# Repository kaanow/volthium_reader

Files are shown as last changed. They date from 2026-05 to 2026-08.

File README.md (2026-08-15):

# Volthium 24V Pack Reader

Reads the state of two Volthium **SC12200G4DPH** 12V 200Ah LiFePO4 batteries
wired in series (24V system, "The Barge Inn"), and shows a live estimate of
time-to-full when charging or time-to-empty (to 10% SOC) when discharging.

> **How it actually runs today (since 2026-07-26).** Nothing runs on the laptop.
> A Raspberry Pi at the cabin reads the packs over **RS485** (BLE is retired)
> and the Conext gear over **Xanbus/CAN**, and ships everything to a cloud
> server at <https://volts.alti2.de>. The laptop is only an operator console.
> The description below is the ORIGINAL laptop-plus-Bluetooth rig and is kept
> for the design reasoning, not as a statement of current fact.
>
> Start here instead: `docs/STATUS.md` for how it runs, `docs/RUNBOOK.md` for
> operating it, and `docs/what-to-distrust.md` before believing any number in
> this repo.

This repo began as the **dev/validation rig** — it ran on a Mac laptop using
its built-in Bluetooth, to check readings against the Volthium phone app and
dial in the time estimator before committing to permanent hardware.

## How it works

The Volthium SC12200G4DPH BLE protocol matches the **E&J Technology BMS**
family — same Nordic UART service, same `:...~` ASCII-hex frames. We use
[`aiobmsble`](https://github.com/patman15/aiobmsble), which already decodes
that protocol, and combine the two single-battery samples into one logical
24V pack reading.

For a series pack:
- pack voltage = `V_a + V_b` (≈ 26V fully charged, ≈ 24V nominal)
- pack current = same through both batteries (we average to suppress noise)
- **charging** finishes when the *higher-SOC* battery hits 100%
- **discharging** finishes when the *lower-SOC* battery hits the floor

The estimator uses an exponential moving average on current so the displayed
"3h 20m" doesn't flicker every time a cloud passes or the inverter steps load.

## Setup

### macOS (dev rig)

```bash
brew install python@3.13        # only if not already installed
/opt/homebrew/bin/python3.13 -m venv .venv
.venv/bin/pip install -r requirements.txt
```

macOS will prompt for Bluetooth permission the first time the Terminal app
tries to scan. Approve it under *System Settings → Privacy & Security → Bluetooth*.

### Linux / Raspberry Pi (cabin-side)

```bash
sudo apt install -y bluez python3-venv rfkill
python3 -m venv .venv
.venv/bin/pip install -r requirements.txt
```

`bluetooth.service` is enabled by the bluez install; bleak talks to it over
D-Bus, no user-group changes needed on Ubuntu 24.04.

The two physical batteries' addresses live in `pack.env` (committed). macOS
sees them under CoreBluetooth peripheral UUIDs; Linux sees the real BLE
MACs. The Mac UUIDs are already filled in; once you've scanned from the Pi:

```bash
.venv/bin/python scripts/scan.py
```

paste the two `V-12V200AH-*` MACs into `pack.env` as `ADDR_A_LINUX` and
`ADDR_B_LINUX` and commit. From then on the launcher just works on either
machine.

## Use

### 1. Find the batteries

```bash
.venv/bin/python scripts/scan.py
```

Both batteries advertise as `V-12V200Ah-<serial>`. Note their BLE addresses.
(Tip: temporarily power one off if you can't tell A from B.)

### 2. Smoke test — one reading

```bash
.venv/bin/python scripts/read_once.py --a AA:BB:CC:DD:EE:FF --b 11:22:33:44:55:66
```

Cross-check the SOC, voltage and current against the Volthium app. If they
match, the protocol is decoded correctly.

### 3. Live dashboard

```bash
.venv/bin/python scripts/monitor.py \
    --a AA:BB:CC:DD:EE:FF \
    --b 11:22:33:44:55:66 \
    --interval 5 \
    --csv pack.csv
```

`--csv` is optional but recommended for the validation phase — we want
real charge/discharge curves to tune the smoothing constant.

### Easiest way to launch (for anyone, no Terminal needed)

**macOS:** Double-click **Volthium Monitor** on the Desktop. It silently
starts the logger + dashboard if they aren't already running, opens the
dashboard in your default browser, and shows a notification with the LAN
URL to share with phones on the same Wi-Fi.

If the Desktop alias gets deleted, recreate it with:

```bash
./scripts/install_desktop_launcher.sh
```

The .app bundle lives at `Volthium Monitor.app/` in the repo root; the
Desktop alias just points at it, so any future improvements to the .app
are picked up automatically.

**Linux / Pi:** Run the same script from a terminal:

```bash
./'Launch Volthium Monitor.command'
```

It's a portable bash script that detects the OS — `caffeinate` is swapped
for `systemd-inhibit`, `ipconfig` for `hostname -I`, `open` for `xdg-open`.
The dashboard binds `0.0.0.0:8421`, so a phone on the same Wi-Fi can hit
the printed LAN URL. `scripts/install_desktop_launcher.sh` also handles
Linux: it writes `~/.local/share/applications/volthium-monitor.desktop`
(plus a Desktop copy if `~/Desktop` exists). On a fully headless Pi,
prefer a systemd unit instead — `Launch Volthium Monitor.command` is the
single command you'd put in the unit's `ExecStart=`.

### 4. Headless logger + browser dashboard

For long unattended runs, the rich-TUI `monitor.py` isn't ideal — it needs a
visible terminal. Use these two together instead:

```bash
# In one terminal — keep alive with `caffeinate -i` so the Mac doesn't doze.
caffeinate -i .venv/bin/python scripts/log.py \
    --a 9058AE7F-F98B-D0F6-237D-6769894DE118 \
    --b 6EC69980-CA43-7DEF-519B-6235C8C535B7 \
    --interval 5 \
    --csv data/pack.csv --log data/pack.log

# In another terminal:
.venv/bin/python scripts/dashboard.py --csv data/pack.csv
# then open http://localhost:8421/
```

The logger never gives up — it backs off and retries on BLE errors. The
dashboard is read-only off the CSV, so both can run forever.

## Files

- `volthium/pack.py` — discovery + `BatteryReading` / `PackReading`
- `volthium/estimator.py` — smoothed time-to-full / time-to-empty
- `scripts/scan.py` — find the batteries
- `scripts/read_once.py` — single-shot smoke test
- `scripts/monitor.py` — live rich-TUI dashboard (one-shot use)
- `scripts/log.py` — headless CSV logger (for unattended runs)
- `scripts/dashboard.py` — browser dashboard (binds LAN by default)
- `scripts/install_desktop_launcher.sh` — re-create the Desktop alias
- `Volthium Monitor.app/` — double-clickable launcher
- `Launch Volthium Monitor.command` — Terminal-friendly launcher with QR code
- **`docs/RUNBOOK.md` — start here for operating the live system**: current deployment, where things live on the Pi, common ops, failure-mode playbook, hardware upgrade path.
- `docs/production_design.md` — architecture for the cabin-side hardware
- `docs/cloud_architecture.md` — Railway telemetry design + repo-wide timestamp convention (ISO-8601 UTC `Z` on the wire; read this before adding any code that emits or consumes timestamps over the network)
- `docs/reliability_failure_modes.md` — field log of BLE / storage failure modes, root causes, and mitigations
- `cloud/` — FastAPI ingest server + Pi-side CSV uploader + browser dashboard, deployable to Railway. See `docs/cloud_architecture.md` § "Railway deploy steps".
- `data/pack.csv`, `data/pack.log` — captured data (gitignored)

## Known limits / open questions

- The Volthium app and our reader **cannot both be connected at once** — the
  BLE peripheral only accepts one central. Close the app before running.
- Capacity defaults to 200 Ah per battery. Override with `--capacity` if the
  batteries have aged.
- The 10% "empty" floor is configurable via `--floor`.
- Range was specified as ~6 m by Volthium; the cabin install will need either
  a closer-range MCU near the batteries or a Bluetooth proxy.

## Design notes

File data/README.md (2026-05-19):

# `data/` — pack telemetry, weather, and derived files

This folder is the **persistent state of the cabin install**. The
autonomous loop appends to most files every iteration and pushes
the snapshot to GitHub, so re-cloning the repo gives you the full
history.

## Source-of-truth files (logger-written, append-only)

| File | What it is |
|---|---|
| **`pack.csv`** | Every BLE poll of both batteries. ~ one row per 10 s. Columns: `ts, state, pack_v, pack_i, pack_p, soc_a, soc_b, v_a, v_b, i_a, i_b, temp_a, temp_b, rem_a, rem_b, delta_v_a, delta_v_b, smoothed_i, smoothed_p, minutes_remaining, name_a, name_b`. Written by `scripts/log.py`. Grows ~ 13 MB / day; this is the canonical source of truth. |
| **`weather.csv`** | Open-Meteo observation every 30 min. Columns: `ts, lat, lon, temperature_c, cloud_cover_pct, shortwave_radiation_wm2, wind_speed_ms, wind_gusts_ms, weather_code, is_day, sunrise_iso, sunset_iso, shortwave_radiation_sum_today_wh_m2, uv_index_max_today`. Written by `scripts/weather.py`. |
| **`pack.log`** | Human-readable progress / BLE-flap notes from `scripts/log.py`. Useful when debugging connection issues. |
| **`launch.log`** | The `Volthium Monitor.app` launcher's chatty log of when services started / failed. |
| **`weather.log`** | Reserved for `scripts/weather.py` output (currently mostly empty). |

## Derived / rolled-up files (loop-regenerated)

| File | What it is |
|---|---|
| **`daily_summary.csv`** | One row per calendar date with day-total stats (charge/discharge Ah, generator minutes, weather kWh/m², partial flag, etc.). Written by `scripts/daily_summary.py`. Input to `volthium.solar_model.SolarModel.fit_from_daily_summary`. |
| **`calibration_log.csv`** | History of meaningful `SolarModel` coefficient changes. Each row: `ts, coefficient, n_observations, confidence, source, notes`. Written by `scripts/calibration_log.py` (called from `generator_advisor.py`). |
| **`projection_log.csv`** | History of advisor projection snapshots. Each row: `ts, start_soc_pct, projected_sunrise_soc, projected_tomorrow_evening_soc, projected_low_soc, solar_model_coefficient, today_irradiance_kwh_m2, sunrise_iso, source`. Rate-limited to ≥ 25 min apart. Foundation for `scripts/projection_accuracy.py` AND `scripts/low_soc_accuracy.py`. |
| **`solar_onset.csv`** | One row per day capturing the morning solar-onset cascade. Columns: `date, first_zero_iso, first_idle_iso, first_positive_iso, first_net_positive_iso, smoothed_i_at_net_positive, soc_avg_at_net_positive`. The four milestones mark when the pack transitioned from overnight discharge to sustained charging. `soc_avg_at_net_positive` is the day's empirical floor — input to `scripts/low_soc_accuracy.py`. Written by `scripts/solar_onset.py` (idempotent upsert; re-runs enrich the row as more milestones land). |
| **`confidence_log.csv`** | History of advisor confidence-tier transitions. Each row: `ts, base, resolved, lifted, recent_abs_error_pp, recent_n, source`. Only TRANSITIONS in `(base, resolved, lifted)` are logged — stable runs are deduped so the file is a timeline of events, not a stream of duplicates. Written by `scripts/confidence_log.py` (called from `generator_advisor.py` after the accuracy-aware lift is computed). |
| **`voltage_soc_table.csv`** | OCV (open-circuit voltage) → SOC% lookup table extracted from rest-window samples. Written by `scripts/voltage_soc_calibration.py`. Designed to be re-run periodically as the table sharpens with more data. |

## Derived in-memory (no CSV; rendered live)

The dashboard and CLIs compute these views in-memory from the source-of-truth files above:

| View | What it is | Source files |
|---|---|---|
| **Sunrise SOC accuracy** | Per-projection error of `projected_sunrise_soc` vs the actual pack SOC at the matching sunrise (±30 min). | `projection_log.csv` + `pack.csv` |
| **Morning-low SOC accuracy** | Per-projection error of `projected_low_soc` vs the empirical morning low (= `soc_avg_at_net_positive` from `solar_onset.csv`). Surfaced bias finding 2026-05-19: mean -2.97 pp (advisor systematically optimistic about the floor) → led to the sinusoidal-solar fix in `simulate_next_24h`. | `projection_log.csv` + `solar_onset.csv` |
| **Per-horizon accuracy breakdown** | Both accuracy chains bucket records by lead-time (made-at → target gap) in 1h windows. Surfaces systematic lead-time bias. | (same as the two above) |

## Reports

| Path | What it is |
|---|---|
| **`reports/YYYY-MM-DD.md`** | Markdown day-report generated by `scripts/end_of_day_report.py`. **Six-chain archive** — sections in order: Pack (SOC walk + peaks), Solar harvest, Solar onset (4-milestone cascade for the day), Weather (incl. Open-Meteo forecast revisions), SolarModel state (calibration_log entries dated to the day), Projection accuracy (validated sunrise projections + per-horizon breakdown), Morning-low validation (validated `projected_low_soc` + per-horizon breakdown), Confidence-lift events, Cross-references. Idempotent — re-runs overwrite with the freshest snapshot for the current day; historical days stay frozen, preserving the validation chains' state as they were at end-of-day. |

## Archived backups

| File | What it is |
|---|---|
| **`pack.csv.v0-1512`** | Snapshot of the pack.csv taken on 2026-05-17 at 15:12 before the schema changed (added `name_a` / `name_b` columns). Preserves the original charge → discharge transition data point. |

## Sizing notes

`pack.csv` grows ~ 13 MB / day at the current 10-s polling cadence
and is the main contributor to repo size growth. Over a month
that's ~ 400 MB. If the repo gets unwieldy we'll revisit log
rotation (e.g. archive older days to `pack-YYYY-MM-DD.csv` files
and keep only the last week unrolled).

## Dashboard surfaces

The live dashboard renders most of this data into a single page;
the log-style files also have their own browseable pages, all
cross-linked:

- `/calibration` — `calibration_log.csv` as a table
- `/projections` — `projection_log.csv` as a table
- `/accuracy` — sunrise SOC validation: per-record table + per-lead-time-horizon breakdown (`projection_log.csv` + `pack.csv`)
- `/low-accuracy` — morning-low SOC validation: per-record table + per-horizon breakdown (`projection_log.csv` + `solar_onset.csv`)
- `/confidence` — `confidence_log.csv` as a table; timeline of accuracy-aware confidence-lift transitions
- `/reports` — index of `reports/*.md`
- `/today-report` — live regeneration of today's day-report
- `/report/YYYY-MM-DD` — specific historical day-report

## Cross-references

- Logger: `scripts/log.py`
- Weather: `scripts/weather.py`
- Daily summary: `scripts/daily_summary.py`
- Calibration log: `scripts/calibration_log.py`
- Projection log: `scripts/projection_log.py`
- Projection accuracy (sunrise SOC): `scripts/projection_accuracy.py`
- Solar onset detector: `scripts/solar_onset.py`
- Low-SOC accuracy (morning low validation): `scripts/low_soc_accuracy.py`
- Confidence log: `scripts/confidence_log.py`
- Generator advisor: `scripts/generator_advisor.py` (orchestrator — invokes all of the above)
- End-of-day report: `scripts/end_of_day_report.py`
- Site context: `docs/site/loon_lake.md`
- BMS calibration findings: `docs/hardware/bms_calibration.md`

## Audit-trail topology (how the logs feed each other)

```
pack.csv ──┬──> projection_log.csv ──┐
           │                          ├──> sunrise SOC accuracy view
           │                          │     (and report section)
           │                          │
           └──> solar_onset.csv ──────┴──> morning-low SOC accuracy view
                                           (and report section)
                  ↑                              ↓
                  │                         feeds confidence-lift
              detect on each              decision in advisor
              advisor invocation                 ↓
                                          confidence_log.csv
                                                ↓
                                          confidence-lift events
                                          report section + /confidence

daily_summary.csv ──> SolarModel fit ──> calibration_log.csv
                            ↑                  ↓
                        advisor uses    /calibration view
                        coefficient
```

The advisor (`scripts/generator_advisor.py`) is the orchestrator
that touches every log on each invocation. It reads the SolarModel
fit (from `daily_summary.csv` → updates `calibration_log.csv`),
reads recent `projection_accuracy` records to compute the
confidence-lift, writes a new `projection_log.csv` row (rate-limited),
and writes a new `confidence_log.csv` row only on transitions.
`solar_onset.csv` is updated by the dashboard's `/api/latest.json`
handler on each request (cheap one-day scan over `pack.csv`).

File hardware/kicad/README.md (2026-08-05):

# `hardware/kicad/` — KiCad design package

Both boards are generated **programmatically** from Python (kiutils +
`kicad-cli`) on **KiCad 10**. The `.kicad_sch` / `.kicad_pcb` files are
build artifacts — edit the generators, not the KiCad files.

## File map

| File / dir | What |
|---|---|
| `schematic/` | **Schematic source of truth.** `core.py` (shared generator core + full gate stack), `build.py` (battery board), `build_display.py` (display board), `testdata/` (standing poison fixtures for the build-start self-test). Outputs land in `schematic/build/` (battery) and `schematic/build_display/` (display): `.kicad_sch` hierarchy, `.kicad_pro`, netlist, PDF, per-sheet PNGs. |
| `pcb/` | **Placement/routing source of truth** (CP3+). Same pattern: shared core + per-board build scripts; outputs in `pcb/build/` / `pcb/build_display/`. |
| `libraries/` | Custom symbols (`volthium.kicad_sym`). |
| `footprints/` | Custom footprints (`volthium.pretty/`) with provenance README. |
| `archive/` | **Superseded** toolchains: SKiDL/KiCad-8 genesis, plus `pass1_pcb/` (the first design pass's placement/routing generator + board projects + outputs, retired when the design was re-baselined at CP1). See `archive/README.md`. |

## Requirements

- **KiCad 10** with `kicad-cli` discoverable (see the generator's startup
  print for the resolved share/CLI pairing).
- The repo venv (`.venv/`) with kiutils + PyMuPDF.

## Run

```bash
# battery-side schematic (gates + ERC + netlist + PDF/PNG export)
.venv/bin/python hardware/kicad/schematic/build.py
# display-side schematic
.venv/bin/python hardware/kicad/schematic/build_display.py
# battery-side placement (CP3)
.venv/bin/python hardware/kicad/pcb/build.py
```

Every generator carries its own gate stack (readability, glyph, pdf-text
ground truth, netlist intent==actual, exact-part contracts, strict full
ERC/DRC, build-start poison self-tests) and fails the build on any gate.

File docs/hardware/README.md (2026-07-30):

# Hardware design — index

| Doc | Contents |
|---|---|
| [`block_diagrams.md`](block_diagrams.md) | Top-level system + per-board block diagrams |
| [`bom.md`](bom.md) | Full BoM with Digi-Key / Mouser part numbers |
| [`schematic_battery_side.md`](schematic_battery_side.md) | Battery-side board: GPIO map, netlist, layout hints |
| [`schematic_display_side.md`](schematic_display_side.md) | Display-side board: GPIO map, netlist, layout hints |
| [`power_budget.md`](power_budget.md) | Quantified draw per shutdown tier; wire losses |
| [`cat5e_pinout.md`](cat5e_pinout.md) | T568B pinout, shield bonding, cable QA |
| [`bms_calibration.md`](bms_calibration.md) | Empirical finding: BMS coulomb-counter bias is non-linear (1.12 fast charge, 0.91 trickle). Recommended firmware approach. |

## What's left before ordering parts

1. **Confirm the existing in-wall Cat5e is shielded** (user mentioned it
   is — worth verifying with a multimeter on the drain wire before
   committing). If not, design still works; we just lose some EMI
   margin.
2. **Decide proto vs PCB-first.** Default recommendation: build battery
   side on the ESP32-S3-DevKitC-1 + breadboard for ~1 week to debug the
   BMS polite-poll firmware. Order the PCBs as soon as that's stable.
3. **KiCad project**: the GPIO maps and netlists in the schematic docs
   are structured to enter into KiCad as a schematic. Each `.md` file is
   approximately one schematic sheet.

## Open hardware questions

- **e-paper substrate temperature**: the cabin gets cold in winter.
  Standard e-paper is rated 0–40 °C operating; the kitchen probably
  stays above 0 °C if the cabin is occupied. If we leave the cabin
  unheated, partial-refresh ghosting may become visible. Worth noting in
  the firmware: avoid refreshes below 0 °C, fall back to full-refresh-only.
- **Battery-side enclosure ventilation**: the regulators (U1 LM5165
  always-on µA-Iq buck + U2 R-78HB12 12 V, per D19) dissipate well under
  ~150 mW combined at typical load. The enclosure handles that easily; if
  we add heavier-current circuits later we may need a thermal pad to the
  box lid.
- **Cable strain relief at the in-wall keystone**: shoulder-mount the
  RJ45 keystone so the patch cable comes out without stressing the
  punch-down.

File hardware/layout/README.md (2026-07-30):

# `hardware/layout/` — design process docs

This folder holds the working documents Claude uses to drive the PCB design
through to a fab-ready package. The engineering *specification* lives in
[`docs/hardware/`](../../docs/hardware/) (block diagrams, BOM, schematic
intent); this folder is the *how-do-we-get-there*.

## Process

The work is gated by five checkpoints. Each checkpoint produces a review
packet in [`../reviews/`](../reviews/) and the work pauses for human / agent
review before continuing.

| CP | Phase | Outputs | Reviewer asks |
|----|---|---|---|
| 1  | **Design baseline** | Per-board net + part lists, updated BOM, layout strategy | Is this the right design before we draw it? |
| 2  | **Schematic capture**  | `.kicad_sch`, ERC report, schematic PDFs, netlist | Do schematics match the baseline? |
| 3  | **Placement** | Footprints placed, top/bottom PNG, dimensioned drawing | Is the placement physically + electrically OK? |
| 4  | **Routing + DRC** | Fully routed `.kicad_pcb`, DRC report, copper pours | Is this routable to fab? |
| 5  | **Fab-ready** | Gerbers, drill, position file, BOM CSV, fab checklist | Would you click "order" on this? |

## Layout

```
hardware/
├── layout/                      ← THIS FOLDER
│   ├── README.md                 — process index (this file)
│   ├── decisions.md              — every committed design decision + rationale
│   ├── cp1_battery_side.md       — CP1 baseline doc, battery-side
│   ├── cp1_display_side.md       — CP1 baseline doc, display-side
│   └── cp1_bom.md                — CP1 BOM (supersedes docs/hardware/bom.md
│                                    where they disagree)
├── kicad/
│   ├── battery_side/             — KiCad 10 project (CP2+ artifacts)
│   ├── display_side/             — KiCad 10 project (CP2+ artifacts)
│   ├── libraries/                — custom symbols/footprints we author
│   ├── battery_side.py           — legacy SKiDL (reference only; not source of truth)
│   ├── display_side.py           — legacy SKiDL (reference only)
│   └── HANDOFF.md                — original handoff (historical; superseded by this folder)
├── reviews/                     — checkpoint review packets
│   └── cpN_<phase>.md            — one per checkpoint
└── outputs/                     — build artifacts (Gerbers, BOMs, renders)
    ├── battery_side/
    └── display_side/
```

## Workflow notes

- **Source of truth = KiCad 10 native files** (`.kicad_pro`, `.kicad_sch`,
  `.kicad_pcb`). The existing SKiDL Python in `hardware/kicad/*.py` is
  preserved as a design-intent reference for the reviewer but is not the
  source we'll regenerate from.
- **Programmatic where possible** — schematic capture, footprint placement,
  ERC/DRC, exports are all scripted via `kiutils` + `kicad-cli` so design
  changes are reproducible and reviewable as diffs.
- **GUI where necessary** — interactive routing in CP4 may need human-driven
  KiCad PCB Editor work for the harder traces. Where that happens, the
  diff against the prior committed `.kicad_pcb` is the reviewable artifact.
- The autonomous loop in [`docs/STATUS.md`](../../docs/STATUS.md) is **not**
  driving this work — hardware progress is checkpoint-gated, not loop-driven.

## Cross-references

- [`decisions.md`](decisions.md) — the single source of "what did we commit to and why"
- [`../../docs/hardware/`](../../docs/hardware/) — engineering specification
- [`../kicad/README.md`](../kicad/README.md) — current build flow (kiutils / KiCad 10). The original SKiDL → KiCad 8 plan is archived at [`../kicad/archive/`](../kicad/archive/)

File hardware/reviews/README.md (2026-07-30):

# `hardware/reviews/` — checkpoint review packets

Each PCB-design checkpoint produces a review packet here. Reviewers
(human or agent) start from the packet, follow links into the design
docs, and post findings as comments / commits / PR suggestions.

> **The standing standard is [`SOP.md`](SOP.md)** — the distilled gates,
> principles, and tooling every checkpoint must satisfy, forward-looking and
> free of the incident history. Read it before starting any CP. Role
> playbooks: [`DESIGNER.md`](DESIGNER.md), [`REVIEWER.md`](REVIEWER.md).

| File | Phase | Status |
|---|---|---|
| `cp1_design_baseline.md` | Design baseline | **in review (re-opened, D18/D19)** |
| `cp2_schematic_capture.md` | Schematic capture | not started (next) |
| `cp3_placement.md` | Footprint placement (battery) | not started |
| `cp4_display_placement.md` | Footprint placement (display) | not started |
| `cp5_routing_drc.md` | Routing + DRC | not started |
| `cp6_fab_ready.md` | Fab-ready package | not started |

> **Note (2026-06-18):** CP1 was re-opened (decisions.md **D18**) after the
> engineering-correctness gate (D17) found CP1/CP2 architecture defects that
> had ridden to "CP6 fab-ready". The **prior CP2–CP6 review packets** (and
> the CP6 visual-inspection crops) describe board work built on the
> pre-D19 schematics and are **superseded** — they now live in
> [`archive/`](archive/) for history. New CP2+ packets will be written
> fresh against the corrected D19 design.

## What a review packet contains

Each packet is a single markdown file with:

1. **Status banner** — checkpoint name, date opened, current state
2. **What changed since the last checkpoint** — diff summary (commits, file list)
3. **What to look at** — pointers into the design docs + KiCad files,
   with the specific questions to evaluate
4. **Known unknowns / open decisions** — questions Claude is asking the
   reviewer to settle
5. **Success criteria** — what the reviewer needs to see to mark this
   checkpoint passed
6. **Reviewer findings** — appended by the reviewer; iterates until
   findings are resolved

## How to drive a review cycle

1. Claude commits the work and writes the packet
2. User triggers the reviewer (separate agent or human)
3. Reviewer appends findings to the packet
4. Claude addresses findings; updates packet with responses
5. Cycle continues until reviewer marks checkpoint passed
6. Next checkpoint begins

The reviewer is expected to read the packet only, not chase down design
decisions across the repo unless flagged. Claude's job is to make the
review packet self-contained.

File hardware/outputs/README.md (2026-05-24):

# `hardware/outputs/` — build artifacts (fab deliverables)

Per-board subdirectories with the artifacts a PCB fab needs. Filled in
at CP4 (renders) and CP5 (gerbers, BOM CSV, position files).

```
outputs/
├── battery_side/
│   ├── gerbers/        — *.gbr files (one per layer)
│   ├── drill/          — *.drl + *.gtl
│   ├── bom.csv         — flat BOM for fab/PCBA
│   ├── pos.csv         — pick-and-place (unused for hand-solder; present for completeness)
│   ├── render_top.png  — visual reference
│   ├── render_bot.png  — visual reference
│   └── schematic.pdf   — schematic for the assembler
└── display_side/
    └── (same files)
```

All files in this folder are **regenerable** from the KiCad sources via
`kicad-cli`. They are committed to the repo at CP5 only — the version
that ships to the fab. Earlier CP renders live in the review packets,
not here.

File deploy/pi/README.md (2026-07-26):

# Pi-side system config (versioned)

Everything the reader Pi (`kwpi`) needs outside the repo checkout itself —
systemd units, drop-ins, udev rules — so `/etc` state is reproducible instead
of hand-rolled. Before 2026-07-13 these lived only on the Pi.

## Install / update

```
ssh kaan@192.168.1.251
cd /srv/volthium_reader
sudo -u claude git pull --ff-only origin main
sudo bash deploy/pi/install.sh
```

`install.sh` is idempotent: copies configs, reloads systemd + udev, applies
the UB500 autosuspend override to the live device, archives a stale
pre-tmpfs `data/ble_events.jsonl` once, and restarts the three data services.
It never touches network, ZeroTier, or boot config.

## What's here and why

| File | Purpose |
|---|---|
| `systemd/volthium-logger.service` | BLE logger unit (unchanged from the hand-rolled one) |
| `systemd/volthium-logger.service.d/10-reader-env.conf` | Reader env: event log on `data/` (durable), UB500 pin, **internal-BT fallback**, replug USB ID |
| `systemd/volthium-uploader.service` | pack.csv → Railway (logs to `data/`, not tmpfs) |
| `systemd/volthium-events-uploader.service` | sealed event segments → Railway (drains `data/`, not tmpfs) |
| `udev/50-volthium-ub500-usb-power.rules` | **Disables USB autosuspend for the UB500** — the root-cause fix for the FM-9 firmware hangs |

## Transport: RS485 primary, BLE dormant fallback (2026-07-26)

Telemetry now comes over **wired RS485** (`volthium-rs485-logger.service`),
which sidesteps the whole BLE dormancy/wedge failure class. The BLE logger
(`volthium-logger.service`) is **disabled but intact** — a latent fallback, not
deleted. `Conflicts=volthium-logger.service` on the RS485 unit guarantees the
two never run at once, so the flip is a clean two-liner.

**If an RS485 adapter dies — fall back to BLE:**
```
sudo systemctl disable --now volthium-rs485-logger
sudo systemctl enable  --now volthium-logger
```

**Back to the wired primary:**
```
sudo systemctl disable --now volthium-logger
sudo systemctl enable  --now volthium-rs485-logger
```

Both write the identical `pack.csv` → the same uploader → Railway, so the flip
is transparent downstream (the only visible tell is `read_ok`'s `transport`
field flipping between `rs485` and `ble`, which `scripts/status_check.py` now
surfaces). Also running: `volthium-xanbus-capture` and `volthium-modbus-poll`
(Insight Home decode — see `docs/xanbus-decode.md`).

## tmpfs retirement (2026-07-13)

The `/run/volthium` tmpfs existed for the old SU16G SD card's write-rate
limits. With the Samsung PRO Endurance card (2026-07-09) that constraint is
gone, and the 2026-07-12/13 outage showed the cost of volatile diagnostics:
evidence that doesn't survive reboots/crash-loops can't be shipped or studied.
Event log, uploader log, and sealed segments now all live in `data/`.
`/etc/tmpfiles.d/volthium.conf` is left in place (an empty tmpfs dir is
harmless) so nothing here risks boot-time behavior; remove it at leisure.

The dashboard unit is unchanged and not duplicated here (no local config).
`/etc/volthium-uploader.env` (bearer token) is a secret — never in git.

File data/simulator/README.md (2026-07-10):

# Raw BMS frame corpus

`pi-barge_raw_frames.jsonl` — 3,921 raw BLE notify frames captured from the
two Barge-Inn batteries between 2026-07-01 and 2026-07-09, exported from the
Railway `ble_events` table (`event='raw_frame'`) via `/api/events`.

## Schema

One JSON object per line, sorted ascending by `ts`:

```
{
  "ts":       "2026-07-01T17:33:15.879000Z",   // capture time (UTC Z)
  "source_id":"pi-barge",                       // reader that captured it
  "address":  "09:01:00:11:55:DF",              // battery BLE address
  "direction":"rx",                             // notify chunks are only ever rx
  "data_hex": "3a30303832333130303843…",        // notify chunk payload (hex)
  "data_len": 20                                // byte count of that chunk
}
```

## Reconstruction

BLE notify chunks arrive in 20-byte pieces; the BMS record framing is
`:...<hex>...~` (colon-prefixed ASCII-hex, `~` = 0x7e = record terminator).
Concatenate all `rx` payloads for one address in `ts` order, then split on
`b"\x7e"` to recover the record stream:

```python
import json
frames = [json.loads(l) for l in open("pi-barge_raw_frames.jsonl")]
def records_for(addr):
    hexblob = "".join(f["data_hex"] for f in frames
                      if f["address"] == addr and f["direction"] == "rx")
    return [r.decode("ascii", errors="replace")
            for r in bytes.fromhex(hexblob).split(b"\x7e") if r]
```

Both batteries yield ~275 complete `:008231008C…` records — the E&J
Technology master status frame that carries pack voltage, current, SOC,
per-cell voltages, temperatures, cycle count and fault code in one shot.

## Why this exists

Enough real-world material to build an offline BMS simulator (a mock
`BleakClient` that replays these frames on demand), so the reader path
and estimator can be exercised without live batteries. Capture is currently
**off** on the Pi — flip `VOLTHIUM_CAPTURE_RAW=1` on the logger unit if a
future run needs to grow the corpus (e.g. capturing a charging-cycle span).

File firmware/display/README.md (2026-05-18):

# `firmware/display/` — kitchen display-side ESP-IDF project

Receives RS-485 frames from the battery-side board and drives the
4.2" tri-color e-paper panel mounted in the kitchen wall plate.
Three buttons, a watchdog for link-down detection, and a "release
BLE" back-channel to the battery side.

## Status

**Skeleton.** Same shape as `firmware/bms-link/`: CMakeLists +
sdkconfig.defaults + main.c with FreeRTOS task creation + 4 task stubs
(`rx_task`, `render_task`, `input_task`, `watchdog_task`), each with
a header comment listing the implementation TODO checklist.

The `rx_task` stub posts a synthetic frame every 30 s so the e-paper
rendering path can be developed end-to-end without an actual RS-485
link.

## Differences from `bms-link/`

- **No Bluetooth** — `CONFIG_BT_ENABLED=n` in sdkconfig.defaults.
- **No MOSFET load-switch** — display-side stays alive longer than
  battery-side per `docs/firmware/state_machine.md`.
- **No ULP** — display side doesn't sleep that deeply; it just light-
  sleeps between e-paper refreshes.
- **SPI bus to the e-paper** instead of BLE central.
- **Three buttons** instead of one override.

## Build

```bash
cd firmware/display
idf.py set-target esp32s3
idf.py build
idf.py -p /dev/cu.usbserial-XXXX flash monitor
```

(Same ESP-IDF v5.x prerequisite as `bms-link/`.)

## Layout

```
firmware/display/
├── CMakeLists.txt           top-level ESP-IDF project
├── sdkconfig.defaults
├── .gitignore
├── README.md
└── main/
    ├── CMakeLists.txt
    ├── main.h               shared types + task entry decls
    ├── main.c               app_main + task creation
    ├── rx_task.c            STUB — RS-485 RX, decode wire frames
    ├── render_task.c        STUB — e-paper renderer
    ├── input_task.c         STUB — 3 buttons, debounce, long-press
    └── watchdog_task.c      STUB — link-down detection + overlays
```

## What needs implementing (rough order)

1. **render_task + e-paper driver** — biggest piece. Brings up the
   Waveshare 4.2" panel via SPI. Adapt one of the existing ESP-IDF
   community components or roll our own from the panel datasheet.
2. **rx_task** — UART driver setup + the framing loop. Decoder is
   already done (`volthium_decode()` in volthium_lib).
3. **input_task** — debounced button reads with long-press detection.
4. **watchdog_task** — small; mostly an `esp_timer` periodic that
   checks `received_ms` against now.
5. **Back-channel for release-BLE button** — minimal wire-protocol
   extension or a separate small command frame. Design pending.

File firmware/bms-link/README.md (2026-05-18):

# `firmware/bms-link/` — battery-side ESP-IDF project

Cabin-side ESP32-S3 firmware: holds the BLE central role for both
Volthium BMSes, runs the time-to-X estimator (hybrid coulomb counter),
shifts between NORMAL / LOW / DEEP_SLEEP / HARD_CUT tiers per SOC, and
ships fused samples over RS-485 to the display-side board.

## Status

**Skeleton.** The CMakeLists, sdkconfig, and main.c + task stubs are
all in place. `app_main` creates the four FreeRTOS tasks documented in
`docs/firmware/architecture.md`. Each task currently just logs "STUB"
and waits — real implementation is TODO. The ble_task posts a
synthetic sample every 30 s so the rest of the pipeline (estimator +
encoder) can be exercised end-to-end without real BMSes on the bench.

When you build it now, you get a runnable ESP-IDF app that:
- initializes NVS
- spawns 4 tasks
- prints encoded wire frames (with sentinel/raw values) to the console
  every 30 s

That's enough to validate the linker pulls in volthium_lib correctly
and the shared types compile under both the host C11 toolchain (with
the standalone Makefile in `firmware/common/volthium_lib/`) and
ESP-IDF.

## Build

You need [ESP-IDF v5.x](https://docs.espressif.com/projects/esp-idf/en/latest/esp32s3/get-started/index.html)
installed and sourced (`. $IDF_PATH/export.sh`).

```bash
cd firmware/bms-link
idf.py set-target esp32s3        # only first time
idf.py build
idf.py -p /dev/cu.usbserial-XXXX flash monitor
```

## Repo layout

```
firmware/
├── bms-link/                   ← THIS PROJECT
│   ├── CMakeLists.txt          top-level ESP-IDF project def
│   ├── sdkconfig.defaults      committed sdkconfig baseline
│   ├── main/
│   │   ├── CMakeLists.txt      component def
│   │   ├── main.h              shared types between tasks
│   │   ├── main.c              app_main + task creation
│   │   ├── ble_task.c          STUB — BLE central, BMS reads
│   │   ├── tx_task.c           STUB — RS-485 frame transmit
│   │   ├── power_task.c        STUB — SOC-tier state machine
│   │   └── adc_task.c          STUB — 24V rail voltage sense
│   └── ulp/                    (empty for now) — ULP voltage monitor
├── common/
│   └── volthium_lib/           shared C library (wire_protocol + estimator)
│       ├── CMakeLists.txt      ESP-IDF component manifest
│       ├── Makefile            host-side build for dev tests
│       └── ...
└── display/                    (not yet) — display-side project
```

## How the stubs are organized

Each `*_task.c` file:
1. Declares its task entry point in `main.h`.
2. The actual function in the .c file is a `while (true)` loop with a
   `vTaskDelay` and a `ESP_LOGI(... "STUB ...")` line.
3. The header comment lists the TODO checklist for that task — what
   needs to be implemented, which ESP-IDF subsystem it touches, and
   which design doc it references.

The skeleton is intentionally honest about being a skeleton — there
are no half-real implementations to confuse anyone. When work picks
up, each task gets its own focused commit.

## What needs implementing (rough order)

1. **ble_task** — biggest piece. Port the EJ BMS protocol decoder
   (`aiobmsble/ej_bms.py` → `firmware/common/volthium_lib/bms_decoder.{h,c}`),
   then NimBLE scan + connect + GATT + UART-service notify handler.
2. **tx_task** — straightforward once the wire frames have real fields.
   Driver setup is ESP-IDF boilerplate.
3. **power_task** — implement the 4-state machine from
   `docs/firmware/state_machine.md`. Mostly arithmetic on the estimator
   output.
4. **adc_task** — small. ADC oneshot + EMA + a getter.
5. **ulp/voltage_monitor.S** — ULP-RISC-V assembly. Replaces adc_task
   while in DEEP_SLEEP / HARD_CUT.
6. **NVS persistence** — estimator state, voltage-SOC table, hysteresis
   counter.

When you pick up the first piece, start with `ble_task` and the BMS
decoder — they unblock all downstream testing.

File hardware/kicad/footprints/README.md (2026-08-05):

# Repo-local footprint library (`volthium.pretty`)

Footprints not present in the KiCad 10 stock libraries. The build gate
(`core.py` `_FP_DIRS`) resolves the `volthium:` prefix here; at CP3 the
layout's `fp-lib-table` must add this library under the same nickname.

| Footprint | Part | Provenance |
|---|---|---|
| `J_Wurth_WR-MJ_615008145521.kicad_mod` | Würth 615008145521 WR-MJ RJ45, horizontal shielded EMI-finger 8P8C tab-down (display J1) | **Manufacturer-official**, vendored verbatim from [WurthElektronik/KiCad-Library](https://github.com/WurthElektronik/KiCad-Library) `footprints/Connector_THT_Wurth.pretty/`, commit `fdbe2d0192`, fetched 2026-07-27. sha256 `38db7c97fd9b…899684`. License: Würth `License_Terms_WE_KiCad_library.pdf` (free use for designing with WE products). |
| `ESP32-S3-WROOM-1_HSvia0.3.kicad_mod` | ESP32-S3-WROOM-1 module (both boards, MOD1) | KiCad 10 stock `RF_Module:ESP32-S3-WROOM-1` with ONE delta: the 12 heatsink via-in-pad drills bumped 0.2 → 0.3 mm (pad 0.6 mm → 0.15 mm annular ring). Rationale: JLCPCB 2-layer min drill is 0.3 mm (cp1_battery_side §12); the stock 0.2 mm EP stitching vias violate the fab floor. Found mechanically by the CP3 `pcb/fplib.py` drill scan, 2026-07-29. |

## Why vendored, and the pin-map verification (2026-07-27)

KiCad stock has no footprint for 615008145521. The datasheet's numbered
top view is ambiguous to read (digits sit in the diagonal gaps of the
staggered field), and this jack's tail fan-out is **non-monotone** — a
hand-derived pattern was rejected in favor of the manufacturer's own:

- far row (8.89 mm from the mounting posts): pins **1, 5, 6, 7** at
  x = 0 / 2.54 / 5.08 / 7.62
- near row (6.35 mm from posts): pins **2, 3, 4, 8** at
  x = −1.27 / 1.27 / 3.81 / 6.35
- x-order across both rows: `2, 1, 3, 5, 4, 6, 8, 7` — NOT the
  monotone-alternating comb of e.g. the Amphenol RJHSE5380 or Würth's
  own 7499010001A magjack.

Cross-checks performed: every official pad coordinate matches the
datasheet Recommended Hole Pattern (rows 2.54 apart, 1.27 stagger,
posts Ø3.2 span 11.43 at 8.89, shield Ø1.7 span 15.50 at 5.84,
signal drills 0.9), and the datasheet's numbered view agrees with the
official map once the label convention is decoded (each digit sits
~1.2 mm right of its own hole).

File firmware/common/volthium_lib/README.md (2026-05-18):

# `firmware/common/volthium_lib/`

Portable C library shared by both production firmware images
(`firmware/bms-link/`, `firmware/display/`) and validated against the
Python reference implementations in `volthium/`.

## What's in here

| File | Purpose |
|---|---|
| `wire_protocol.h` / `.c` | 43-byte RS-485 frame format; encode/decode/CRC |
| `estimator.h` / `.c` | Time-to-X estimator (SOC-based + hybrid Ah-anchor) |
| `test_wire_protocol.c` | 22 unit cases for the wire protocol |
| `test_estimator.c` | 17 unit cases for the estimator |
| `test_cross_validation.c` | Python↔C cross-validation (4 reference frames) |
| `test_vectors/*.bin` | Python-encoded reference frames (committed) |
| `Makefile` | Host build via clang/gcc; `make test` runs all 3 |
| `CMakeLists.txt` | ESP-IDF component manifest |

## Design rules

1. **No `malloc` / dynamic allocation.** Estimator state lives in a
   caller-owned `volthium_estimator_t`. Wire-protocol structs live on
   the caller's stack. The firmware should never run the heap during
   normal operation.

2. **No ESP-IDF dependencies.** This library compiles cleanly with
   stock clang/gcc as well as `idf.py build`. That's why the tests
   run on a dev laptop — find bugs without flashing.

3. **Python is the spec.** When in doubt, the Python implementation
   in `volthium/wire_protocol.py` and `volthium/estimator.py` is the
   reference. `test_cross_validation.c` enforces this by asserting
   the C decoder matches the Python encoder byte-for-byte, and the
   C encoder produces bytes identical to the Python encoder for the
   same inputs.

4. **C11 + `-Wall -Wextra -Werror`.** Warnings break the build. The
   Makefile sets these flags.

## How firmware uses it

```c
#include "volthium_lib/wire_protocol.h"
#include "volthium_lib/estimator.h"

/* battery side */
volthium_estimator_t est;
volthium_estimator_config_t cfg = VOLTHIUM_ESTIMATOR_CONFIG_DEFAULT;
cfg.use_hybrid = true;
cfg.capacity_ah = 215.0f;
volthium_estimator_init(&est, &cfg);

/* on each new BLE sample */
volthium_sample_t s = { ... };          // filled from BMS reads
volthium_estimate_t e = volthium_estimator_update(&est, &s);

/* build a wire frame */
volthium_body_t body = { .seq = seq++, .state = (uint8_t)e.state, ... };
uint8_t wire[VOLTHIUM_FRAME_SIZE];
volthium_encode(&body, wire, sizeof(wire));
/* …send over UART RS-485… */
```

```c
/* display side */
volthium_body_t body;
if (volthium_decode(buf, len, &body) == VOLTHIUM_OK) {
    /* fields are populated; sentinel-aware accessors:
       if (volthium_u8_is_set(body.soc_a_pct)) { use it } */
}
```

## How to develop on a dev laptop

```bash
cd firmware/common/volthium_lib
make test    # builds and runs all three test programs
```

Or from the repo root:

```bash
make test    # runs Python AND C tests in one shot
```

The cross-validation test reads `test_vectors/*.bin` (Python-
encoded reference frames) and asserts:

1. C decoder of each Python-encoded frame produces field values
   matching the expected struct (21 fields per case).
2. C encoder of the same struct produces bytes BYTE-IDENTICAL to
   the Python file.

Both directions pass → the two implementations are bit-stable
against each other.

If a Python wire-protocol change is made, regenerate the vectors:

```bash
.venv/bin/python scripts/gen_test_vectors.py
```

(The top-level `make test` does this automatically when the Python
source is newer than the .bin files.)

## How ESP-IDF projects use it

Both `firmware/bms-link/CMakeLists.txt` and
`firmware/display/CMakeLists.txt` set:

```cmake
set(EXTRA_COMPONENT_DIRS "${CMAKE_CURRENT_SOURCE_DIR}/../common")
```

before `include($ENV{IDF_PATH}/tools/cmake/project.cmake)`. ESP-IDF's
build system discovers `firmware/common/volthium_lib/CMakeLists.txt`
and treats it as a component. The component name (`volthium_lib`)
matches the directory.

Add it to a component's REQUIRES:

```cmake
idf_component_register(
    SRCS "main.c" ...
    INCLUDE_DIRS "."
    REQUIRES ... volthium_lib
)
```

## Testing invariants

- `sizeof(volthium_frame_t) == 43` — `_Static_assert` in
  `wire_protocol.h` enforces this at compile time across all builds.
- `sizeof(volthium_body_t) == 39` — same.
- CRC-16/CCITT-FALSE: `crc16("123456789") == 0x29B1` — the canonical
  test vector. Both the C `volthium_crc16_ccitt()` and the Python
  `crc16_ccitt()` produce this.

## When to change the wire format

1. Bump `VOLTHIUM_VERSION` in `wire_protocol.h` AND
   `volthium/wire_protocol.py`.
2. Update both implementations (struct layout, field sizes, encode
   / decode logic).
3. Update `tests/test_wire_protocol.py` AND
   `test_wire_protocol.c` with new expected sizes / vectors.
4. Update `scripts/gen_test_vectors.py` so the cross-validation
   .bin files regenerate.
5. Run `make test` from the repo root — everything must still pass.
6. Document the change in `docs/firmware/architecture.md` § "RS-485
   framing" and the version bump rationale.

## Cross-references

- [`docs/firmware/architecture.md`](../../../docs/firmware/architecture.md) —
  big-picture firmware design
- [`docs/firmware/state_machine.md`](../../../docs/firmware/state_machine.md) —
  the SOC-tier state machine
- [`docs/firmware/ble_flap_recovery.md`](../../../docs/firmware/ble_flap_recovery.md) —
  observed BLE flap behavior + firmware retry policy
- [`docs/hardware/bms_calibration.md`](../../../docs/hardware/bms_calibration.md) —
  why the estimator defaults to hybrid mode + `capacity_ah=215`
- [`volthium/wire_protocol.py`](../../../volthium/wire_protocol.py) —
  Python reference
- [`volthium/estimator.py`](../../../volthium/estimator.py) —
  Python reference

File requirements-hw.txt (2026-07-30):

# Hardware design dependencies (KiCad 10 programmatic generation)
# Used by hardware/kicad/build_schematics.py + build_pcbs.py + dedupe_pdf_text.py.
# Requires KiCad 10 installed separately (for kicad-cli + bundled pcbnew).
kiutils>=1.4.0
PyMuPDF>=1.23.0
# (The old SKiDL/KiCad-8 path is archived under hardware/kicad/archive/.)

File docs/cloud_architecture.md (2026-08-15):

# Cloud architecture — Railway-hosted telemetry

> Status: **v1 implemented** as of 2026-06-18 — code lives in `cloud/`, tests in `cloud/tests/`.
> Not yet deployed to Railway; instructions are below.

Companion to [`production_design.md`](production_design.md). That doc covers
the on-pack hardware (ESP32 BLE central, display-side node, etc.). This doc
covers what happens *off-pack*: how the reader (Pi today, ESP32 tomorrow)
ships data to a Railway instance, what gets stored, and how it's viewed
remotely.

## Goal

Telemetry from the Barge Inn 24V pack visible from anywhere, stored
indefinitely, without breaking the existing local CSV + local dashboard.
Local stays the offline fallback; cloud is the remote-viewable copy.

## Shape

```
   READER (Pi today, ESP32 later)         RAILWAY
   ┌─────────────────────────┐            ┌──────────────────────────┐
   │ scripts/log.py          │            │ FastAPI ingest service   │
   │  → data/pack.csv  ←── unchanged ──── │   POST /ingest           │
   │  → cloud uploader ──── HTTPS POST ─→ │   bearer auth per source │
   │     batches of rows                  │     ↓                    │
   │     remembers offset                 │   Postgres (Railway     │
   │     in state file                    │     add-on)              │
   └─────────────────────────┘            │     readings table       │
                                          │     derived cols filled │
                                          │     on insert            │
                                          │     ↓                    │
                                          │ Browser dashboard        │
                                          │   port of scripts/       │
                                          │   dashboard.py, reads    │
                                          │   from Postgres          │
                                          │   public URL (no auth)   │
                                          └──────────────────────────┘
```

## Timestamp convention — applies to ALL code in this repo

**Wire format**: ISO-8601 UTC with a trailing `Z`. Example: `2026-05-17T19:13:00Z`.

**Rationale**: ESP32 firmware will NTP-sync to UTC and has no native concept
of local time. Picking UTC + `Z` everywhere on the wire means the Pi sender,
the ESP32 sender, and the server all use the same string format with no tz
math, and the server never has to guess what zone a naive timestamp came from.

Concrete rules:

- **On the wire (uploader → server, including future ESP32 firmware)**:
  ISO-8601 UTC with a `Z` suffix. No offsets, no fractional seconds unless a
  device genuinely has sub-second precision.
- **In Postgres**: store as `TIMESTAMPTZ`. Postgres canonicalizes to UTC
  internally; clients can render in any zone.
- **In the local `data/pack.csv`**: stays as it is today (naive local time).
  This is a quirk of the existing logger; do NOT change it as part of the
  cloud work — the local dashboard already parses it. The uploader is
  responsible for converting `pack.csv`'s naive local time to UTC `Z` before
  POSTing.
- **In cloud dashboard output**: render in the Barge Inn's local time for human
  readability; underlying data stays UTC. **`DISPLAY_TZ` is currently
  `America/Toronto` and the site is `America/Vancouver`** — a 3 h error. See
  the `DISPLAY_TZ` row in the env table below for what that does and does not
  affect; it is not cosmetic and it is not the site's local time.
- **ESP32 firmware (future)**: stamp readings with UTC from NTP at capture
  time, format as `Z`-suffixed ISO-8601. If NTP is unavailable at boot,
  buffer readings without timestamps and discard them rather than send wrong
  times — a gap is better than a lie.

## Wire protocol

`POST /ingest` with `Authorization: Bearer <token>` and JSON body:

```json
{
  "source_id": "pi-barge",
  "readings": [
    {
      "ts": "2026-05-17T19:13:00Z",
      "state": "discharging",
      "v_a": 13.215, "v_b": 13.217,
      "i_a": -3.2,   "i_b": -3.0,
      "soc_a": 70,   "soc_b": 68,
      "t_a": 23,     "t_b": 23,
      "remaining_ah_a": 158.0, "remaining_ah_b": 142.0,
      "delta_v_a": 0.008,      "delta_v_b": 0.009,
      "name_a": "V-12V200AH-0533",
      "name_b": "V-12V200AH-0667"
    }
    /* ...up to N rows per batch... */
  ]
}
```

Notes:

- Payload contains **only what the reader natively produces from the BMS**.
  Server derives `pack_v`, `pack_i`, `pack_p`, `smoothed_i`, `smoothed_p`,
  `minutes_remaining` — anything that depends on EMA/projection tunables
  belongs on the server so we can tune without re-flashing.
- Server upserts on `(source_id, ts)`. Retries are safe.
- Batch size: target 60 rows per POST (10 minutes at 10 s cadence).
- Names of fields match `pack.csv` columns 1:1 for the raw subset, so the
  uploader is a column-projection of the CSV, not a remapping.

## Source IDs

A short string per **reader device**, not per pack. The Barge Inn pack only
has one pack but may have multiple readers during transitions.

- `pi-barge` — the Pi (or Mac dev rig) running `scripts/log.py`
- `esp32-barge` — the future ESP32-S3 battery-side node

Hardcoded in env / firmware config. The server schema lets these coexist; the
dashboard merges by default but can filter.

## Auth

**Per-device bearer tokens** in `Authorization: Bearer <token>`. One env var
per token on the server (`READER_TOKEN_PI`, `READER_TOKEN_ESP32`), one
matching env var on each device. Adding the ESP32 doesn't require re-keying
the Pi.

Tokens are random 32-byte URL-safe strings, rotated by editing env vars on
both ends. No PKI, no OAuth.

## Dashboard

Public Railway URL, no auth. Read-only. Same chart layout as
`scripts/dashboard.py` (port to a Postgres query).

## Server schema (sketch)

```sql
CREATE TABLE readings (
  source_id      TEXT        NOT NULL,
  ts             TIMESTAMPTZ NOT NULL,
  -- raw, from wire
  state          TEXT,
  v_a            REAL, v_b REAL,
  i_a            REAL, i_b REAL,
  soc_a          INT,  soc_b INT,
  t_a            INT,  t_b INT,
  remaining_ah_a REAL, remaining_ah_b REAL,
  delta_v_a      REAL, delta_v_b REAL,
  name_a         TEXT, name_b TEXT,
  -- derived, filled at insert time by the ingest service
  pack_v             REAL,
  pack_i             REAL,
  pack_p             REAL,
  smoothed_i         REAL,
  smoothed_p         REAL,
  minutes_remaining  REAL,
  PRIMARY KEY (source_id, ts)
);
```

Storage estimate at 10 s cadence: ~3M rows/yr per source, ~500 MB/yr with
indexes. Plain Postgres handles this without partitioning for years. If
queries get slow add a `readings_1m` rollup table later — don't pre-optimize.

## Out of scope (deliberately)

- Multiple packs / multiple sites — single pack is enough; if the Barge Inn
  ever splits we add a `pack_id` column then.
- MQTT / WebSockets — no benefit at 10 s cadence; HTTPS POST is simpler and
  ESP32-native.
- mTLS — per-device bearer is plenty given the threat model (one residential
  Wi-Fi, one residential cabin).
- Server-side EMA replays / backfills — derive on insert; if tunables change
  we re-derive in place with a one-off SQL update.
- Server-side hybrid-Ah anchor mode (the `use_remaining_ah_anchor=True` path
  in `volthium/estimator.py`) — needs per-source persistent state beyond
  smoothed_i/p. Skipped for v1 because the local CSV still has it and the
  cloud dashboard doesn't show displayed_ah yet.

---

# Implementation — what was built, where it lives, how to deploy

## Repo layout

```
cloud/
  shared/wire.py            ← Pydantic models for the wire (the contract)
  server/
    main.py                 ← FastAPI app: /ingest, /api/*, /healthz, /
    config.py               ← env-var config
    derive.py               ← server-side EMA + projection (mirrors estimator.py)
    db.py                   ← asyncpg-backed ReadingsDAO + Protocol
    staleness.py            ← staleness + event monitors -> ntfy
    migrations/             ← 0001_readings, 0002_ble_events, 0003_solar,
                              0004_solar_pv_extremes
    static/v2.html          ← the LIVE dashboard at / (SOC hero + power flow)
    static/v2-history.html  ← the live /history page
    static/index.html       ← the pre-2026-08 dashboard, still served at /v1
    static/history.html     ←   ...and its history page at /v1/history
    Dockerfile              ← multi-stage slim image
    railway.json            ← Dockerfile builder + /healthz healthcheck
    requirements.txt        ← fastapi, uvicorn, asyncpg, pydantic
  uploader/uploader.py      ← Pi-side: tails pack.csv, posts batches
  tests/                    ← 132 unit tests; no Postgres needed
```

*(Counts and file lists here go stale — `ls cloud/server/static/` and
`pytest -q --collect-only cloud/tests` are the sources of truth. Last checked
2026-08-15; the test count had drifted from 36 to 132.)*

Edge changes (also part of v1):

- `scripts/log.py` — added `problem_code_a/b` and `cell_a_1..4`, `cell_b_1..4`
  columns; auto-archives old CSV on schema drift to `pack.csv.vN-HHMM`.
- `scripts/dashboard.py` — `CSV_HEADER_FALLBACK` updated to match.
- `tests/test_log_schema.py` — 7 new tests pinning the new columns + the
  archive behavior.

## Env vars

| Var | Default | Purpose |
| --- | --- | --- |
| `DATABASE_URL` | (required) | Postgres URL. Railway's add-on injects this. |
| `READER_TOKEN_PI_BARGE` | (required) | Bearer token authorizing `source_id=pi-barge`. |
| `READER_TOKEN_ESP32_BARGE` | (later) | Same, for the future ESP32 reader. |
| `EMA_ALPHA` | `0.15` | Smoothing factor — matches `estimator.py`. |
| `CAPACITY_AH` | `200.0` | Per battery, for projection. |
| `FLOOR_PCT` | `10.0` | "Empty" floor SOC. |
| `CEILING_PCT` | `95.0` | "Full" target SOC (LiFePO4 absorption-onset).  |
| `IDLE_CURRENT_A` | `0.5` | |I| below this → state=idle, no projection. |
| `DISPLAY_TZ` | `America/Toronto`| **NOT cosmetic, and currently WRONG** — see note below. |
| `DB_MIGRATE` | `1` | If truthy, runs migrations/*.sql on boot. |
| `STALENESS_WEBHOOK_URL` | (empty; disabled) | HTTP endpoint the staleness monitor POSTs alerts to. ntfy.sh-compatible JSON body. |
| `STALENESS_THRESHOLD_S` | `300` | Age (in seconds) before a source is called stale. |
| `STALENESS_CHECK_INTERVAL_S` | `60` | How often the monitor polls the DB. |

#### `DISPLAY_TZ` is a bucketing key, not a rendering preference

It was documented as "cosmetic only". It is not. It is the argument every
day-and-hour aggregate groups by — `solar_energy_daily`, `load_heatmap`,
`history_daily`, `history_profile` all do
`(ts AT TIME ZONE $3)::date` / `extract(hour FROM ts AT TIME ZONE $3)`.

It is also **wrong**: the default is `America/Toronto` and Barge Inn is in
British Columbia, `America/Vancouver`. Three hours. Measured 2026-08-11 rather
than assumed, because "the ledger is off by three hours" would have been the
obvious and incorrect conclusion:

| what | effect of the 3 h error |
|---|---|
| daily `solar_wh` | **none** (0 Wh over 10 days) — the Toronto day boundary lands at 21:00 Vancouver, which is dark |
| daily `load_wh` | **negligible** — worst day 19 Wh of ~2730, 0.7%; the DC load is nearly constant |
| `load_heatmap` / `history_profile` hour axis | **mislabelled by 3 h.** Cell "hour 15" holds 12:00 Vancouver data. Low consequence today only because the load is flat at 114–115 W in every hour; any future "when does the fridge run" reading is off by three hours |
| `mppt_counter_wh` | **broken** — see below |

The counter column is the real casualty. `mppt_daily_total` fires at the MPPT's
own midnight (00:01 Vancouver) carrying the finished day's total, and the query
shifts it back one hour to attribute it correctly. That shift assumes
`DISPLAY_TZ` *is* the site zone. With a 3 h mismatch the event lands at 03:01
Toronto, minus one hour is 02:01 — still the new day — so the total is credited
to the WRONG DAY. Observed: 1356 Wh reported for 2026-08-11, a day which at the
time had produced 6 Wh.

**Refined 2026-08-12, after watching two more rollovers.** The damage is
narrower than "every day is wrong", and knowing which day is wrong matters:

    fired 08-11 00:01:13 Vancouver / 03:01:13 Toronto, day_wh 1356 (08-10's)
      -> should attribute to 08-10, actually attributes to 08-11
    fired 08-12 00:01:15 Vancouver / 03:01:15 Toronto, day_wh 1645 (08-11's)
      -> should attribute to 08-11, actually attributes to 08-12

The `c` CTE takes `MAX(day_wh)` per attributed day, and each day also collects
the ordinary `mppt_energy` samples. Because production ends around 20:30
Vancouver — just before the 21:00 Toronto-day boundary — the last `mppt_energy`
of a day usually already carries that day's final total, and `MAX()` picks it.
So COMPLETED days mostly come out right, by luck rather than design.

What is reliably broken is the CURRENT day, which inherits the previous day's
total from the misplaced rollover and shows it until real production exceeds
it. Live right now: **2026-08-12 shows `solar_wh` 0 and `mppt_counter_wh`
1645** — a full day's counter against a day that has produced nothing.

The luck is thin. It depends on the last `mppt_energy` before 21:00 Vancouver
already being the day's final value; anything that shifts production later, or
the emitter's 15-minute cadence landing badly, silently under-reports the day.

That defeats the column's entire purpose. It was added as a standing audit of
pipeline loss — ledger vs the device's own counter — and it is currently
comparing across a day boundary.

**Not changed here.** Setting `DISPLAY_TZ=America/Vancouver` on Railway moves
every historical day on the dashboard, which is the operator's call. The
alternative, making the shift robust to any `DISPLAY_TZ` by keying it to the
site zone, is a ledger change and only one ledger change was authorised.

Token-naming rule: env var `READER_TOKEN_<UPPER_SNAKE>` authorizes
`source_id=<lower-kebab>`. So `READER_TOKEN_PI_BARGE=...` ↔ `pi-barge`.

### Staleness alerting

The server can push a webhook when a source stops sending fresh data (and
again when it recovers). Off by default. To turn on, set
`STALENESS_WEBHOOK_URL` to any endpoint that accepts a JSON POST — the payload
shape is directly ntfy.sh-compatible:

```
POST $STALENESS_WEBHOOK_URL
{
  "title": "Volthium: pi-barge stale",
  "message": "No fresh telemetry for 412s (threshold 300s)",
  "priority": 4,
  "tags": ["warning"]
}
```

- **For ntfy.sh** (simplest): set to `https://ntfy.sh/<your-topic>`. Subscribe
  on your phone via the ntfy app. Fields are honored directly.
- **For Discord**: set to a channel webhook and expect payload adaptation
  (Discord wants `content` not `message`); run a tiny relay in between if
  needed.
- **For Pushover / Slack / email**: same story — put an intermediary in front.

Only *transitions* fire alerts (fresh → stale, or stale → fresh). Repeated
checks while in the same state stay silent. State is in-memory per-process
so a server restart re-arms all sources.

## Preflight (run before pushing changes to cloud/server/)

`make preflight` (or `./scripts/preflight_cloud.sh`) builds the exact
Dockerfile Railway uses and imports the whole `cloud.server.*` module tree
in the resulting slim image. Catches missing-runtime-dep bugs (e.g. a
module imports `httpx` but `httpx` isn't in `cloud/server/requirements.txt`
— the actual regression that took down the service 2026-07-01) before they
hit production.

Needs Docker locally. If you don't have it, GitHub Actions runs the same
check on every push/PR touching `cloud/server/` — see
`.github/workflows/preflight.yml`. Either way, a missing dep now fails
loud before the deploy instead of after.

## Railway deploy steps

1. **Push the repo to a GitHub remote** Railway can read. (Right now the
   software-side clone is in `volthium_sw/volthium_reader/` and points at
   `git@github.com:kaanow/volthium_reader.git`. If a new remote is wanted to
   keep cloud history separate, create one and add it.)

2. **Create a Railway project**, then:
   - Add a **PostgreSQL** plugin. Railway auto-injects `DATABASE_URL`.
   - Add a **Service from GitHub repo**, pointing at this repo.
   - In the service settings: **Builder = Dockerfile**, **Dockerfile path =
     `cloud/server/Dockerfile`**, **Root directory = `/` (repo root)**.
     `railway.json` already encodes this — Railway picks it up automatically.
   - Set env vars:
     - `READER_TOKEN_PI_BARGE` — generate with
       `python -c 'import secrets; print(secrets.token_urlsafe(32))'`.
     - Anything from the table above you want to override.

3. **Deploy**. The healthcheck path `/healthz` is wired in `railway.json`;
   Railway will mark the service healthy once it responds 200.

4. **Confirm the schema applied**:
   ```
   railway run psql $DATABASE_URL -c "\\d readings"
   ```
   Should show all 27 columns. (If `DB_MIGRATE=0` was set, run
   `cloud/server/migrations/0001_readings.sql` manually.)

5. **Note the public URL** Railway assigns; that's the dashboard.

## Wiring up the Pi-side uploader

On the Mac (and later the Pi), once Railway is live:

```bash
.venv/bin/pip install -r cloud/uploader/requirements.txt

export READER_TOKEN=<the same value that's in READER_TOKEN_PI_BARGE>

# First run — dry-run mode to confirm the row shape looks right:
.venv/bin/python -m cloud.uploader.uploader \
    --csv data/pack.csv \
    --url https://<your>.up.railway.app \
    --source-id pi-barge \
    --dry-run

# Then for real, alongside scripts/log.py:
.venv/bin/python -m cloud.uploader.uploader \
    --csv data/pack.csv \
    --url https://<your>.up.railway.app \
    --source-id pi-barge \
    --log data/uploader.log
```

The uploader maintains its read position in
`data/pack.csv.cloud_state` (JSON: `{offset_bytes, inode, header}`). Delete
that file to re-upload from the top.

## ESP32 hand-off (future)

When the firmware is ready:

1. Build the same JSON payload — see `cloud/shared/wire.py:Reading` for the
   exact field names and types. Pydantic's `extra="forbid"` means unknown
   fields are rejected; if you add a field on-device, add it here first.
2. NTP-sync to UTC and emit timestamps as ISO-8601 with `Z`. The server
   422s on naive timestamps.
3. Configure `source_id="esp32-barge"` and add `READER_TOKEN_ESP32_BARGE`
   in Railway env vars. Pi keeps running alongside; rows from each device
   coexist via the `(source_id, ts)` primary key.

## Where to pick this up

- **Not done yet**: deploying to Railway (needs the user's account), running
  the uploader against real Railway (needs the URL), porting the analytics
  panels from `scripts/dashboard.py` (advisor, harvest, projection — all
  shell out to sibling scripts that depend on local CSV layout, so they're
  local-only for now).
- **Local CSV schema**: the next time `scripts/log.py` runs, it'll detect
  the old 22-col `data/pack.csv` and archive it to `data/pack.csv.v1-HHMM`,
  then start a fresh 32-col file. This is intentional and safe.
- **Test command**: `.venv/bin/python -m unittest discover -s cloud/tests`
  for the cloud tests; `tests/test_log_schema.py` for the edge changes.
  Both run on Python 3.11 (the repo's normal 3.13 setup also works).

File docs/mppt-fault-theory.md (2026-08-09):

# Why does the MPPT do this? A theory, with its evidence and its holes

Written 2026-08-08 in answer to "is it faulty?".

**Short version, after the theory below was tested and its mechanism failed:**
the output current sensor IS faulty (~1.5-2.1x under-read, measured), and the
power stage is fine — but the sensor probably does **not** explain the tracking
failure. The leading explanation is now a controller servoing to a charge
current it can never reach. Read the REFUTED section before the theory.

## What is actually observed

1. **The array walks monotonically down** from ~90-113 V to ~28 V, passing
   straight through its own maximum power point without turning around, and
   ends pinned one diode drop above the battery.
2. **A Standby → Operating bounce fixes it every time** — 7 of 7 in daylight,
   restoring 88-95 V and full output within seconds.
3. **After a bounce it tracks correctly for 15-60 minutes**, then starts down
   again.
4. **The descent start is NOT conditional on power.** Measured across eight
   recoveries, it began at 16, 32, 84, 185, 218, 223, 312 W. It is essentially
   *time since reset*, not irradiance, not load, not SOC.
5. **The unit reports no fault.** Status byte 0x03 throughout.
6. **Its output current sensor under-reads by ~1.8x**, measured against two
   BMS shunts that agree with each other within 0.8 A.
7. **This model has no PV-side current sensor at all** — the 0x15 current and
   power fields are structurally zero.

## The theory

**The controller is chasing a current target with an instrument that reads
low, and it has no independent way to notice.**

Walking left down the IV curve *is* demanding more current. The controller does
that continuously until the array collapses, and never reverses. That is what a
regulator does when it believes it has not yet reached its setpoint — and
`chg_target` advertises **60 A**, which this array can never supply.

Point 7 is what makes it unrecoverable. With no PV-side sensor, the MPP tracker
must infer array power from the output side, `P = Vout x Iout`. Its only power
signal is the very measurement that is wrong. If the error is non-linear with
current — reading progressively lower as current rises — then moving left looks
like *power still increasing*, so the peak is never detected and there is
nothing to turn the tracker around. It walks until physics stops it.

This one fault accounts for all seven observations:

| observation | explained by |
|---|---|
| walks past MPP without reversing | no valid peak in the inferred power signal |
| always walks *down*, never up | under-read → "need more current" → move left |
| 1.8x under-report | the sensor fault, measured directly |
| bounce always works | reset re-runs a fresh sweep from Voc |
| holds 15-60 min after | the push is slew-limited; it takes that long to walk |
| start is time-based, not power-based | it is a control-loop drift, not a response to conditions |
| "no faults active" | the unit cannot detect that its own sensor lies |

## MECHANISM REFUTED 2026-08-08 (same day, by the test it predicted)

The theory required the under-read to **ease as current rises**, so that moving
left past the MPP would still look like rising power. That is testable against
data already held, using the BMS plus inverter draw as an independent estimate
of true output.

Binned by **actual output current** — the variable the mechanism depends on,
and not the same as power, since left of the MPP current rises while power
falls:

| I_out | n | actual/reported |
|---|---|---|
| 0-2 A | 111 | 1.46x |
| 2-4 A | 175 | 1.92x |
| 4-6 A | 66 | 1.94x |
| 6-9 A | 64 | **2.14x** |
| 9-13 A | 105 | 1.91x |
| 13-25 A | 65 | 1.51x |

**It does not fall with current.** A hump with essentially equal endpoints
(1.46 vs 1.51) is approximately a *scale* error — and a scale error does not
move the argmax, so hill-climbing should still find the peak. The mechanism
proposed above therefore **does not work**.

Two false starts on the way, both worth recording:

- Binning by *power* first gave a clean 2.84x → 1.46x fall, which looked like
  confirmation. Most of that was the known constant +33 W offset in `dc_w`:
  `(W+33)/W` alone produces almost exactly that curve. Correcting for it cut
  the spread from 1.31 to 0.43.
- Even the residual was measured against the wrong variable. Power and current
  are not interchangeable across the MPP, which is the whole point of the peak.

Caveats on the refutation itself: the -33 W correction is an estimate, the
fridge is unmodelled, and the mid-range hump may be an artefact of which
conditions populate each bin. But there is **no evidence** for the specific
current-dependent non-linearity the theory needed, and that was its load-bearing
assumption.

**So the sensor fault is real and better characterised (~1.5-2.1x under-read
across the range), but it probably does not explain the tracking failure.**

### What that leaves

The alternatives below move up, and one now leads: **the controller servoing to
a charge request it can never meet.** `chg_target` advertises **60 A**, the
array can supply at most ~24 A, and `chg_stage` was observed flapping
bulk ↔ not_charging **~40 times in 11 hours**. A current regulator chasing an
unreachable setpoint, with MPP limiting not overriding it, produces exactly the
observed monotonic walk toward more current — and needs no sensor fault at all.

### ...and that lead is refuted too, 2026-08-09

The `chg_stage` flapping is real — 1035 of 1054 transitions over ten days are
`bulk ↔ not_charging`, and the unit reached absorption only **4 times in ten
days**, so it essentially never completes a charge cycle. But it does not
happen when the descent happens.

08-08 transitions by local hour:

| hour | transitions |
|---|---|
| **05:00** | **40** |
| 06:00 | 5 |
| 09:00 / 13:00 / 17:00 | 2 / 2 / 2 — these are the guard's own bounces |
| **20:00** | **39** |
| 21:00 | 6 |

Median gap between transitions: **17 seconds**. It is concentrated entirely in
the dawn and dusk hours, and there are **zero transitions during the
descents** — the array walks 91 → 29 V with the controller sitting in a single
uninterrupted `bulk` state.

So the descent is a **smooth continuous control action inside one mode**, not a
state-machine artefact. That is worth knowing: it rules out mode-thrash as the
cause, and it is consistent with (though it does not prove) a regulator pushing
steadily toward a setpoint. `chg_target` does advertise **60 A** throughout
bulk, against an array good for ~24 A.

**Separately, the dawn/dusk chatter is itself a previously unnoticed
behaviour.** ~40 start/stop cycles at ~17 s intervals, twice a day, as the
array crosses the converter's start threshold — classic hysteresis chatter at a
marginal input. Probably benign if the switching is solid-state, but it is ~80
cycles a day that nobody had counted.

### Where that leaves the diagnosis

Three candidate mechanisms have now been tested against data and **all three
have failed**: low-light dependence (descent starts at every power level from
16 to 312 W), sensor non-linearity (error is scale-like in current), and
mode-thrash (no transitions during descents).

What survives is only the observation, not an explanation: within one
continuous bulk state, with an unreachable 60 A target, the controller walks
the operating point down past its own MPP and never turns around. Whether that
is a firmware defect, a deliberate-but-wrong current-priority behaviour, or
something about how it arbitrates the BMS request is **not established**, and I
have stopped guessing at it.

## What this does NOT explain, honestly

- **Why a pure 1.8x scale error would matter.** Scaling `P` by a constant does
  not move its argmax, so a clean 1.8x error should still let hill-climbing
  find the peak. The theory therefore *requires* the error to be non-linear,
  and that is inferred rather than measured. It is the weakest link.
- **The 25-50x apparent under-report during a clamp** is a different
  mechanism, not more of the same: once the converter stops switching, current
  reaches the battery through the body diode and bypasses the sensor entirely.

## Alternatives not ruled out

- **A firmware bug in the MPP algorithm.** Cannot be tested by updating — the
  unit is already at its final firmware (1.09).
- **Interaction with the BMS charge request.** The bus advertises 28.6 V / 60 A
  while the MPPT's own config says 28.0 V; if the controller is servoing to a
  request it cannot meet, the same walk follows without any sensor fault.
- **Partial shading / multi-peak IV curve.** Real for a soiled 2-string array,
  but it would produce hunting between peaks, not a monotonic walk to collapse.

## Is it faulty?

**The output current sensor: yes, demonstrably.** ~1.8x low, measured against
two independent shunts, and confirmed by the unit's own Modbus energy counters
agreeing with the wrong value (same sensor, so no arbitration).

**The power stage: no.** It delivers 600+ W and holds a correct MPP for up to
an hour after every reset. Nothing is failing to convert.

**The tracking behaviour: faulty in effect, cause NOT established.** The link
from sensor to tracker was tested the same day and did not hold — see the
REFUTED section. Something is wrong with how this unit decides where to sit on
the curve; which subsystem is at fault is still open.

**Is it degrading?** Unknown, and worth saying plainly rather than guessing:
the walk-down is present in the earliest data available (07-30 already swings
113 → 28 V). There is no baseline from before it started.

## How to settle it

One measurement decides between "bad sensor" and "bad algorithm": **an
independent clamp meter on the MPPT output**, per
`docs/design/dc-current-instrumentation.md`.

Note the BMS-derived version of this test has already been run and pointed
*away* from the sensor. A clamp meter would settle it properly, since the
derived estimate carries the +33 W offset, an unmodelled fridge, and bin
confounds. But on present evidence the more valuable next step is cheaper:
**analyse the `chg_stage` bulk ↔ not_charging flapping**, which is logged
already and needs no hardware.

Either way the operational answer is unchanged, because the guard already
handles it: bounce on detection, and consider bouncing at the 45 V cliff before
the collapse completes.

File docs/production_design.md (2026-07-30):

# Production system design — Volthium pack monitor for The Barge Inn

> Status: **draft v1** — top-level architecture/vision. Detailed hardware
> design in [`hardware/`](hardware/README.md), firmware in [`firmware/architecture.md`](firmware/architecture.md).
>
> ⚠ **Parts, RTC, enclosure, and dev-port specifics below are pre-CP1 and
> superseded (decisions.md D18–D27).** This doc captures the system vision
> and rationale, but its component-level details are stale: the RTC
> (DS3231 → RV-3028-C7 + backup cap, D23), the enclosures (COTS Hammond/
> single-gang → custom 3D-printed IP5x boxes; display in a recessed
> double-gang, D20/D27), the dev port (USB-OTG → native USB-C, D22/D27),
> and the power tree (D19). For the **authoritative BOM and parts**, see
> [`hardware/layout/decisions.md`](../hardware/layout/decisions.md),
> [`hardware/layout/cp1_battery_side.md`](../hardware/layout/cp1_battery_side.md),
> [`hardware/layout/cp1_display_side.md`](../hardware/layout/cp1_display_side.md),
> and [`hardware/bom.md`](hardware/bom.md).
>
> For the cloud / remote-viewing side (Railway ingest, wire protocol, and
> the repo-wide UTC `Z` timestamp convention that the ESP32 firmware must
> follow when emitting telemetry), see [`cloud_architecture.md`](cloud_architecture.md).

## Goal

Wall-mounted display in the kitchen showing the 24V pack's SOC, power, and a
smoothed time-to-full / time-to-empty estimate, updated often enough to feel
live. Must be reliable, must be safe for the batteries (parasitic draw
measured in single-digit watts at most), and must not break the user's ability
to occasionally open the Volthium phone app.

## Physical layout

```
   BATTERIES (24 V, near floor)            KITCHEN WALL (5 m away)

   ┌────────────────────────┐     Cat5e   ┌────────────────────────┐
   │ Battery-side node      │═════════════│ Display-side node      │
   │  • ESP32-S3            │  RS-485     │  • ESP32-S3            │
   │  • BLE central → BMS×2 │  + DC pwr   │  • E-paper display     │
   │  • 24V→3.3V buck       │             │  • Pushbutton(s)       │
   └─────────┬──────────────┘             └──────────┬─────────────┘
             │                                       │
       24 V pack tap                          (no other power needed)
```

The kitchen end has an AC outlet but we deliberately **don't** use it. The AC
outlet is on the inverter, which is on these very batteries — keeping the
inverter alive for a 1 W load wastes 10–50 W in inverter idle. Instead we tap
the 24 V pack directly at the battery-side node and feed the kitchen end over
the unused Cat5e pairs. The AC outlet is a fallback option, not the plan.

## Wiring plan (Cat5e, 5 m, shielded)

Cat5e has 4 twisted pairs. We use:

| Pair | T568B colors | Use |
|---|---|---|
| 1 | Blue / White-Blue | RS-485 A/B (differential data) |
| 2 | Orange / White-Org| DC+ (regulated 12 V from battery) |
| 3 | Green / White-Grn | DC+ (paralleled with pair 2 — less drop, redundancy) |
| 4 | Brown / White-Brn | DC return (GND) |

Shield bonded to chassis GND **at one end only** (battery side) to avoid
ground loops.

5 m of #24 AWG copper per pair is ~0.45 Ω round-trip. At our expected ~50 mA
load that's ~22 mV drop — negligible. Paralleling two pairs for DC+ halves
that. Big margin for transient bursts (e-paper refresh, BLE scan).

## Power architecture

- **Battery-side input**: tap the 24 V pack via a small inline fuse (1 A)
  and a TI TPS62933 (or LM5163) buck → 12 V rail @ ~50 mA average. These
  parts have quiescent currents in the tens of µA range.
- **Battery-side local rail**: second tiny buck 12 V → 3.3 V for the
  ESP32-S3.
- **Display-side**: feed the 12 V rail from Cat5e into a 12 V → 3.3 V buck.
- **Total parasitic load on the pack** target: < 1 W average, < 200 mW idle
  (when ESP32s are in light sleep between BLE polls).

Why 12 V on the wire (not 3.3 V or 24 V):
- 3.3 V loses too much in the wire and exposes the rail to noise.
- 24 V directly is fine technically but means both ends carry an 8-fold
  step-down which is less efficient at light load than a single 24→12 step
  at the battery side plus 12→3.3 locally.

## Battery-side node — BLE polling strategy

The Volthium BMS only accepts one BLE central. If we hold a persistent
connection, the user can never open the phone app again. **Polite polling:**

- Wake every 30 s (configurable).
- Connect to battery A, read one sample, disconnect. (~1–2 s end-to-end.)
- Same for battery B.
- Send fused PackReading over RS-485.
- Sleep ESP32-S3 in light-sleep mode until next cycle.

Window between cycles is wide enough that the user can grab the connection
from their phone — if they do, our connect will fail and we just log the
miss and wait for the next slot.

Expected average draw on battery-side ESP32-S3:
- BLE active: ~80 mA @ 3.3 V for ~3 s out of every 30 s ≈ 8 mA average
- Light sleep idle: ~2 mA
- Total average: ~10 mA × 3.3 V = **~33 mW**

## RS-485 link — protocol

Half-duplex RS-485 (one pair). Transceiver: MAX3485 (3.3V) or SN65HVD3082.
Termination: 120 Ω at each end. Bias resistors on the kitchen end.

Frame format (battery-side → display-side, broadcast, no addressing — only
one talker):

```
0xAA 0x55  | LEN(1) | SEQ(1) | TS_MS(4) |
state(1)   | pack_v(2, 0.01V) | pack_i(2, signed, 0.01A) | pack_p(2, signed, W) |
soc_a(1)   | soc_b(1) | v_a(2) | v_b(2) | i_a(2) | i_b(2) |
t_a(1, signed) | t_b(1, signed) | rem_ah_a(2, 0.1Ah) | rem_ah_b(2, 0.1Ah) |
mins_remaining(2, 0=unknown) |
CRC16(2)
```

~38 bytes. 9600 baud is plenty (~40 ms/frame). Display sends back a tiny
"alive" beacon every minute on the same pair (TDM, scheduled so it never
collides).

## Display-side node

- **MCU**: ESP32-S3 (same as battery side — common firmware base, OTA
  symmetry, common spares).
- **Display**: 4.2" tri-color e-paper (Waveshare or Good Display, GDEY042Z98
  or similar). ~7 s full refresh. Partial-refresh for the time-remaining
  number every 30 s. Static between refreshes — zero power.
- **Inputs**: one tactile button for "refresh now" (forces a full redraw),
  one for "switch info screen" (bring up cell-balance / temperatures /
  cycle counts / history graph).
- **Optional**: a small LED bar (low-current, off by default) that flashes
  briefly when discharge crosses a configurable threshold.

### Display screen design (4.2", ~400×300)

```
┌──────────────────────────────────────────────┐
│  THE BARGE INN  •  pack  26.4 V  +12.0 W     │  ← header strip
├──────────────────────────────────────────────┤
│                                              │
│         ████████████░░░  67 %                │  ← SOC bar (big, glanceable)
│                                              │
│         TIME TO FULL                         │
│         5h 20m                               │  ← the headline number
│                                              │
├──────────────────────────────────────────────┤
│  33: 67% 13.22V 23°C   ▲▼ 8mV  ─── (sparkline)│
│  67: 66% 13.22V 23°C   ▲▼ 8mV  ─── (sparkline)│
└──────────────────────────────────────────────┘
```

Headline number is enormous (~80 pt) so it's readable from across the
kitchen. Everything else is supporting context.

Per-battery labels (`33`, `67`) are the last two digits of the BMS-advertised
serial — derived at runtime, so a battery swap auto-relabels with no firmware
flash needed.

When the higher-SOC battery reaches **95 %**, the headline replaces the time
remaining with **FULL** in big letters and the percentage stays visible
underneath. 95 % is the LiFePO4 absorption-onset point — the last 5 % is
constant-voltage taper that's hard to predict linearly and isn't useful to
non-technical viewers ("almost full" forever).

## Low-SOC self-shutdown (tiered)

The monitor must not be the thing that finishes off a deeply discharged pack.
Tiered behavior so we degrade gracefully rather than blink off without warning:

| Pack SOC | Behavior |
|---|---|
| > 25 % | Normal — persistent BLE connection, ~10 s display refresh |
| 15 – 25 % | Polling slows to 1 min; display shows "LOW PACK" banner |
| 10 – 15 % | BLE disconnected; main MCU deep-sleeps; ULP wakes every 10 min to re-check |
| < 10 % | Hard cut: P-MOSFET load switch off; ULP voltage-senses ~1×/min (~20 µA) and re-engages on recovery |

Recovery is automatic via the voltage-knee on the way back up. A small
hardware override button on the battery-side enclosure forces enable
regardless of SOC — for the case where you *want* to read the pack manually
right after a deep discharge.

The display-side node **does not** auto-shed at the same threshold. It
keeps showing the last-known reading plus a "MONITOR ASLEEP — pack < 10 %"
hint so a person in the kitchen sees *something* rather than a black panel.
The display side's draw is ~0 mW e-paper static + ~7 mW ESP32-S3 light-sleep
average — trivial compared to the inverter's idle baseline that's keeping
the kitchen AC outlet alive.

### Hysteresis to avoid flapping

Each tier transition needs hysteresis so a brief load doesn't bounce the
monitor through three states. Suggested:

- Down-transitions: instant (be cautious)
- Up-transitions: require 2 minutes of sustained SOC above the higher
  threshold before promoting back up

## BLE-share button

Pressing the display-side's "release BLE" button broadcasts an RS-485
command to the battery-side node, which:

1. Disconnects from both batteries cleanly.
2. Stays disconnected for **5 minutes** so the user can open the Volthium
   phone app (the BMS only accepts one BLE central at a time).
3. Auto-re-engages after 5 min — or sooner if the user presses the button
   again ("done with app").

The display shows a 5-minute countdown so the user knows when the monitor
will resume. The "ASLEEP" e-paper screen in the meantime says "phone-app
window open" rather than implying a fault.

This obviates the need for "polite polling" — we hold persistent BLE
connections for low-latency updates, and the user has an explicit, visible
way to step aside when they want the app.

## Optional Starlink sync (the cabin has it; production must not depend on it)

When Starlink is reachable, the display-side node (which has Wi-Fi
hardware anyway) optionally:

- Posts the latest sample + alerts to a small HTTP endpoint (somewhere
  we control, or just an InfluxDB / Grafana Cloud free tier).
- Pulls NTP time once a day to keep the on-board RTC accurate.
- Listens for a "you have a software update" ping → fetches OTA image.

**All optional.** The battery-side node has its own DS3231 RTC chip
($1) so timekeeping doesn't depend on the link or Wi-Fi. The display-side
falls back to free-running RTC if Starlink is offline. Local features
(time-remaining, display, alerts) work identically with or without
internet.

## Failure-mode handling

| Failure | Detection | Behavior |
|---|---|---|
| BLE disconnect mid-read | bleak exception | Log, retry next cycle |
| One battery unreachable | timeout on read | Show pack value from the other half + flag |
| Both batteries unreachable | > 3 consecutive cycles fail | Display "BMS OFFLINE", keep retrying |
| RS-485 silent | display didn't see frame in 90s | Display "LINK DOWN", show last value |
| Battery-side node power loss | RS-485 silent | same as above |
| ESP32-S3 firmware crash | watchdog | reset |
| User opened phone app | connect fails with "in use" | Skip cycle silently, don't alarm |

## BOM (prototype)

Prices and SKUs are May 2026 ballpark, North-American sourcing. Substitutes
fine; specific part numbers given for click-to-cart convenience.

### Battery-side node

| Item | Qty | Source | ~Price |
|---|-----|---|---|
| ESP32-S3-DevKitC-1-N8R2 dev board |  1  | DigiKey/Mouser | $15 |
| SN65HVD3082EDR — RS-485 transceiver, 3.3 V |  1  | DigiKey 296-21908 | $1.20  |
| Pololu D24V5F3 12→3.3 V 500 mA buck |  1  | Pololu #2842 | $7 |
| Pololu D24V6F12 24→12 V 600 mA buck (or a TPS62933 with feedback for 12V) | 1 | Pololu #2851 | $7 |
| 1 A fast-blow fuse + ATO holder |  1  | DigiKey | $3 |
| DS3231 RTC module (battery-backed) |  1  | Adafruit/Amazon | $5 |
| P-MOSFET load switch (e.g. AOI4127E) |  1  | DigiKey | $1.50  |
| Hardware override button (panel-mount) |  1  | DigiKey | $2 |
| 120 Ω 1/4 W resistor (RS-485 term) |  1  | any | $0.10  |
| RJ45 keystone jack + 8P8C breakout |  1  | DigiKey/Amazon | $4 |
| Ring terminals for the 24 V pack tap |  2  | hardware store | $2 |
| Project box, IP65, ~80×60×40 mm |  1  | Hammond/Amazon | $8 |
| Hookup wire, headers, 100 µF cap, etc. | | | $5 |

### Display-side node

| Item | Qty | Source | ~Price |
|---|-----|---|---|
| ESP32-S3-DevKitC-1-N8R2 dev board |  1  | DigiKey/Mouser | $15 |
| SN65HVD3082EDR — RS-485 transceiver, 3.3 V |  1  | DigiKey 296-21908 | $1.20  |
| Pololu D24V5F3 12→3.3 V 500 mA buck |  1  | Pololu #2842 | $7 |
| Waveshare 4.2" tri-color e-paper (B) v2 + driver HAT | 1 | Waveshare/Adafruit | $40 |
| 120 Ω 1/4 W resistor (RS-485 term) |  1  | any | $0.10  |
| RJ45 keystone jack + 8P8C breakout |  1  | DigiKey/Amazon | $4 |
| Tactile button switches 6×6 mm + caps |  3  | DigiKey | $1.50  |
| | | (3rd is "release BLE") | |
| Single-gang low-voltage mounting bracket |  1  | hardware store | $4 |
| Single-gang wall plate, blank to cut |  1  | hardware store | $3 |
| Standoffs, hookup wire, caps | | | $5 |

### Wire run

Already in walls — shielded Cat5e between battery area and kitchen mount.
Add two RJ45 keystone jacks (one per end) and short Cat5e patch cables to the
boards. If the existing run wasn't terminated yet: keystone jacks (~$2 each)
and a punchdown tool ($25 or borrow).

**Estimated total prototype cost: ~$170** including shipping. Round to $220
to allow for a second e-paper to test substitutes.

### Why these choices

- **ESP32-S3 (not ESP32 classic)**: USB-OTG for clean dev workflow, much
  lower deep-sleep current, BLE 5 with multiple concurrent connections.
- **SN65HVD3082**: 3.3 V native, full-duplex tolerant, ESD-protected.
  Cheaper alternative is MAX3485; both work.
- **Pololu D24V series**: tiny, ~80% efficiency at light load, integrated
  regulator with EN pin we can pull low to deep-sleep the rail. Quiescent
  current ~20 µA.
- **4.2" tri-color e-paper**: black + red + white gives us color-coded
  states (red for low-SOC alarm, etc.) without an always-on backlight.
  ~7 s full refresh, 1-2 s partial, ~0 W static. Tradeoffs vs LCD discussed
  in the *Open questions* section.

## Firmware architecture

Two ESP32-S3 firmware binaries sharing a small `volthium_lib` core:

- `volthium-bms-link/`  — battery-side. Owns BLE, reads BMS, fuses into a
  PackReading, sends RS-485 frames. Stays in light sleep otherwise.
- `volthium-display/`   — display-side. Receives RS-485 frames, runs the
  estimator (or trusts the battery-side number — TBD), drives e-paper,
  handles buttons.
- `volthium_lib/`       — shared: BMS protocol decoder (port the Python
  ej_bms logic), Estimator (port from `volthium/estimator.py`), RS-485
  frame codec, persistent storage of estimator state in NVS.

Build with ESP-IDF (not Arduino — we want fine power control and proper
light-sleep handling) or with Rust + `esp-hal` if that ecosystem is mature
enough by the time we build (5/2026 — likely yes).

Where the estimator runs: **battery-side**, sent over the wire as a number.
That way the display is dumb, and the battery-side has access to the raw
high-frequency current readings for accurate smoothing.

## OTA updates

ESP32-S3 has dual app partitions. Battery-side node has no Wi-Fi connection
(off-grid). Two options:

1. **USB-C port behind the project-box lid** for occasional manual updates.
   Simplest. Update is "go out to the cabin once a year."
2. **Use the display-side ESP32 as a temporary Wi-Fi AP** for over-the-air
   pushes, since the display-side could plausibly enable Wi-Fi briefly
   when the user holds both buttons. Update propagates over RS-485 to the
   battery side.

Option 1 first, option 2 as a stretch.

## Open questions / things to validate

- [ ] Does the BMS expose a "design capacity" field reliably across our two
      units? Currently we hardcode 200 Ah; should grab the value from each
      battery if available so we don't drift after a re-cell.
- [ ] What's the actual deep-sleep current of an ESP32-S3 with the
      transceiver attached? Spec says ~10 µA but transceiver standby varies.
- [ ] Can the e-paper handle a 30 s partial-refresh cadence for the time
      number without ghosting / requiring full refresh every cycle? Some
      panels need a periodic full-refresh "cleanup" — that's fine, schedule
      one full refresh every 10 min.
- [ ] BLE polite-poll cycle time — once we have logged data we'll know how
      fast we can plausibly read both batteries on this hardware.
- [ ] Whether a single ESP32-S3 near the batteries can hold both BLE
      connections concurrently (it has multiple BLE links available). If
      yes, polite-polling becomes faster.

## Next steps after this draft

1. (auto, in progress) Collect ~24 h of CSV data on the Mac → tune the
   estimator and decide whether to surface "time-to-full" vs
   "time-to-bulk-end" (LiFePO4 charging tapers hard above ~95%).
2. Order one of each BOM item, breadboard the battery-side node, prove the
   BLE polite-poll cycle works on hardware.
3. Wire up the RS-485 link, breadboard the display-side node with a placeholder
   serial console (skip e-paper for v1).
4. Add the e-paper, build the final wall plate, install.

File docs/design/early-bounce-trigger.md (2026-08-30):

# Design: early bounce at the 45 V cliff

## OPERATING SINCE 2026-08-21 — mechanism proven, VALUE NOT YET MEASURABLE

Ten bounces in eight days, every one acked, every one recovering the array to
89–99 V. Zero `early_bounce_error`. The mechanism is not in doubt: two examples
at one-minute resolution,

    08-22 08:38   23.5 W -> 139.8 W sustained   (6x)
    08-23 11:26   26.9 W -> 248.7 W sustained   (9x)

and one bounce per day has been enough — the array does not walk back down, so
the 30-minute interval and 6/day cap have never been approached.

**But the daily totals cannot tell whether any of that is worth anything.**

    before arming, 08-12..21 (n=10)   mean 1731 Wh
    after  arming, 08-22..28 (n=7)    mean 1741 Wh
    difference                        +10 Wh/day, +1%

Day-to-day SD is 134 Wh, so the standard error of that difference is 66 Wh and
the smallest effect this comparison could resolve is about **132 Wh/day**. The
addressable window argued for above — 68 min/day at a 100–200 W differential —
is **110–230 Wh/day**, straddling the detection floor.

So the honest statement is not "it delivered +1%" and not "it works": **this
test is underpowered and cannot see the predicted effect in either direction.**
About 13 days per arm would be needed to resolve 150 Wh at reasonable power,
and even then weather is uncontrolled.

**What would actually settle it**, in rough order of strength:

1. **A same-instrument counterfactual.** On alternate days, let the trigger log
   `early_bounce_due` but not act (it already supports exactly this — drop
   `--act-on-early`). Comparing bounced against unbounced descents *within* the
   same weather regime removes the dominant confound. Costs some production on
   the control days, which is the price of knowing.
2. **The clear-sky index** (`docs/xanbus-unknowns.md` #10) as a covariate, so
   day-to-day irradiance stops swamping the signal.
3. **Per-episode accounting** rather than per-day: integrate output over the
   30 minutes after each fire and compare against the matched window of
   unbounced descents.

Until one of those is done, the claim is: **the bounce reliably restores a
tracking array, and its effect on daily yield is unmeasured.**

## ARMED 2026-08-21. Validated 5/5 over four observe-only days.

Live on the Pi: `--act-on-sustained --act-on-early` on the guard unit. Unit
backed up to `/root/latch-guard.service.bak-20260821-preearly`; rollback is
removing the flag and `daemon-reload`, no code change.

**The pre-registered criterion was that each firing would have been RIGHT —
left alone, the episode goes on to clamp:**

| fired | the episode it fired on | outcome |
|---|---|---|
| 08-17 08:22 | crossing 08:18 | clamped after 48 min |
| 08-18 08:53 | crossing 09:16 | clamped after 108 min |
| 08-19 08:57 | crossing 08:53 | clamped after 68 min |
| 08-20 08:08 | crossing 08:11 | clamped after 92 min |
| 08-21 08:18 | crossing 08:07 | clamped after 100 min |

5 for 5. It also stayed **silent** on 08-17 11:51, which recovered on its own
in 4 minutes — precisely the case a crossing-triggered version would have
bounced needlessly. All five are morning descents at sun 23–43°; none at dawn
or dusk.

**What it addresses**, from the MPPT's own counter — same instrument either
side, no cross-meter arithmetic:

| day | fire | guard fixed | gap | made in the gap |
|---|---|---|---|---|
| 08-17 | 08:51 | 09:06 | 27 min | 5 Wh (11 W) |
| 08-18 | 09:22 | 11:04 | 114 min | 138 Wh (73 W) |
| 08-19 | 09:26 | 10:01 | 47 min | 18 Wh (23 W) |
| 08-20 | 08:37 | 09:43 | 78 min | 38 Wh (29 W) |
| 08-21 | 08:47 | 09:47 | 72 min | 23 Wh (19 W) |

**68 min/day on average**, with the array making 11–73 W. The 2026-08-14 test
showed a tracking array at 25 W recovering to 103 W in one minute, and clamped
arrays have gone to 860 W after a fix. That differential is the prize — but note
it is an ADDRESSABLE window, not a guaranteed saving: a bounced array walks down
again, which is what the 30-minute interval and 6/day cap bound.

### What to watch now that it is armed

- `early_bounce_result` — the acked/before/after record of each actual bounce.
- **A fire NOT followed by a clamp** would mean an episode resolved past 29 min,
  which nothing in 34 episodes has done. That is the signal to disarm and
  re-think, not to adjust the threshold.
- `early_fixes` in the state file against the 6/day cap. Hitting the cap means
  the array is walking down faster than 30 min after each bounce, and the
  economics change.
- The 15–29 minute band is still empty. If an episode ever lands there, the
  threshold's justification changes.

### One defect the observation period found

It logged **57 events across those 5 episodes**, one episode alone producing 18.
`below45_since` is only cleared by a re-arm or a fix, so the due condition stays
true on every 5-minute run for as long as the descent lasts. Fixed to fire on
the transition. Worth recording because the logic was right and the
instrumentation was not — and an 11× noisy stream is how an operator stops
reading it.

---

## RESULT 2026-08-14: the array DOES recover from a tracking state. Test passed.

The gating assumption is confirmed. A still-tracking array at 41.8 V recovers
from a bounce exactly as a clamped one does — instantly, and to full MPP.

Fired 08:20 local by `scripts/early_bounce_test.py`, one bounce, rc=0.

    08:17   43.2 V    25.1 W
    08:18   41.8 V    23.5 W     <- pre-fire
    08:19   42.6 V    25.2 W
    08:20   66.1 V    24.7 W     <- BOUNCE (15 s standby, in this bucket)
    08:21   93.1 V   101.0 W     <- recovered, one minute later
    08:29   99.1 V   104.8 W     <- peak
    09:13   73.6 V   180.6 W     <- +53 min, still tracking, still climbing

Scored against the criteria committed BEFORE the run:

| criterion | required | actual | |
|---|---|---|---|
| recovery peak | > 80 V | **99.1 V** | PASS |
| settled power | > pre-fire | **102.9 W vs 25.0 W** | PASS |
| walk back below 45 V | not within 15 min | **not in 53 min** | PASS |

None of the three kill conditions triggered. Power gain **+312%**. The 15 s
standby cost is invisible at 1-minute resolution — the fire bucket reads
24.7 W against 25.0 W before it.

### What this does NOT show, stated plainly

**It does not show that the bounce averted a clamp.** The crossing was at
07:59 and the bounce landed at 08:20 — **21 minutes in**, which is inside the
under-29-minute region where the rule says episodes recover on their own (10
for 10). This episode might well have recovered unaided. The first crossing of
the same morning, 07:28, did exactly that in 8 minutes with no intervention.

So the causal claim is limited to what was actually asked: **a tracking array
recovers from a bounce**. That was the untested assumption behind the entire
trigger design, every prior bounce having started from a clamped array at
27-30 V, and it is now answered. Whether an early bounce PREVENTS clamps needs
a fire at or after 29 minutes, where the outcome is otherwise determined.

### What to build

Fire at the **29-minute mark**, not at the crossing. At 29 min the rule is 20
for 20 that a clamp follows, so every fire is justified and none is wasted; at
the crossing about a third of episodes would be bounced needlessly. The control
design already specified below (separate daily cap, 48 V re-arm, 30 min minimum
interval, elevation floor, two confirmations) is unchanged.

### Methodological consequence

`cliff_table.py` is no longer pure natural history from this date. This
episode is recorded there as a RECOVERY at 22 minutes; it was a deliberate
write. The 20-of-30 figure and the 29-minute rule are pre-intervention and must
stay that way.

---

## PRE-REGISTERED TEST, authorised 2026-08-13, not yet run

Operator approved the supervised bounce without supervision, on the correct
reasoning that it is the SAME operation the guard already performs. Verified
before accepting: `run_fix()` and `xanbus_node.py --bounce --dest 1
--function 134 --send` issue identical CAN writes — claim an address
presenting NAME function 134, `set_mode(dest, 0x02)` standby, wait,
`set_mode(dest, 0x03)` operating. 16 `latch_fix_result` events on record, all
16 acked.

**What is new is not the command, it is the array's starting state.** All 16
bounces were from a CLAMPED array between 27.3 and 29.8 V. None was from a
still-tracking array at ~42 V, and the whole trigger design assumes it
recovers the same way.

**Fire condition:** array TRACKING in the 40–45 V band during a descent, sun
above 15 deg, not already clamped, and not within 2 min of a guard run (both
claim an address). ONE bounce.

**Measurements, fixed in advance:**

| | recorded before | recorded after |
|---|---|---|
| `pv_v` | at fire | peak within 5 min, and settled value at +10 min |
| `solar_w` | 5-min mean before | 5-min mean at +5..+10 min |
| time to walk back below 45 V | — | minutes from fire |

**What counts as SUCCESS:** `pv_v` recovers above 80 V (a clamp bounce reaches
~88–93 V) AND settled `solar_w` exceeds the pre-fire value by more than the
5-min noise. Anything less and the trigger is not worth building.

**What KILLS the design, stated in advance:**
- recovery peak below 60 V — the tracker cannot re-acquire from a tracking
  state the way it does from a clamp, and the premise is false;
- settled power at or below pre-fire — the bounce buys nothing;
- the array walks back below 45 V in under 15 min — the intervention would
  need to repeat so often it is worse than the clamp.

**Cost if it fails:** 15 s of standby, ~0.15 Wh. Standby drives the array to
Voc (~114 V), inside the MPPT's 150 V rating; it is the device's own
documented transition. A resulting clamp is cleared by the guard within
~20 min.

**A caveat this document's own numbers create.** Everything below was written
2026-08-07/08 and rests on "12 of 12, every crossing clamps, none recover".
That is RETRACTED. The regenerated table is **20 of 30 clamped, 10 recovered**,
and every recovery resolved in under 29 minutes. So firing at the crossing
would bounce needlessly on about a third of episodes, while firing at the
29-minute mark catches every clamp on record with no wasted bounce. The
supervised test is still the right first step — it settles the
does-it-recover question that gates either variant — but the trigger it feeds
should be the 29-minute one, not the crossing.

---

Draft 2026-08-07. **Not built, and the first step is deliberately not code.**

## The finding this rests on

Across 200 h of daylight buckets, for every sample where the array was
tracking, does a clamp follow within the hour?

| pv_v | n | clamps within 60 min |
|---|---|---|
| 35-40 V | 60 | **85%** |
| 40-45 V | 55 | **55%** |
| **45-50 V** | 90 | **2%** |
| 50 V+ | 336 | **0%** |

Below 45 V: 72%. At 45 V and up: 2 of 426. Confirmed once out-of-sample the
same evening (crossed 45 V at 16:55, clamped 17:45).

The guard currently waits for the clamp at `pv_v` ~28 V. By then the array has
already spent an hour or two producing almost nothing.

## What the trigger would cost and buy

Firing rate if the trigger were `pv_v < 45 V` while tracking, with re-arm at
48 V, 06:00-16:00:

| day | crossings | first | time below 45 V | Wh harvested below 45 V |
|---|---|---|---|---|
| 08-01 | 1 | 07:20 | 8.6 h | 114 |
| 08-03 | 1 | 07:55 | 8.1 h | 152 |
| 08-04 | 1 | 07:50 | 8.2 h | 121 |
| 08-05 | 2 | 08:25 | 3.9 h | 121 |
| 08-06 | 2 | 08:50 | 2.6 h | 67 |
| 08-07 | 1 | 08:25 | 1.9 h | 45 |

**Read that carefully — the low crossing count is an artefact.** Once below
45 V the array *stays* below until something intervenes, so history shows one
crossing per day. With the intervention in place each bounce restores the
array and it walks down again, creating a new crossing. On 08-07 the walk from
87 V to 45 V took ~100 minutes, so the realistic post-intervention rate is
**up to ~6/day**, not 1-2. The historical data cannot tell us this directly
because the intervention changes the trajectory it would be measured on.

**The prize is biggest on the worst days.** 08-04 spent 8.2 h below 45 V and
harvested 121 Wh in that window — about 15 W average — on a day that made
189 Wh in total. If bouncing held the array near its MPP for those hours, that
day roughly doubles. On a good day like 08-07 the addressable window is 1.9 h
and 45 Wh, so the gain is small. That is a good property: it helps most
exactly when help is worth most.
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

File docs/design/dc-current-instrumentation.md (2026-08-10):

# Design: permanent DC current measurement

Draft 2026-08-07. **Not built.** A design sketch for putting real current
measurement on the DC lines, using the Pi and its existing USB hub.

## Why

Three of the longest-running unknowns are all the same complaint — *we have no
independent current meter*, so when two devices disagree there is no arbiter:
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

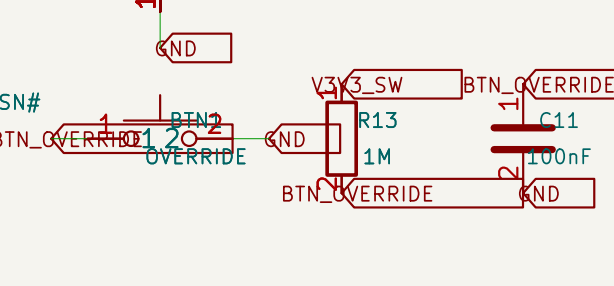
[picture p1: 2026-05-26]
hardware/reviews/visual_inspections/cp_schematic_cleanup/iter57/battery_side/11_btn1_cluster.png

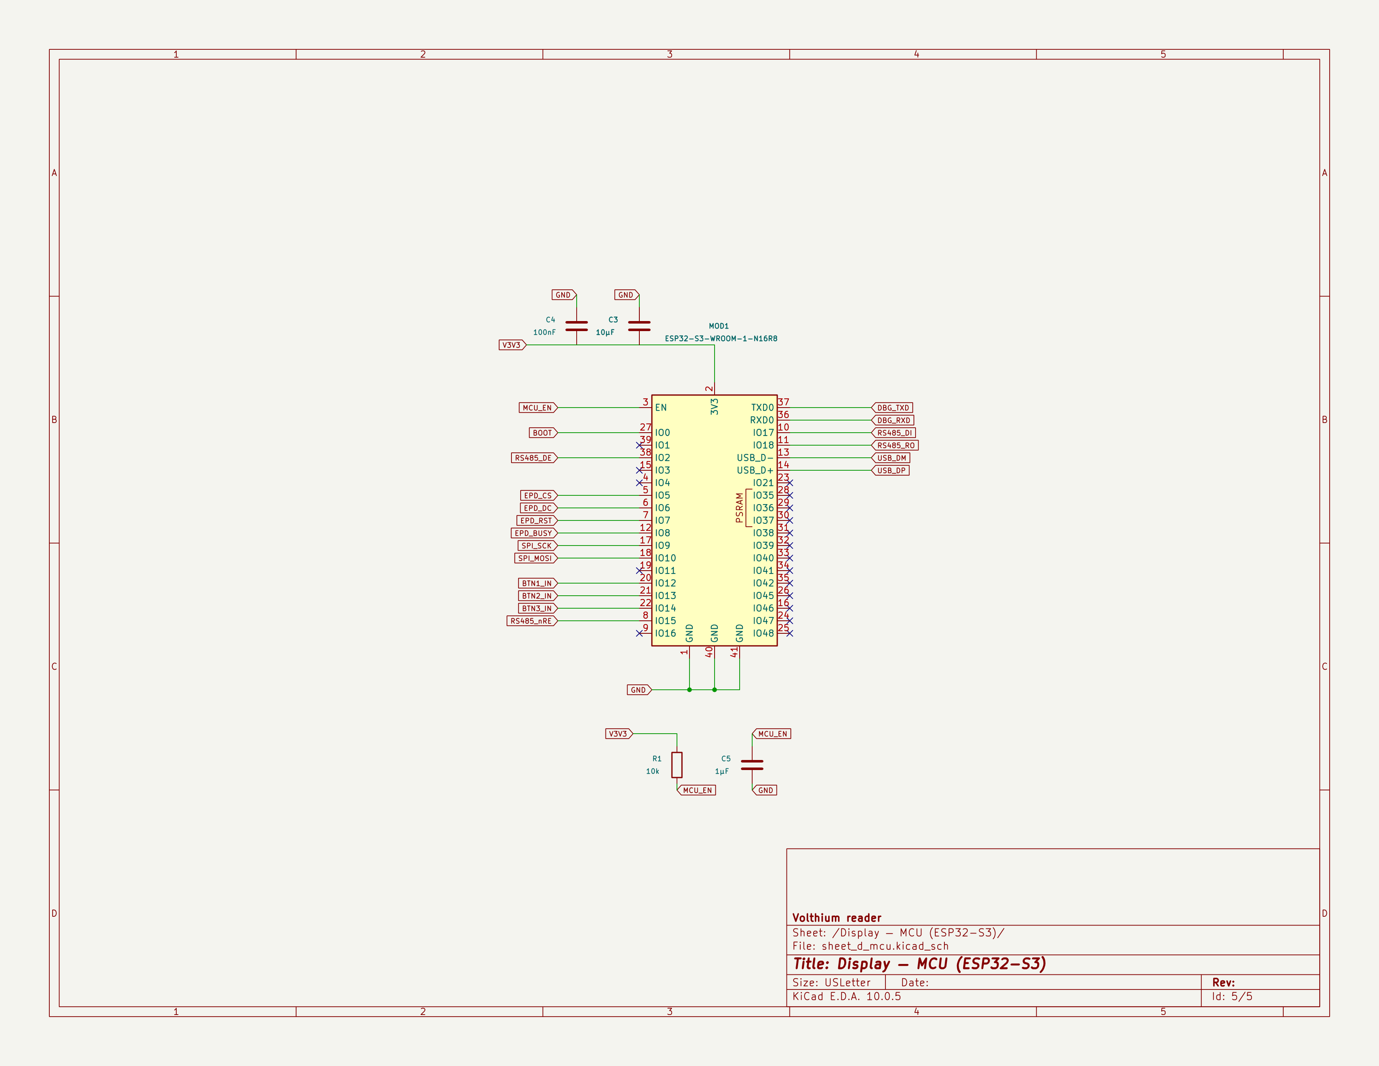
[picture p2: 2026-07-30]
hardware/reviews/visual_inspections/cp2-schematic/display-iter1/reviewer/g9/display/iter1/reviewer/battery_p5_full_300dpi.png

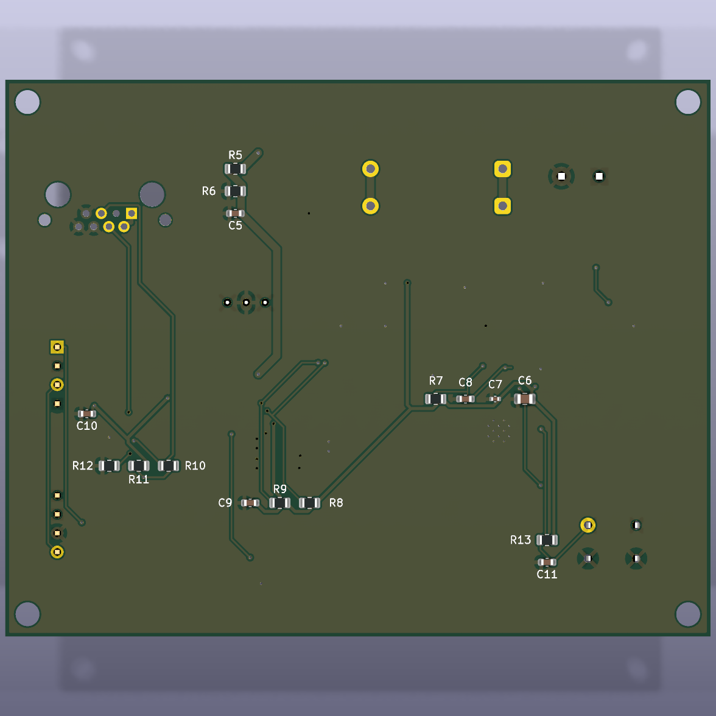
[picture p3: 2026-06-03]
hardware/reviews/visual_inspections/cp5-routing-drc/iter11/battery_bottom.png

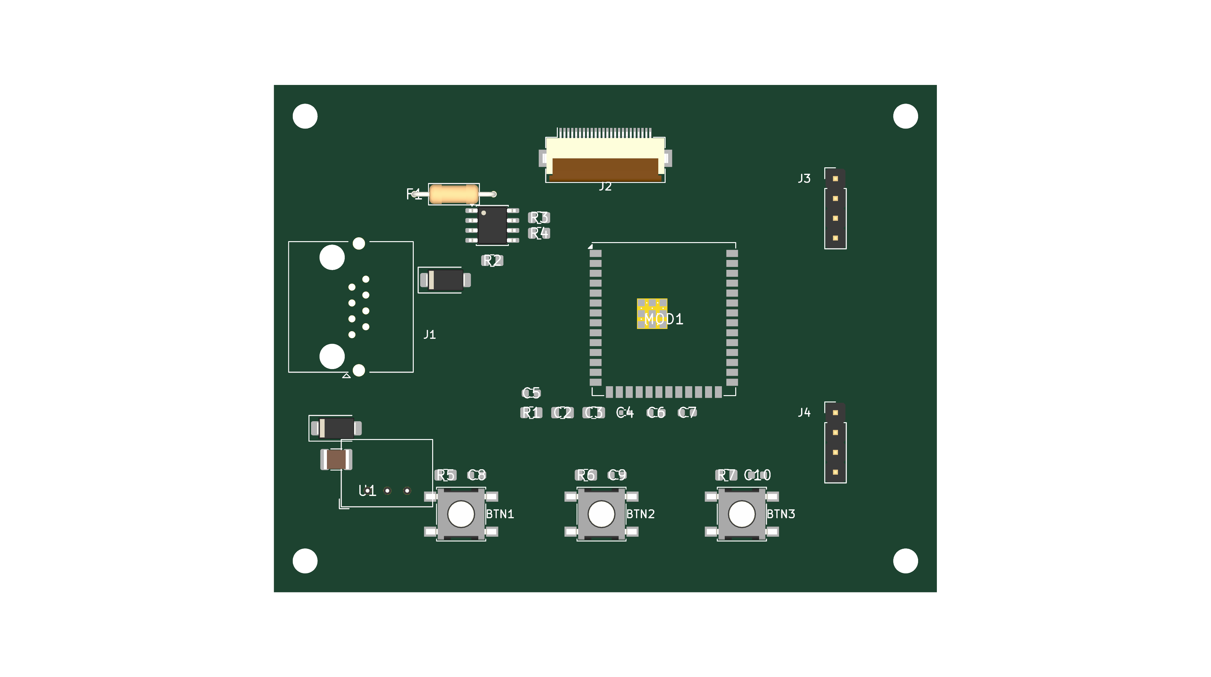
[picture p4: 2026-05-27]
hardware/reviews/visual_inspections/cp4-display-placement/iter6/top_4k.png

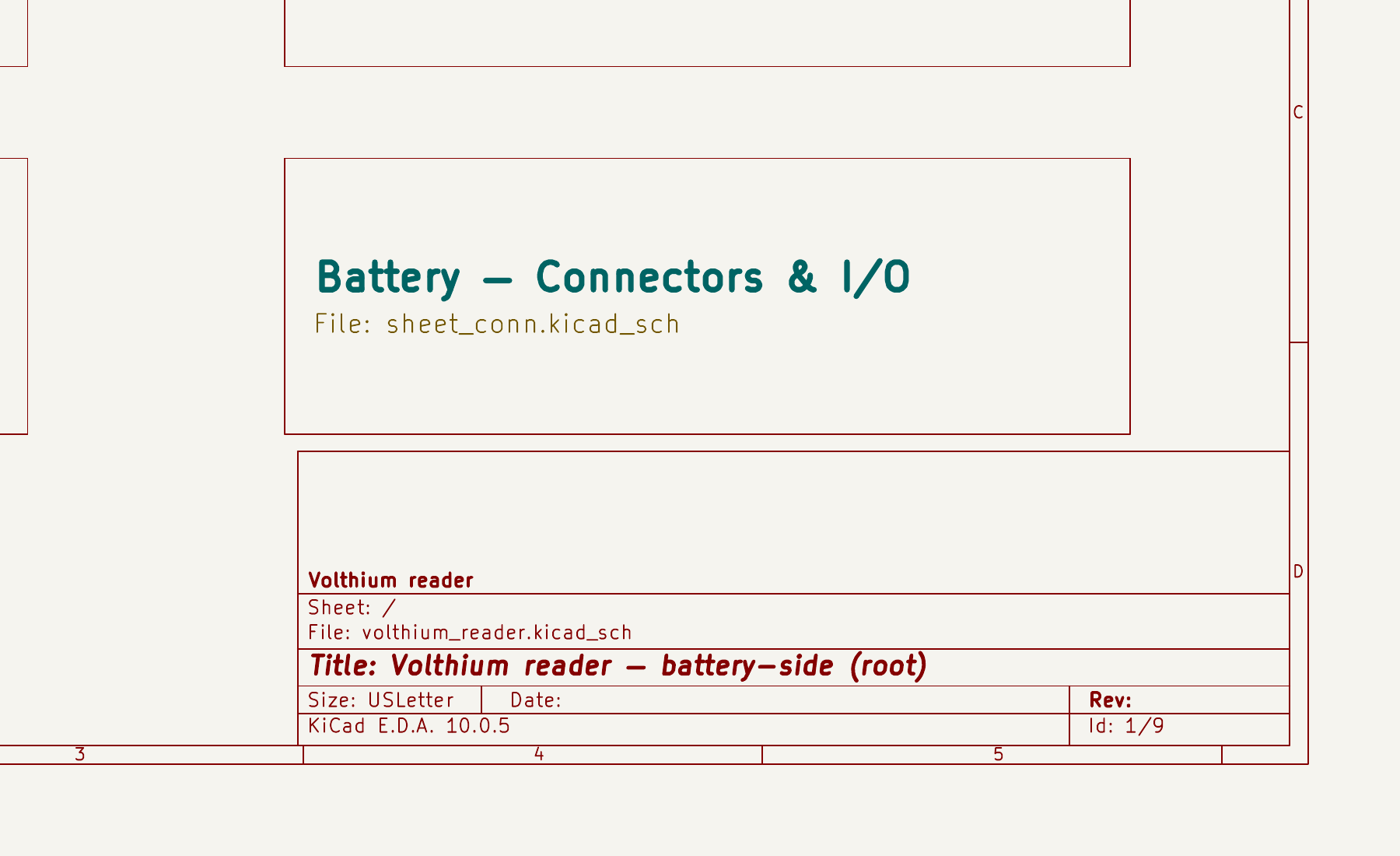
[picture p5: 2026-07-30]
hardware/reviews/visual_inspections/cp2-schematic/iter4/reviewer/battery_p1_eye_crop_06.png

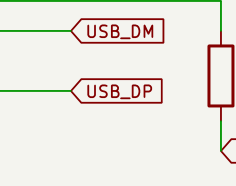
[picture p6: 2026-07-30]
hardware/reviews/visual_inspections/cp2-schematic/display-iter1/reviewer/g9/display/iter1/reviewer/display_p4_crop_08.png

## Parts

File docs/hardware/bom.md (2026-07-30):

# Bill of Materials

> **CP2 note (2026-07-23):** the CP2 additions (Xanbus CAN read DR-31, J5
> 6-pin programming header DR-32, iso-read itemization, audit-caught passive
> rows) exist ONLY in the canonical file — this view has not been re-synced.
>
> **NON-NORMATIVE (D35, 2026-07-14).** The canonical BOM is
> [`hardware/layout/cp1_bom.md`](../../hardware/layout/cp1_bom.md); on any
> disagreement, that file wins. This procurement/shopping view (proto
> alternates, sourcing methodology) has drifted before — a 2026-07-14
> audit caught it still listing the superseded EG1218 for BTN1, and a
> phantom 680 Ω battery-side bias row that D19/DR-4b had removed (both
> corrected in that audit). Drift is now mechanically checked by
> `hardware/reviews/tools/doc_consistency_check.py` before every
> handoff. At CP2 the BOM becomes **generated** from KiCad schematic
> fields and this file reduces to a pointer.

> **How to read the distributor columns:**
>
> - `[DK <id>](...)` ✓ — verified against the live Digi-Key catalog
>   2026-06-03. The bracketed identifier is the Digi-Key product
>   detail page numeric ID, which is a stable internal reference.
>   Click the link, confirm stock, copy the manufacturer PN into your
>   cart. Where an older `<digit>-<part>-ND` PN is still in use, it's
>   noted in the cell.
> - `[search …](...)` — manufacturer-part-keyed search URL for rows
>   where the canonical orderable PN is one of many compatible parts
>   (e.g. any 0805 0.1 µF X7R 16 V ceramic works; the `Part` column
>   names one example).
> - `[Mouser](...)` — search URL into Mouser's catalog, keyed on the
>   manufacturer PN. Not individually verified; treat as starting point.
>
> The verified-PN sweep (D-OPEN-6) was completed for this revision on
> 2026-06-03 — every active-device row plus the high-value connectors
> and the enclosure was clicked through. Two manufacturer corrections
> caught in the process:
>
> - **F1 (display)** — was listed as "Bel Fuse MF-R050"; the MF-R
>   series is actually **Bourns**.
> - **EN1 (battery)** — was listed as "Hammond 1556B2GY"; that PN
>   does not exist in Hammond's catalog (no 1556 series). Updated to
>   reference the real **1554 IP66 family** with both candidate sizes
>   linked, pending the user's final pick (see the row's Notes).
>
> Generic-spec rows (resistors, capacitors, inductors meeting a value
> + package spec) keep search URLs because the `Part` column names
> one example, not a binding choice — any compliant part works.

Two columns where reasonable: "Proto" (build on a breadboard / dev board
for early bring-up) and "PCB" (custom board for permanent install). The
PCB column assumes Digi-Key / Mouser ordering and SMT parts where it
makes sense; through-hole stays for anything you'd realistically replace
in the field.

Prices are May 2026 (US, single quantity, indicative). Distributor
catalogs drift week-to-week — both the price and the specific
distributor PN behind a search URL may change.

## Battery-side board

> **Battery-side reflects decisions.md D19–D25** (CP1 re-architecture +
> design-discussion calls, 2026-06). The MCU is on an always-on µA-Iq rail
> (U1 LM5166); the load switch (SSR1, AQY212EH PhotoMOS — F76) sheds only the 12 V/display feed (U2).
> Parts changed from the pre-D19 design: U1 (TPS62933→LM5165→**LM5166** 500 mA,
> for WiFi — D25), U2 (R-78E12→R-78HB12), load switch (AO3401A→ZXMP6A13F→Si2309CDS, all superseded → finally **AQY212EH PhotoMOS SSR**, iter-48 F76; Q2/gate network removed), D1 (SS24→SS26), input bulk caps →100 V, sense divider
> →1.2 M/100 k (DR-6), **RTC DS3231→RV-3028-C7 +
> backup cap** (D23/DR-8), **MOD1 −1U→−1 PCB antenna** (D21), **USB-OTG
> header→USB-C** (D22), **enclosure→3D-printed IP5x** (D20).
> **Reference designators here track the pre-regen schematic and are
> finalized when the CP2 schematic is regenerated against D19** (DR-5); the
> *parts* are the binding CP1 baseline.

### Always-on / power

| Ref | Part | Pkg | Qty | Proto / PCB | DigiKey | Mouser | Price  | Notes |
|---|---|---|-----|---|---|---|---|---|
| MOD1 | **Espressif ESP32-S3-WROOM-1-N16R8** (16 MB flash, 8 MB PSRAM) | SMD | 1 | both | [search ESP32-S3-WROOM-1-N16R8](https://www.digikey.com/en/products/result?keywords=ESP32-S3-WROOM-1-N16R8) | [Mouser](https://www.mouser.com/c/?q=ESP32-S3-WROOM-1-N16R8) | $6 | **`-1` (PCB antenna)** per D21 — plastic batteries + plastic box → no need for the external `-1U`. Needs the 15×6 mm antenna keepout. Serves BLE + WiFi (D25). |
| U1 | **TI LM5166YDRCR** ultra-low-Iq sync buck (24 → 3.3 V, **always-on**, **fixed 3.3 V**) | VSON-10 | 1 | PCB | [search LM5166Y](https://www.digikey.com/en/products/result?keywords=LM5166Y) | [Mouser](https://www.mouser.com/c/?q=LM5166YDRCR) | $4 | 3–65 V in, **9.7 µA typ / 15 µA max Iq** (corrected 2026-07-14; was an unsourced "~14 µA"), **500 mA** — feeds a duty-cycled WiFi session (D25); 65 V out-rates the 53.3 V clamp (D19/DR-4). **Fixed-3.3 V = `LM5166YDRCR`** (reviewer Finding 01: suffix `Y`=3.3 V, `X`=5 V — order **Y**, the X would force ~5 V on the ESP rail). FB→VOUT, no divider. TI Active; **confirm distributor stock at BOM-lock** (YDRCR was out-of-stock on TI.com 2026-06-21 — fallback YDRCT cut-tape / adjustable+divider; never XDRCR). |
| | *or, for proto:* Pololu D24V5F3 module | TH | 1 | Proto | [Pololu 2842](https://www.pololu.com/product/2842) | — | $7 | Convenient 3.3 V buck for bring-up (does not match the low-Iq budget) |
| U2 | **Recom R-78HB12-0.5** SIP3 buck (24 → 12 V, 0.5 A, 17–72 V in) | SIP3 | 1 | both | [search R-78HB12-0.5](https://www.digikey.com/en/products/result?keywords=R-78HB12-0.5) | [Mouser](https://www.mouser.com/c/?q=R-78HB12-0.5) | $8 | Cat5e/display feed, **switched** (behind F2 + SSR1 + R_inrush). 72 V in tolerates the ~53 V TVS clamp (D19/DR-3). Was R-78E12 (34 V) — under-rated. |
| C1, C2 | C1 22 µF / **100 V**, C2 22 µF / 25 V X7R ceramic | 1210 | 2 | PCB | [search](https://www.digikey.com/en/products/result?keywords=22uF+100V+1210+X7R) | [search](https://www.mouser.com/c/?q=22uF%20100V%201210%20X7R) | $0.80  | LM5166 input (C1, on V24_FUSED behind the ~53 V clamp → 100 V) / output (C2, 3.3 V). A bulk cap on 3V3 also buffers WiFi TX peaks (D25). |
| C3, C4 | C3 **3.3 µF** / **100 V**, C4 22 µF / 25 V X7R ceramic | 1210 | 2 | PCB | [search](https://www.digikey.com/en/products/result?keywords=3.3uF+100V+1210+X7R) | [search](https://www.mouser.com/c/?q=3.3uF%20100V%201210%20X7R) | $0.60  | U2 (R-78HB12) input (C3, on V24_SW behind the clamp → 100 V; **3.3 µF is the R-78HB12 p.4 value — was 22 µF, ~7× oversized, F90**; constrain ≤5 µF max-effective for the F2 pulse-cycle life) / 12 V output (C4). |
| L1 | inductor per LM5166 datasheet (≥0.6 A for 500 mA out) | SMD | 1 | PCB | [search](https://www.digikey.com/en/products/result?keywords=22uH+inductor+shielded) | [search](https://www.mouser.com/c/?q=22uH%20inductor%20shielded) | $0.50  | LM5166 buck inductor (sized for 500 mA / WiFi). |
| F1 | **1 A time-lag (T)** 5×20 mm ceramic fuse + holder | TH | 1 | both | [search](https://www.digikey.com/en/products/result?keywords=5x20mm+fuse+holder+1A+slow+blow) | [search](https://www.mouser.com/c/?q=5x20mm%20fuse%201A%20time%20lag) | $3 | On the 24 V tap. **Time-lag (DR-12)** to ride the ~22 µF ceramic inrush without nuisance-tripping. |
| TVS1 | **Diodes Inc SMAJ33CA-13-F** bidirectional TVS (33 V Vrwm) | SMA | 1 | PCB | SMAJ33CA-FDICT-ND | 621-SMAJ33CA-13-F | $0.83  | Surge clamp on V24_FUSED (~53 V clamp). 33 V clears the ~29 V full-charge bus (D19/DR-2). **F82: Diodes Inc (not Littelfuse); DS19005 = SMAJ_Diodes.pdf.** |
| D1 | **Vishay SS26-E3/52T** 60 V / 2 A Schottky | **DO-214AA (SMB)** | 1 | PCB | SS26-E3/52TGITR-ND | — (Mouser doesn't list this Vishay -E3 variant — 2026-07-14 sweep; DK-only) | $0.30  | Series reverse-polarity on 24 V input. 60 V (was SS24/40 V) to out-rate the ~53 V clamp (D19/DR-3). **Package SMA → SMB (API 2026-06-25).** |

### MCU support

| Ref | Part | Pkg | Qty | Proto / PCB | DigiKey | Mouser | Price  | Notes |
|---|---|---|-----|---|---|---|---|---|
| RTC1 | **Micro Crystal RV-3028-C7** I²C RTC (e.g. `…1ppm TA-QC`) | 4-pin SMD 3.2×1.5 | 1 | PCB | [search RV-3028-C7](https://www.digikey.com/en/products/result?keywords=RV-3028-C7) | [Mouser](https://www.mouser.com/c/?q=RV-3028-C7) | $2 | **D23:** 45 nA ultra-low-power, ±1 ppm RT / ±3 ppm, integrated crystal, built-in backup switchover + trickle charger. Replaces the DS3231 (~0.2 mA TCXO was the dominant idle load — DR-8). −40…+85 °C. **In stock @ DigiKey/Mouser (checked 2026-06-18).** |
| U-ESD | **USB ESD array** (**USBLC6-2SC6Y**) on the USB-C D+/D−/VBUS | SOT-23-6 | 1 | PCB | [497-11882-2-ND](https://www.digikey.com/en/products/result?keywords=USBLC6-2SC6Y) | [511-USBLC6-2SC6Y](https://www.mouser.com/c/?q=USBLC6-2SC6Y) | $0.30  | Protects the *externally-accessible* USB-C port (D22). **Use the `-2SC6Y` variant — the original SC6 is out of stock at all sources (API-verified 2026-06-25).** |
| U5 | **3.3 V LDO** (AP2112K-3.3, ~600 mA), VBUS→3V3_USB | SOT-23-5 | 1 | PCB | [search AP2112K-3.3](https://www.digikey.com/en/products/result?keywords=AP2112K-3.3) | [Mouser](https://www.mouser.com/c/?q=AP2112K-3.3) | $0.20 | **USB maintenance power (D29).** VBUS-referenced → zero pack draw when unplugged. Lets the MCU run/program/troubleshoot off USB with no 24 V. |
| U6 | **TI TPS2116DRLR** priority power mux (~1.3 µA Iq, 2.5 A, reverse-blocking) | **SOT-583 (leadless)** | 1 | PCB | [search TPS2116DRLR](https://www.digikey.com/en/products/result?keywords=TPS2116DRLR) | [Mouser](https://www.mouser.com/c/?q=TPS2116DRLR) | $0.70 | **D29.** VIN1=USB-LDO (priority), VIN2=LM5166 buck, OUT=V3V3 → USB present = buck idles (pack draw ~µA). Only ~1.3 µA always-on. **SOT-583, leadless — kept (D33/DR-24): the leaded TPS2113A would cost 57× the Iq; reflowed with paste stencil instead.** |
| Q3, Q4 | small-signal N-FETs (UVLO bypass + its VBUS-driven pulldown) | SOT-23 | 2 | PCB | [search 2N7002](https://www.digikey.com/en/products/result?keywords=2N7002) | [Mouser](https://www.mouser.com/c/?q=2N7002) | $0.10 ea | **D29 (fail-safe, reviewer F03).** Q3 (series in U4 RESET→EN) **defaults ON via 100 kΩ→V3V3** = UVLO active when VBUS absent; Q4 (VBUS-driven) opens it when USB present so the MCU boots off USB on a dead/absent pack. |
| R_hys | UVLO external hysteresis (RESET→SENSE) | 0805 | 1 | PCB | — | — | $0.05 | **Reviewer iter-5 F01 + iter-6 F04/D33 (~11.5 MΩ).** RESET is active-low → R_hys is positive feedback: healthy (RESET≈3.3 V) pulls SENSE up → drops the *falling* trip ~1.5 V; asserted (VOL 0–0.2 V) still sources a small current → release lands ~0.4–0.5 V above the plain divider threshold. Band = trip ~20.0 V / release ~21.7–21.8 V. Built-in VHYS (~6 mV at SENSE) too small alone. Pairs with the **release-sized** R1≈5.16 MΩ/R2≈100 kΩ divider. |
| C-bk | **Low-leakage backup cap ~10–50 mF (not a supercap)** on RV-3028 VBACKUP | SMD  | 1 | PCB | [search](https://www.digikey.com/en/products/result?keywords=low+leakage+10mF+ceramic+tantalum) | — | $0.50  | **D23 + reviewer F09 (iter-8 F07 sweep):** trickle-charged by the RTC; rides a full pack disconnect. Supercaps at 0.1 F class have ~µA leakage that would dwarf the 45 nA RTC and *shorten* hold time — the ≤50 mF, low-leakage constraint is the point. No coin, no D14 short risk. |
| C5, C6 | 100 nF X7R | 0603 | 2 | PCB | [search](https://www.digikey.com/en/products/result?keywords=100nF+0603+X7R+25V) | [search](https://www.mouser.com/c/?q=100nF%200603%20X7R%2025V) | $0.05  | RTC + ESP decoupling. |
| C7 | 10 µF X7R | 0805 | 1 | PCB | [search](https://www.digikey.com/en/products/result?keywords=10uF+0805+X7R+16V) | [search](https://www.mouser.com/c/?q=10uF%200805%20X7R%2016V) | $0.10  | ESP32 bulk. |

### RS-485

| Ref | Part | Pkg | Qty | Proto / PCB | DigiKey | Mouser | Price  | Notes |
|---|---|---|-----|---|---|---|---|---|
| U3 | **TI THVD1400DR** 3.3–5.5 V half-duplex, 500 kbps, full fail-safe RX | SOIC-8  | 1 | both | [DK 296-THVD1400DRTR-ND](https://www.digikey.com/en/products/detail/texas-instruments/THVD1400DR/9483064) ✓ | [Mouser 595-THVD1400DR](https://www.mouser.com/c/?q=THVD1400DR) | $1.38  | **D34/DR-25 (revised iter-10 F08):** the iter-8 first cut picked ISL3175EIBZ but its 12 µA max shutdown Iq (vs 10 nA *typical* I quoted) failed max-to-max. THVD1400 has **1 µA max shutdown** (12× better), datasheet-guaranteed internal DE pull-DOWN + /RE pull-UP → default-safe without external resistors. Full fail-safe RX (open/short/idle bus → RO HIGH). SN75176 SOIC-8 pinout (drop-in). TI Active, DK+Mouser **35016** stock. |
| R1 | 120 Ω 1 % RS-485 termination (e.g. Vishay CRCW0805120RFKEA) | 0805 | 1 | both | [search CRCW0805120RFKEA](https://www.digikey.com/en/products/result?keywords=CRCW0805120RFKEA) | [Mouser](https://www.mouser.com/c/?q=CRCW0805120RFKEA) | $0.10  | Bus terminator. Generic spec — any compliant 0805 120 Ω 1 % works. |
| — | *(no battery-side idle bias — removed per D19/DR-4b)* | — | 0 | — | — | — | — | Battery 3V3 is always-on; a battery-side bias would draw continuously and blow the ~1 mW hard-cut budget. Bias footprints live on the **display** end and are **DNP by default** (iter-12 F12) — THVD1400 Full Fail-Safe RX needs no bias for idle correctness. |
| TVS (A/B) | **Diodes Inc SMAJ12CA-13-F** bidirectional TVS  | SMA | 1 | PCB | SMAJ12CA-FDICT-ND | 621-SMAJ12CA-13-F | $0.30  | Surge/ESD on the RS-485 A/B pair (schematic refdes TVS2). **F82: Diodes Inc; DS19005.** |
| TVS3 | **Diodes Inc SMAJ15A-13-F** unidirectional TVS (V12_CAT5E↔GND) | SMA | 1 | PCB | SMAJ15A-FDICT-ND | 621-SMAJ15A-13-F | $0.75 | **DR-15 / F82 (Diodes Inc, DS19005):** clamps surges on the long in-wall 12 V Cat5e pair at the **battery** end. Matches the display-end SMAJ15A so **both** ends of the exposed pair are protected (was: display-end only). Zero static draw. |

### Hard-cut, override, sensing

| Ref | Part | Pkg | Qty | Proto / PCB | DigiKey | Mouser | Price  | Notes |
|---|---|---|-----|---|---|---|---|---|
| SSR1 | **Panasonic AQY212EH** PhotoMOS SSR (60 V / 550 mA, **Ron 0.85 Ω typ / 2.5 Ω max**) | DIP-4 (THT) | 1 | PCB | 255-2963-ND | 769-AQY212EH | $2.81 | Display-feed load switch, switched branch V24_FUSED→F2→SSR1→R_inrush→V24_SW. **F76: replaced the discrete Q1 P-FET + Q2 BJT gate driver** (no discrete driver could be datasheet-guaranteed OFF at temp). OFF = open MOSFET, **≤1 µA leakage @ 25 °C (spec; no hot max published — est. + acceptance test, F83)**, opto-isolated, rated −40…+85 °C. **Ron corrected F79 (0.25 Ω was the AQY211EH sibling).** DK 255-2963-ND Active. |
| R_opto | **330 Ω** 0805 1 % — PWR_EN → SSR1 LED | 0805 | 1 | PCB | RMCF0805FT330RCT-ND | 71-CRCW0805-330-E3 | $0.10 | SSR LED current limit — worst-case I_F ≥ 5 mA ≥ datasheet-recommended min. New (F76); value corrected to 330 Ω (F79 — 390 Ω gave only 4.57 mA worst-case). |
| R_inrush (×2) | **2× 75 Ω** 1206 **pulse-proof (Vishay CRCW-HP)** in series = 150 Ω — switched branch | 1206 | 2 | PCB | 541-75.0UTR-ND | 71-CRCW120675R0FKEAH | $0.06 ea | **F80/F84; re-coordinated iter-54 (F86).** Series pair so each survives the worst-case fault: 5.74 W total → **2.87 W each < the CRCW-HP §8.1 guarantee 4.69 W/5 s (defined at P70=0.75 W)**. A single 150 Ω 1206-HP fails that (5.74 W > 4.69 W). Inrush 0.197 A < SSR continuous. Datasheet Vishay_CRCW_HP.pdf. |
| F2 | **80 mA** very-fast SMD fuse (Littelfuse 451 Nano2 SMF) — switched branch | **451 SMF 6.10×2.69 mm** (not 1206, F91) | 1 | PCB | F3649TR-ND | 576-0451.080MRL | $4.57 | **NEW (F84); re-picked 62→80 mA iter-54 (F87).** Coordinated fault clear: worst-case short 0.197 A = 246 % (214 % at −40 °C) → clears within 200 %→5 s. 80 mA (not 62 mA) so (with C3 right-sized to 3.3 µF, F90) the turn-on I²t is 2.9 % of melt I²t (≤4.3 % at the 5 µF max-effective ceiling), far under Littelfuse's ≤20 %/100 k-pulse selection basis. Normal ~5 mA ≪ 80 mA. 125 V/50 A interrupt, melt I²t 3.3e-4 A²s. Datasheet Littelfuse_451_453.pdf. |
| R4 | 100 kΩ 1 % — PWR_EN pull-down (brown-out failsafe-off) | 0805 | 1 | PCB | [search](https://www.digikey.com/en/products/result?keywords=100k+0805+1%25) | [search](https://www.mouser.com/c/?q=100k%200805%201%25) | $0.10 | Brown-out failsafe-off: holds PWR_EN low (SSR LED off → open) when the ESP GPIO is high-Z. |
| U4 | **TI TPS3808G01DBVR** voltage supervisor (~2.4 µA, adj SENSE, OD RESET, prog. CT delay) | **SOT-23-6 (leaded)** | 1 | PCB | [search TPS3808G01DBVR](https://www.digikey.com/en/products/result?keywords=TPS3808G01DBVR) | [Mouser](https://www.mouser.com/c/?q=TPS3808G01DBVR) | $0.90 | **Hardware UVLO backstop (D28/DR-16); repackaged WSON→SOT-23-6 for solderability (D33/DR-24).** Asserts ESP EN low below ~20 V pack → MCU to ~µA reset + display auto-sheds. **VIT 0.405 V; Active, DK 149k.** Divider re-derived at CP2. |
| R_uv1,R_uv2 | UVLO pack divider → U4 SENSE (release-sized R1≈5.16 MΩ/R2≈100 kΩ; trip ~20.0 V / release ~21.7–21.8 V) | 0805 ×2 | 2 | PCB | [search](https://www.digikey.com/en/products/result?keywords=high+value+0805+resistor) | — | $0.10 | VIT 0.405 V → ~4.6 µA draw at 24 V (D28/D33; F01 polarity + F04 release refinement). |
| C_ct | UVLO CT deglitch cap (~tens of ms) | 0603 | 1 | PCB | [search](https://www.digikey.com/en/products/result?keywords=0603+X7R+cap) | — | $0.05 | Rejects momentary sags (D28). |
| R5, R6 | 1.2 MΩ / 100 kΩ — 24 V → ~2.25 V sense divider  | 0805 ×2 | 2 | PCB | [search](https://www.digikey.com/en/products/result?keywords=1.2M+100k+0805+1%25) | [search](https://www.mouser.com/c/?q=1.2M%20100k%200805%201%25) | $0.10  | 24 V sense on ADC1_CH0 (GPIO1). Full charge (29.2 V) → **2.25 V**, inside the ESP ADC linear band (DR-6). High-impedance (~19 µA) for power-first; the 1.2 MΩ top also current-limits a ~53 V surge to ~41 µA. C5 (100 nF) tank. Always-on. |
| BTN1 | **C&K 8125SHZBE** panel-mount (bushing) momentary pushbutton, gold contacts, 0.4 VA @ 20 V logic-level rating (SPDT wired COM–NO) | Panel-mount | 1 | both | [CKN4022-ND](https://www.digikey.com/en/products/result?keywords=8125SHZBE) | [611-8125-241](https://www.mouser.com/c/?q=8125SHZBE) | $18.47 | On battery-side enclosure; BTN_OVERRIDE on GPIO7 (RTC-wake). **Δ: was EG1218 → RP3502MABLK → 8125SHZBE (iter-23 F22: RP3502 had no dry-circuit rating for our 3.3 V/µA use; 8125+B is explicitly rated — CK_8020_series.pdf p.26 Low Level / Dry Circuit, function p.2).** D-OPEN-13 moot (unsealed accepted, IP5x indoor). Canonical row: cp1_bom.md |
| C8 | 100 nF debounce | 0603 | 1 | PCB | (as C5) | (as C5) | $0.05  |  |

### Interconnect / enclosure

| Ref | Part | Qty | DigiKey | Mouser | Price | Notes |
|---|---|-----|---|---|---|---|
| J1 | **Amphenol RJHSE5380** RJ45 jack (Cat5e, T568B) | 1 | [search](https://www.digikey.com/en/products/result?keywords=RJHSE5380) | [search](https://www.mouser.com/c/?q=RJHSE5380) | $4 | Patch from this to in-wall Cat5e, or hardwire. This is the footprint the PCB targets. |
| J1 | **Phoenix pluggable 24 V input**: MSTBA 2,5/2-G-5,08 header (**1757242**, 277-1106-ND) + MSTB 2,5/2-ST-5,08 plug (**1757019**, 277-1011-ND) | 1 | [1757242](https://www.digikey.com/en/products/result?keywords=1757242) | [1757019](https://www.digikey.com/en/products/result?keywords=1757019) | $3.50 | Pack wires land on the screw-clamp plug (2-pos, 5.08 mm, 12–30 AWG); plugs into the board header — disconnect without unscrewing (D19). Corrected 2026-07-01 (was a wrong 3.81 mm MKDS terminal). |
| EN1 | **User-3D-printed plastic enclosure**, IP5x (indoors) | 1 | — (printed) | — | — | (filament) | **D20:** wall-mount above the batteries with an air gap; sized to the final board outline (set at CP3). Has a board-edge port for the USB-C maintenance connector (dust cap). No commercial box / no IP65–66. |
| — | M3 standoffs + screws | | (any) | (any)  | $2 |  |
| — | Cat5e patch cable, 30 cm | 1 | (any) | (any)  | $3 | Inside the enclosure |

### Battery-side subtotal (PCB version, single qty): **~$45** in components, ~$60 with enclosure + connectors.

## Display-side board

### Power

| Ref | Part | Pkg | Qty | Proto / PCB | DigiKey | Mouser | Price  | Notes |
|---|---|---|-----|---|---|---|---|---|
| U1 | **Recom R-78E3.3-0.5** SIP3 buck (12 V → 3.3 V, 0.5 A) | SIP3 | 1 | both | [945-1661-5-ND](https://www.digikey.com/en/products/detail/recom-power/R-78E3.3-0.5/3593412) | [search](https://www.mouser.com/c/?q=R-78E3.3-0.5) | $5 | 80 % eff. at 200 mA. Digi-Key PN verified. |
| F1 | **Bourns MF-R025** PTC resettable fuse, **~0.25 A hold** (DR-11) | TH | 1 | both | [search MF-R025](https://www.digikey.com/en/products/result?keywords=MF-R025) | [Mouser](https://www.mouser.com/c/?q=MF-R025) | $1 | On the 12 V Cat5e feed. **Δ (DR-11): 0.5 A → ~0.25 A** — matches the ~40–150 mA display load and trips below the battery-side U2 ~0.5 A foldback (the 0.5 A part was too loose for real cable protection). |
| TVS1 | SMAJ15A on 12 V input | SMA | 1 | PCB | (as battery TVS2) | (as battery TVS2) | $0.30  |  |
| C1 | 22 µF / 25 V X7R | 1210 | 1 | PCB | (as battery C1) | (as battery C1) | $0.20  | Input bulk |
| C2 | 10 µF X7R | 0805 | 1 | PCB | (as battery C7) | (as battery C7) | $0.10  | 3.3 V output bulk |

### MCU support

| Ref | Part | Pkg | Qty | Proto / PCB | DigiKey | Mouser | Price  | Notes |
|---|---|---|-----|---|---|---|---|---|
| MOD1 | **Espressif ESP32-S3-WROOM-1-N16R8** (`-1`, display side) | SMD | 1 | both | [search](https://www.digikey.com/en/products/result?keywords=ESP32-S3-WROOM-1-N16R8) | [Mouser](https://www.mouser.com/c/?q=ESP32-S3-WROOM-1-N16R8) | $6 | **D26: radio unused** — RS-485 is the only link; kept for firmware/footprint commonality, RF disabled, **antenna keepout dropped**. Common firmware base. |
| J-USB | **USB-C receptacle** (native ESP32-S3 USB, board edge) | THT top-mount (F13) | 1 | PCB | [search USB-C receptacle](https://www.digikey.com/en/products/result?keywords=USB-C+receptacle+16pin) | [Mouser](https://www.mouser.com/c/?q=USB-C%20receptacle) | $0.60 | **D27:** bench/recovery port — reached by popping the faceplate (no front cutout). Routine updates are OTA over RS-485. |
| U-ESD | **USB ESD array** (**USBLC6-2SC6Y**) | SOT-23-6 | 1 | PCB | [497-11882-2-ND](https://www.digikey.com/en/products/result?keywords=USBLC6-2SC6Y) | [511-USBLC6-2SC6Y](https://www.mouser.com/c/?q=USBLC6-2SC6Y) | $0.30  | ESD clamp on the USB-C D+/D−/VBUS (D27). **Use `-2SC6Y` — SC6 out of stock everywhere (API-verified 2026-06-25).** |
| U3-LDO | **3.3 V LDO** (AP2112K-3.3, ~600 mA), VBUS→3V3_USB | SOT-23-5 | 1 | PCB | [search AP2112K-3.3](https://www.digikey.com/en/products/result?keywords=AP2112K-3.3) | [Mouser](https://www.mouser.com/c/?q=AP2112K-3.3) | $0.20 | **USB maintenance power (D29).** VBUS-referenced. Run/program the display MCU off USB without pulling 12 V. |
| U4-MUX | **TI TPS2116DRLR** priority power mux | **SOT-583 (leadless)** | 1 | PCB | [search TPS2116DRLR](https://www.digikey.com/en/products/result?keywords=TPS2116DRLR) | [Mouser](https://www.mouser.com/c/?q=TPS2116DRLR) | $0.70 | **D29.** VIN1=USB-LDO (priority), VIN2=R-78E3.3, OUT=V3V3. No UVLO bypass (display has no supervisor). **SOT-583, leadless (see DR-24).** |
| R1 | 10 kΩ ESP32 EN pull-up | 0805 | 1 | PCB | [search](https://www.digikey.com/en/products/result?keywords=10k+0805+1%25) | [search](https://www.mouser.com/c/?q=10k%200805%201%25) | $0.05  |  |
| C3 | 10 µF X7R MOD1 V3V3 bulk | 0805 | 1 | PCB | (as C2) | (as C2) | $0.10  | Close to the ESP32 module 3V3 pin |
| C4 | 100 nF X7R MOD1 V3V3 HF | 0402 | 1 | PCB | [search](https://www.digikey.com/en/products/result?keywords=100nF+0402+X7R+16V) | [search](https://www.mouser.com/c/?q=100nF%200402%20X7R%2016V) | $0.05  | The 0402 close-in cap — smaller package fits inside MOD1's pad row |
| C5 | 1 µF ESP_EN soft-start | 0603 | 1 | PCB | [search](https://www.digikey.com/en/products/result?keywords=1uF+0603+X7R) | [search](https://www.mouser.com/c/?q=1uF%200603%20X7R) | $0.05  | Paired with R1 forms the EN power-on delay. |
| C6 | 1 µF panel VCC bulk | 0603 | 1 | PCB | (as C5) | (as C5) | $0.05  | Reduces VCC dip during EPD refresh |
| C7 | 100 nF U2 V3V3 decoupling | 0603 | 1 | PCB | (as battery C5) | (as battery C5) | $0.05  | At the RS-485 transceiver |

### Display

| Ref | Part | Pkg | Qty | Proto / PCB | DigiKey | Mouser | Price  | Notes |
|---|---|---|-----|---|---|---|---|---|
| LCD1 | **Waveshare 4.2inch e-Paper Module (B)** — tri-color B/W/R, 400×300, **onboard driver PCB + 8-pin SPI** header | module | 1 | both | [search](https://www.digikey.com/en/products/result?keywords=Waveshare+4.2+e-Paper+B+V2) | [search](https://www.mouser.com/c/?q=Waveshare%204.2%20e-Paper%20B%20V2) | $35 | Connects to **J2 (8-pin)** via its included cable: VCC/GND/DIN/CLK/CS/DC/RST/BUSY (DR-7). **Primary source:** [waveshare.com/4.2inch-e-paper-module-b.htm](https://www.waveshare.com/4.2inch-e-paper-module-b.htm). **Not** the bare `WFT0420CZ15` panel — that's a raw 24-pin-FPC display needing an on-board booster network. |
| J2 | **JST-PH 2.0 mm 8-pin** post header (B8B-PH-K-S top / S8B-PH-K-S side) — e-paper SPI | THT 1×8 | 1 | PCB | [B8B-PH-K-S](https://www.digikey.com/en/products/result?keywords=B8B-PH-K-S) | [Mouser](https://www.mouser.com/c/?q=B8B-PH-K-S) | $0.20  | **Matches the Waveshare Module (B)'s onboard JST-PH 2.0 connector (verified).** Same family both ends → off-the-shelf pre-crimped PH↔PH cable (e.g. ASPHSPH24K102-class), no crimp tool; keyed by design. **Δ (DR-7): was a 24-pin Hirose FH12-24S FFC** (bare-panel connector). |

### RS-485

| Ref | Part | Pkg | Qty | Proto / PCB | DigiKey | Mouser | Price  | Notes |
|---|---|---|-----|---|---|---|---|---|
| U2 | **TI THVD1400DR** (as battery U3) | SOIC-8  | 1 | both | (as battery U3) | (as battery U3) | $1.38  | **D34/DR-25 (revised iter-10 F08 + iter-14 F15)** — see battery-side U3 row. Same part, same footprint. Display firmware latches GPIO15 LOW in deep sleep so /RE = 0 (receiver on); wake is the **`ext1` `ESP_EXT1_WAKEUP_ANY_LOW` RTC-GPIO mask** over GPIO12/13/14 (buttons) + GPIO18 (RO), triggered by a master-driven sustained-LOW BREAK — **not** the ESP UART wake API (UART is off in Deep-sleep). |
| R2 | 120 Ω 1 % termination | 0805 | 1 | both | (as battery R1) | (as battery R1) | $0.10  | RS-485 term |
| R3, R4 | ~330 Ω idle bias footprints (A→3V3, B→GND) — **DNP by default (iter-12 F12)** | 0805 ×2 | 2 (DNP) | PCB | [search 330Ω 0805 1%](https://www.digikey.com/en/products/result?keywords=330+ohm+0805+1%25) | [search](https://www.mouser.com/c/?q=330%20ohm%200805%201%25) | $0.10  | THVD1400 has guaranteed Full Fail-Safe RX; populated bias would draw 4.58 mA × 3.3 V = 15 mW continuously whenever display is powered. Leave footprint, stuff at CP5 bench only if EMI testing reveals need. |
| TVS2 | SMAJ12CA | SMA | 1 | PCB | (as battery TVS1) | (as battery TVS1) | $0.30  | RS-485 ESD |

### Buttons + interconnect

| Ref | Part | Qty | DigiKey | Mouser | Price | Notes |
|---|---|-----|---|---|---|---|
| BTN1–3 | 6×6 mm tactile switch, **tall actuator / printed cap extension** (e.g. E-Switch TL3300) | 3 | [search](https://www.digikey.com/en/products/result?keywords=TL3300+tactile+switch) | [search](https://www.mouser.com/c/?q=TL3300%20tactile%20switch) | $0.50 | Software-defined (on-screen labels, D7). Cap height spans the PCB→faceplate gap (DR-10). |
| J1 | **Right-angle / low-profile RJ45** jack (T568B, shielded) | 1 | [search RJ45 right angle shielded](https://www.digikey.com/en/products/result?keywords=RJ45+right+angle+shielded) | (Mouser) | $4 | **Δ (DR-10):** right-angle so it doesn't eat the shallow-box depth; in-wall Cat5e enters from the side/bottom. |
| — | **3D-printed bracket + faceplate** (user-printed, D8/D20/D27) — **double-gang** | 1 | (printed) | | (filament) | Replaces the single-gang plate (stale). E-paper module mounts to the faceplate back; main PCB to the bracket; designed against the PCB STEP. |

### Display-side subtotal (PCB version): **~$55** in components, ~$65 with the mounting bits.

## Grand totals

| Build | Battery-side | Display-side | Cable / connectors | Total |
|---|---|---|---|---|
| Proto (dev boards + breakouts) | ~$55 | ~$65 | ~$10 | **~$130** |
| Custom PCB (qty 1 of each) | ~$60 | ~$65 | ~$10 | **~$135** |
| Custom PCB w/ a spare e-paper  | " | +$35 | " | **~$170** |

Add ~$50–80 for PCB fab (e.g. JLCPCB qty 5 of each board, 2-layer, HASL,
ENIG slightly more).

## Substitutions worth noting

- **Always-on buck (U1)**: must be **both** ≥60 V input (to survive the
  ~53 V TVS clamp on V24_FUSED) **and** µA-class Iq (so the always-on rail
  costs ~nothing at low SOC). The LM5166 (3–65 V, ~10 µA sleep Iq, 500 mA) hits both;
  that combination is rare. Alternatives: LM5166, MAX17552 (60 V, ~28 µA).
  A plain brick (R-78 family) is *not* suitable here — bricks idle at
  milliamps, which would make the always-on trickle tens of mW (D19/DR-4).
- **Switched 12 V buck (U2)**: a wide-input (≥60 V) module to survive the
  clamp; R-78HB12 chosen for stock + footprint continuity with the
  display's R-78E3.3. Iq doesn't matter here — it's off at low SOC.
- **RS-485 transceiver**: any 3.3 V half-duplex, slew-rate-limited part is
  fine. MAX3485 is the obvious other choice; slightly higher current draw.
- **E-paper**: if 4.2" tri-color goes out of stock, the same Waveshare 4.2"
  monochrome (B/W) is more available — the FW abstracts panel color depth.
  The Pervasive Displays EXT3-1 panels are nicer but harder to source.
- **MCU**: ESP32-S3 was chosen for BLE 5 + USB-OTG + low deep-sleep. An
  nRF52840 module would work too but the Bluedroid/NimBLE story is more
  established on ESP-IDF.

## Procurement methodology

Treat this file as a **shopping starting point**, not a binding cart. The
distributor-search links are deterministic given the manufacturer PN; the
specific product they resolve to may vary as distributor catalogs churn.

Before placing a JLCPCB order or pulling distributor carts:
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

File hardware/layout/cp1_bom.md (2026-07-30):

# CP1 — Bill of materials (consolidated)

**Status**: CP1 snapshot (reconciled to D19)
**Scope**: the **complete** part list — every reference designator across
both boards, with vendor SKUs, quantities, and rationale. This is the
authoritative *engineering* BOM for CP1;
[`docs/hardware/bom.md`](../../docs/hardware/bom.md) is the curated
*procurement / shopping* view (distributor methodology + substitution
notes). Both are reconciled to D19.

> **Reference designators here track the pre-regen schematic and are
> finalized when the CP2 schematic regenerates.** A single fully-merged
> BOM (one refdes scheme, one file) is deferred to CP2 — unifying refdes
> now would just be redone then.

Conventions:
- Prices = single-quantity from DigiKey US, May 2026, USD. Mouser as backup.
- Where the BOM line is unchanged from the prior pass, it's annotated
  "(unchanged)". Otherwise the delta is called out.
- Spare margin: order **qty 5 of each board's parts** (matches JLCPCB
  PCB minimum order) for hand-solder rework. Some passives (the common
  values) can be shared across boards and ordered in bulk.

## ⚠ SKU verification status

**All distributor SKU cells in this BOM were batch-resolved against the
parts API on 2026-07-14** (SOP G3 sweep; independently re-run by the
reviewer at iter 23) — every cell resolves uniquely to its row's MPN.
That sweep replaced the earlier posture where only the D19/D25
power-chain actives had been checked (2026-06-17) and the rest were
written from working knowledge — which produced 14 fabricated or
wrong-part cells (see per-row correction notes). Historical stale-SKU
flags from the earlier review:

| Part | CP1 SKU (this doc) | Spotted alternate (verify) |
|---|---|---|
| ~~DS3231SN# RTC~~ → RV-3028-C7 | (DS3231 dropped, D23) | RV-3028-C7 — in stock, verified 2026-06-18 |
| ~~SN65HVD3082EDR transceiver~~ (superseded D34, iter-8 F05) | ~~`296-21908-1-ND`~~ | ~~`296-31719-1-ND`~~ |
| ~~ISL3175EIBZ~~ (iter-8 first cut; superseded iter-10 F08 max-to-max) | ~~`ISL3175EIBZ-ND`~~ | ~~`968-ISL3175EIBZ`~~ |
| **THVD1400DR** transceiver (D34, current) | `296-THVD1400DRTR-ND` (32635) | `595-THVD1400DR` (2381) |

**Standing rule (SOP G3, revised 2026-07-14):** batch-`POST /resolve`
every SKU cell after any SKU edit and again at BOM-lock — a SKU cell is
a claim, never a recollection. At **CP5 procurement**, re-run the sweep
and re-check stock/lifecycle before clicking ORDER (stock moves: J2
B8B-PH-K-S collapsed 2900 → 16 in three weeks). The earlier posture
("CP1 doesn't gate on SKU correctness; verification is CP5's job") is
retired — it's how wrong-part cells survived 20 review iterations.

## Order strategy

Four sources (corrected 2026-07-14, iter-23 F23 — the prior "DigiKey
carries the Waveshare, one shipment" plan was wrong; neither DigiKey nor
Mouser lists the module):

1. **DigiKey** — primary cart for most active parts (all SKUs in this
   BOM resolved via the parts API, 2026-07-14).
2. **Mouser** — the Mouser-only lines: M3×5 standoffs (710-970050354);
   also stocks most other lines as second source.
3. **Waveshare direct (waveshare.com) or Amazon** — LCD1 e-paper
   Module (B); not stocked at DK/Mouser (API keyword sweep 2026-07-14).
4. **3D-printed bracket + faceplate** — user prints on their own
   printer; STL/STEP files come out of CP5.

JLCPCB order separately (the PCBs themselves; qty 5 each board, bare
PCB no PCBA). DHL shipping; ~$25–35 total for both boards' PCBs.

Component spend recomputed 2026-07-14 from the line items below (prior
"~$110 components / ~$145 grand" predated the U2 price correction
$8 → CA$27.95, the BTN1 dry-circuit upgrade $3 → CA$18.47, and the
TVS -13-F price updates; display enclosure/mounting corrected to $10
per iter-25 F25): battery-side **~$83**, display-side **~$69**,
cable/shared **~$10** → components **~$162**. PCBs add ~$30;
bracket/faceplate are filament cost (~$2). Grand total **~$192** for
one complete monitor.

---

## Battery-side board

### Power input

| Ref | Part | Pkg | Qty | DigiKey SKU | Mouser SKU | Price | Notes (Δ from prior BOM) |
|-----|---|-----|-----|---|---|---|---|
| J1  | Phoenix **MSTBA 2,5/2-G-5,08** header (1757242, right-angle, 2-pos) + **MSTB 2,5/2-ST-5,08** plug (1757019, 2-pos screw-clamp) | THT 5.08 mm | 1 | 277-1106-ND (hdr) + 277-1011-ND (plug) | 651-1757242 + 651-1757019 | $3.50 | **NEW** pluggable input — user lands pack wires on the plug, plugs into the board (disconnect w/o unscrewing, D19). **PLUG CORRECTED 2026-07-01 (user caught via datasheet, D32): was 1727010 = MKDS 1/2-3,81 — a 3.81 mm board-mount screw terminal, wrong series/pitch, doesn't mate the header. 1757019 = the real MSTB 2,5/2-ST-5,08 2-pos plug (parametrics-verified: 2 pos, 5.08 mm, screw rising-cage; stock ~15k).** |
| F1  | 5×20 mm fuse clip, Keystone **3517** (×2, w/ end stops, UL E354010) | THT clip | 2 | **36-3517-ND** | 534-3517 | $0.48 ea | **NEW** — replaces ATO fuse holder. Holds the 1 A cartridge. **SKUs corrected 2026-07-14 (user-caught): prior F1465-ND / 530-31MJ005H were phantoms — zero hits at DK/Mouser/Octopart** (API /query + /resolve, 2026-07-14: DK 85.7k / Mouser 54.3k, Active). Datasheet Keystone_3517.pdf (5 mm/3AG clip table) |
| F1_ELEM | **Littelfuse 0215001.MXP** — 1 A 5×20 mm **time-lag (T)** ceramic cartridge fuse | TH 5×20 mm | 1 | F1696-ND | 576-0215001.MXP | $0.95 | **NEW** — fuse element. **Time-lag (DR-12)**: rides the ~22 µF ceramic inrush; ceramic = safer in a high-energy DC fault than glass. **API-verified 2026-06-25** (DK ~3.8k stock) |
| D1  | SS26 Schottky 60 V/2 A (SS26-E3/52T) | **DO-214AA (SMB)** | 1 | SS26-E3/52TGITR-ND | — | $0.30 | **Δ (D19/DR-3): SS24 (40 V) → SS26 (60 V)** to out-rate the ~53 V clamp. **Package corrected SMA → SMB (API 2026-06-25)** — SS26-E3/52T is DO-214AA; SMB is also easier to hand-solder |
| TVS1 | **SMAJ33CA-13-F** bidirectional TVS (Vrwm 33 V, VC 53.3 V @ 7.5 A per DS19005 p.2 device table; Diodes Inc) | SMA | 1 | SMAJ33CA-FDICT-ND (306k stock, Active; API /batch 2026-07-14) | 621-SMAJ33CA-13-F (48k) | $0.83 | **Iter-23 F20: non-F variant is Obsolete/zero-stock — and my prior "3.4k stock, Active" cell had laundered the Vishay listing's stock onto the Diodes SKU.** DS19005 p.1 ordering row names SMAJxxx(C)A-13-F. **Δ (D19/DR-2): SMAJ30CA → SMAJ33CA** — 33 V clears the ~29 V full-charge bus with margin |
| TVS3 | **SMAJ15A-13-F** unidirectional TVS, V12_CAT5E↔GND (VC 24.4 V @ 16.4 A per DS19005 p.2) | SMA | 1 | SMAJ15A-FDICT-ND (63k stock, Active; API /batch 2026-07-14) | 621-SMAJ15A-13-F (26k) | $0.75 | **NEW (DR-15):** clamps cable surges on the 12 V Cat5e pair at the **battery** end (matches the display-end SMAJ15A → both ends protected). Zero static draw |

### Power conversion

| Ref | Part | Pkg | Qty | DigiKey SKU | Mouser SKU | Price | Notes |
|-----|---|-----|-----|---|---|---|---|
| U1  | **LM5166YDRCR** (24 V→3.3 V, **always-on** µA-Iq buck, **500 mA**, **fixed 3.3 V**) | VSON-10 | 1 | LM5166**Y**DRCR = fixed 3.3 V (TI Active; YDRCR out-of-stock on TI.com 2026-06-21 — confirm distributor stock at BOM-lock) | 595-LM5166YDRCR | $4 | **Δ (D25): LM5165→LM5166**, fixed-3.3 V = **`LM5166YDRCR`** (reviewer Finding 01: `X`=5 V, `Y`=3.3 V — order **Y**). FB→VOUT, no divider. **CP2 (DR-29):** RT→GND = **PFM**; EN→VIN direct; HYS/SS/PGOOD open. Fallback: YDRCT cut-tape, else adjustable + divider; **never XDRCR** (5 V) |
| L1  | **4.7 µH**, Isat ≥ 2.2 A, low DCR shielded SMD | 1210 | 1 | _verify_ | _verify_ | $0.50 | **Δ: LM5166 inductor** — 4.7 µH for **PFM** (CP2/DR-29; TI Design 3, 24 V→3.3 V). Was "10–47 µH" assuming COT |
| C1, C2 | C1 22 µF / **100 V**, C2 **47 µF** / 25 V X7R | 1210 | 2 | _verify_ | _verify_ | $0.50 ea | **Δ: C1 →100 V** (LM5166 input, behind the ~53 V clamp); **C2 →47 µF** (CP2/DR-29: Eq-31 margin at peak-current overshoot; Design 3 value) |
| R_ILIM | **56.2 kΩ 1 %**, ILIM → GND | 0805 | 1 | _verify_ | _verify_ | $0.02 | **NEW (CP2/DR-29):** PFM current-limit select 750 mA peak / 300 mA IOUT (LM5166 Table 3) |
| U2  | Recom R-78HB12-0.5 buck (24 V→12 V, 0.5 A, 17–72 V in) | SIP3 THT | 1 | 945-1057-ND (383 stock, Active) | 919-R-78HB12-0.5 (1.9k) | **$27.95** (CAD; BOM had $8.00 — price corrected 2026-07-14) | **Δ (D19/DR-3): R-78E12 (34 V) → R-78HB12 (72 V)** to survive the clamp. Switched behind SSR1 + R_inrush |
| C3, C4 | C3 **3.3 µF** / **100 V** (R-78HB12 p.4; was 22 µF, ~7× oversized — F90), C4 22 µF / 25 V X7R | 1210 | 2 | _verify_ | _verify_ | $0.55 ea | **Δ: C3 22 µF→3.3 µF/100 V (F90)** — the R-78HB12 p.4 external-input value for Vin>50 V; shrinks the F2 turn-on I²t to 2.9 %. **Constrain the CP5 pick to ≤5 µF max-effective** (tol+temp+aging; DC bias reduces it) to keep ≤4.3 %. |

### Hard-cut load switch

| Ref | Part | Pkg | Qty | DigiKey SKU | Mouser SKU | Price | Notes |
|-----|---|-----|-----|---|---|---|---|
| SSR1 | **Panasonic AQY212EH** PhotoMOS SSR (1-Form-A, 60 V / 550 mA, **Ron 0.85 Ω typ / 2.5 Ω max**) — display-feed load switch **replacing the whole P-FET + gate-driver network** | DIP-4 (THT) | 1 | **255-2963-ND** (2471 stock, Active, API 2026-07-17) | 769-AQY212EH (4195) | $2.81 | **Δ iter-48 (F76 resolution, user-approved):** the discrete P-FET gate driver could not be *datasheet-guaranteed* OFF at temperature (5 iters, F60→F76). A PhotoMOS SSR is LED-controlled and opto-isolated: **OFF = open MOSFET, off-leakage ≤1 µA @25 °C (spec), and cannot self-turn-on** (no gate divider — the failure mode is *architecturally* eliminated). The datasheet publishes **no elevated-temperature leakage maximum** (its EC table is ambient 25 °C); at 85 °C the leakage is an *engineering estimate* of ~tens of µA (leakage ≈ doubles per ~10 °C) — carried explicitly as an estimate, **not** a bound, and gated by a bring-up State-4 leakage acceptance test (<5 mW pass; F83). It is non-amplifying, so it cannot cascade. Rated −40…+85 °C; continuous load derates 0.55 A@25 °C → 0.30 A@85 °C (≫ the ~5 mA display draw). In series V24_FUSED→**F2**→SSR1→**R_inrush**→V24_SW; blocks the 53 V surge open (<60 V), passes it to the 72 V U2 closed. Values corrected iter-50 (F79): the 0.25 Ω/100 °C-leakage figures were the AQY211EH sibling / 25 °C-only. Datasheet on file (Panasonic GE DIP4, sha d329b9729322) |
| R_opto | **330 Ω** 0805 1 % (ESP PWR_EN → SSR1 LED anode; cathode → GND) | 0805 | 1 | RMCF0805FT330RCT-ND | 71-CRCW0805-330-E3 | $0.10 | **NEW (F76); value F79:** SSR LED current limit. Worst-case I_F = (3.3−V_F max 1.5)/(330·1.01) = **5.4 mA ≥ the 5 mA recommended min** (nom 6.2 mA; max 6.6 mA < 30 mA); >the 3 mA operate spec with margin. ~6 mA GPIO load, **active only, 0 in hard-cut**. (390 Ω was only 4.57 mA worst-case — F79.) |
| R_inrush1, R_inrush2 | **2× 75 Ω 1206 pulse-proof (Vishay CRCW-HP, `CRCW120675R0FKEAHP`) in series = 150 Ω**, switched branch V24_FUSED→F2→SSR1→R_inrush→V24_SW/C3 | 1206 | 2 | 541-75.0UTR-ND (150k stock, Active) | 71-CRCW120675R0FKEAH (46k; Mouser drops the trailing P) | $0.06 ea | **NEW (F80); re-coordinated iter-54 (F86/F89).** Two 75 Ω in series (=150 Ω) so each survives a fault: worst case (V=29.2 V, R−1 %, **no fuse/SSR series credit** — reviewer's method) I=196.6 mA, total 5.74 W → **2.87 W each < the CRCW1206-HP §8.1 short-term-overload guarantee 6.25·P70 = 4.69 W/5 s at P70=0.75 W** (a *single* 1206-HP fails: 5.74 W > 4.69 W — F86). Recurring turn-on inrush **0.197 A — below the SSR 0.30 A @85 °C *continuous* (0.66×)**, no one-shot reliance. τ=150 Ω·3.3 µF=0.5 ms; ~2.5 ms to full charge. Per-turn-on I²t=½C·V²/R=**9.5e-6 A²s** = 2.9 % of F2's 80 mA melting I²t at the right-sized C3 = 3.3 µF (≤4.3 % at a 5 µF max-effective ceiling; the old 22 µF gave 19.1 % — F90) — far under Littelfuse's ≤20 %/100 k-pulse selection basis (F87). Datasheet Vishay_CRCW_HP.pdf (bdd4e4b9); §8.1 uses **P70**, not the 105 °C 1.5 W figure. |
| F2 | **80 mA** very-fast-acting SMD fuse (Littelfuse 451 Nano2 SMF), switched branch | **451 SMF, 6.10×2.69 mm** (dedicated land pattern p.4 — NOT 1206) | 1 | F3649TR-ND (1k stock, Active) | 576-0451.080MRL (687) | $4.57 | **NEW (F84); re-picked 62→80 mA iter-54 (F87).** Coordinated fault clear. Normal ~5 mA (≤~15 mA refresh) ≪ 80 mA. Worst-case short 0.197 A = **246 % of 80 mA (214 % at −40 °C** with the ~15 % cold fuse re-rating**)** → above the 200 % guaranteed-open threshold, clears within **200 %→5 s**; the 2× R_inrush (2.87 W each, §8.1) and SSR (<continuous) survive to the clear. **80 mA not 62 mA:** the fuse must survive the turn-on pulse for the product life. At the right-sized C3 = 3.3 µF (F90) the 80 mA fuse's I²t ratio is 2.9 % (≤4.3 % at the 5 µF max-effective ceiling), far under Littelfuse's ≤20 %/100 k-pulse selection basis; the 62 mA fuse and the old 22 µF C3 gave much higher ratios (F87/F90). 125 V/50 A@125 VDC interrupt; melting I²t 3.3e-4 A²s (datasheet p.2 .080 row). Datasheet Littelfuse_451_453.pdf (399d3cc9). |
| R4  | 100 kΩ 0805 1 % (PWR_EN pull-down to GND) | 0805 | 1 | **RMCF0805FT100KCT-ND** | 71-CRCW0805-100K-E3 | $0.10 | Brown-out failsafe-off: holds PWR_EN low (SSR LED off → open) when the ESP GPIO is high-Z/off |
| U4  | **TI TPS3808G01DBVR** voltage supervisor (~2.4 µA, adj SENSE, OD RESET, prog CT delay, +MR) | **SOT-23-6 (leaded ✓)** | 1 | 296-17188-2-ND | 595-TPS3808G01DBVR | $0.90 | **D28/DR-16; repackaged D33/DR-24 (2026-07-01): WSON→SOT-23-6 for solderability at ~zero power cost (Iq 2.4 µA vs the old part's 2.1 µA).** Adjustable **VIT = 0.405 V**; ISENSE ±25 nA max; built-in VHYS 1.5 %. Divider **release-sized** R1≈5.16 MΩ/R2≈100 kΩ + R_hys≈11.5 MΩ → trip ~20.0 V / release ~21.7–21.8 V (RESET active-low → positive feedback; F01 polarity + F04 release value; see R_uv/R_hys rows; final E96 at CP2). Active, DK 149k. Datasheet: hardware/datasheets/TPS3808G01DBVR.pdf |
| R_uv1 (top), R_uv2 (bottom) | UVLO pack divider → U4 SENSE. **VIT = 0.405 V** (TPS3808G01). Plain divider threshold is the *lower bound* on the release (see R_hys for the R_hys-leg + VHYS lift): sizing to ~21.3 V → **R1 ≈ 5.16 MΩ, R2 ≈ 100 kΩ** (E96) → actual release ~21.7–21.8 V, trip ~20.0 V | 0805 ×2 | 2 | _verify_ | _verify_ | $0.10 ea | **D28; re-derived for 0.405 V + polarity fix (D33/F01) + release refinement (F04).** ISENSE ±25 nA max → I_div ≥ 2.5 µA; 0.405 V/100 kΩ = 4.05 µA at threshold ✓ (~4.6 µA at 24 V, lower than the old 2.89 V part). Add small SENSE filter cap; final E96 at CP2 |
| R_hys | UVLO external hysteresis, U4 RESET → SENSE (**~11.5 MΩ**) | 0805 | 1 | _verify_ | _verify_ | $0.05 | **F01 (iter-5) + F04 (iter-6)/D28.** RESET is open-drain **active-low** → R_hys is *positive* feedback: healthy (RESET≈3.3 V) pulls SENSE up → drops the falling trip; asserted (VOL = 0–0.2 V) still sources a small current from SENSE → RESET, so release lands ~0.4–0.5 V *above* the plain divider threshold. ΔV = R1·(V_RESET_H−VIT)/R_hys ≈ **1.5 V** → trip ~20.0 / release ~21.7–21.8 V. Built-in VHYS (~6 mV) too small alone. Final E96 at CP2 |
| C_uvdd | 100 nF X7R — U4 VDD decoupling | 0603 | 1 | generic | generic | $0.05 | **BOM-diff catch 2026-07-23** (was drawn, never itemized) |
| C_sense | 1 nF C0G — U4 SENSE filter (the "small SENSE filter cap" from the R_uv row) | 0603 | 1 | generic | generic | $0.05 | **BOM-diff catch 2026-07-23** |
| C_ct | UVLO CT deglitch cap (~tens of ms) | 0603 | 1 | _verify_ | _verify_ | $0.05 | **NEW (D28):** rejects momentary sags |

### 24 V sense (always-on)

| Ref | Part | Pkg | Qty | DigiKey SKU | Mouser SKU | Price | Notes |
|-----|---|-----|-----|---|---|---|---|
| R5  | 1.2 MΩ 0805 1 % (top of divider) | 0805 | 1 | RMCF0805FT1M20CT-ND | 71-CRCW08051M20FKEA | $0.10 | **Δ (DR-6): 1 MΩ → 1.2 MΩ** — full charge → 2.25 V, inside the ESP ADC linear band; also current-limits a surge to ~41 µA |
| R6  | 100 kΩ 0805 1 % (bottom of divider) | 0805 | 1 | RMCF0805FT100KCT-ND | 71-CRCW0805-100K-E3 | $0.10 | **Δ (DR-6): 110 kΩ → 100 kΩ** (sets the ratio with R5) |
| C5  | 100 nF X7R 50 V (KEMET C0603C104K5RACTU) | 0603 | 1 | 399-C0603C104K5RACTUCT-ND (7.3M stock) | — | $0.05 | ADC filter. **SKUs corrected 2026-07-14 (SKU sweep): prior DK 311-1141-1-ND was an 0805 part on this 0603 row; prior Mouser Murata GRM188R71H104KA93D is Obsolete** |
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

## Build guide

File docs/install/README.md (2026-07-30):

# Cabin install — runbook

> ⚠ **STALE / FROZEN — pre-CP1 (decisions.md D18).** The hardware design was
> re-opened at CP1; no fab'd boards exist yet, and the enclosures, e-paper
> interface, and dev port below are all superseded: enclosures are now custom
> 3D-printed (battery IP5x box, D20; display in a recessed **double-gang** box
> with a 3D-printed faceplate, D27 — **not** Hammond/single-gang), the e-paper
> is an **8-pin Waveshare 4.2" Module (B)** (no loose FFC ribbon, DR-7), and
> the dev port is native **USB-C** (D22/D27). This runbook will be regenerated
> after the design is re-validated and fab'd. Do not follow it as written.

> Pre-install assumption: PCB fab is complete and both boards have been
> bench-tested using `docs/install/bench_test.md` *before* you bring
> them to the cabin. Don't install boards you haven't bench-tested.

## What you need at the cabin

- Both PCBs in their enclosures (battery-side in Hammond 1556B2GY,
  display-side ready for the wall plate)
- 4.2" e-paper panel + FFC ribbon cable
- Single-gang low-voltage mounting bracket + blank wall plate
  (pre-cut for the panel + buttons)
- Cat5e patch cables (1 short, ≤30 cm — one per end)
- Two Cat5e keystone jacks if the in-wall run isn't already terminated
- 16 AWG fused tap cable to the 24 V pack (battery + via 1 A inline fuse
  to the battery-side enclosure)
- Ring terminals sized for the battery pack's terminal studs
- Tools: punch-down tool (110-type), wire strippers, multimeter,
  Phillips driver, drywall saw or hole-saw for the wall-plate cutout
  (if not already cut), label maker (optional)

## Order of operations

The order matters. Do these in sequence, **don't skip steps**, and
verify each before moving on.

### 1. Cat5e cable QA (before connecting anything live)

If the in-wall Cat5e hasn't been terminated yet, terminate now.

1. At the battery-side end of the cable, punch down keystone jack to
   **T568B** wire order:
   ```
   pin 1: white-orange     pin 5: white-blue
   pin 2: orange           pin 6: green
   pin 3: white-green      pin 7: white-brown
   pin 4: blue             pin 8: brown
   ```
2. Same T568B order at the display-side end. **Don't crossover.**
3. With cable now terminated:
   - Use a basic continuity tester or multimeter to verify all 8 pins
     conductive end-to-end.
   - Verify no shorts between adjacent pins.
   - **Bond the shield drain wire to the battery-side keystone's
     shield post only.** Do NOT bond at the display end.

Reference: `docs/hardware/cat5e_pinout.md`.

### 2. Power-only test of the Cat5e run

Before introducing the monitor PCBs, verify the cable can carry 12 V.

1. With the **batteries still disconnected** from the system, set up a
   bench 12 V supply with 400 mA current limit.
2. Connect supply (+) to **pins 1, 2, 3** of the battery-side keystone
   (these are the +12 V pins — three pins paralleled to share current).
   Connect supply (−) to **pins 6, 7, 8**.
3. At the display-side keystone, measure pin 1 → pin 6 with a
   multimeter: should read 12.0 ± 0.1 V at no load.
4. Apply a 200 mA test load (e.g. a 56 Ω 5 W resistor) at the display
   end. Voltage should drop no more than ~30 mV. If it drops more,
   something's wrong — re-check terminations.

### 3. Battery-side enclosure mounting

1. Choose a mounting spot **within 2 m of the batteries** but with
   airflow (don't tape it directly to a battery — it'll see thermal
   cycling).
2. Mount the Hammond enclosure with the cable-gland side facing the
   batteries, RJ45 side facing the wall.
3. Don't tighten the lid yet — you'll be working inside it for the next
   steps.

### 4. Tap the 24 V pack

**Pack must be in a stable state — not actively charging or
discharging at heavy current.** If the generator's running, wait for
it to stop. Open the inverter breaker if you can.

1. Crimp a 16 AWG ring terminal on one end of a length of red wire,
   long enough to reach from the pack's (+) terminal to the
   battery-side enclosure's terminal block J2.
2. Same for the (−) terminal with black wire.
3. **Add a 1 A inline ATO fuse holder** in the red wire, within
   ~15 cm of the (+) ring terminal.
4. Connect **black first** to the pack's (−) terminal. Tighten to spec.
5. Strip the other ends and wire to J2:
   - Red (with fuse) → J2 pin 1 (V24_RAW)
   - Black → J2 pin 2 (GND)
6. Insert the 1 A fuse last (or have it already in the holder when
   you do step 4). Tightening the (+) ring terminal is the energization
   moment.

**Verify before continuing**: with a multimeter across J2,
read 24–28 V (depending on pack state). If it reads 0 V or negative,
**stop** — the polarity is reversed. The reverse-protect Schottky
saved you this time; un-reverse before powering on the rest.

### 5. First power-up — battery side

1. Close the battery-side enclosure lid (not screwed tight yet, just
   sit it on top).
2. Plug a short Cat5e patch cable from the battery-side board's J1
   into the wall-side keystone.
3. **Look at the battery-side enclosure's debug LED** (visible through
   a translucent lid, or temporarily look inside before closing):
   - Slow heartbeat blink (~1 Hz) = normal, BLE searching.
   - Fast blink = LOW state. Pack SOC is < 25 %. Bench test pre-deploy
     should rule this out.
   - Off = problem. Check fuse, check 24 V at J2.

Wait ~10 seconds for the BLE central to discover both batteries. The
ESP32-S3's onboard LED should transition to a slower, steadier blink
once BLE handshake completes.

### 6. Display-side install

1. With the battery-side already powered, plug a short Cat5e patch
   cable from the wall keystone into the display-side board's J11.
2. **Watch the e-paper panel** — within ~15 s of power-up, it should
   do a full refresh and draw the initial screen.
3. If the screen stays blank for > 30 s:
   - Check 12 V is reaching the display-side board: multimeter from
     U10 VIN to GND should read 12.0 V.
   - Check 3.3 V output of U10: should be 3.30 ± 0.05 V.
   - Check the FFC ribbon is fully seated on both ends (panel and J3).
4. Mount the display-side board to the single-gang bracket using M3
   standoffs.
5. Sit the e-paper panel against the bracket's panel-cutout.
6. Snap the wall plate over the bracket. The buttons should align with
   the cutouts.

### 7. First-time verification

The first screen the display draws should match what the Mac dashboard
shows. With both running:

1. Open the Volthium phone app on a phone and note the SOC + voltage.
   *(Don't keep the app connected — close it before the next step.)*
2. Compare against the e-paper headline numbers — should match within
   1 %.
3. Compare against `http://localhost:8421/` on the laptop.
4. Press **BTN_REFRESH** on the display panel. Within ~7 s the panel
   should redraw the same data.
5. Press **BTN_RELEASE** for 1 s. The panel should switch to a
   "phone-app mode" screen with a 5-minute countdown. The battery-side
   should disconnect from BLE; you should now be able to open the
   Volthium app and connect.
6. After 5 minutes, the battery-side should auto-reconnect.

### 8. Override button check

This is the deepest fail-safe. Test it once on install.

1. Press and hold the **override button** on the battery-side
   enclosure for 5 seconds.
2. The battery-side should force a reading cycle regardless of any
   shutdown state.

(This is mainly useful after a deep-discharge auto-cut — you press the
button to bring monitoring back manually rather than waiting for the
ULP-detected voltage recovery.)

### 9. Tighten everything

- Tighten the battery-side enclosure lid screws.
- Verify the cable-gland is snug around the Cat5e and 24 V tap cable
  bundle.
- Tighten the display wall plate screws.
- Run the cable-tester end-to-end one final time. (Easy when both ends
  are accessible. Hard to do later if a wall plate has to come off.)

## Trouble?

See `docs/install/troubleshooting.md`.

## Done

The system should be self-sufficient at this point. The Mac monitor at
`data/pack.csv` keeps logging if it's running; the wall display works
without the Mac.

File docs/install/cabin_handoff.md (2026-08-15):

# The Barge Inn battery monitor — short guide for cabin users

This page tells you how to read the monitor on your phone or laptop
and what to do about what it shows. No tech background needed.

*Updated 2026-08-15: the monitor moved off the cabin laptop and onto a
dedicated computer publishing to the web. You now open one address from
anywhere — see "Opening the dashboard" below.*

## What it is

A live status board for the cabin's two big lithium batteries (the pair
under the floor). It shows you, in real time:

- **how full the batteries are** (SOC, "state of charge")
- **how long until they're full or empty** if today's pattern keeps going
- **whether the generator needs to run**, and if so, when and for how long

It runs on a small computer (a Raspberry Pi) wired to the batteries and
the solar gear, and publishes to the internet — so you can check it from
anywhere, not just at the cabin.

## Opening the dashboard

1. Open Safari / Chrome on your phone — **any internet connection works,
   you do not need to be at the cabin**.
2. Go to **<https://volts.alti2.de/>**.
3. Bookmark it or add it to your home screen.

The history page is at **<https://volts.alti2.de/history>**.

*(Before 2026-07-26 this ran on a laptop at the cabin on
`http://192.168.1.76:8421/`. That laptop is gone; the address will not
answer.)*

## What you're looking at

The headline section, top of the page:

```
   ┌─────────────────────────────────┐
   │  [IDLE]  ← state (color chip)   │
   │                                  │
   │   72%          5h 20m            │  ← two big numbers
   │   state of   time to (95% / 10%) │
   │   charge                          │
   │   ▼ losing -2.2 A                │  ← trend ↓ losing, ↑ gaining, → steady
   │                                   │
   │   [████████░░░░░]                │  ← SOC bar
   │                                   │
   │   pack V  pack I  pack P         │  ← detail row
   └─────────────────────────────────┘
```

**The two things to actually look at** are the **big number on the left
(SOC)** and the **big number on the right (time remaining)**.

The trend line under SOC tells you which way the pack is heading
*right now*:

- **▲ gaining** (green) — charging from sun or generator
- **▼ losing** (yellow) — using more than the sun is making
- **→ steady** (dim) — roughly balanced

## What each state means

| Chip | What it means |
|---|---|
| **CHARGING** (green) | Net positive: sun or generator is filling the pack |
| **DISCHARGING** (amber) | Net negative: cabin loads are pulling power |
| **FULL** (bright green) | Pack at 95 %+ — generator not needed |
| **IDLE** (dim) | Less than 0.5 A flowing in either direction |

The "time remaining" updates a lot — that's normal. It's predicting
*at the current rate* how long until you hit a target (full or 10 %).
A fridge cycle starting up will temporarily lower it; the cycle ending
will raise it. Look at the trend over minutes, not seconds.

## The recommendation panel (below the live data)

Lower on the page you'll see a panel that says one of:

- **"no generator needed"** (green border) — projected to stay above
  25 % through tomorrow night. Relax.
- **"MORNING WATCH"** (amber border) — projected to dip below 50 %
  near tomorrow's sunrise. Not critical, but consider running the
  generator soon if today's forecast is gloomy.
- **"RUN GENERATOR · 1.4 h"** (amber/red border) — projected to drop
  below 25 %. The headline tells you how long to run the generator and
  when to start (usually a couple hours before sunrise).

A small chip says `low confidence` / `medium confidence` / `high
confidence`. While it says **low**, the projection is rough — the
system only has a couple days of data. Treat it as a hint, not gospel,
and be a bit conservative.

## When something looks wrong

| What you see | What to do |
|---|---|
| All numbers say "—" | The monitor at the cabin has stopped or lost its internet. Nothing you can do from the page itself — tell Kaan. |
| Time-remaining shows a giant number like "12000 min" | Current is near zero (very light load). Ignore; normal. |
| State is **DISCHARGING** all day | Sun isn't reaching the panels. Check for snow / debris. |
| Recommendation says **RUN GENERATOR** | Run the generator. The duration shown is the bare minimum. |

## What NOT to worry about

- **Brief BLE flap warnings in `data/pack.log`** — the system catches
  them automatically. They happen ~1×/hour as a normal thing.
- **SOC bouncing 1–2 %** — the BMS rounds to whole percent and a
  fridge cycle can briefly move it.
- **Battery A reading higher SOC than Battery B** — the two cells
  drift by a couple of percent. The lower one is what matters for
  the "empty" calculation.

## When NOT to trust it

While the **confidence chip says "low"** (the first 1–2 weeks):
- Tomorrow's forecast solar harvest is an educated guess.
- The dischargemodel doesn't yet have a week of patterns.
- Use the trend arrow + SOC % as your primary signals.

Each full day of data the system runs, the projection gets sharper.

## Bigger picture

This monitor is a stepping stone. A small wall-mounted version with
its own display is in progress — see `docs/production_design.md` and
`docs/hardware/` if you're curious. For now the laptop is doing the
job.

## Who to ask

Kaan made this. Issues and questions:
https://github.com/kaanow/volthium_reader/issues

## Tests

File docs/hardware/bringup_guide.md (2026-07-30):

# Battery-side board — bring-up guide

> **Status: living draft (CP2, 2026-07-23).** Written at schematic stage on
> purpose: every step here is also an audit of the design ("can this step be
> performed with the connections we drew?") — DR-32 (the J5 EN/IO0 header)
> exists because drafting this thinking found a gap. Items marked **[CP3/CP5]**
> get pinned once layout fixes physical access. Companion documents:
> `hardware/layout/requirements.md` (R-numbers), `DESIGN_REVIEW_ITEMS.md`
> (DR-numbers), `cp1_rs485_battery_read.md` §7 (the iso acceptance matrix).

**Golden rule: one energy source, one new subsystem at a time.** The board is
designed so every riskier block is behind a default-OFF gate — use that.

## Stage 0 — bench prep (no board power)

- Visual + continuity: pack input polarity J1, no V24_RAW↔GND short,
  V3V3↔GND resistance sane (≥ ~5 kΩ; R13 1 M + dividers dominate).
- **Do not** insert F1's cartridge yet. Packs stay disconnected.
- Tools: bench PSU (current-limited), USB-C cable, ESP-Prog or USB-UART,
  multimeter. The Volthium packs come LAST.

## Stage 1 — USB-only smoke + first flash (R6/R7)

1. Plug USB-C only. Expected: U5 3.3 V out → U6 selects VIN1 → **V3V3 ≈ 3.3 V**;
   Q4 sees VBUS → Q3 opens → R7 pulls EN high → MCU boots.
   Measure: VBUS 5 V, V3V3, EN ≈ 3.3 V. Idle current [CP5: record baseline].
2. Blank module ⇒ ROM download mode by itself. `esptool.py chip_id` over the
   **native USB** port proves the R7 path end-to-end.
3. First firmware flash over USB. Confirm console output on J5.3 (UART0).
4. **Recovery drill (do this NOW, not when you need it):** jumper J5.6
   (BOOT/IO0) → J5.4 (GND), blip J5.1 (EN) low, confirm the ROM downloader
   appears on the J5.3/J5.5 UART. This is the deep-sleep-proof path (R8) —
   verify it once while nothing is at stake. (J5 is the keyed 2×3 ESP-Prog
   Program pinout — an ESP-Prog ribbon mates directly and its auto-program
   circuit drives EN/IO0 for you; the jumper drill is the no-ESP-Prog path.)

## Stage 2 — pack power path (R14/R5), packs still absent

1. Bench PSU at 24.0 V, current limit ~100 mA, onto J1 (F1 cartridge IN now).
   Expected: V24_FUSED ≈ 24 V, LM5166 runs, **V3V3_BUCK ≈ 3.3 V**; with USB
   also present U6 must prefer VIN1 (USB) — pull USB and V3V3 must stay up
   from the buck (mux switchover).
2. UVLO thresholds (R5): sweep the PSU 22 → 19.5 V watching UVLO_RESET:
   assert LOW at ≈ 20.0 V falling; sweep up: release at ≈ 21.7–21.8 V.
   [CP5: record actuals against D28/F04 numbers.]
3. Sleep-floor current at 24 V with everything gated off
   [CP5: target per power_budget.md; State-4 floor ≈ 1 mW class].

## Stage 3 — gated subsystems, one CHx_PWR at a time (R4)

For each of CH1_PWR, CH2_PWR, CAN_PWR, EXP_PWR_EN — in that order:
- OFF state first: gated rail ≈ 0 V (EXP rail parked ≤ 50 mV per F66),
  incremental current ≈ 0.
- Drive the GPIO low → rail ≈ 3.3 V; incremental current sane
  (ADM2587E ch: ~90 mA class when talking; TCAN332 ~3.5 mA listening).
- Release → rail collapses (bleed/load), draw returns to floor.

## Stage 4 — isolated RS-485 read (R1/R2, DR-26 §7)

**This is the DR-26 acceptance gate — packs appear here for the first time.**
1. One pack, one channel: vendor cable pack → J10. With CH1_PWR on, confirm
   isoPower: V_ISOOUT1/V_ISOIN1 ≈ 3.3 V measured **against ISO_BUS_GND1**
   (floating — use a battery DMM, not a grounded scope).
2. Poll the BMS (9600 8N1 per vendor protocol) — first real data.
   **A/B caution (field 2026-07-25):** both packs idle with pin 8 ~0.4 V
   *above* pin 7 — under TI naming that suggests 8=A, opposite the vendor's
   7=A/8=B. If the first poll gets no reply, mirror A/B before debugging
   anything else.
3. Both packs, both channels: run the §7 **two-domain matrix** (float vs
   REF-pad reference). R27/R37 stay DNP unless the float fails (user call:
   populate only on evidence).
4. Confirm the ±12 V common-mode reality: measure PACK1_Bminus vs
   PACK2_Bminus at the REF pads (expect ≈ 12 V — this is WHY R1 exists).

## Stage 5 — Xanbus CAN listen (R10, DR-31)

1. **Before first attach: ✅ DONE 2026-07-25 (owner field measurement,
   live port, ref pin 8):** 1/2/7 = 12 V (NET_S — one measurement; NET_S
   has NO published max, Xantrex examples run 15 VDC > U7's +14 V abs-max,
   so a NET_S-to-CAN miswire stays treated as fatal to U7 — F11), 3/6 =
   0 V (NET_C), **4 = 2.2 V (CAN_L), 5 = 2.4 V (CAN_H)** — recessive band,
   H > L under traffic averaging, matching the drawn polarity and the
   first-party Xantrex table (975-0136-01-01 Table 3, on file in
   docs/vendor/). **Repeat this measurement whenever the port or cabling
   changes** — it is the standing miswire control, not a one-time formality.
2. CAN_PWR on, TWAI in **listen-only** (no ACK — stays a pure observer),
   250 kbps. Expect Xanbus frames. J7 shunt only if the reader is a chain end.
3. Gate off → confirm the bus is unloaded (TCAN332 high-Z unpowered).

## Stage 6 — display link + system soak (R17/R18)

1. **Before attaching the Cat5e at the display end (F14):** verify the
   cable is a T568B straight-through and beep the J1 pin map at the
   display plug — 12 V on 1/2/3, A on 4, B on 5, GND on 6/7/8 (R17).
   A crossover/rolled cable shorts 12 V to GND (resettable: F1 PTC +
   battery-side foldback) but must not be left in place.
2. **Display termination: J5 shunt FITTED** — the display end is the bus
   terminus, so R2's 120 Ω must be in circuit by default (R18). Battery
   end: J4 per final topology (its terminator lifts only if the battery
   node is mid-bus). Exactly the two physical bus ends carry termination.
   R3/R4 idle bias stay **DNP** unless CP5 link testing shows RO
   glitches (F12).
3. J2/Cat5e link up: 12 V feed present (SSR1 path, PWR_EN), RS-485
   comms up; confirm display ACK-on-BREAK wake (D34 §turnaround).
4. Full-system soak: duty-cycled polling, deep-sleep floor re-measured,
   [CP5: 24 h log against power_budget.md].

## Appendix — recovery cheat-sheet

| Symptom | Path |
|---|---|
| USB dead / firmware sleeps instantly | ESP-Prog ribbon on J5 (auto-program), or jumper J5.6→J5.4 (GND) + blip J5.1 |
| No V3V3 on USB | check U5 out, then U6 VIN1/PR1/MODE bus, then Q3/Q4 (EN held low?) |
| No V3V3 on pack | F1 cartridge, D1 orientation, V24_FUSED, UVLO_RESET state (pack < 21.7 V won't release!) |
| Iso channel silent | CHx_PWR low? V_ISOINx vs ISO_BUS_GNDx? A/B swapped? (vendor: A=7, B=8) |
| No CAN frames | polarity (L=4/H=5), listen-only mode?, 250 kbps?, gate on? |

### Display-board recovery (R21 — F14)

The display Deep-sleeps between frames, so a sleeping/bricked unit is
often uncatchable over USB — same argument as battery J5. Pop the
faceplate (no wall removal) for both ports:

| Symptom | Path |
|---|---|
| Display USB dead / firmware sleeps instantly | ESP-Prog ribbon on **J3** (keyed 2×3, same map as battery J5: 1=EN, 2=VDD, 3=TXD, 4=GND, 5=RXD, 6=IO0). Auto-program via esptool, or manual force-download: **jumper J3.6→J3.4 (IO0 to GND), blip J3.1 (EN)**, then flash; confirm on the J3 console (115200) |
| Display alive but no 12 V (bench work) | **J-USB (USB-C)** powers the board alone: AP2112 → TPS2116 VIN1 priority → V3V3 (R20). Flash/console over native USB |
| No V3V3 on display | USB path: U3-LDO out → U4-MUX VIN1/PR1/MODE, C_mux; 12 V path: J1 pins 1-3 → F1 (PTC tripped? clears on power-off) → TVS1/V12_PROT → U1 |
| Display never wakes on bus traffic | J5 shunt fitted? (terminus, R18) · master BREAK ≥50 ms? · /RE latched LOW via `gpio_hold_en(GPIO15)`? · RO reaching IO18 (ext1 mask)? |

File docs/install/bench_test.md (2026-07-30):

# Pre-install bench test

> ⚠ **STALE / FROZEN — pre-CP1 (decisions.md D18).** The design was re-opened
> at CP1; no fab'd boards exist, and the parts/nets referenced here are
> superseded (e.g. the 3.3 V buck is now an always-on **LM5166**, not the
> switched TPS62933 — D19). This procedure will be regenerated once the
> design is re-validated and fab'd. Do not follow it as written.

Run this with both PCBs in hand, **before** you take them to the
cabin. Catches assembly defects without involving the cabin's batteries.

## Bench setup

- Variable bench supply (24 V, 0–500 mA limit)
- Multimeter
- Oscilloscope (nice to have, not required)
- Two Volthium batteries OR an open-source BMS sim (out of scope here)
- USB-C cable + a Mac/Linux machine with `esptool` for flashing
- A laptop on the same Cat5e/RS-485 bus (use the dev rig's USB-RS485
  dongle if you don't have boards yet)

## Battery-side board

### Smoke test (no firmware)

1. Apply **24 V at 100 mA limit** to J2 (red to +24, black to GND).
2. Verify the current draw is ≤ 50 mA (mostly the TPS62933 inrush
   spike, then steady-state ~20 mA without firmware).
3. Multimeter across V3V3 net (test point or U1 output): **3.30 ± 0.05 V**.
4. Multimeter across V12_CAT5E (J1 pin 1 → pin 6): **12.0 ± 0.2 V**.
5. With power off, multimeter continuity from V24_RAW through F1 to
   D1 anode to D1 cathode to U1/U2 VIN: should all be conductive.
6. Reverse-polarity test: briefly reverse the supply polarity (still
   limited to 100 mA). The Schottky D1 should block — verify no
   current flows past it. **Don't hold this state more than ~1 s.**

### Firmware flash

1. Hold BOOT, tap RESET, release BOOT (puts ESP32-S3 in download mode).
2. `idf.py -p /dev/cu.usbserial-... flash` from `firmware/bms-link/`.
3. After flash, RESET. The console (`idf.py monitor`) should show:
   ```
   I (123) volthium: starting battery-side firmware vX.Y.Z
   I (135) volthium: 24 V sense: 25.xx V
   I (210) volthium: BLE central up; scanning for V-12V???Ah-*
   ```

### BLE scan check

The board should discover both Volthium batteries by their advertised
names (`V-12V200AH-0533` and `V-12V200AH-0667`). If only one shows up:
re-verify the antenna keepout area — the ESP32-S3 has reduced range if
there's copper too close to its antenna.

### MOSFET hard-cut check

1. Force `PWR_EN_N` high (in firmware, or yank GPIO4 to V3V3 manually).
2. Verify V24_SW (downstream of Q1) drops to 0 V.
3. Restore PWR_EN_N low.
4. V24_SW returns to ~V24_RAW.

This test confirms the hard-cut path before you rely on it in the
field.

## Display-side board

### Smoke test (no firmware)

1. Apply **12 V at 100 mA limit** to J11 pin 1 (+) and pin 6 (−).
   (Use a Cat5e jumper for convenience.)
2. Current draw should be ≤ 30 mA without firmware.
3. Multimeter on the 3.3 V rail: **3.30 ± 0.05 V**.

### Firmware flash

Same procedure as battery-side, but `firmware/display/`.

### E-paper init

After flash + reset, the panel should do a full refresh within ~10 s
of power-up. The initial screen is "WAITING FOR DATA" since the
battery-side isn't connected yet.

### Button check

The firmware has a debug mode (long-press BTN_REFRESH + BTN_NEXT) that
shows raw button events on the e-paper. Use it to verify all three
buttons register cleanly.

## End-to-end on the bench

1. Power both boards.
2. Connect them with a 1 m Cat5e patch cable.
3. Display should transition from "WAITING FOR DATA" to live readings
   within ~30 s.
4. If the boards are within BLE range of actual batteries, the
   readings should match the Volthium app.

## Acceptance criteria

A board passes bench test if and only if:

- [ ] Current draw on 24 V (battery-side) is < 80 mA in NORMAL state
- [ ] 3.3 V rail is within 3.25–3.35 V at both ends
- [ ] 12 V at the display end is > 11.7 V at full load
- [ ] BLE successfully connects to both batteries
- [ ] MOSFET hard-cut works
- [ ] E-paper does a clean full refresh
- [ ] All three buttons register
- [ ] End-to-end: display shows live data, matches Volthium app

Boards that fail any of these stay on the bench.

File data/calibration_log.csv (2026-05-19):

ts | coefficient | n_observations | confidence | source | notes
2026-05-18T13:13:50 | 7.0000 | 0 | low | loop-iteration | no usable observations yet; using default
2026-05-18T20:23:30 | 8.1495 | 1 | low | advisor-invocation | fit from 1 observations; median ratio 8.15

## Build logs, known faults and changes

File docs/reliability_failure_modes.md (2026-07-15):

# Reliability & Failure Modes — field log

Running log of failure modes seen in the live Volthium pipeline (BLE logger →
`data/pack.csv` → cloud uploader → Railway dashboard), written so the data we
already gather can drive a **more robust, self-improving system over time**.

Each entry is structured for that goal:

- **Signature** — how the failure shows up in data/logs we already collect, so
  it can be detected automatically.
- **Root cause** — what's actually happening.
- **Current mitigation** — what's in place today.
- **Instrumentation to add** — what we should start logging so this becomes
  *detectable and diagnosable from the data* next time.
- **Robustness ideas** — toward auto-recovery / graceful degradation.

First populated 2026-06-29/30 during the Linux/Pi (`kwpi`) bring-up.

---

## The data we currently gather (and where the gaps are)

| Source | Contains | Good for | Blind to |
|---|---|---|---|
| `data/pack.csv` (32-col) | per-cycle pack snapshot, ts, V/I/SOC/temp/cells/problem_code | trend/health analysis | **only written on a fully successful read** — failures leave no row, so outages are invisible *in the CSV itself* |
| `data/pack.log` / `journalctl -u volthium-logger` | human log incl. read failures + retry counts | spotting read failures | unstructured; no RSSI; no per-battery success/fail breakdown |
| `data/uploader.log` / `journalctl -u volthium-uploader` | POST results, accepted/dup counts | upload health | nothing about *why* the CSV stopped growing |
| dashboard "data is N minutes stale" banner | end-to-end staleness | the canary that actually caught the outage | doesn't say which stage failed |

**Key structural gap:** a failed read produces *no record in `pack.csv`*. The only
evidence an outage happened lives in the journal. The single most valuable change
for a self-improving system is a **structured health/event log** (one row per read
attempt, success or fail, per battery, with RSSI) — see "Cross-cutting" below.

---

## FM-1 — Service user can't write `data/` (logger crash on start)

- **Signature:** logger exits immediately; `PermissionError: [Errno 13] Permission
  denied: '.../data/pack.log'`. No CSV rows, no retry.
- **Root cause:** repo owned by `kaan`; `data/` was `0755` (not group-writable) and
  the service runs as `claude`. Opening `pack.log`/`pack.csv` for append failed.
- **Current mitigation:** `data/` made group-writable (`users`); services run as
  `claude` (see memory `run-as-claude-not-kaan`). systemd `User=claude` is fixed.
- **Instrumentation to add:** a pre-flight check in `log.py` that asserts the CSV
  dir is writable and logs a clear actionable error (and exits non-zero so systemd
  surfaces it) instead of a raw traceback.
- **Robustness ideas:** `systemd-tmpfiles` to own/permission `data/` at boot;
  `ReadWritePaths=` in the unit; fail fast with a one-line diagnosis.

## FM-2 — BlueZ allows only one discovery per adapter (concurrent scans)

- **Signature:** every read fails with `org.bluez.Error.InProgress` ("Operation
  already in progress"); deterministic, never succeeds. **Linux/BlueZ only.**
- **Root cause:** `read_pack` ran two `BleakScanner.find_device_by_address` scans
  concurrently via `asyncio.gather`. BlueZ permits one discovery session per
  adapter; the second always errors. CoreBluetooth (macOS, where this code first
  ran) tolerates concurrent discovery, so it was latent until the Pi.
- **Current mitigation:** fixed — `read_pack` now does ONE shared discovery
  (`_discover_addresses`) that resolves both MACs, then reads each device. See the
  fix commit on branch `fix/pi-bluez-and-uploader-rotation`.
- **Instrumentation to add:** count and log `InProgress` distinctly from "not
  found" so the two are separable in metrics.
- **Robustness ideas:** never run concurrent BLE discovery on one adapter; treat
  the adapter as a serialized resource with a single owner.

## FM-3 — Adapter wedged by a lingering GATT connection

- **Signature:** persistent `InProgress` even when only one reader runs; a
  power-cycle of the adapter shows a full GATT service tree being *deleted* for a
  device that should have been disconnected.
- **Root cause:** an interrupted/manual BLE read left a half-open GATT connection
  in BlueZ; the controller wouldn't start new operations cleanly.
- **Current mitigation:** `bluetoothctl power off/on` cleared it. `async with`
  context managers in the read path normally disconnect cleanly.
- **Instrumentation to add:** log `hcitool con` (HCI-level connections) and
  BlueZ connected-device count alongside read failures, so "stuck connection" is
  distinguishable from "device silent" in the data.
- **Robustness ideas:** an **escalating recovery ladder** in the logger after N
  consecutive failures: (1) stop/restart discovery, (2) `bluetoothctl remove`
  the device, (3) adapter power-cycle, (4) restart the BlueZ service. Record which
  rung fixed it — that data tells us which remedy matters.

## FM-4 — Uploader re-ingests header row after CSV rotation (inode reuse)

- **Signature:** failing unit test `test_rotation_resets_offset` (2 rows vs 1);
  in production, a bogus reading with `ts == "ts"` POSTed right after a rotation.
- **Root cause:** when the logger archives + recreates `pack.csv` (schema-drift
  rotation), the OS often **reuses the inode**. The inode-change check missed it,
  so the smaller-file *truncation* branch fired — but that branch preserved the
  stale cached header, which suppressed the offset-0 header-skip, so the new file's
  header line was parsed as a data row.
- **Current mitigation:** fixed — truncation branch now resets `header=None` like
  the rotation branch. Test passes.
- **Instrumentation to add:** uploader should log rotation/truncation events with
  old/new inode+size; reject any wire row whose `ts` doesn't parse as a timestamp
  (defense in depth) and count rejects.
- **Robustness ideas:** detect rotation by `(inode, size, first-line hash)` rather
  than inode alone; server-side schema validation rejects malformed `ts`.

## FM-5 — One battery drops out → the WHOLE pack read fails → logging halts ⚠️

*The most important one for robustness.*

- **Signature:** logger logs `RuntimeError: battery <MAC> not found in scan`
  repeatedly; `pack.csv` mtime stops advancing; uploader has nothing new to send;
  dashboard shows "data is N minutes stale." Observed 2026-06-30: battery B
  (0667) dropped at 23:51, logging halted entirely even though battery A (0533)
  was still readable.
- **Root cause:** `read_pack` is **atomic** — it requires *both* batteries in one
  scan and raises if either is missing, so a single battery's dropout discards the
  good battery's data too and writes **no row at all**. The outage is then
  invisible in `pack.csv` (no row = no evidence), only in the journal.
- **Current mitigation:** logger retries with backoff; `Restart=always`; recovers
  automatically when the missing battery returns. But **zero telemetry** is
  retained during the gap.
- **Instrumentation to add (high value):**
  - Write a `pack.csv` row **even on partial success**, with the present
    battery's data and the absent one's columns null + a `read_status` /
    `batteries_seen` field. Keeps half the telemetry and makes dropouts a
    first-class, queryable data point.
  - Per-battery success/fail + RSSI logged every cycle (structured health log).
- **Robustness ideas:** decouple the two batteries into independent read+state
  loops; treat the pack view as a join over the two latest per-battery readings
  rather than an all-or-nothing read. Alert when either battery is stale > T.

## FM-6 — Battery advertises, then goes silent with no holding connection (RESOLVED → FM-8)

> **Resolved 2026-06-30:** the "no holding connection" observation was a red
> herring — it was made *after* the logger process had been stopped, which kills
> the leaked client and drops the connection. With the logger running
> continuously we caught the live holding connection (`Connected: yes`, LE handle
> 64). Root cause is **FM-8** (leaked in-process `BleakClient`), not a BMS/RF
> fault. The operator's key clue was decisive: B worked for extended periods on
> CoreBluetooth (Mac) and the vendor app, and only hung once the Pi/BlueZ stack
> drove it. Original notes kept below for the record.

- **Signature:** a battery that read fine then **emits no BLE advertisements at
  all** in a 15–20 s scan, while `hcitool con` shows **no** connection holding it
  and BlueZ lists nothing connected. Observed: B (0667), strongest in the room at
  −74 dBm at session start, went fully silent ~1 cycle after its first
  connect-and-disconnect. Simultaneously A (0533) degraded −78 → −89 dBm.
- **Ruled out (by operator):** phone app connected (none), Pi/battery moved
  (didn't). Ruled out by data: lingering LE connection (none at HCI level).
- **Root cause:** **still open.** Candidates to disambiguate with data:
  - BMS-side: BLE module fault, or the BMS stops advertising for a cooldown after
    a central disconnects (would correlate dropout timing with our connects).
  - RF/coexistence: Pi onboard radio shares the 2.4 GHz antenna between Wi-Fi and
    BT; the uploader's continuous Wi-Fi POSTs could degrade BT RX sensitivity
    (A's RSSI decay is consistent, though B going *fully* silent is not purely a
    sensitivity story).
  - Environmental 2.4 GHz interference.
- **Instrumentation to add (to actually solve this):**
  - **RSSI + per-battery last-seen timestamp every cycle** — turns "B is gone"
    into a time series we can correlate against Wi-Fi/upload activity and against
    our own connect events.
  - Log each connect/disconnect with timestamps; if dropouts always follow a
    disconnect by ~constant delay → BMS cooldown. If they track Wi-Fi TX bursts →
    coexistence.
  - Periodically log adapter stats and Wi-Fi TX rate.
- **Robustness ideas (hypothesis-dependent):** if coexistence — pin BT/Wi-Fi
  coexistence params, throttle/space uploads, or move BLE to an external USB
  adapter on its own antenna. If BMS cooldown — lengthen scan windows and reduce
  connect frequency (read less often, or hold a connection). External USB BLE
  dongle is the highest-leverage hardware mitigation for both.

## FM-7 — End-to-end staleness detection (the canary that worked)

- **Signature (working as intended):** dashboard banner "data is ~6 minutes
  stale" — this is what surfaced FM-5/FM-6 to the operator.
- **Keep & extend:** make staleness a **structured, alerting** signal (push/email,
  not just a banner), with per-stage attribution: is the CSV stale (logger/BLE) or
  is the uploader stale (network/cloud)? The data to attribute it already exists
  (CSV mtime vs uploader last-success time vs cloud last-ts).

## FM-8 — Leaked `BleakClient` pins a battery's radio → it stops advertising ⚠️ (root cause of FM-6)

- **Signature:** a battery is **absent from every discovery scan** (so the logger
  reports it DOWN) **while `hcitool con` / `bluetoothctl info` show it still
  `Connected: yes`** with a live LE handle. The *other* battery is unaffected. The
  state persists for the entire life of the logger process and is only cleared by
  a process restart or a DC power-cycle of the battery.
- **Proven mechanism (2026-06-30, live capture):**
  1. A read cycle leaves a `BleakClient` **connected** (an error/timeout path that
     doesn't cleanly disconnect — the disconnect is the slowest part of a read,
     ~1.8 s, and is the precursor that hangs).
  2. The leaked client **pins the connection** and **auto-reconnects** the instant
     it's externally dropped (an outside `bluetoothctl disconnect` came back in
     ~2 s). So a Pi-side disconnect can't shake an in-process leak.
  3. The battery's BMS accepts only **one** central connection, so while pinned it
     **stops advertising** → discovery never finds it → logger reports DOWN forever.
- **Why only one battery / why the Pi:** confirmed by the operator that the same
  cells ran for extended periods on CoreBluetooth (Mac) and the vendor app with no
  hangs — CoreBluetooth tears connections down cleanly; BlueZ leaks them. The
  weaker/slower battery (B sits ~15 dB down: −62 vs A's −45 dBm) hits the bad
  read/disconnect path more often, so it's the one that wedges.
- **Proof the cure is software, not power:** `systemctl stop volthium-logger`
  dropped B's connection immediately and it *stayed* dropped; a restart let B be
  rediscovered and read within <10 s — **no inverter/panel disconnect needed**
  (the operator's previous, impractical remedy).
- **Fix shipped:**
  - **Prevent:** `_read_device` now bounds the GATT read with `asyncio.wait_for`
    so a hung read can't park a live connection, and logs connect/read/disconnect
    timings so a slow teardown is visible before it strands a battery.
  - **Detect + record:** `read_pack` checks any unread target against `hcitool con`
    and, if still connected, emits a `wedge_detected` event with the raw evidence
    to `data/ble_events.jsonl`, then attempts a Pi-side `force_disconnect`.
  - **Recover (agent-free):** the wedged address is surfaced on `PackReading.wedged`;
    after `RESTART_AFTER_WEDGE_CYCLES` (~1 min) of the same battery wedged, the
    logger exits for a clean systemd restart — the proven cure. Genuinely-off
    batteries never show `Connected`, so they can't trip a restart loop.
- **Still worth doing:** root-cause the disconnect leak inside the read path so the
  restart is a backstop, not the primary mechanism; consider holding a single
  persistent connection per battery instead of connect-per-cycle (fewer teardowns
  = fewer chances to leak). An external USB BLE dongle remains the strongest
  hardware mitigation.

## FM-3 addendum — stuck adapter discovery is NOT cured by a process restart

While diagnosing FM-8, rapid manual `bluetoothctl`/`hcitool` use + fast logger
restarts left the adapter in `Discovering: yes` with every read failing
`org.bluez.Error.InProgress`. A **logger process restart does not clear this** —
it lives in `bluetoothd`, so it survived multiple restarts. Cure: an adapter /
`bluetooth.service` reset. The logger now logs a `scan_error` event when discovery
throws so this is self-diagnosing, but the *recovery* (adapter reset, needs
privilege) belongs in the watchdog, not the unprivileged logger.

## FM-6 addendum (2026-07-13) — recurrence, stats, and the operator's cure

B went dormant again 2026-07-13 22:17 PDT (healthy final sample: 81 %,
−3.8 A, 25 °C, 9 mV spread; then zero advertisements on any address — 15 s
open scan confirmed). Reader stack verified healthy throughout (A read every
cycle, `hcitool con` empty, no wedge events). Forensics over the full CSV
record (`scripts/analyze_b_dropouts.py`):

- **640 B-only dropouts since May.** The overwhelming majority are single
  scan-cycle blips (8–10 s) — marginal link budget, not module hangs.
- **The real FM-6 events are minutes-to-hours**: 5.9 h (Jul 10 00:39),
  117 min (Jul 11 04:51), 26 min (Jul 10 15:37), plus tonight's.
- **Load-step correlation is weak** (93/640 within ±1 min of a >60 W step)
  — the "inverter transient knocks the radio over" hypothesis is NOT
  supported at the dropout edge.
- **Operator's proven manual cure** (corrects the earlier "B cannot be
  power-cycled" note): open the inverter breakers for ~30 s so the batteries
  see no charge/discharge path — B's BLE resumes. Not viable remotely or
  long-term, but it means a quiet DC bus resets whatever wedges in the BMS
  radio; dormancies also end on their own after minutes-to-hours.
- **Alerting shipped**: StalenessMonitor now pages when one battery is
  silent >15 min while the pack keeps reporting (dwell filters the RSSI
  blips), and announces recovery with the outage duration — building the
  per-battery outage dataset this mystery needs.

### FM-6 mechanism found (2026-07-14): recovery is quiet-bus-gated ⚡

The 2026-07-13 dormancy ended at 06:43 the next morning — and checking every
long dormancy on record against bus current settled the mystery:

| Dormancy | Recovered | Bus current leading into recovery |
|---|---|---|
| Jul 10, 5.9 h | 06:30 | taper −5.4 → −1.5 → **0 A for ~10 min** → B back |
| Jul 10, 26 min | 16:02 | 4.7 → 2 → **0 A for ~6 min** → B back |
| Jul 11, 117 min | 06:48 | **0 A for ~4 min** → B back |
| Jul 13, 8.4 h | 06:43 | **0 A** in the minutes prior → B back |

**4 / 4: B's BLE only ever resumes after the pack current has been ≈0 A for
a few minutes.** The operator's breaker-flip cure and the "self-recovery"
are the same mechanism — the breaker *forces* an idle window; mornings and
midday lulls produce one naturally. Dropout *onset* is NOT load-correlated
(93/640 within ±1 min of a >60 W step — see `scripts/analyze_b_dropouts.py`);
only *recovery* is gated.

> **Counterexample (2026-07-14 17:17):** battery A's FIRST long dormancy
> (51 min, started 16:26) ended while charging at ~11 A — no quiet bus.
> So the gate is either B-specific, or B's 4/4 was confounded by its
> recoveries landing in naturally-idle hours. Score so far: B 4/4
> quiet-bus, A 0/1. The battery-silent/battery-back alert pair now logs
> every episode — let the tally decide. A's dormancy also weakens the
> "B is a lemon" reading: both BMS units carry the quirk; B is just more
> frequent (weaker link budget may be why).

Candidate mechanisms (both fit; undistinguished so far):
1. **BMS-internal** — under current flow the BMS MCU never reschedules its
   crashed BLE task; the ~0 A idle-state transition reinitializes the radio.
2. **Inverter switching noise** — DC-bus hash under load suppresses the
   radio; at no-load the inverter drops to standby and the bus goes quiet.
   Fits B being the victim: B's link budget runs ~15 dB below A's.

Consequences:
- **Outages are self-resolving and bounded** by the next zero-load window
  (worst case: overnight until the pre-dawn lull). No intervention needed;
  the battery-silent / battery-back pushes book-end each episode.
- **Breaker flip remains the correct emergency lever** (synthetic idle
  window), rarely worth the trip.
- **Discriminating experiment for the next site visit**: physically swap A
  and B. Dormancy follows the battery → B's BMS module (warranty). Follows
  the position → noise/placement (ferrite on the BMS leads or relocate).
  The BMS serials in `name_a`/`name_b` will label the swap in the data
  automatically.

## FM-9 — UB500 firmware hang → kernel USB reset → bluetoothd can't re-init it ⚠️ (the 2026-07-12/13 14.5 h outage)

- **Signature:** logger loops on `BleakError: adapter 'hciN' not found` while
  `hciconfig` shows that adapter UP RUNNING. The tell: the adapter is missing
  from `bluetoothctl list` (bluetoothd's D-Bus view — the one bleak actually
  uses). bluetoothd's journal shows `Failed to set privacy: Rejected (0x0b)`.
  Preceded in dmesg by `command 0x2042 tx timeout` ×5 → `Resetting usb device`
  and an hci index change (hci0 → hci2).
- **Root cause (two layers):**
  1. *Why the chip hung:* USB autosuspend (btusb default, 2 s idle delay) vs
     the 5 s scan cadence = thousands of suspend/resume transitions/day; the
     RTL8761B is a known repeat offender for firmware lockups when a resume
     races an LE scan-enable (opcode 0x2042 — exactly where ours died).
  2. *Why nothing recovered:* after the kernel's USB reset the chip
     re-enumerated in a state bluetoothd could not initialize — visible to the
     kernel, absent from D-Bus. The adapter pin resolved via `hciconfig`
     (kernel view), so the logger kept pinning to a D-Bus-invisible adapter.
     Every ladder rung (HCI reset, bluetoothd restart, process exit — 171
     restarts) operates above the broken layer; only USB re-enumeration fixes
     it. Meanwhile the internal-chip fallback had also wedged (`0x200c`
     EBUSY), and no explicit fallback logic existed to manage it.
- **Fix shipped (2026-07-13):**
  - **Prevent:** udev rule disables USB autosuspend for the UB500
    (`deploy/pi/udev/50-volthium-ub500-usb-power.rules`).
  - **Detect:** adapter resolution (`_AdapterManager`) now verifies the pin
    against BOTH `hciconfig` and `bluetoothctl list`, re-verifies on a 60 s
    TTL (hci indexes change on re-enumeration), and `_classify_wedge` has a
    direct kernel-vs-D-Bus check for `bluez_adapter_object_missing`.
  - **Recover:** new ladder rung L3 = software USB replug (sysfs `authorized`
    0→1 — full re-enumeration + firmware reload; verified live 2026-07-13,
    readings resumed in seconds). Process exit is now L4.
  - **Degrade gracefully:** `VOLTHIUM_FALLBACK_ADAPTER` (internal BCM43438) is
    used automatically while the primary is unusable; the reader replugs the
    primary every ~10 min in the background, switches back when healthy, and
    powers the fallback down to its documented steady state.
- **Still worth doing:** the internal chip's own wedge (`0x200c` EBUSY) is
  only cured here by ladder rungs 1-2; if both radios wedge simultaneously
  again, the monthly reboot or a manual reboot is the backstop. The Pi 4B
  swap remains the real fix.

## FM-11 — Dongle firmware hang leaves RX dead but command path alive → reader scans silence forever

- **Signature:** `pack.log` loops on `neither battery found in scan` with NO
  BLE errors; scans complete normally; `hciconfig` UP RUNNING; bluetoothd
  lists the adapter. `scan_result` events show `seen=false, adv_packets=0`
  for both targets. The tell: a 15 s open scan hears **zero devices of any
  kind** — a live 2.4 GHz environment is never that quiet. dmesg shows the
  FM-9 `0x2042 tx timeout` signature at the original hang, but the chip
  "recovered" enough to answer commands.
- **First seen:** 2026-07-14. Chip hung at 02:33 (kernel messages), limped
  along, then at 11:28 went fully deaf — 52 min of readings outage. Nothing
  escalated: the recovery ladder is driven by `DiscoveryWedgeError`, and a
  deaf receiver never throws. Manual USB replug fixed it in seconds (same
  cure as FM-9).
- **Root cause:** RTL8761B firmware hang variant — RX path dead, HCI command
  path alive, so every health probe passes while the radio hears nothing.
- **Fix shipped (2026-07-14):** `_discover_addresses` counts advertisement
  callbacks from ANY device (`ambient`); `read_pack` treats a zero-ambient
  scan with no targets as `DiscoveryWedgeError` ("receiver deaf"), which
  drives the standard ladder — HCI reset → bluetoothd restart → **USB replug
  (the cure, ~rung 3, ≈3-4 min after onset)** → process restart. New
  classification `adapter_rx_deaf` + server-side alert hint. `scan_result`
  events now carry `ambient_adv` so receiver health is a queryable time
  series.
- **Watch for:** a genuinely RF-silent site would false-positive — harmless
  here (the ladder rungs are no-ops on a healthy stack, and this site always
  has ambient chatter), but revisit if the reader is ever deployed somewhere
  truly quiet.

## FM-10 — Crash-looping logger never seals event segments → outage ships zero diagnostics

- **Signature:** hours-long outage on the dashboard; `/api/events` on Railway
  shows nothing after the outage began; `/run/volthium` (now `data/`) holds a
  growing live `ble_events.jsonl` full of wedge evidence and no `.sealed`
  files; events_uploader idle ("no segments").
- **Root cause:** segment age was measured from `_EventLogWriter._open()`
  (process start). The wedge-restart ladder exits the process every ~5 min,
  so no segment ever reached the 10-min age trigger — each respawn reset the
  clock. 14 h of wedge snapshots sat unshipped while the operator's alert
  said only "stale". (Found while implementing the operator's request that
  alerts carry a diagnosis — the diagnosis pipeline itself was the gap.)
- **Fix shipped (2026-07-13):**
  - Writer inherits the live file's age from its first line's `ts` on open,
    so the 10-min shipping bound holds across restarts (and an already-aged
    file seals immediately on reopen).
  - `seal_event_log()` runs in `log.py`'s exit path (`finally:`) — a logger
    dying for a wedge restart seals its evidence on the way out.
  - Event log moved from tmpfs to `data/` (survives reboots; the SD-card
    write-rate constraint died with the 2026-07-09 card upgrade).
- **Instrumentation to add:** server-side "diagnostics silence" — the
  staleness alert now explicitly says when *no events* arrived either
  (implemented in `StalenessMonitor._diagnose`), which distinguishes
  "Pi offline" from "BLE broken, Pi fine" at a glance.

---

## Cross-cutting: what to build for a self-improving system

1. **Structured health/event log** (JSONL, e.g. `data/health.jsonl`), one record
   per read cycle: `ts, battery_a_seen, battery_b_seen, rssi_a, rssi_b,
   read_status, error_class, recovery_action`. This is the missing dataset that
   makes every failure above *measurable over time* and lets us A/B mitigations.
   `volthium/events.py` (`detect_events`) is a natural home/consumer.
2. **Partial-success logging** (FM-5): never discard a good battery because its
   sibling is absent.
3. **Per-battery RSSI time series** (FM-6): the single most useful new signal for
   the open dropout mystery and for predicting failures before they happen.
4. **Escalating BLE recovery ladder** with recorded outcomes (FM-3): learn which
   remedy actually fixes wedges.
5. **Staleness alerting with per-stage attribution** (FM-7).
6. **Defensive wire validation** (FM-4): reject malformed `ts`/rows server-side.

The throughline: today an outage erases its own evidence (no CSV row). Start
recording *attempts and their outcomes*, not just successes, and the system can
begin diagnosing and improving itself.

---

## Live incident log — 2026-06-30 (battery B / 0667 outage)

Ongoing monitoring run (goal: keep both batteries logging until 08:00, recover
issues, gather data).

- **~00:51 (prev session)** B (0667) stops advertising; logging halts (FM-5).
- **00:00–00:06** A-only; B absent across 10+ scans. Ruled out: phone app,
  movement (operator), lingering connection (`hcitool con` empty).
- **Recovery ladder attempted on B (all Pi-side levers):**
  - Adapter power-cycle (`bluetoothctl power off/on`): **A recovered −89→−79 dBm,
    B still absent.**
  - Full `systemctl restart bluetooth`: **A −80 dBm, B still absent.**
  - → Conclusion: **B's silence is source-side (BMS BLE), not the Pi adapter.**
    A recovers with adapter resets; B does not. No Pi-side action recovers B —
    it needs B's BMS to resume (likely a physical battery power-cycle).
- **RSSI samples (data/ble_health.jsonl):** A ranges −79..−89 dBm depending on
  adapter state; B: no advertisements at all. A's signal is also marginal/weak.
- **Built `scripts/ble_watchdog.py`** — staleness-triggered auto-recovery +
  per-battery RSSI health logging to `data/ble_health.jsonl`, single-adapter-safe
  (only scans while it has stopped the logger), escalating ladder with backoff.
  **Not installed as a service** (safety policy: a new privileged always-on
  daemon needs explicit operator approval). Runs on demand via
  `.venv/bin/python scripts/ble_watchdog.py --once`. Pending operator decision to
  install as `volthium-watchdog.service`.
- **Logger** keeps retrying every ~70 s (`Restart=always`) and will resume both-
  battery logging automatically the instant B re-advertises — this doubles as a
  zero-churn "is B back yet?" probe, so no need to thrash the BT stack overnight.

**Operator note:** battery B (0667) **cannot be physically power-cycled** (per
operator), so it stays down until its BMS BLE resumes on its own. Consider an
external USB BLE dongle: A's RSSI (−79..−89) is marginal and the onboard Pi radio
shares its antenna with Wi-Fi (the uploader's traffic).

### Resolution (00:30): partial logging deployed — FM-5 fixed

Since B can't be recovered and the goal requires data flowing to both the local
and remote dashboards, implemented **partial-success logging**:

- `volthium/pack.py::read_pack` no longer raises when one battery is absent — it
  reads whichever batteries are present and substitutes an all-None placeholder
  (`_missing_reading`) for the missing one. Raises only if BOTH are gone. The
  whole downstream path was already null-tolerant (PackReading properties,
  Estimator, uploader `_maybe_float`, wire `Optional`, cloud NULL/dash), so no
  other code — and crucially **not** the wire contract — had to change.
- `scripts/log.py` logs a `battery presence: A=up B=DOWN` transition line so
  dropouts/returns are visible in the journal.

**Result:** logging resumed at 00:30 with A-only rows (B columns blank,
`pack_i` = A's current since series, `pack_v`/`pack_p` blank). Verified flowing to
`pack.csv` → uploader (200 OK) → cloud `/api/latest` (fresh, B null) → local
dashboard `/api/latest.json` (fresh, B null). 312 main + 14 uploader tests pass.
When B's BMS eventually re-advertises, the logger resumes full both-battery rows
automatically (logs `A=up B=up`) with no intervention.

### Self-heal on wedge (00:39): logger exits → systemd respawns fresh

Added agent-free recovery for the adapter-wedge case (FM-3) that needs no
privilege escalation and no extra service: after `RESTART_AFTER_CONSEC_ERRORS`
(30) consecutive **total** read failures, `log.py` exits non-zero so its
`Restart=always` unit respawns it with a fresh BlueZ client — which clears
`org.bluez.Error.InProgress` wedges that a same-process retry cannot. Because
partial logging means a single-battery dropout no longer raises, this only fires
on a genuine both-batteries-down wedge, exactly where a fresh process helps; a
real RF blackout just restart-loops harmlessly until a battery returns. This is
the privilege-free subset of the `volthium-watchdog` ladder (adapter power-cycle
/ bluetooth restart still need the reviewed service).

### 00:41 — B re-addressing ruled out

Checked whether B's BMS had reset and come back under a *different* BLE address
(some BMS rotate addresses; the logger only looks for the fixed MAC). A 12 s
**name-based** scan for any `V-12V*` advertiser found **only** battery A
(0533, now −51 dBm — its link fully recovered). No second Volthium battery on
any address. So B (0667) is emitting nothing at all — conclusively source-side
(BMS BLE off), not a re-addressing or RF-sensitivity issue. All Pi-side levers
exhausted (adapter power-cycle, bluetooth restart, cache purge, fixed-MAC and
name-based scans). B can only return when its own BMS resumes; the logger probes
for it every cycle and will resume full logging automatically.

---

## Once hardware is upgraded — what to revisit

The Pi 3B (2016) has two properties driving most of the workarounds above:

1. **BCM43438 combo Wi-Fi + Bluetooth chip on one shared 2.4 GHz antenna** — the
   `-84` frame-reassembly errors and coexistence-related GATT stalls come from
   here. External USB BLE dongle (with its own antenna) removes this.
2. **SU16G SanDisk Ultra SD card as sole storage** — the `mmc_rescan` hung tasks
   and `journald` timeouts come from the card periodically going non-responsive
   under sustained write load. USB SSD (or newer Pi that boots from NVMe) removes
   this.

When the platform is swapped, these files/lines are the ones to reconsider — each
is tagged `HARDWARE-DEP: Pi 3B ...` in the source so `grep -rn HARDWARE-DEP` finds
them all.

- **`volthium/pack.py`**
  - `_READ_TIMEOUT` (15 s) + `_DISCONNECT_TIMEOUT` (10 s) — conservative because
    of BlueZ frame drops. Tighten to ~5 s / ~3 s on a clean stack.
  - `keep_alive=True` in `_read_device` — workaround for aiobmsble's unbounded
    `disconnect()` swallowing BleakError. Cleaner stack → let the context manager
    handle teardown normally.
  - `_force_disconnect` + `_teardown`'s verify-and-force loop — exists because
    BlueZ leaks connections. Not needed on a stack that disconnects cleanly.
  - `recover_adapter()` — exists because bluetoothd gets stuck in
    `Discovering: yes`. Not needed on a healthier controller / stack. Delete the
    whole function and its callers.
  - `_EVENT_LOG` tmpfs default — exists because the SD card can't sustain writes.
    On SSD/NVMe, direct-to-disk is fine; the sealed-segment rotation + separate
    uploader machinery becomes optional (still nice for durability but no longer
    survival-critical).

- **`scripts/log.py`**
  - `RESTART_AFTER_CONSEC_ERRORS` (30) — self-heal by respawning. Only necessary
    because the leaked BleakClient needs a fresh process. Remove on clean stack.
  - `RESTART_AFTER_WEDGE_CYCLES` (6) — same story, wedge-specific. Remove.
  - `ADAPTER_SOFT_RESET_AFTER` / `HARD_RESET_AFTER` / `RESTART_AFTER_SCAN_WEDGE`
    — bluetoothd-recovery ladder. Remove.
  - The `battery presence: A=up B=DOWN` transition warning stays useful for
    genuine BMS outages; keep it.

- **`docs/production_design.md`** — the "battery-side ESP32-S3 + display-side
  ESP32-S3 over RS-485" architecture is what the wedge-and-restart workarounds
  are ultimately here to bridge until. Once that hardware is running, the whole
  `data/pack.csv` + cloud uploader path becomes optional (still nice for cloud
  viewing) rather than survival-critical for the local wall display.

The reader-side telemetry (partial-success logging in `read_pack`, structured
event log via `_event`, per-battery RSSI capture, `data/ble_events.jsonl`
rotation) is **not** hardware-dependent — those are diagnostic infrastructure
that helps *any* platform and should stay.

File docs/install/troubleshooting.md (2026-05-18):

# Troubleshooting

Common failure modes, in approximate order of likelihood, with the
quick check and the actual fix.

## Display panel stays blank after power-up

| Quick check | Likely cause / fix |
|---|---|
| 12 V at U10 VIN? | No → check Cat5e termination, polarity |
| 3.3 V at U10 VOUT? | No → buck regulator failure; replace U10  |
| E-paper FFC fully seated both ends? | No → reseat; the latch is easy to miss |
| Onboard LED blinking? | No → ESP32 isn't running; flash check |
| BUSY line stays high forever? | Panel firmware-level issue; reset board |

## Display shows "LINK DOWN" after running fine

The battery-side stopped sending frames.

| Quick check | Likely cause / fix |
|---|---|
| Is the battery-side enclosure powered? | Fuse blown? 24 V tap loose? |
| Battery-side LED state? | Off = no power; fast blink = LOW state (pack < 25 %) |
| Continuity on Cat5e RS-485 pair? | Cable damage somewhere in-wall |
| Display side's RS-485 transceiver hot? | Driver fight (two transceivers trying to drive) |

## Battery-side never finds the BLE batteries

| Quick check | Likely cause / fix |
|---|---|
| Are the batteries powered on? | Volthium BMSes need to be active |
| Volthium phone app open somewhere? | Only one BLE central allowed; close the app |
| Distance from batteries < 3 m? | Move closer; BLE 4.0 is range-limited |
| Antenna keepout respected on PCB? | Re-check layout near the WROOM-1 antenna corner  |
| Firmware version recent? | Check `git log firmware/bms-link/` |

## Wall display shows "BMS A OFFLINE" (just one battery)

One of the two BMSes isn't being read.

1. Read the displayed serial number — which battery is offline?
2. Open the Volthium phone app and check that battery directly.
3. If the phone app can't see it either → battery's BMS may be in a
   protection state. Reset the battery per Volthium's procedure.
4. If the phone app sees it but ours doesn't → BLE address may have
   shifted (iOS-style randomization isn't a thing on these BMSes, but
   firmware-level address caching can drift). Force a re-scan via the
   override button.

## "MONITOR ASLEEP — pack <10%"

This is *correct behavior* when the pack is deeply discharged. The
monitor has hard-cut to protect the pack. To re-enable:

- Wait for the pack to recover (e.g. solar charges it back up) — the
  ULP voltage-sense will auto-re-engage when voltage indicates SOC
  recovery.
- Or press the **override button** on the battery-side enclosure to
  force re-engage right now.

## "LOW PACK" banner shows but pack is fine

False positive — the monitor thinks SOC is < 25 % but the Volthium app
says otherwise. Possible causes:

| Cause | Fix |
|---|---|
| BMS reporting bad SOC (rare) | Cycle the battery; let the BMS re-learn its SOC |
| Stuck reading from one battery dominating | Look at per-battery SOC on the display; if asymmetric, one BMS may be the source |
| Capacity drift in our config | The estimator's `capacity_ah` is hard-coded at 200 Ah; if the batteries have aged, update via the firmware build configuration |

## Display refresh "ghosting" (faint old image)

Normal for e-paper after many partial refreshes. The firmware schedules
a full refresh every 10 minutes to clear ghosting. If it's persistent:

- Force a full refresh with BTN_REFRESH (long press = full refresh).
- Temperature too low (< 0 °C) → e-paper specs degrade; this should
  only happen if the cabin is unheated and the heater hasn't kicked on.

## Buttons not responding

| Quick check | Likely cause / fix |
|---|---|
| Multimeter: button closes to GND? | No → mechanical failure; replace switch |
| 10 kΩ pull-up to V3V3 across button? | No → pull-up resistor open; trace damage |
| Same button across all three? | Yes → firmware issue, not hardware |

## RS-485 frame errors in the log

Battery-side firmware logs CRC mismatches as `WARN frame crc fail
got=XXXX want=YYYY`. Occasional ones (< 1 per minute) are fine —
60 Hz noise pickup or a brief bus glitch. Frequent ones suggest:

| Cause | Fix |
|---|---|
| Shield bonded at both ends | Lift the display-side bond |
| Termination missing or doubled | Verify 120 Ω only at the **two endpoints**; lift internal terms |
| Bias resistors missing | Drop in R2/R3 idle-bias on the battery side |
| Cable run next to high-current AC wiring | Separation rules — keep > 30 cm from AC for the cable run |

## Mac dashboard shows "no data yet"

The CSV logger isn't producing rows. Common reasons:

1. **Logger crashed**: `pgrep -f scripts/log.py` returns nothing.
   Restart via `./Launch Volthium Monitor.command` or the manual
   commands in `README.md`.
2. **Bluetooth permission dropped**: macOS 15 sometimes revokes
   Bluetooth permission for Terminal after a major update. See
   `memory/macos_bluetooth_tcc.md` for the patch.
3. **Both batteries unreachable**: rare; same situation as the wall
   display would show "BMS OFFLINE."

## When in doubt

Capture the state and ask:

```bash
# Snapshot of current state
{
  echo "== processes =="
  pgrep -fl 'scripts/log\.py'
  pgrep -fl 'scripts/dashboard\.py'
  echo
  echo "== last 10 log lines =="
  tail -10 data/pack.log
  echo
  echo "== last 5 CSV rows =="
  tail -5 data/pack.csv
  echo
  echo "== analyze =="
  .venv/bin/python scripts/analyze.py
} > /tmp/volthium_snapshot.txt
```

Paste `/tmp/volthium_snapshot.txt` into a new Claude Code session for
fresh-eyes triage.

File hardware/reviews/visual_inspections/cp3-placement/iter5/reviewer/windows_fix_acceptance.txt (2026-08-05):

CP3 finding 08 - Windows portability fix acceptance
====================================================

Host
----
Windows 11, KiCad 10, repository virtual environment.

Full integration command
------------------------
.venv\Scripts\python.exe hardware\reviews\tools\handoff_check.py

Result
------
Exit code: 0

  [rebuild] schematic/build.py: rc=0
  [rebuild] schematic/build_display.py: rc=0
  [rebuild] pcb/build.py: rc=0
  HANDOFF: CLEAN - artifacts fresh, hashes true, consistency ok

Independent byte audit after the rebuild
----------------------------------------

  Deterministic artifacts enumerated: 26
  Artifact path keys containing backslashes: 0
  Worktree/HEAD byte mismatches: 0
  Artifacts containing CRLF: 0
  One-CRLF in-memory poison rejected by byte comparator: yes

Syntax check
------------
.venv\Scripts\python.exe -m py_compile \
  hardware\kicad\schematic\core.py \
  hardware\kicad\pcb\core.py \
  hardware\reviews\tools\handoff_check.py

Result: exit 0.

Scope
-----
User-directed tooling-only reviewer exception. The designer must re-review
the implementation before treating Finding 08 as resolved.

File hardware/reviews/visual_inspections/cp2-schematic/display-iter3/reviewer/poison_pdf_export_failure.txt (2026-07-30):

build_returncode=0
forced_pdf_export_failures=5
child_pdf_text_clean_markers=4
stale_conn_pdf_hash_unchanged=True
stale_pdf_failure_accepted=True
----- stdout -----
[env] KiCad share: C:\Users\kaanw\AppData\Local/Programs/KiCad/10.0/share/kicad
[env] KiCad CLI: C:\Users\kaanw\AppData\Local\Programs\KiCad\10.0\bin\kicad-cli.exe
[sheet_d_power] readability gate: clean
[poison] forced PDF export failure: sch export pdf -o C:\Users\kaanw\AppData\Local\Temp\pdf-export-poison-fthaw22y\kicad\schematic\build_display\sheet_d_power.pdf C:\Users\kaanw\AppData\Local\Temp\pdf-export-poison-fthaw22y\kicad\schematic\build_display\sheet_d_power.kicad_sch
[sheet_d_power] pdf-text gate: clean
[sheet_d_power] PNG written
[sheet_d_conn] readability gate: clean
[poison] forced PDF export failure: sch export pdf -o C:\Users\kaanw\AppData\Local\Temp\pdf-export-poison-fthaw22y\kicad\schematic\build_display\sheet_d_conn.pdf C:\Users\kaanw\AppData\Local\Temp\pdf-export-poison-fthaw22y\kicad\schematic\build_display\sheet_d_conn.kicad_sch
[sheet_d_conn] pdf-text gate: clean
[sheet_d_conn] PNG written
[sheet_d_periph] readability gate: clean
[poison] forced PDF export failure: sch export pdf -o C:\Users\kaanw\AppData\Local\Temp\pdf-export-poison-fthaw22y\kicad\schematic\build_display\sheet_d_periph.pdf C:\Users\kaanw\AppData\Local\Temp\pdf-export-poison-fthaw22y\kicad\schematic\build_display\sheet_d_periph.kicad_sch
[sheet_d_periph] pdf-text gate: clean
[sheet_d_periph] PNG written
[sheet_d_mcu] readability gate: clean
[poison] forced PDF export failure: sch export pdf -o C:\Users\kaanw\AppData\Local\Temp\pdf-export-poison-fthaw22y\kicad\schematic\build_display\sheet_d_mcu.pdf C:\Users\kaanw\AppData\Local\Temp\pdf-export-poison-fthaw22y\kicad\schematic\build_display\sheet_d_mcu.kicad_sch
[sheet_d_mcu] pdf-text gate: clean
[sheet_d_mcu] PNG written
[NETLIST gate] generator intent == kicad-cli netlist: clean
[ROOT ERC strict] rc=0; 0 message(s), 0 accepted (ERC_ACCEPTED), 0 unaccounted
[poison] forced PDF export failure: sch export pdf -o C:\Users\kaanw\AppData\Local\Temp\pdf-export-poison-fthaw22y\kicad\schematic\build_display\volthium_display.pdf C:\Users\kaanw\AppData\Local\Temp\pdf-export-poison-fthaw22y\kicad\schematic\build_display\volthium_display.kicad_sch
[ROOT] wrote volthium_display.kicad_sch + .kicad_pro + full volthium_display.pdf
----- stderr -----

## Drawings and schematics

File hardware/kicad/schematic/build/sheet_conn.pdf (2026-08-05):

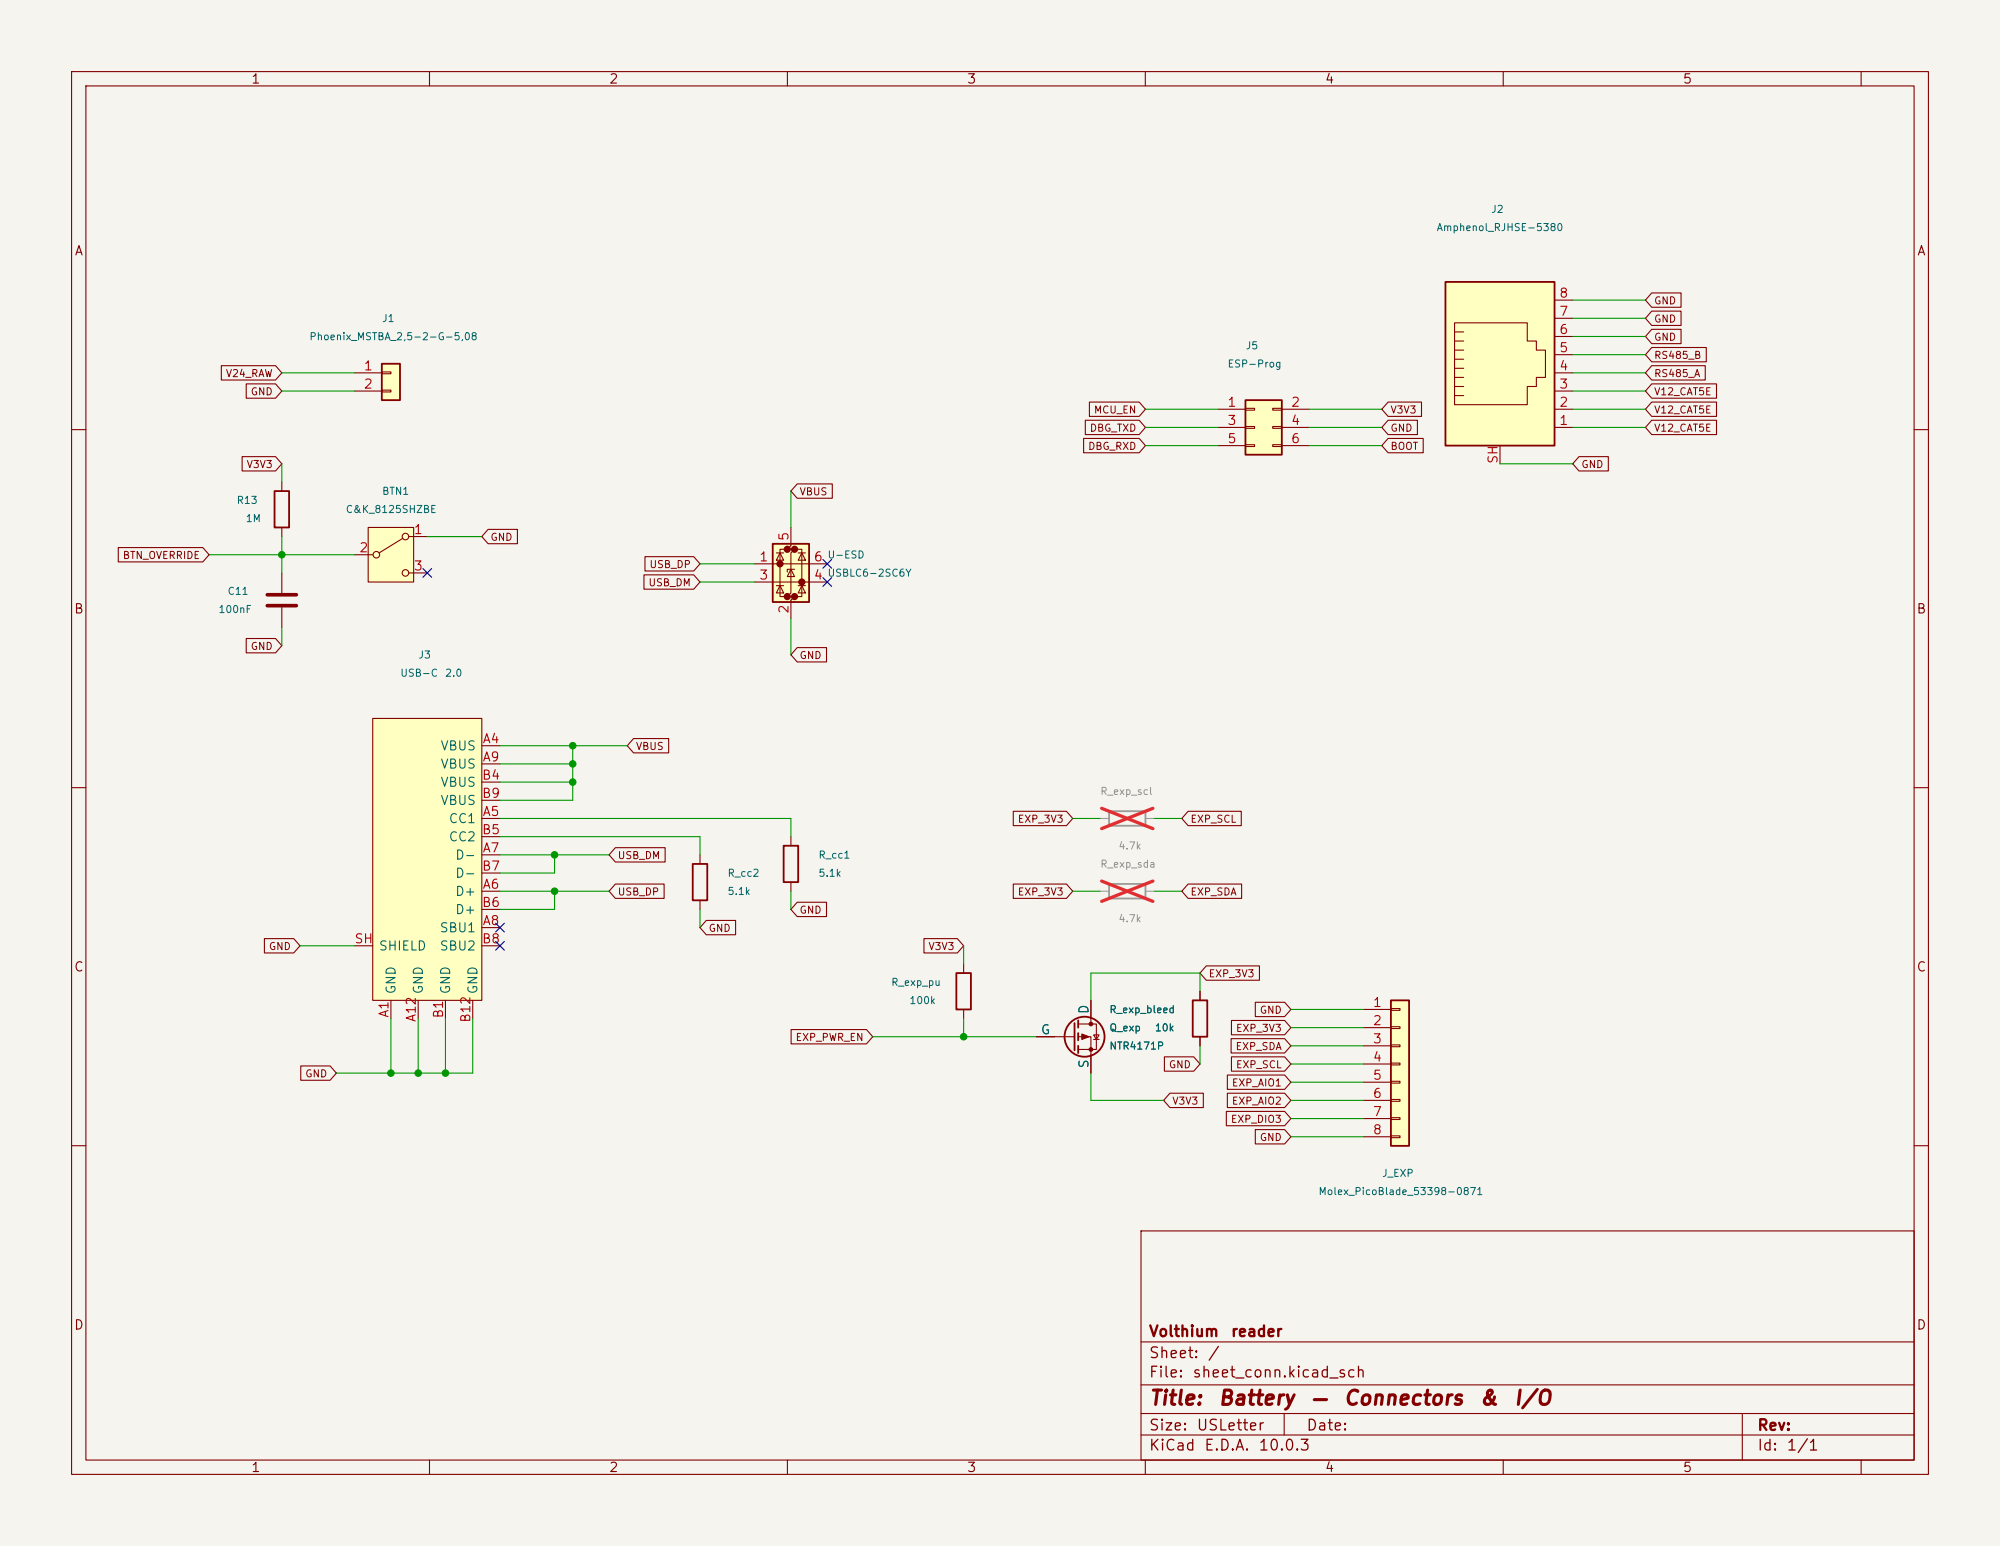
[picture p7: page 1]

Size: USLetter | Rev:
KiCad E.D.A. 10.0.3 | Id: 1/1

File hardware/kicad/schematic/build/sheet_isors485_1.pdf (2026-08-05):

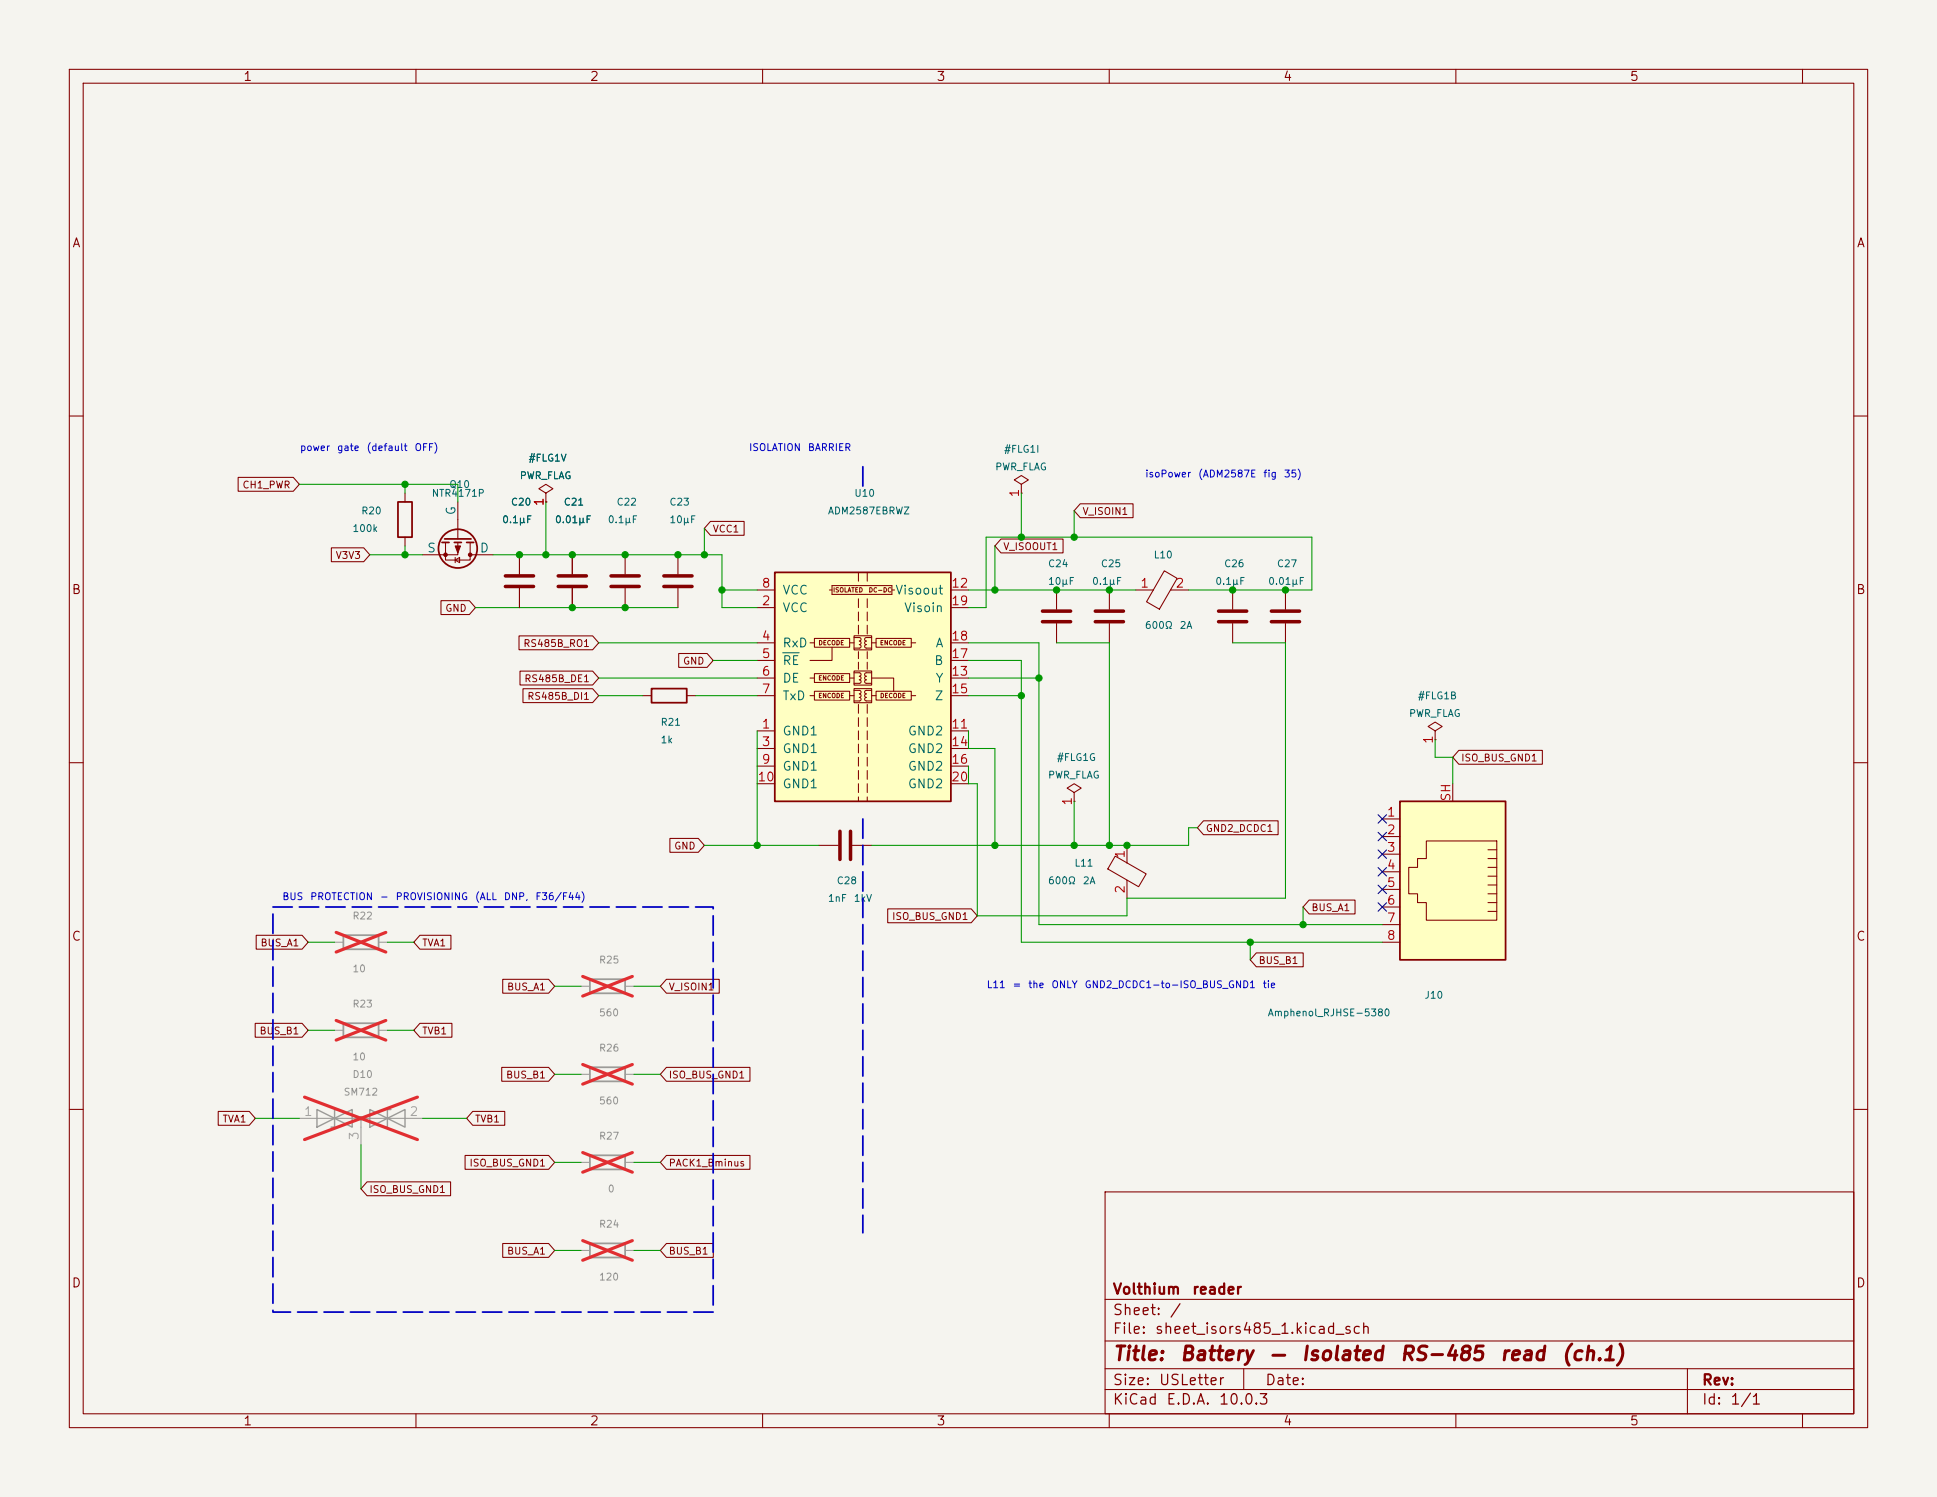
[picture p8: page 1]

isoPower (ADM2587E fig 35) L11 = the ONLY GND2_DCDC1-to-ISO_BUS_GND1 tie
Amphenol_RJHSE-5380 1

BUS PROTECTION - PROVISIONING (ALL DNP, F36/F44)

Volthium reader
Sheet: /
File: sheet_isors485_1.kicad_sch
Title: Battery — Isolated RS-485 read (ch.1)

Size: USLetter | Rev:
KiCad E.D.A. 10.0.3 | Id: 1/1

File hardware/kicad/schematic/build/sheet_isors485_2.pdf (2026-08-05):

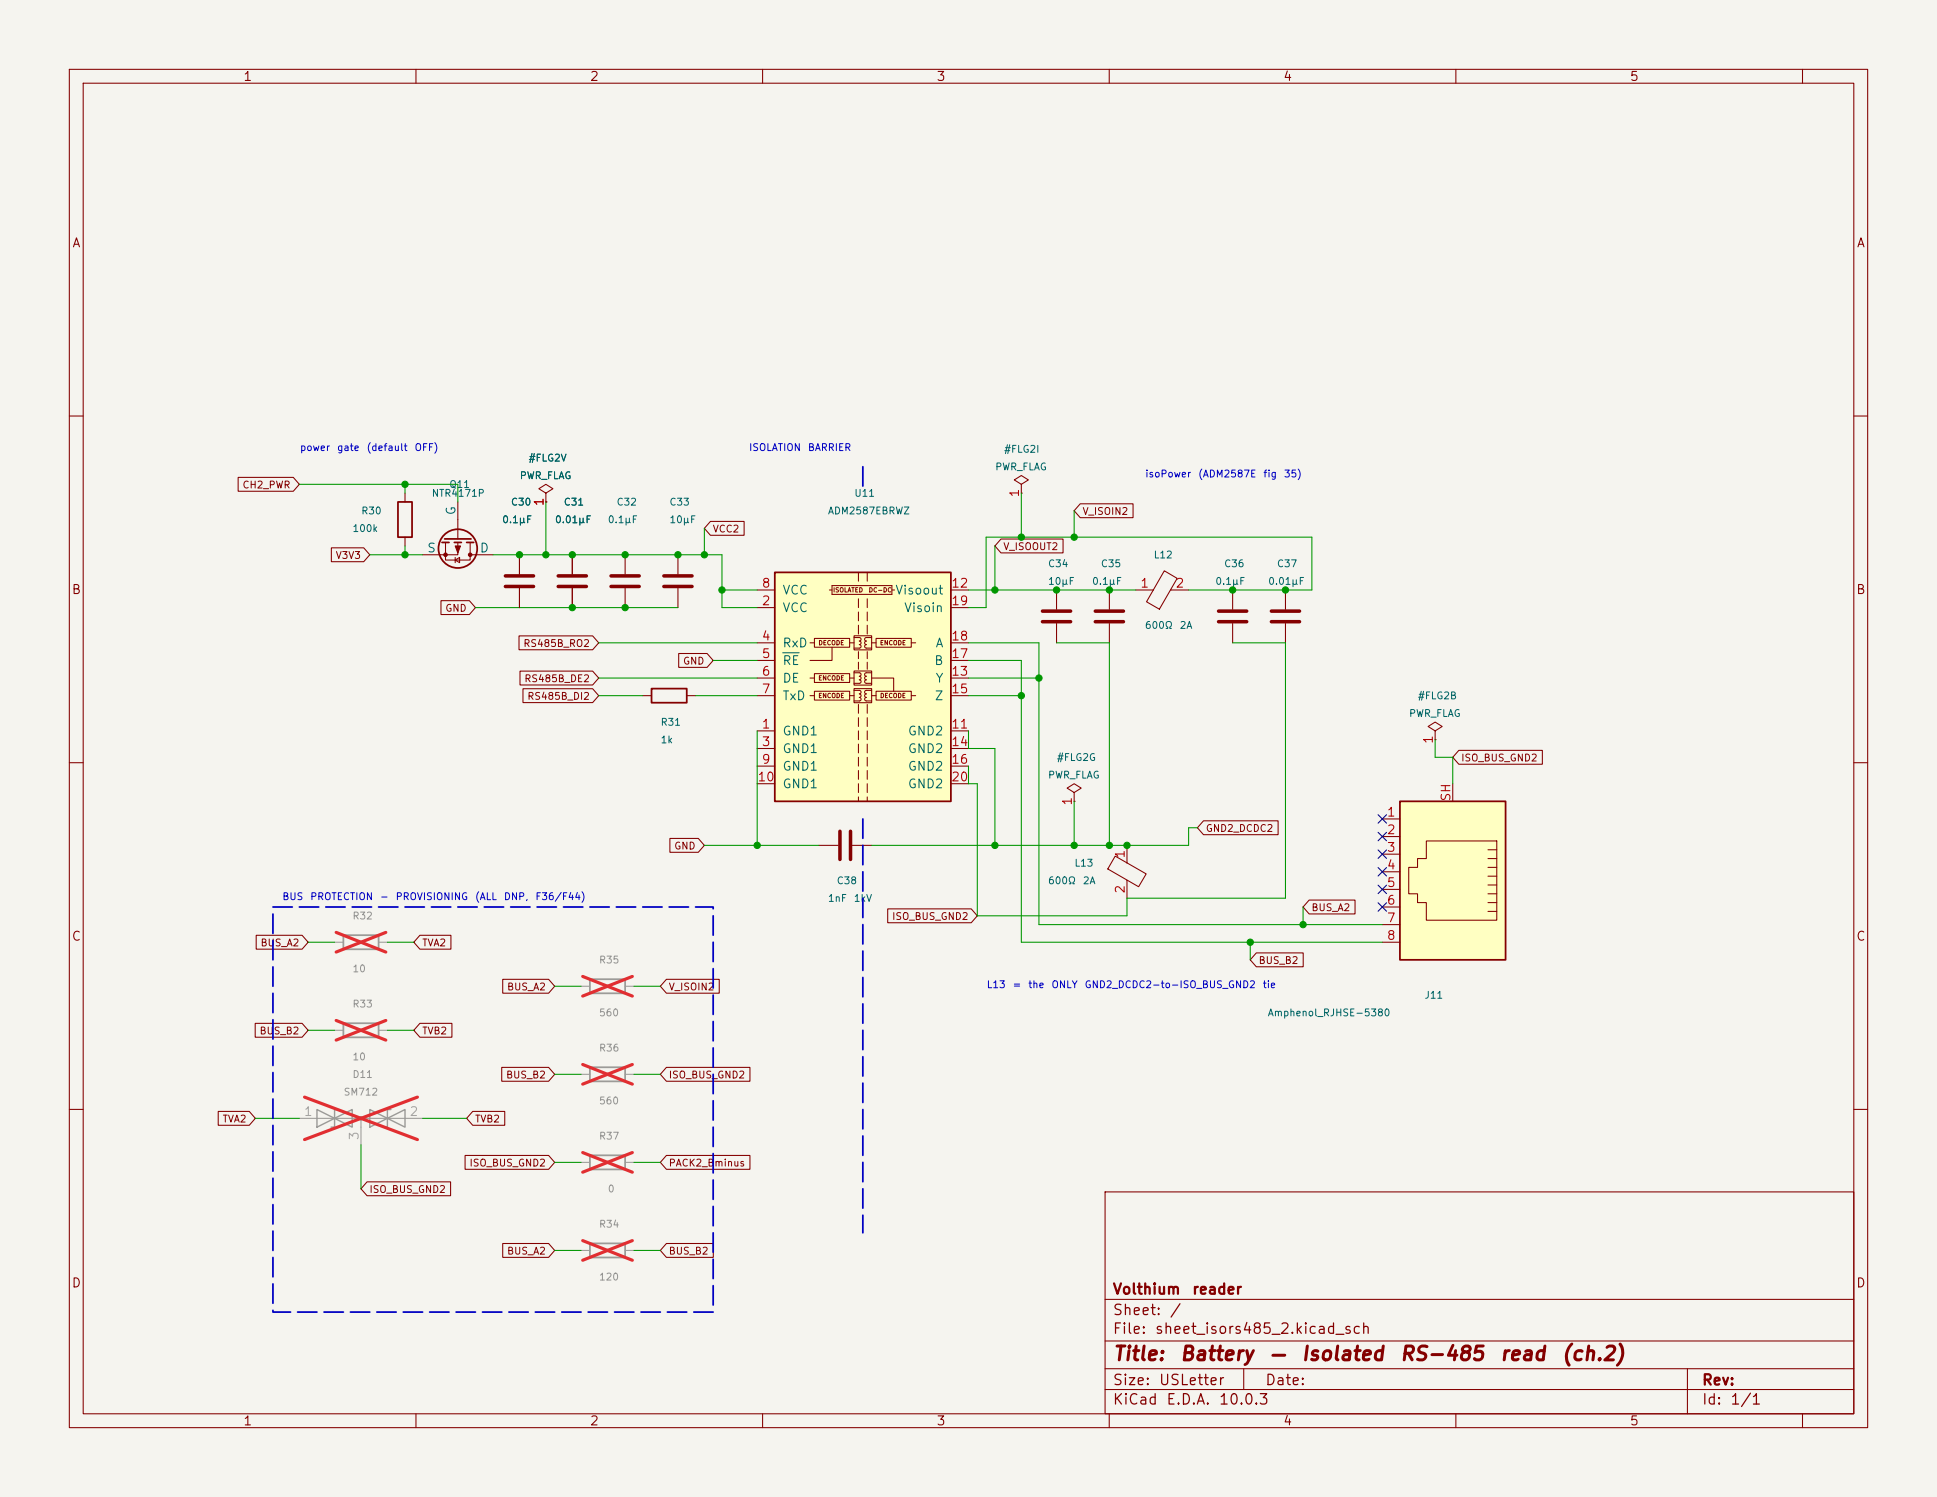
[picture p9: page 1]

isoPower (ADM2587E fig 35) L13 = the ONLY GND2_DCDC2-to-ISO_BUS_GND2 tie
Amphenol_RJHSE-5380 1

BUS PROTECTION - PROVISIONING (ALL DNP, F36/F44)

Volthium reader
Sheet: /
File: sheet_isors485_2.kicad_sch
Title: Battery — Isolated RS-485 read (ch.2)

Size: USLetter | Rev:
KiCad E.D.A. 10.0.3 | Id: 1/1

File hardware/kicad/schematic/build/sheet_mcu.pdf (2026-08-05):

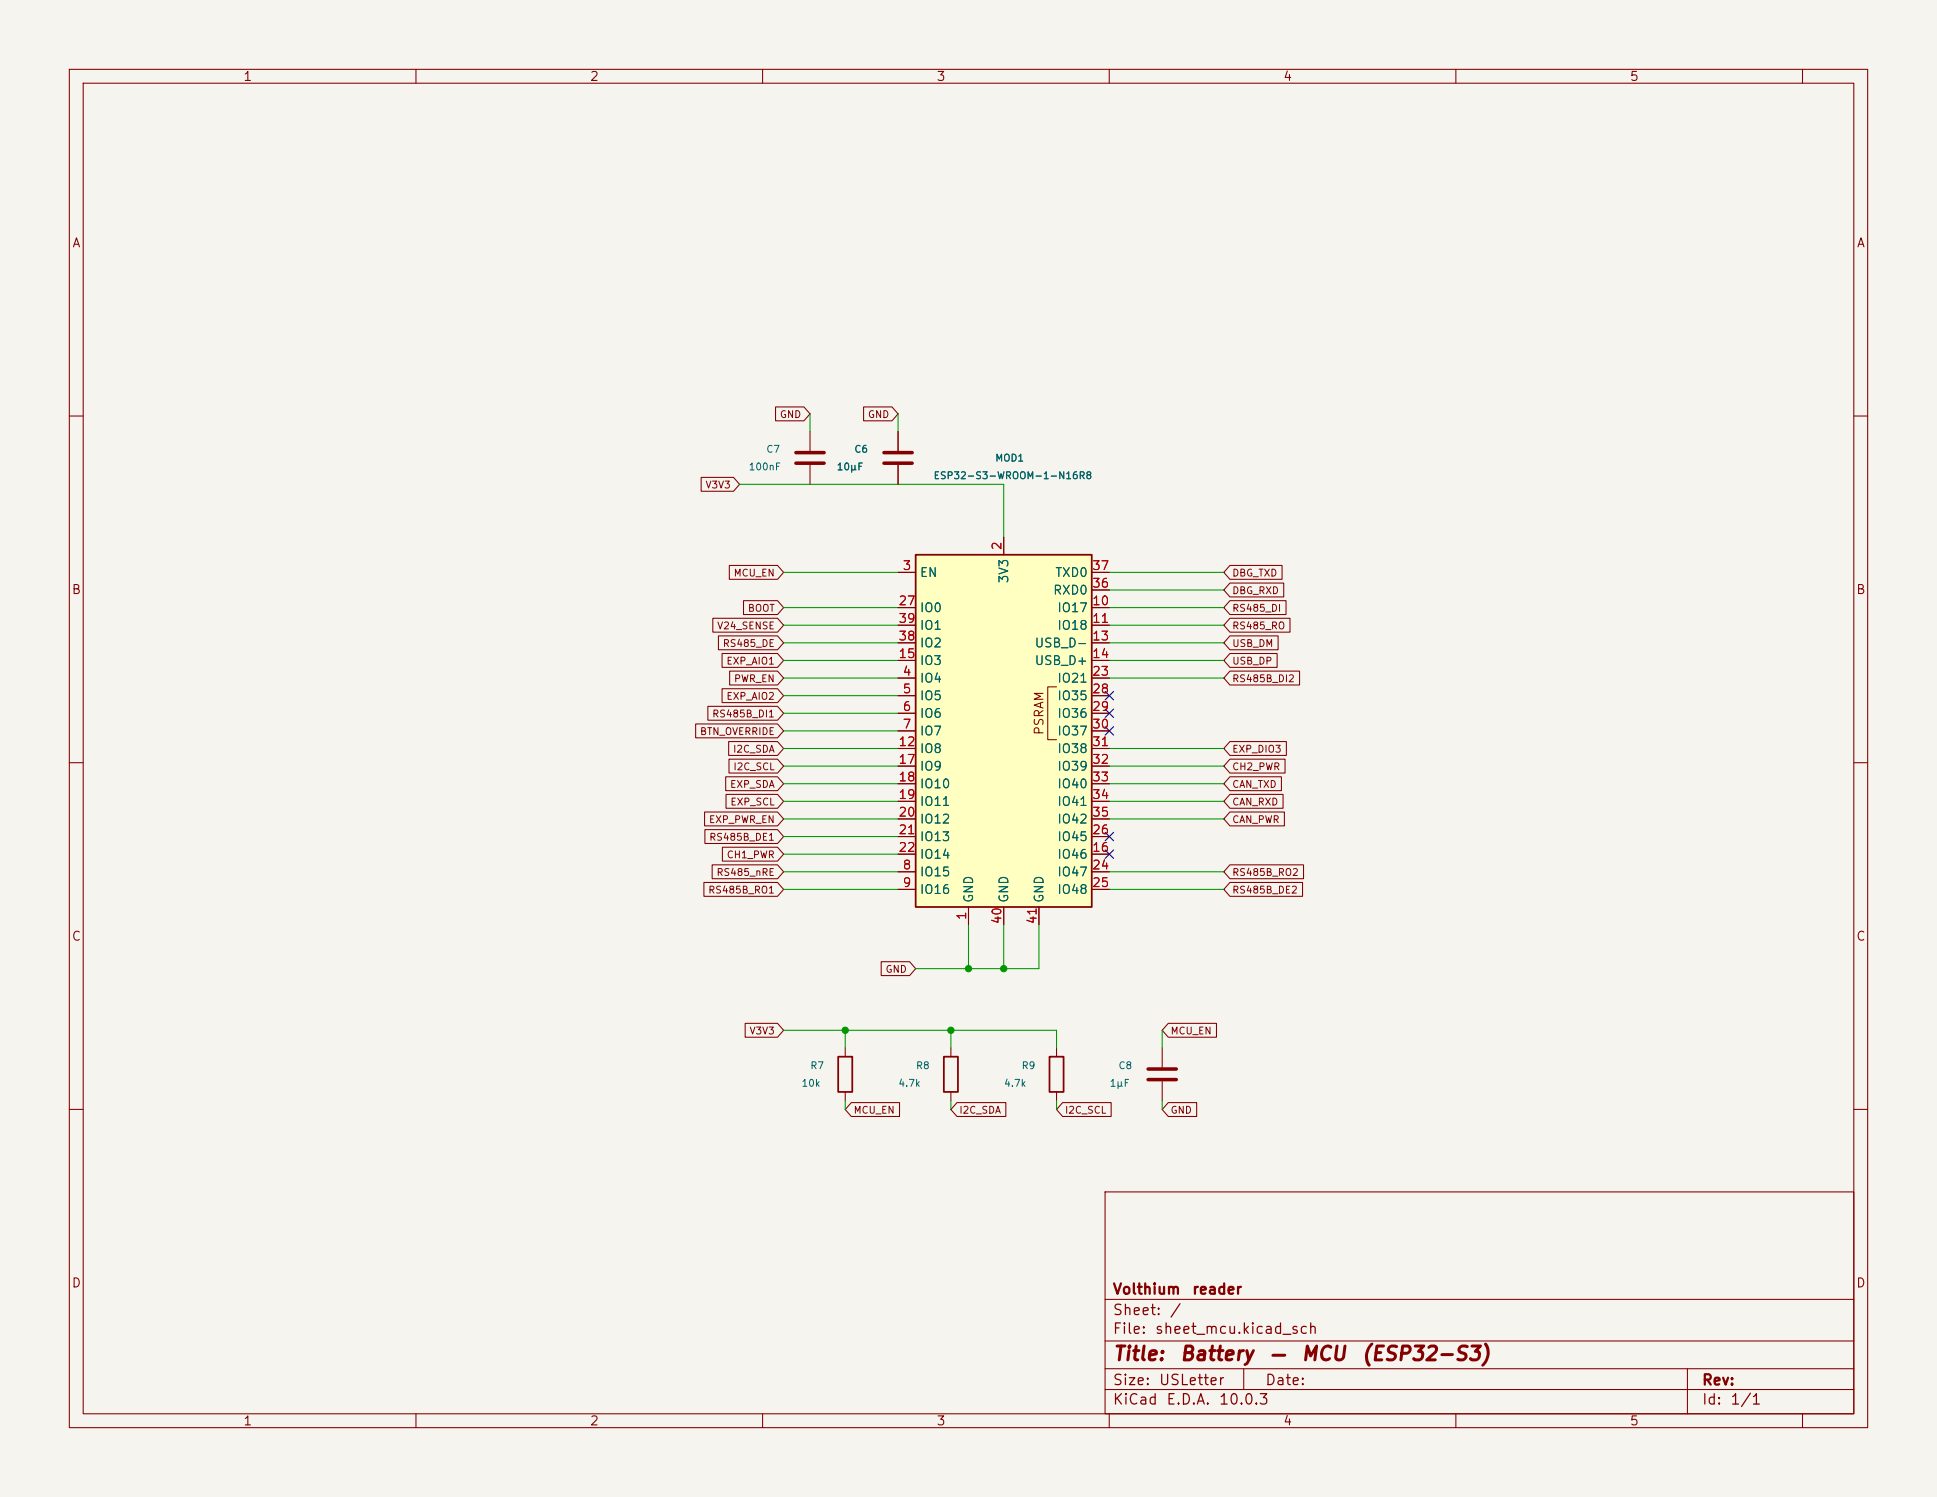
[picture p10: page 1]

Size: USLetter | Rev:
KiCad E.D.A. 10.0.3 | Id: 1/1

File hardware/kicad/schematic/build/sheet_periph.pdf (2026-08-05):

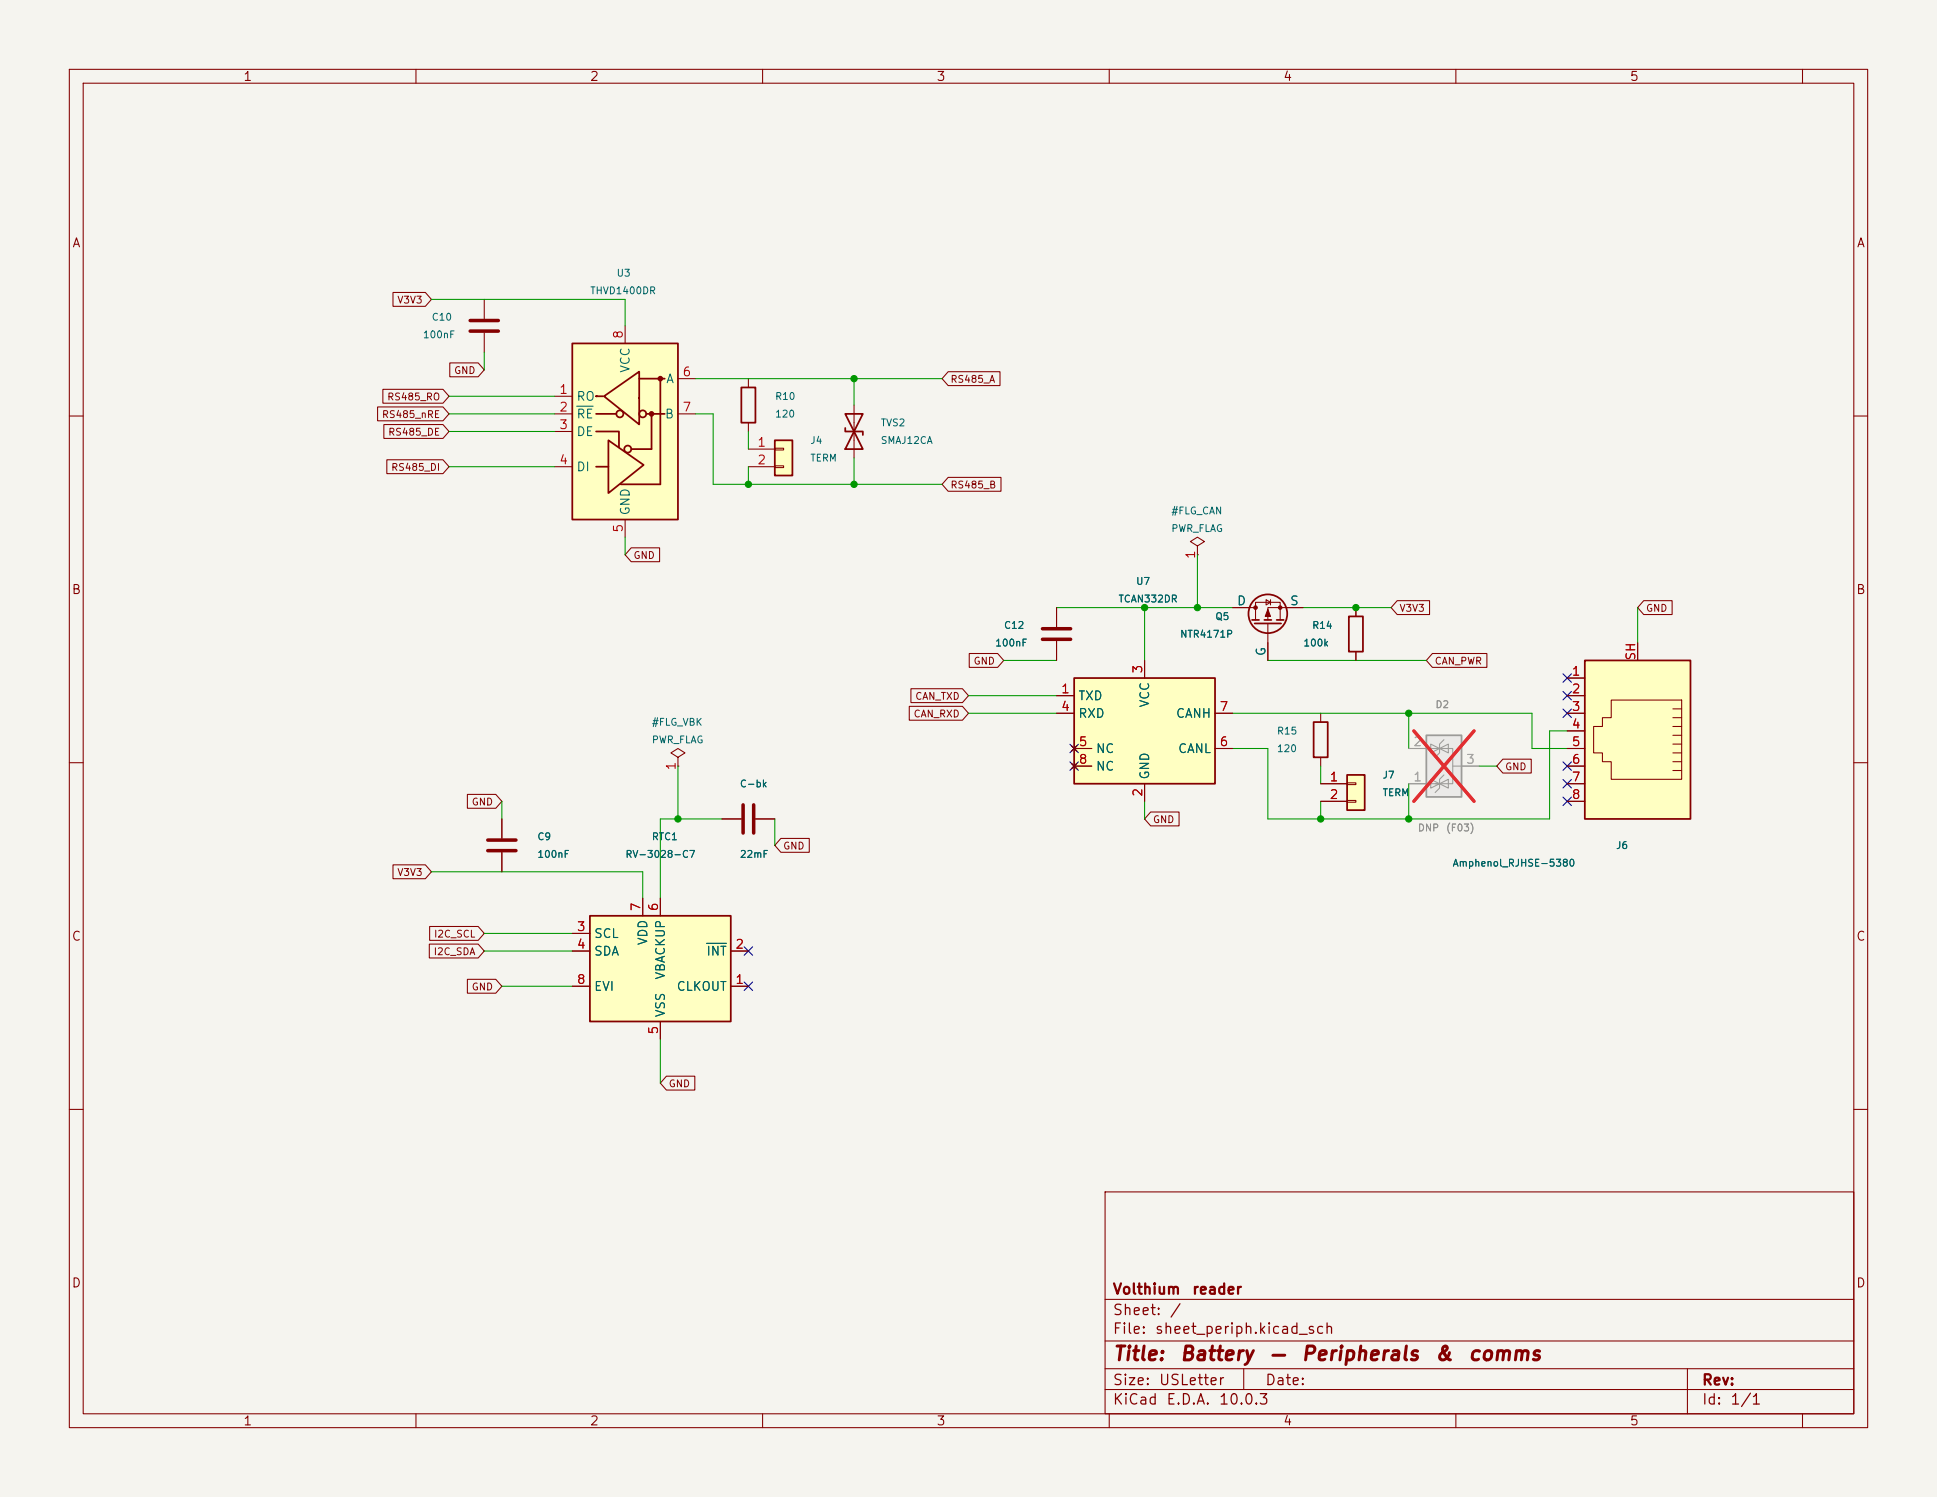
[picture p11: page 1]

3 RXD 4 NC 5 CANL 6 CANH 7 NC 8

Volthium reader
Sheet: /
File: sheet_periph.kicad_sch
Title: Battery — Peripherals & comms

Size: USLetter | Rev:
KiCad E.D.A. 10.0.3 | Id: 1/1

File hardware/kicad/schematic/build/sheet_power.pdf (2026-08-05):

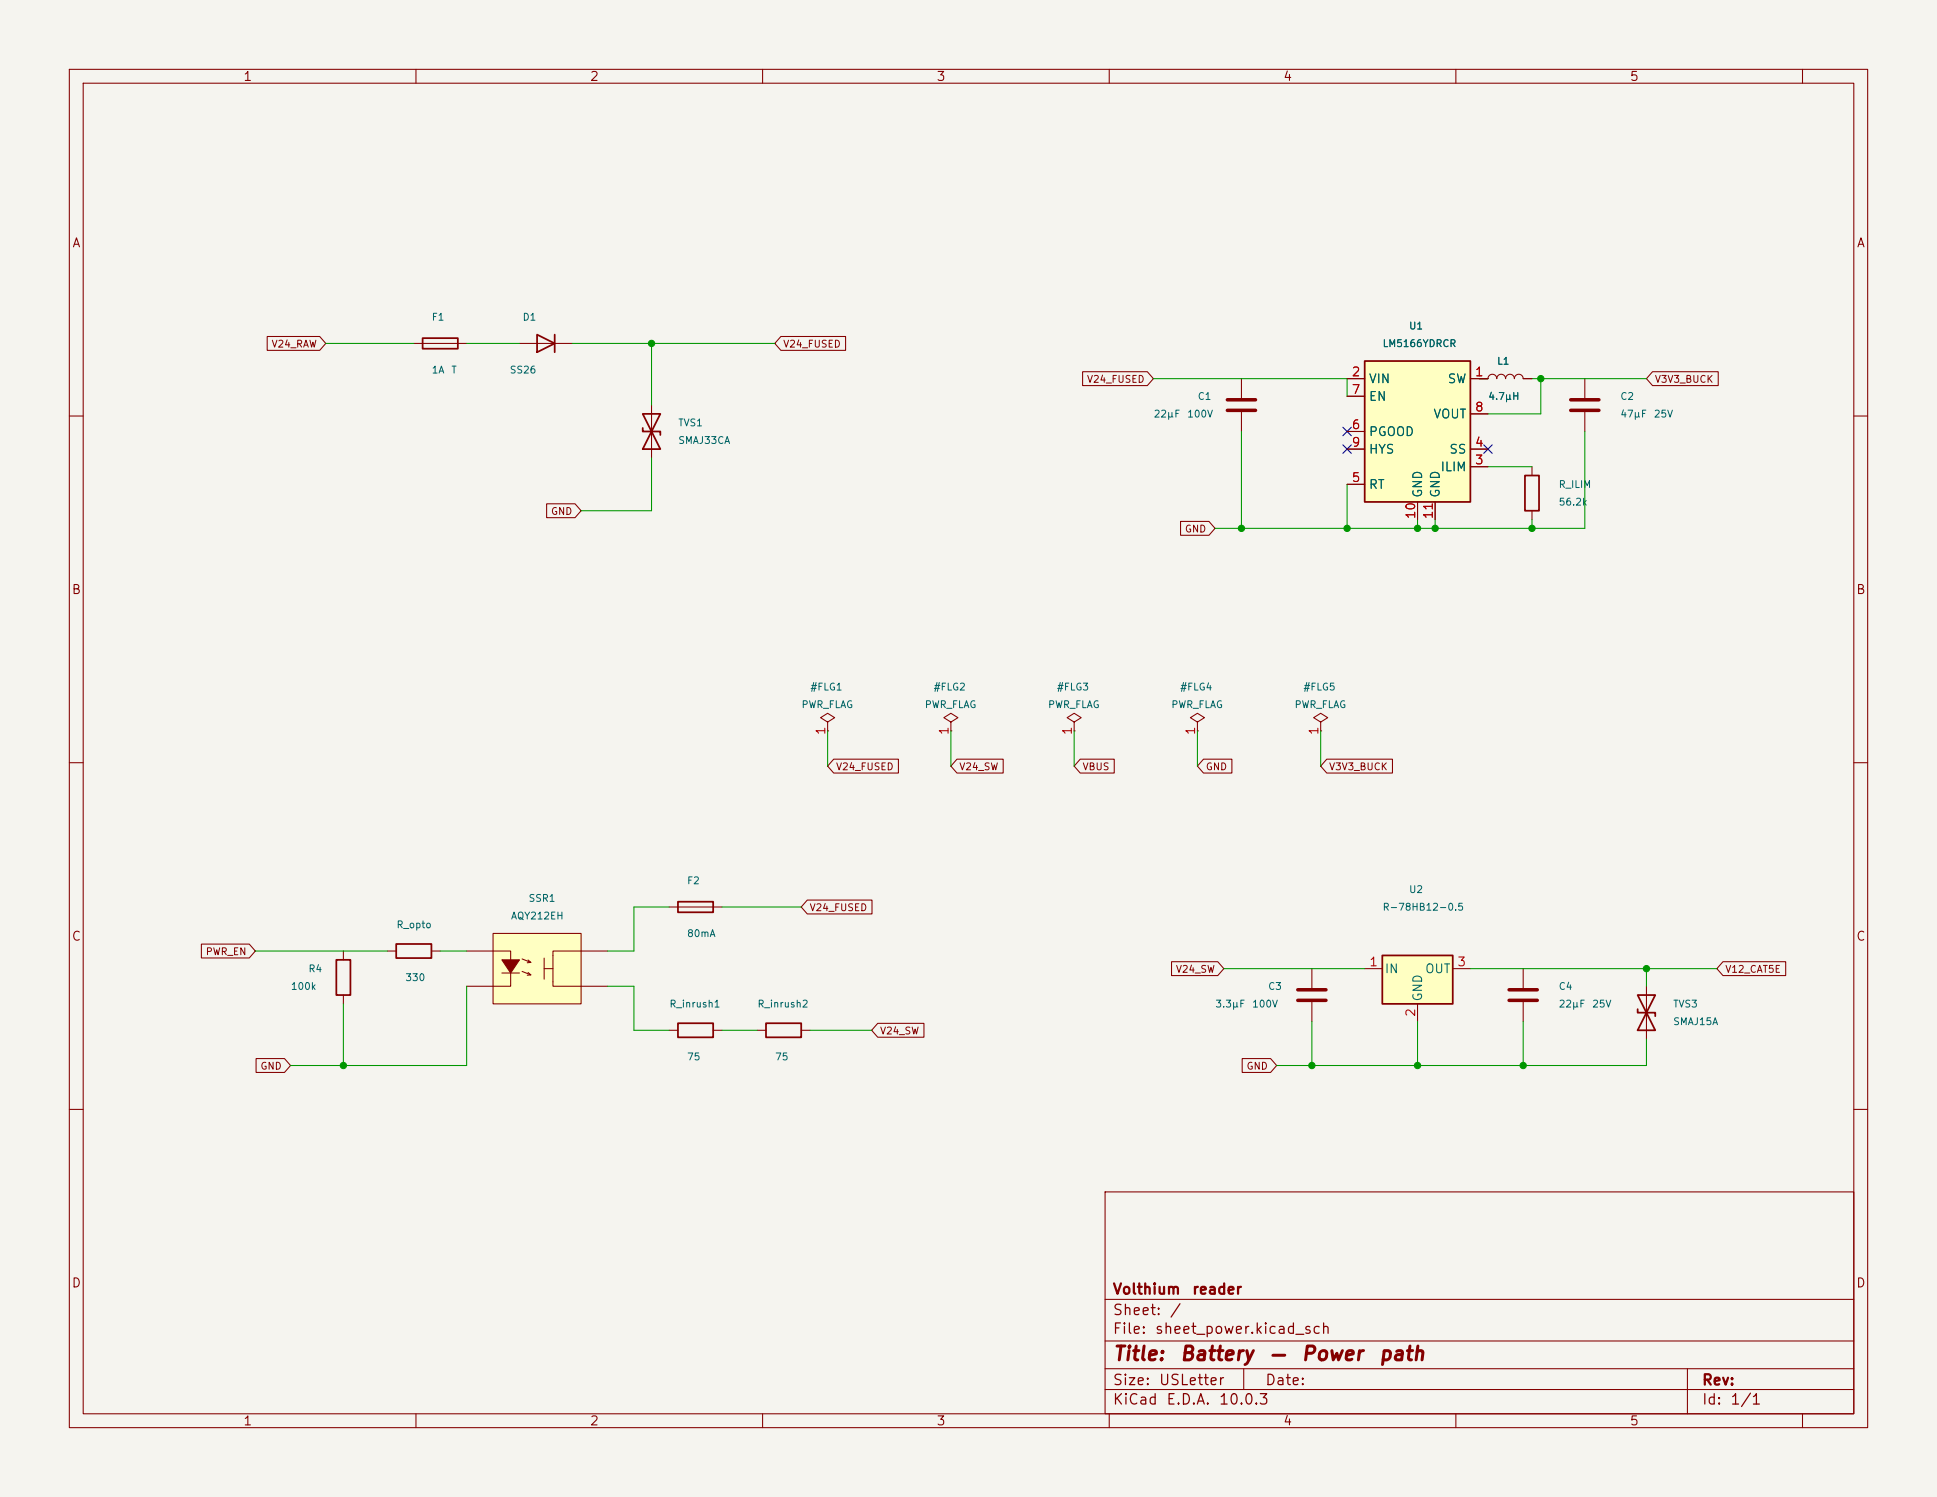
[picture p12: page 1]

Sheet: /
File: sheet_power.kicad_sch
Title: Battery — Power path

Size: USLetter | Rev:
KiCad E.D.A. 10.0.3 | Id: 1/1

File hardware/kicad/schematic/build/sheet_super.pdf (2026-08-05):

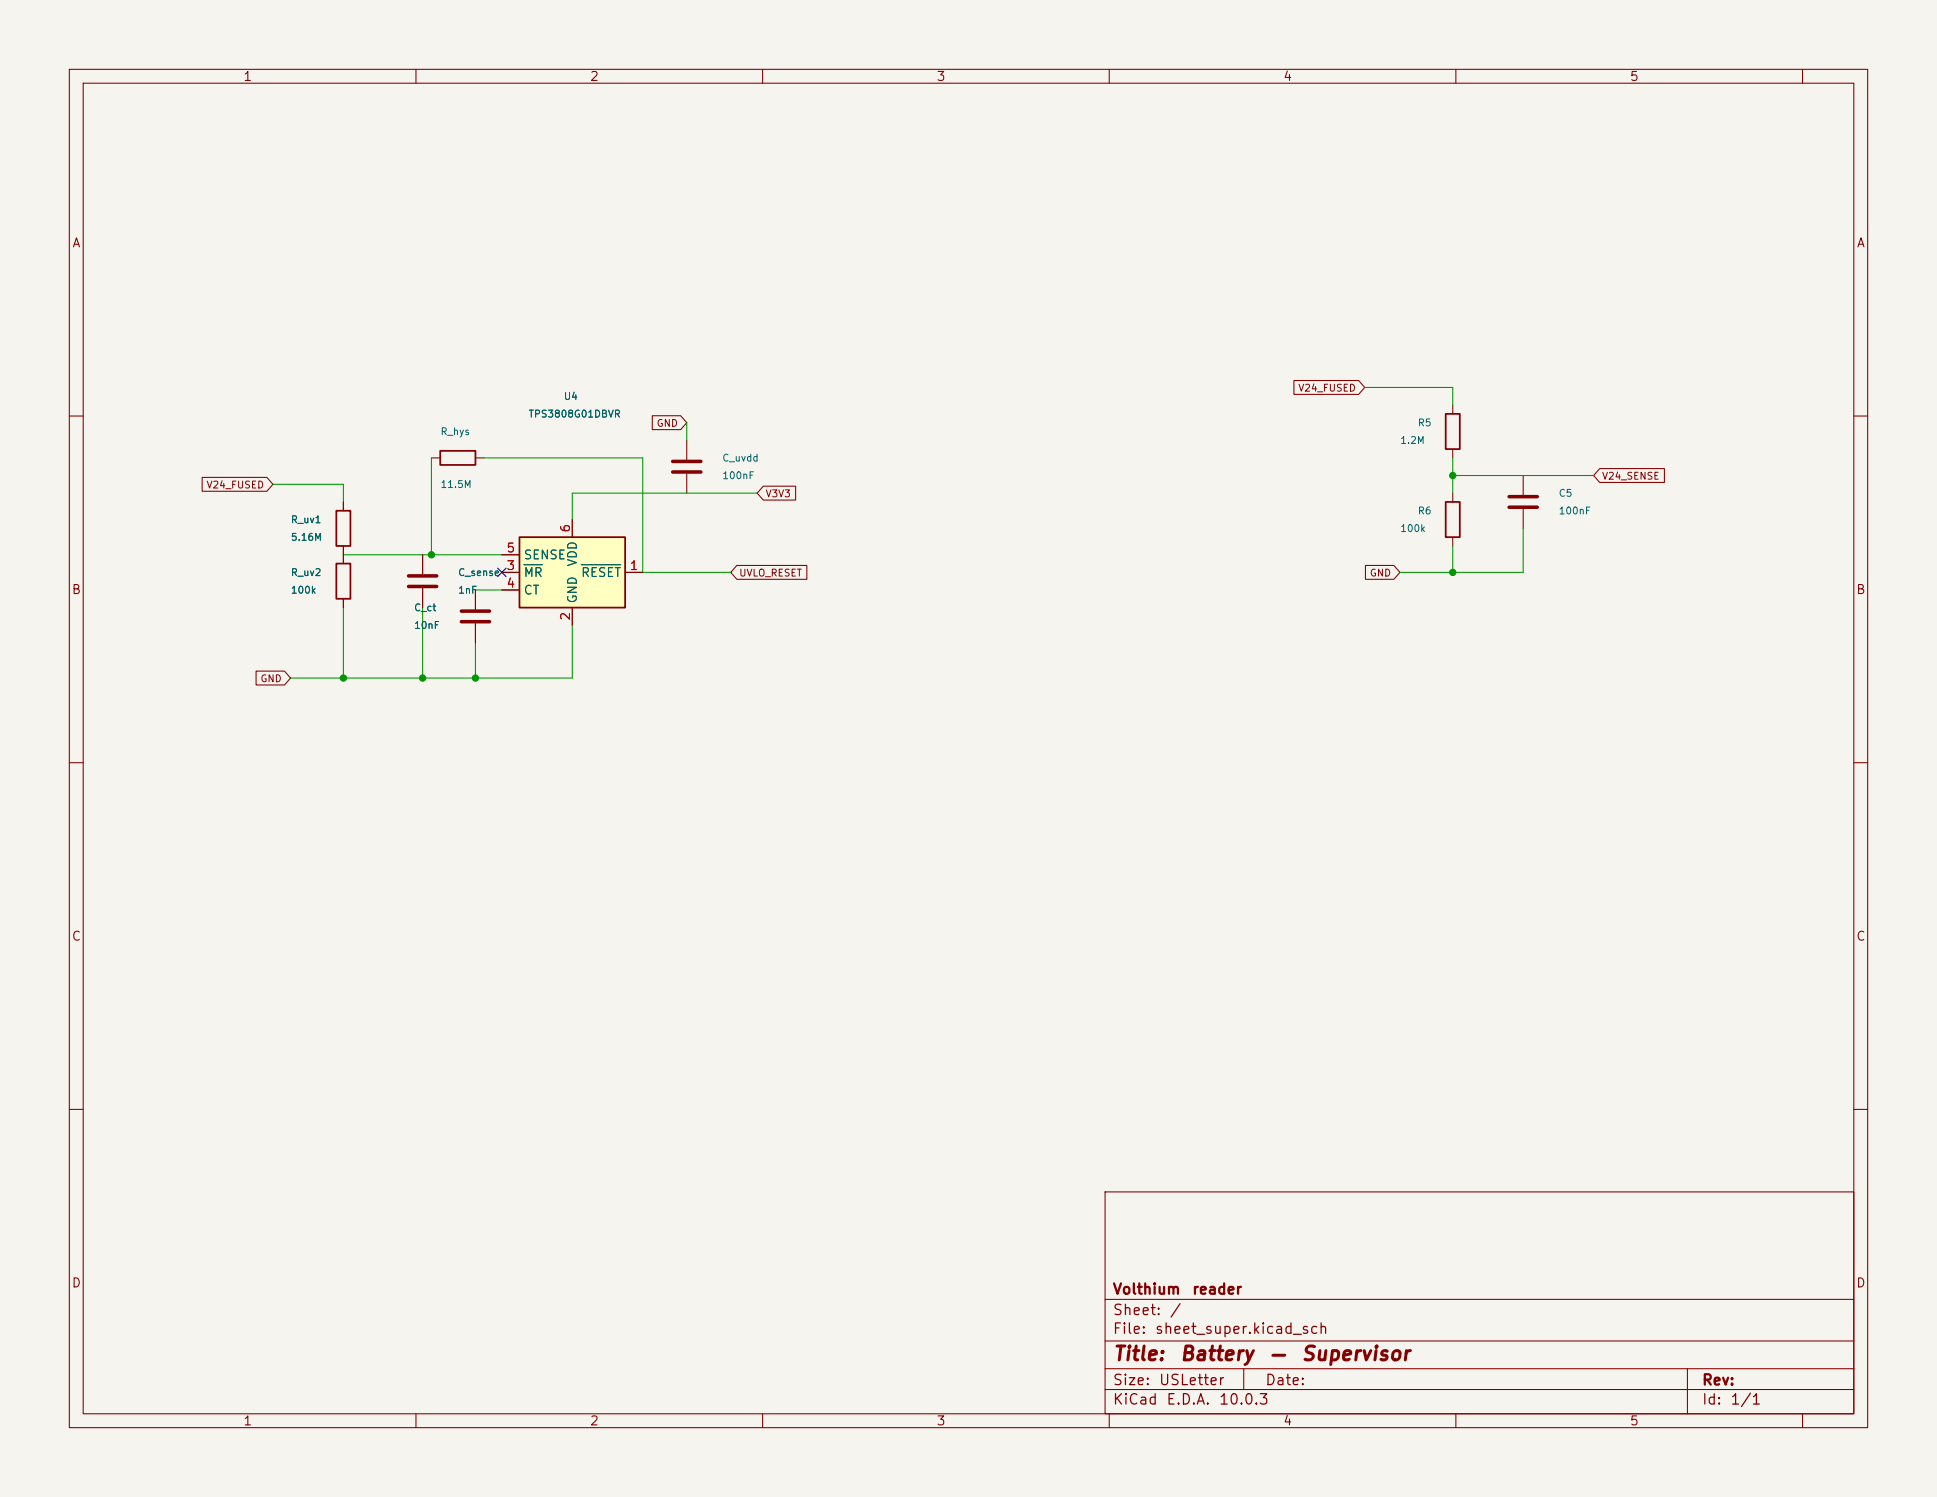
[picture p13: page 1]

Size: USLetter | Rev:
KiCad E.D.A. 10.0.3 | Id: 1/1

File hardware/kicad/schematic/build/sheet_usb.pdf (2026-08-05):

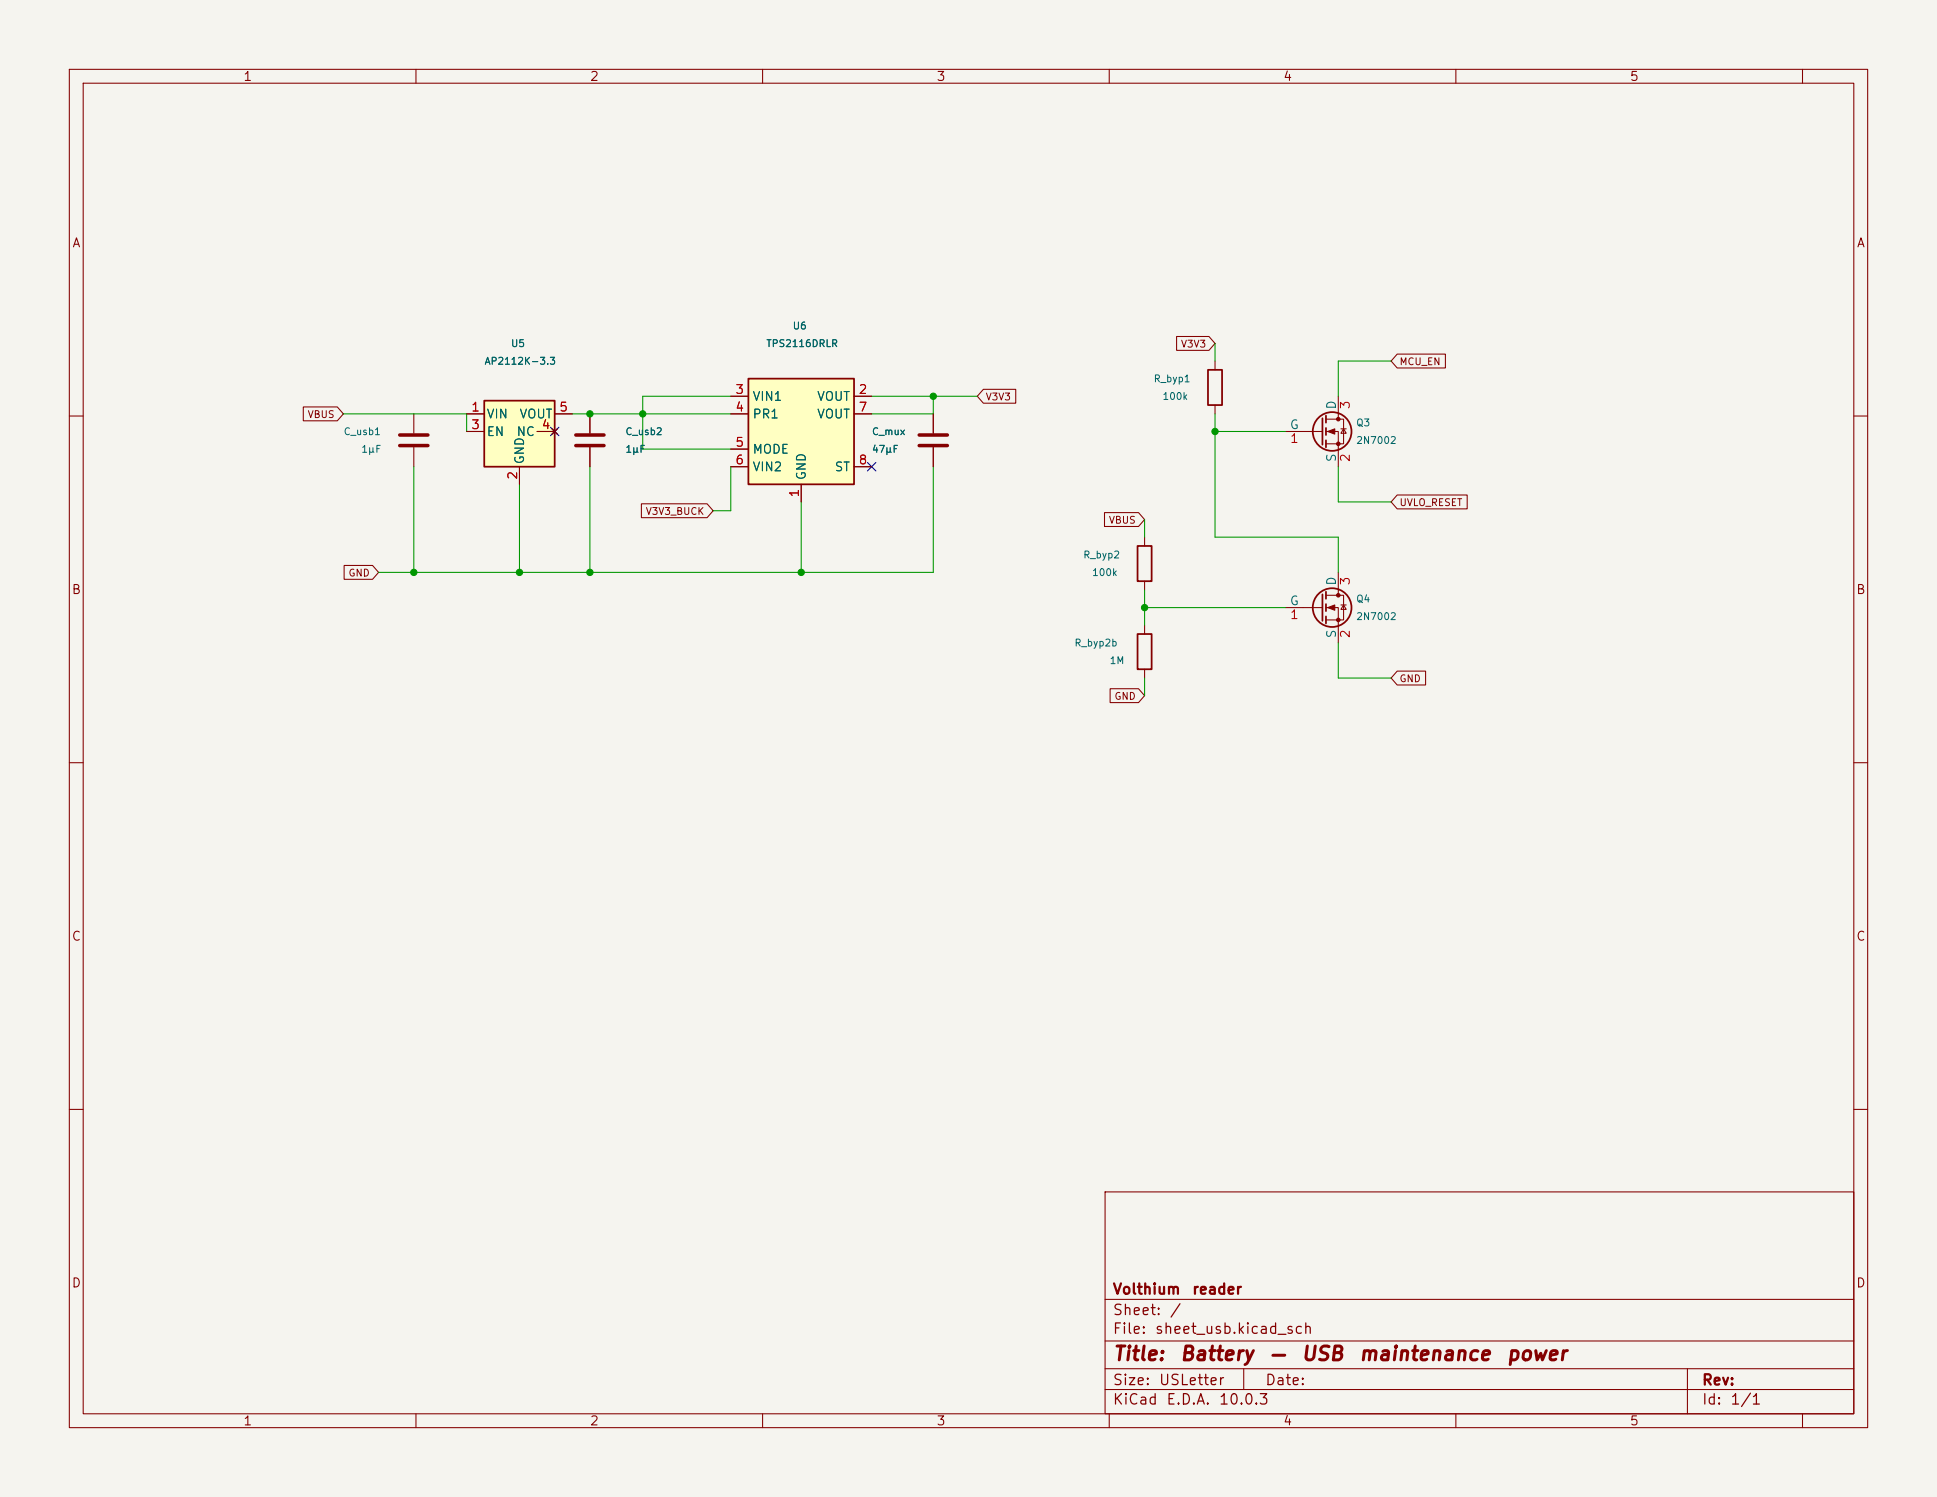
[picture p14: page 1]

Volthium reader
Sheet: /
File: sheet_usb.kicad_sch
Title: Battery — USB maintenance power

Size: USLetter | Rev:
KiCad E.D.A. 10.0.3 | Id: 1/1

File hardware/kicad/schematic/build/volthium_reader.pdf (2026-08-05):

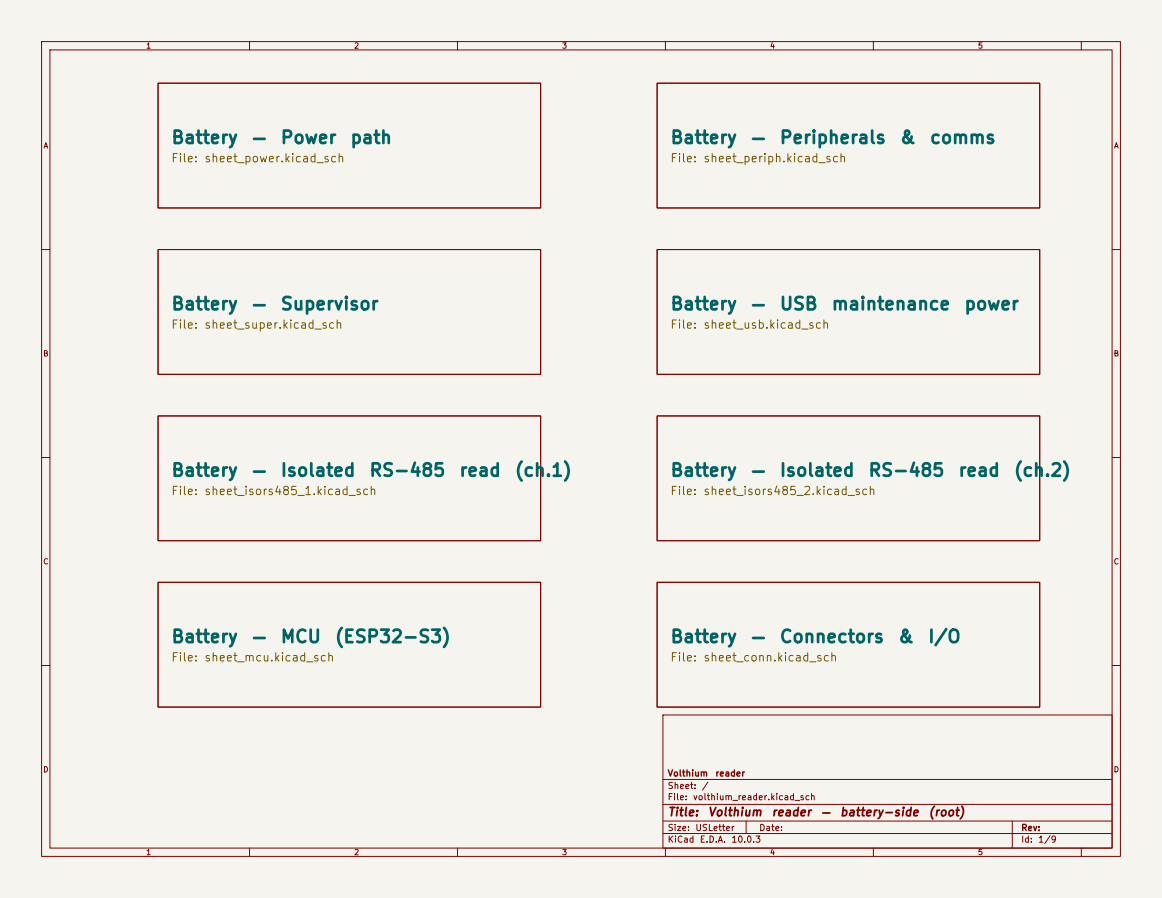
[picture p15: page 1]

Battery — USB maintenance power
File: sheet_usb.kicad_sch

Battery — Isolated RS-485 read (ch.1)
File: sheet_isors485_1.kicad_sch

Battery — Isolated RS-485 read (ch.2)
File: sheet_isors485_2.kicad_sch

Volthium reader
Sheet: /
File: volthium_reader.kicad_sch
Title: Volthium reader — battery-side (root)

Size: USLetter | Rev:
KiCad E.D.A. 10.0.3 | Id: 1/9

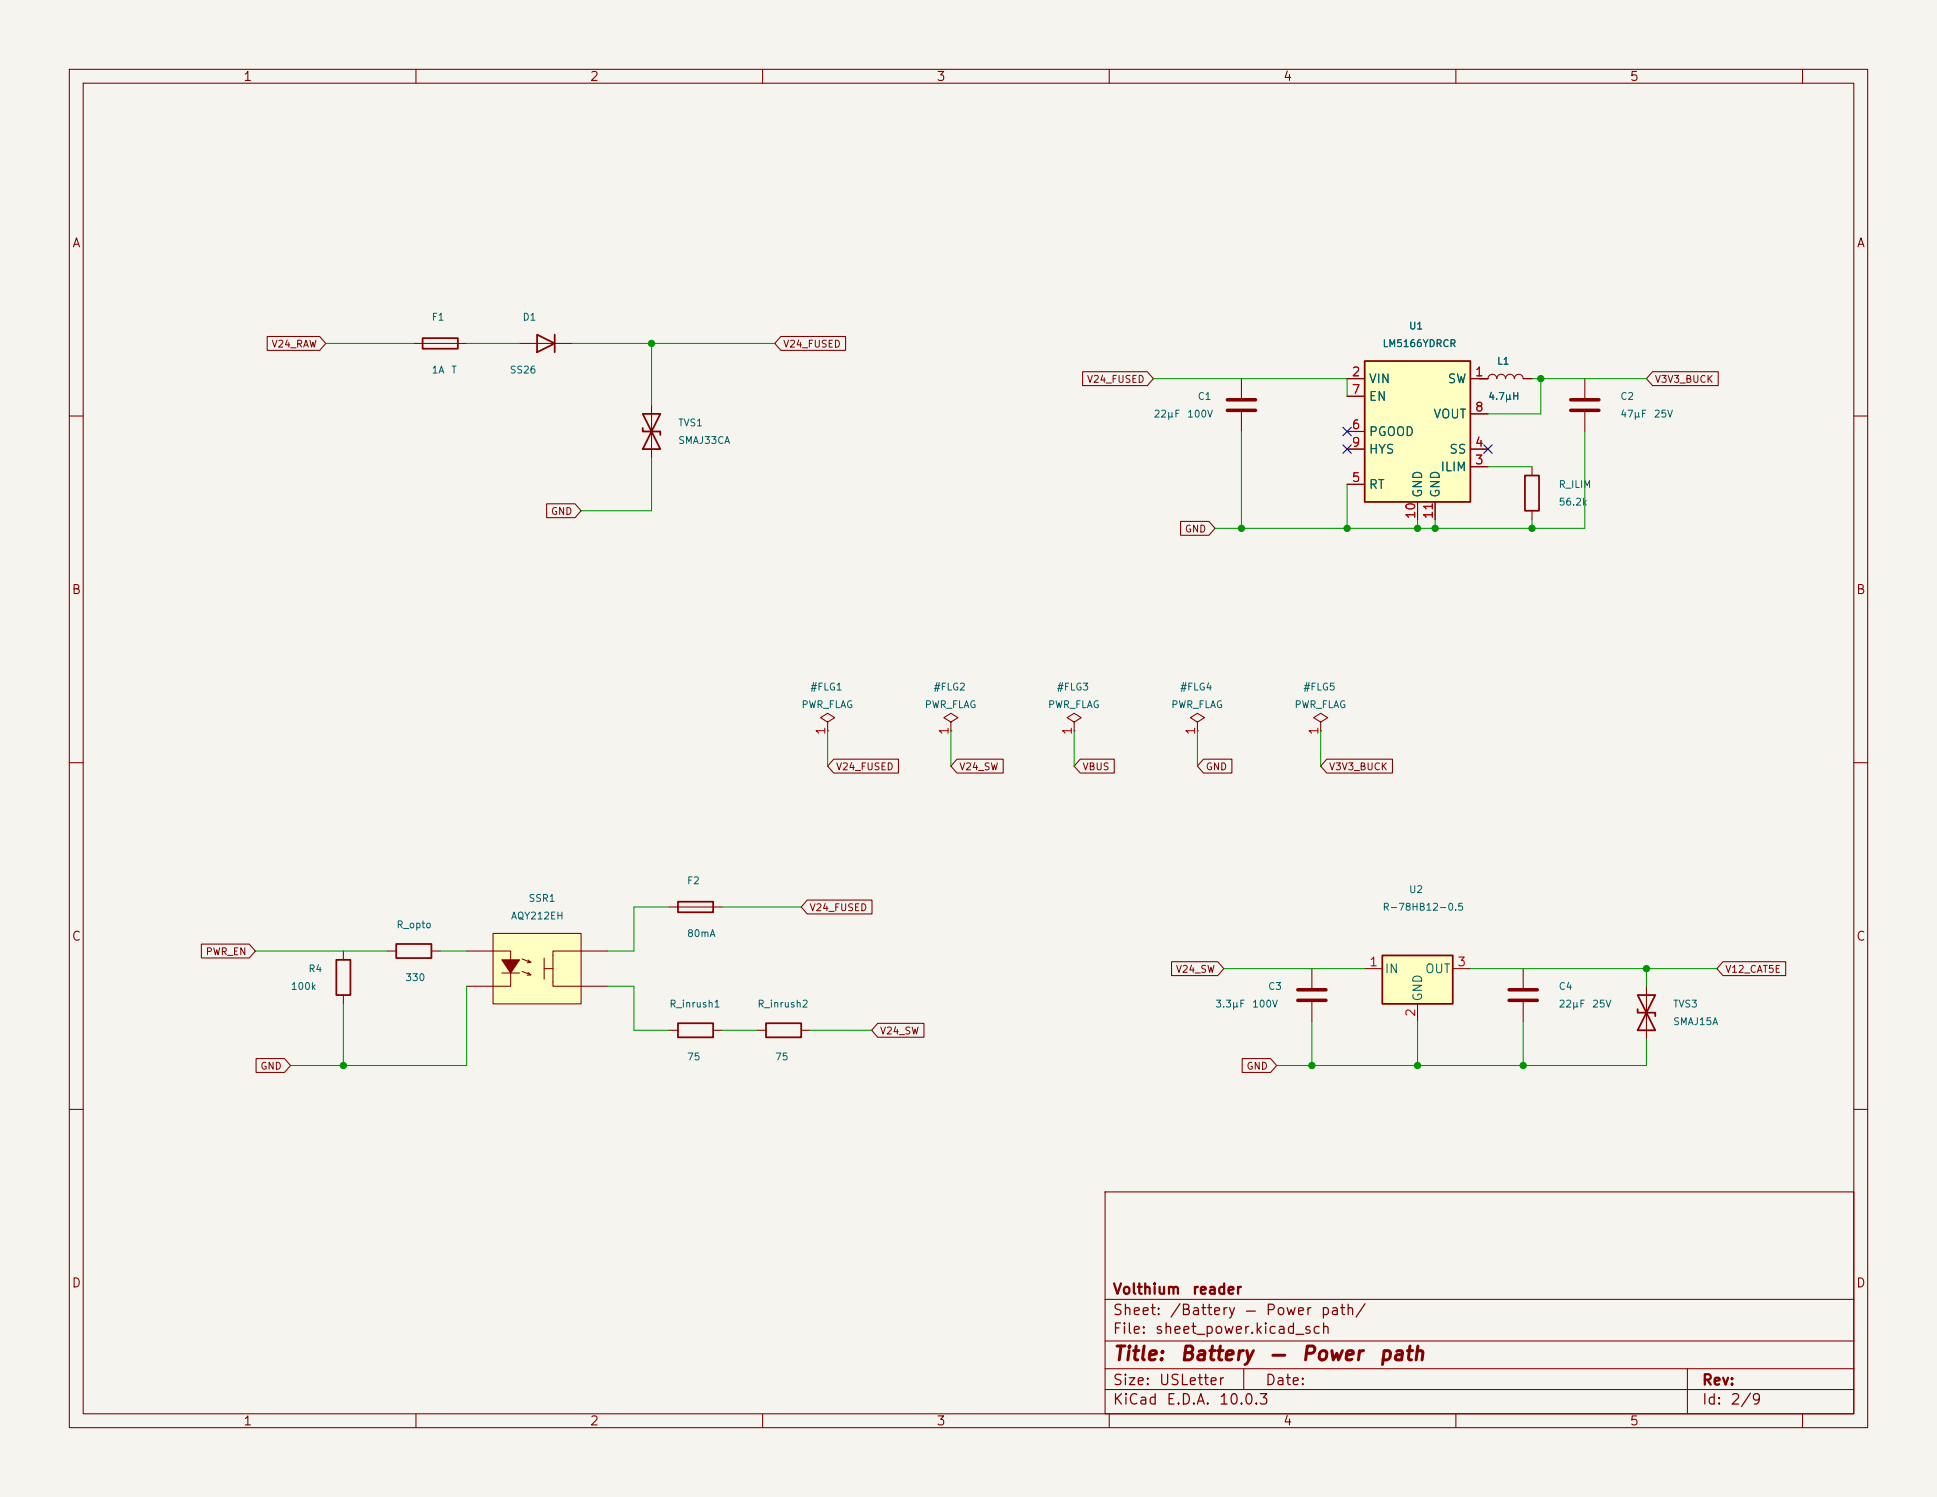
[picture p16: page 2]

Sheet: /Battery — Power path/
File: sheet_power.kicad_sch
Title: Battery — Power path

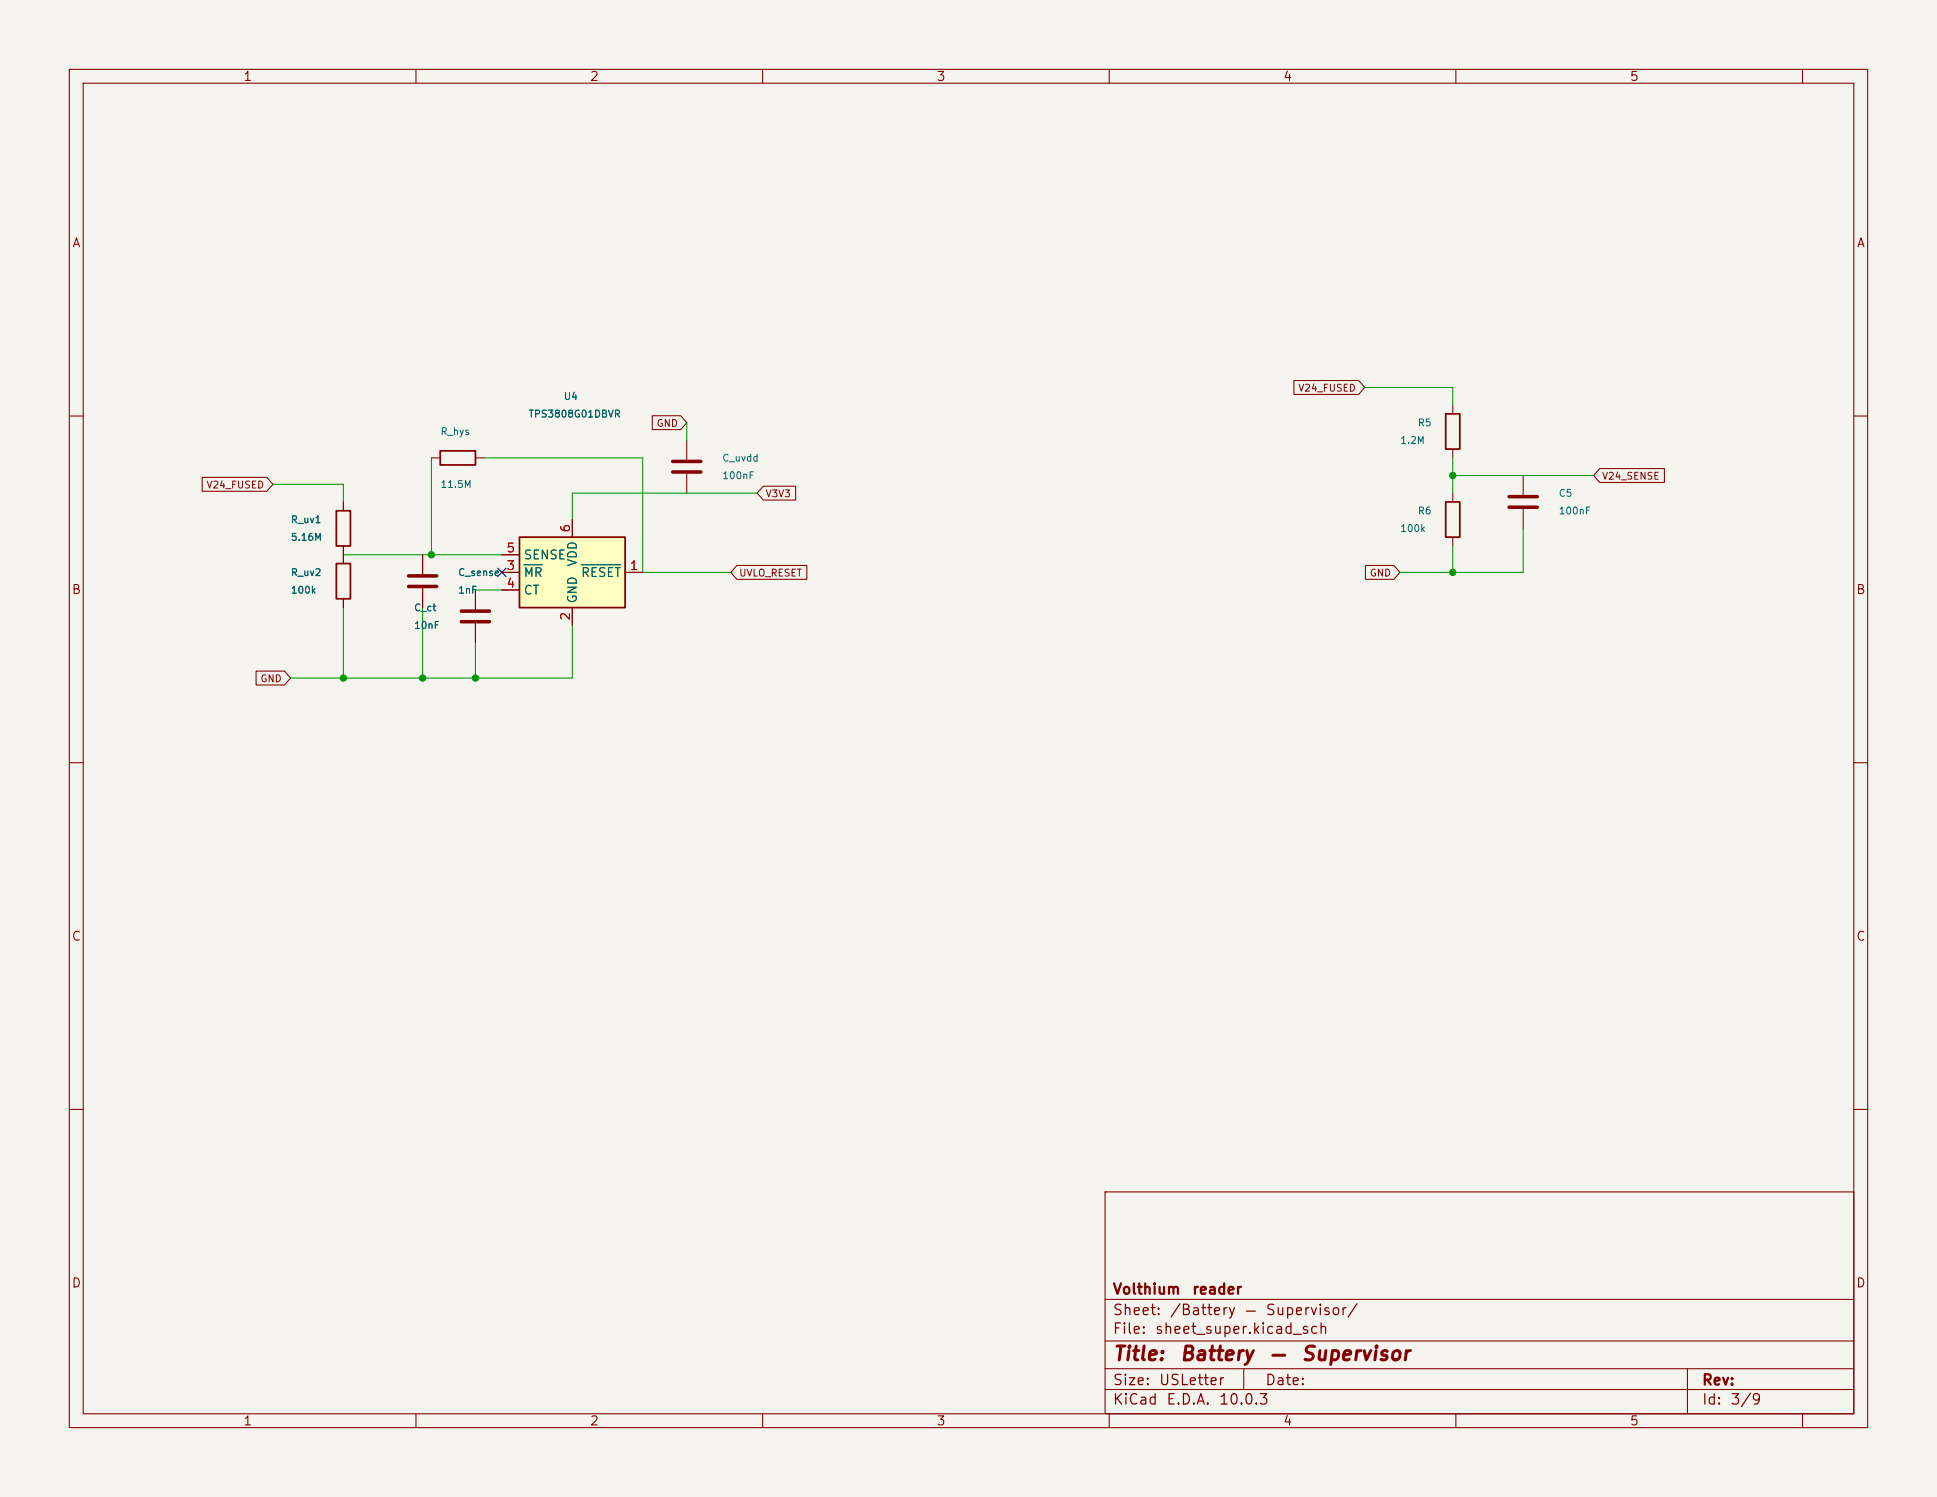
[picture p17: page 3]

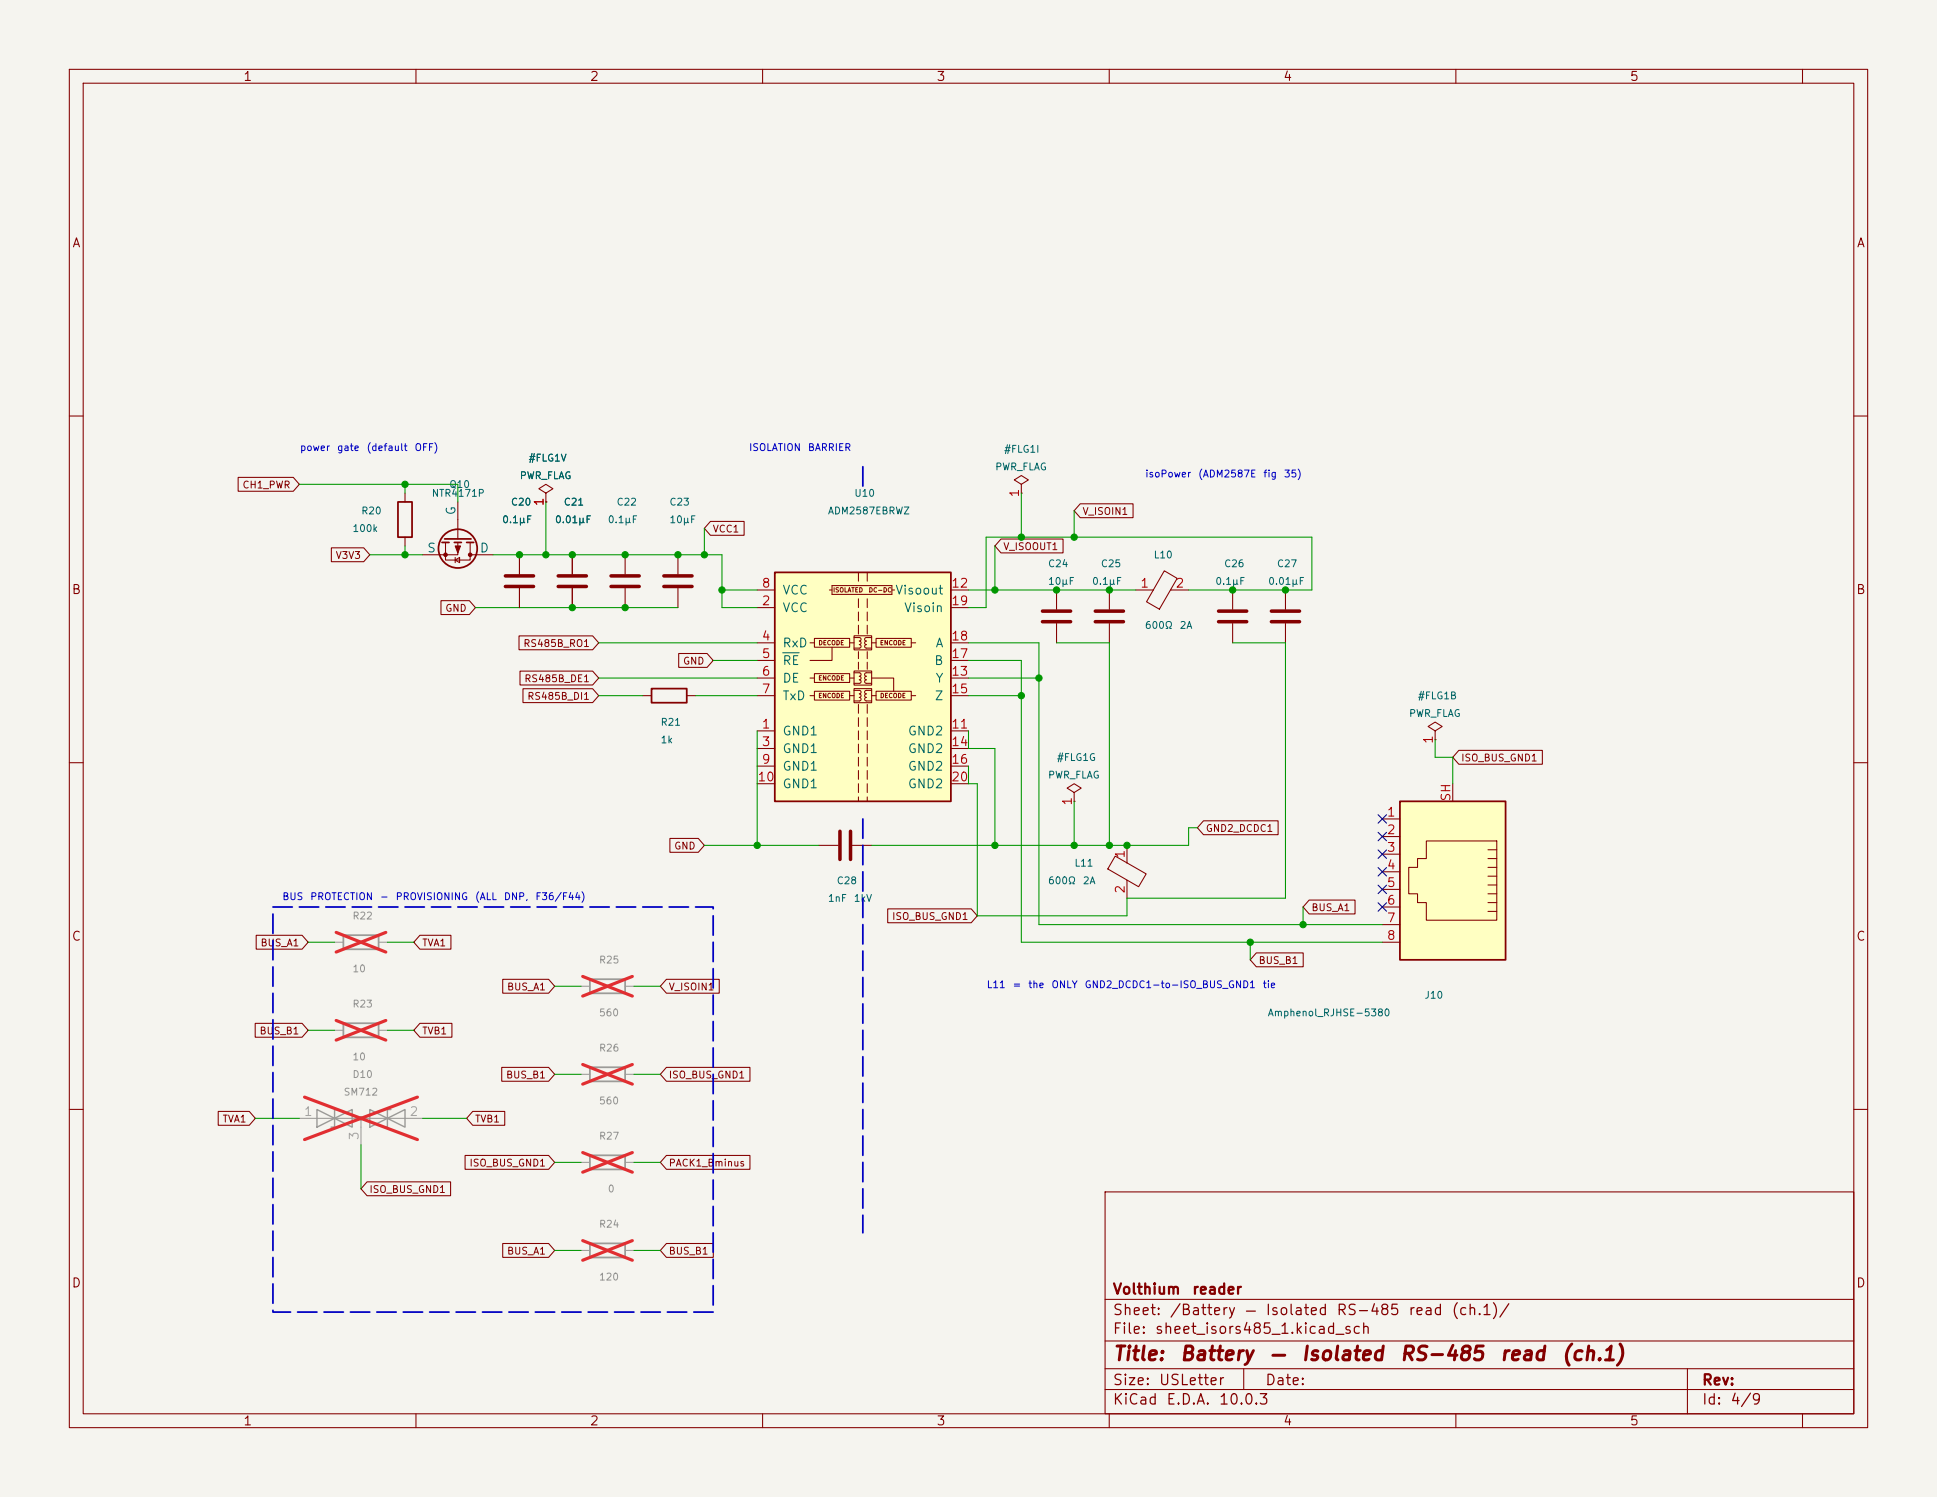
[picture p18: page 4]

isoPower (ADM2587E fig 35) L11 = the ONLY GND2_DCDC1-to-ISO_BUS_GND1 tie
Amphenol_RJHSE-5380 1

BUS PROTECTION - PROVISIONING (ALL DNP, F36/F44)

Volthium reader
Sheet: /Battery — Isolated RS-485 read (ch.1)/
File: sheet_isors485_1.kicad_sch
Title: Battery — Isolated RS-485 read (ch.1)



3 RXD 4 NC 5 CANL 6 CANH 7 NC 8

Volthium reader
Sheet: /Battery — Peripherals & comms/
File: sheet_periph.kicad_sch
Title: Battery — Peripherals & comms


Volthium reader
Sheet: /Battery — USB maintenance power/
File: sheet_usb.kicad_sch
Title: Battery — USB maintenance power


isoPower (ADM2587E fig 35) L13 = the ONLY GND2_DCDC2-to-ISO_BUS_GND2 tie
Amphenol_RJHSE-5380 1

BUS PROTECTION - PROVISIONING (ALL DNP, F36/F44)

Volthium reader
Sheet: /Battery — Isolated RS-485 read (ch.2)/
File: sheet_isors485_2.kicad_sch
Title: Battery — Isolated RS-485 read (ch.2)


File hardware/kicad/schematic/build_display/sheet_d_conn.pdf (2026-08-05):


Size: USLetter | Rev:
KiCad E.D.A. 10.0.3 | Id: 1/1

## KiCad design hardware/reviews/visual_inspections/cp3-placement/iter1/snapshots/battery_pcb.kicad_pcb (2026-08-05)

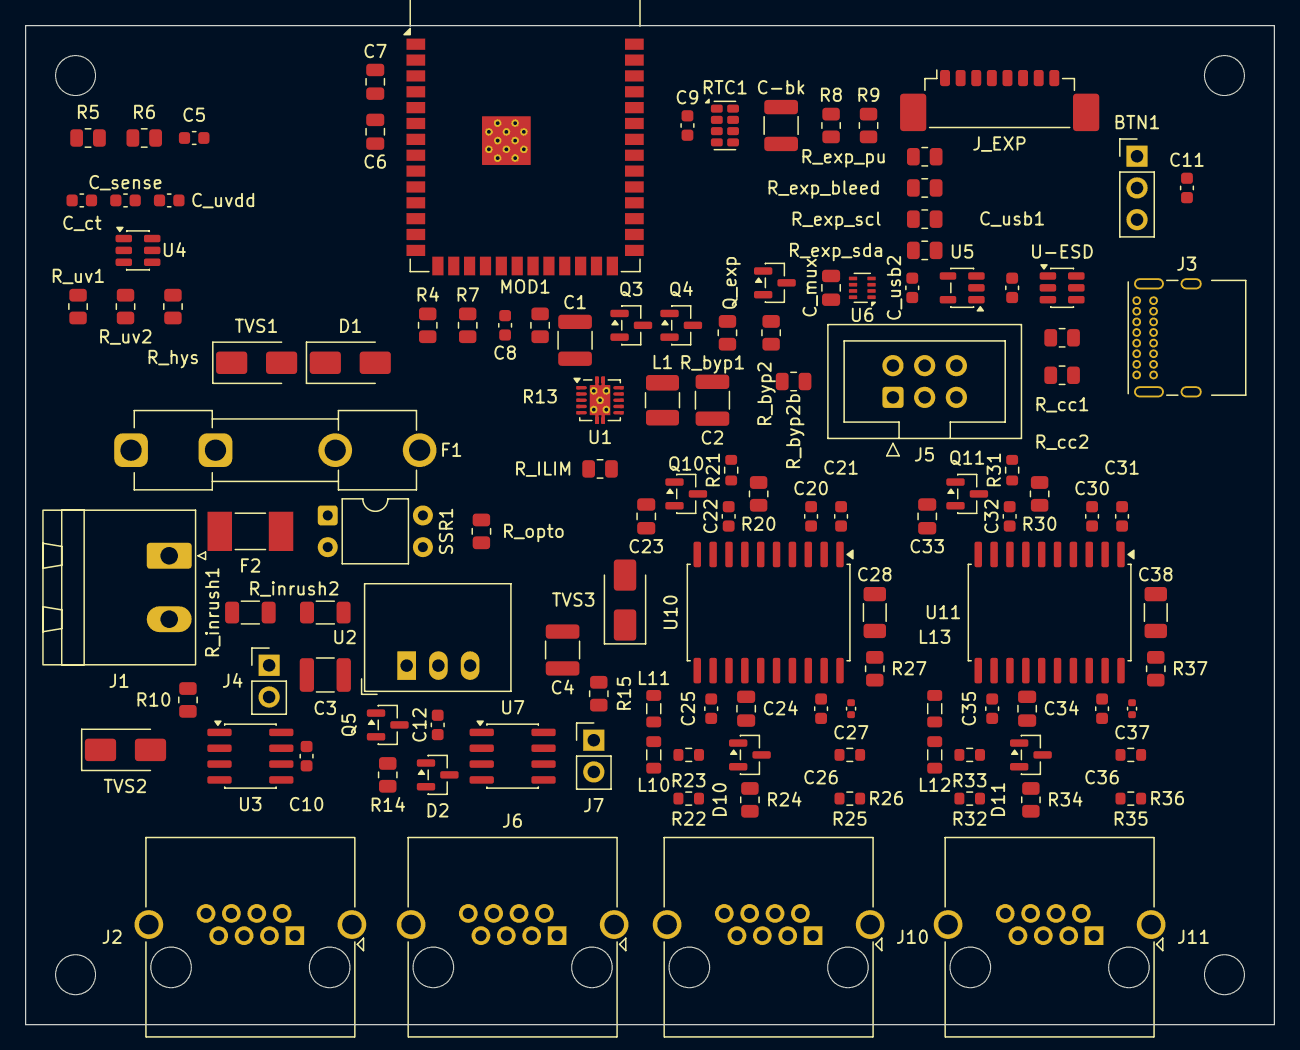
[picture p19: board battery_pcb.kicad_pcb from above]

Board: 2 copper layers, 100.0 x 80.0 mm, 127 parts (0 on the bottom side), 84 nets, no tracks yet.

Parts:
BTN1: C&K_8125SHZBE; PinHeader_1x03_P2.54mm_Vertical
C1: 22µF 100V; C_1210_3225Metric
C2: 47µF 25V; C_1210_3225Metric
C3: 3.3µF 100V; C_1210_3225Metric
C4: 22µF 25V; C_1210_3225Metric
C5, C9, C10, C11, C12: 100nF; C_0603_1608Metric
C6, C23, C24, C33, C34: 10µF; C_0805_2012Metric
C7: 100nF; C_0805_2012Metric
C8: 1µF; C_0603_1608Metric
C20, C22, C25, C26, C30, C32, C35, C36: 0.1µF; C_0603_1608Metric
C21, C31: 0.01µF; C_0603_1608Metric
C27, C37: 0.01µF; C_0402_1005Metric
C28, C38: 1nF 1kV; C_1206_3216Metric
C-bk: 22mF; C_1210_3225Metric
C_ct: 10nF; C_0603_1608Metric
C_mux: 47µF; C_0805_2012Metric
C_sense: 1nF; C_0603_1608Metric
C_usb1, C_usb2: 1µF; C_0603_1608Metric
C_uvdd: 100nF; C_0603_1608Metric
D1: SS26; D_SMA
D2: DNP (F03); SOT-23
D10, D11: SM712; SOT-23
F1: 1A T; Fuseholder_Clip-5x20mm_Keystone_3517_Inline_P23.11x6.76mm_D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
F2: 80mA; Fuse_Littelfuse-NANO2-451_453
H1, H2, H3, H4: M3; MountingHole_3.2mm_M3
J1: Phoenix_MSTBA_2,5-2-G-5,08; PhoenixContact_MSTBA_2,5_2-G-5,08_1x02_P5.08mm_Horizontal
J2, J6, J10, J11: Amphenol_RJHSE-5380; RJ45_Amphenol_RJHSE5380
J3: USB-C 2.0; USB_C_Receptacle_GCT_USB4085
J4, J7: TERM; PinHeader_1x02_P2.54mm_Vertical
J5: ESP-Prog; IDC-Header_2x03_P2.54mm_Vertical
J_EXP: Molex_PicoBlade_53398-0871; Molex_PicoBlade_53398-0871_1x08-1MP_P1.25mm_Vertical
L1: 4.7µH; L_1210_3225Metric
L10, L11, L12, L13: 600Ω 2A; L_0805_2012Metric
MOD1: ESP32-S3-WROOM-1-N16R8; ESP32-S3-WROOM-1_HSvia0.3
Q3, Q4: 2N7002; SOT-23
Q5, Q10, Q11: NTR4171P; SOT-23
Q_exp: NTR4171P; SOT-23
R4, R6, R14, R20, R30: 100k; R_0805_2012Metric
R5: 1.2M; R_0805_2012Metric
R7: 10k; R_0805_2012Metric
R8, R9: 4.7k; R_0805_2012Metric
R10, R15, R24, R34: 120; R_0805_2012Metric
R13: 1M; R_0805_2012Metric
R21, R31: 1k; R_0603_1608Metric
R22, R23, R32, R33: 10; R_0603_1608Metric
R25, R26, R35, R36: 560; R_0603_1608Metric
R27, R37: 0; R_0805_2012Metric
RTC1: RV-3028-C7; MicroCrystal_C7_SON-8_1.5x3.2mm_P0.9mm
R_ILIM: 56.2k; R_0805_2012Metric
R_byp1, R_byp2: 100k; R_0805_2012Metric
R_byp2b: 1M; R_0805_2012Metric
R_cc1, R_cc2: 5.1k; R_0805_2012Metric
R_exp_bleed: 10k; R_0805_2012Metric
R_exp_pu: 100k; R_0805_2012Metric
R_exp_scl: 4.7k; R_0805_2012Metric
R_exp_sda: 4.7k; R_0805_2012Metric
R_hys: 11.5M; R_0805_2012Metric
R_inrush1, R_inrush2: 75; R_1206_3216Metric
R_opto: 330; R_0805_2012Metric
R_uv1: 5.16M; R_0805_2012Metric
R_uv2: 100k; R_0805_2012Metric
SSR1: AQY212EH; DIP-4_W7.62mm
TVS1: SMAJ33CA; D_SMA
TVS2: SMAJ12CA; D_SMA
TVS3: SMAJ15A; D_SMA
U1: LM5166YDRCR; Texas_S-PVSON-N10_ThermalVias
U2: R-78HB12-0.5; Converter_DCDC_RECOM_R-78E-0.5_THT
U3: THVD1400DR; SOIC-8_3.9x4.9mm_P1.27mm
U4: TPS3808G01DBVR; SOT-23-6
U5: AP2112K-3.3; SOT-23-5
U6: TPS2116DRLR; SOT-583-8
U7: TCAN332DR; SOIC-8_3.9x4.9mm_P1.27mm
U10, U11: ADM2587EBRWZ; SOIC-20W_7.5x12.8mm_P1.27mm
U-ESD: USBLC6-2SC6Y; SOT-23-6

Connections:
BOOT: J5.6, MOD1.27
BTN_OVERRIDE: BTN1.2, C11.1, MOD1.7, R13.2
BUS_A1: J10.7, R22.1, R24.1, R25.1, U10.13, U10.18
BUS_A2: J11.7, R32.1, R34.1, R35.1, U11.13, U11.18
BUS_B1: J10.8, R23.1, R24.2, R26.1, U10.15, U10.17
BUS_B2: J11.8, R33.1, R34.2, R36.1, U11.15, U11.17
CAN_PWR: MOD1.35, Q5.1, R14.2
CAN_RXD: MOD1.34, U7.4
CAN_TXD: MOD1.33, U7.1
CH1_PWR: MOD1.22, Q10.1, R20.1
CH2_PWR: MOD1.32, Q11.1, R30.1
DBG_RXD: J5.5, MOD1.36
DBG_TXD: J5.3, MOD1.37
EXP_3V3: J_EXP.2, Q_exp.3, R_exp_bleed.1, R_exp_scl.1, R_exp_sda.1
EXP_AIO1: J_EXP.5, MOD1.15
EXP_AIO2: J_EXP.6, MOD1.5
EXP_DIO3: J_EXP.7, MOD1.31
EXP_PWR_EN: MOD1.20, Q_exp.1, R_exp_pu.2
EXP_SCL: J_EXP.4, MOD1.19, R_exp_scl.2
EXP_SDA: J_EXP.3, MOD1.18, R_exp_sda.2
GND: BTN1.1, C1.2, C2.2, C3.2, C4.2, C5.2, C6.1, C7.1, C8.2, C9.1, C10.2, C11.2, C12.2, C20.2, C21.2, C22.2, C23.2, C28.1, C30.2, C31.2, C32.2, C33.2, C38.1, C-bk.2, C_ct.2, C_mux.2, C_sense.2, C_usb1.2, C_usb2.2, C_uvdd.1, D2.3, J1.2, J2.6, J2.7, J2.8, J2.SH, J3.A1, J3.A12, J3.B1, J3.B12, J3.SH, J5.4, J6.SH, J_EXP.1, J_EXP.8, MOD1.1, MOD1.40, MOD1.41, Q4.2, R4.2, R6.2, RTC1.5, RTC1.8, R_ILIM.2, R_byp2b.2, R_cc1.2, R_cc2.2, R_exp_bleed.2, R_uv2.2, SSR1.2, TVS1.1, TVS3.1, U1.5, U1.10, U1.11, U2.2, U3.5, U4.2, U5.2, U6.1, U7.2, U10.1, U10.3, U10.5, U10.9, U10.10, U11.1, U11.3, U11.5, U11.9, U11.10, U-ESD.2
GND2_DCDC1: C24.2, C25.2, C28.2, L11.1, U10.11, U10.14
GND2_DCDC2: C34.2, C35.2, C38.2, L13.1, U11.11, U11.14
I2C_SCL: MOD1.17, R9.2, RTC1.3
I2C_SDA: MOD1.12, R8.2, RTC1.4
ISO_BUS_GND1: C26.2, C27.2, D10.3, J10.SH, L11.2, R26.2, R27.1, U10.16, U10.20
ISO_BUS_GND2: C36.2, C37.2, D11.3, J11.SH, L13.2, R36.2, R37.1, U11.16, U11.20
MCU_EN: C8.1, J5.1, MOD1.3, Q3.3, R7.2
unnamed: D1.2, F1.2
unnamed: F2.1, SSR1.4
unnamed: J3.A5, R_cc1.1
unnamed: J3.B5, R_cc2.1
unnamed: J4.1, R10.2
unnamed: J7.1, R15.2
unnamed: Q3.1, Q4.3, R_byp1.2
unnamed: Q4.1, R_byp2.2, R_byp2b.1
unnamed: C12.1, Q5.3, U7.3
unnamed: C-bk.1, RTC1.6
unnamed: R_inrush1.1, SSR1.3
unnamed: R_inrush1.2, R_inrush2.1
unnamed: R_opto.2, SSR1.1
unnamed: R_ILIM.1, U1.3
unnamed: L1.1, U1.1
unnamed: C_ct.1, U4.4
unnamed: C_sense.1, R_hys.1, R_uv1.2, R_uv2.1, U4.5
unnamed: C_usb2.1, U5.5, U6.3, U6.4, U6.5
unnamed: D2.2, J6.5, R15.1, U7.7
unnamed: D2.1, J6.4, J7.2, U7.6
unnamed: R21.2, U10.7
unnamed: R31.2, U11.7
PWR_EN: MOD1.4, R4.1, R_opto.1
RS485B_DE1: MOD1.21, U10.6
RS485B_DE2: MOD1.25, U11.6
RS485B_DI1: MOD1.6, R21.1
RS485B_DI2: MOD1.23, R31.1
RS485B_RO1: MOD1.9, U10.4
RS485B_RO2: MOD1.24, U11.4
RS485_A: J2.4, R10.1, TVS2.2, U3.6
RS485_B: J2.5, J4.2, TVS2.1, U3.7
RS485_DE: MOD1.38, U3.3
RS485_DI: MOD1.10, U3.4
RS485_RO: MOD1.11, U3.1
RS485_nRE: MOD1.8, U3.2
TVA1: D10.1, R22.2
TVA2: D11.1, R32.2
TVB1: D10.2, R23.2
TVB2: D11.2, R33.2
USB_DM: J3.A7, J3.B7, MOD1.13, U-ESD.3
USB_DP: J3.A6, J3.B6, MOD1.14, U-ESD.1
UVLO_RESET: Q3.2, R_hys.2, U4.1
V3V3: C6.2, C7.2, C9.2, C10.1, C_mux.1, C_uvdd.2, J5.2, MOD1.2, Q5.2, Q10.2, Q11.2, Q_exp.2, R7.1, R8.1, R9.1, R13.1, R14.1, R20.2, R30.2, RTC1.7, R_byp1.1, R_exp_pu.1, U3.8, U4.6, U6.2, U6.7
V3V3_BUCK: C2.1, L1.2, U1.8, U6.6
V12_CAT5E: C4.1, J2.1, J2.2, J2.3, TVS3.2, U2.3
V24_FUSED: C1.1, D1.1, F2.2, R5.1, R_uv1.1, TVS1.2, U1.2, U1.7
V24_RAW: F1.1, J1.1
V24_SENSE: C5.1, MOD1.39, R5.2, R6.1
V24_SW: C3.1, R_inrush2.2, U2.1
VBUS: C_usb1.1, J3.A4, J3.A9, J3.B4, J3.B9, R_byp2.1, U5.1, U5.3, U-ESD.5
VCC1: C20.1, C21.1, C22.1, C23.1, Q10.3, U10.2, U10.8
VCC2: C30.1, C31.1, C32.1, C33.1, Q11.3, U11.2, U11.8
V_ISOIN1: C26.1, C27.1, L10.2, R25.2, U10.19
V_ISOIN2: C36.1, C37.1, L12.2, R35.2, U11.19
V_ISOOUT1: C24.1, C25.1, L10.1, U10.12
V_ISOOUT2: C34.1, C35.1, L12.1, U11.12

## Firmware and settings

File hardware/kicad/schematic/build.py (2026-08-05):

#!/usr/bin/env python3
"""CP2 schematic — BATTERY-side board entry point (volthium_reader project).

All mechanics (symbol sourcing, geometry, Sheet, and the full gate stack:
readability/glyph/title-block, netlist intent==actual, GOLDEN contracts,
exact-part variants, strict full ERC) live in core.py, shared with the
display-side entry point (build_display.py). This file holds only what is
THIS board's design: the block drawings, the sheet composition, and the
per-board contract tables (GOLDEN / EXACT_PARTS / ERC_ACCEPTED).

Run: <repo>/.venv/bin/python build.py   (from this directory; packet §1)
"""
import sys

import core
from core import Sheet, snap

def blk_pwr_flags(s, cx, cy):
    """PWR_FLAGs: tell ERC these nets ARE driven, even though their local source
    is passive (V24_FUSED past D1, V24_SW past the SSR) or a board-input
    connector (VBUS from USB-C), plus the global GND reference."""
    for i, net in enumerate(("V24_FUSED", "V24_SW", "VBUS", "GND", "V3V3_BUCK")):
        x = snap(cx + i*17.78)
        # tanchor="u" (display-iter1 F15 class): value text above the glyph,
        # clear of the net-label flag below.
        pf = s.place("PWR_FLAG", f"#FLG{i+1}", "PWR_FLAG", "", (x, cy), angle=0, tanchor="u")
        pin = pf["1"]
        s.wire(pin, (pin[0], snap(pin[1] + 5.08)))
        s.label(net, (pin[0], snap(pin[1] + 5.08)), justify_h="left")


def blk_input_protection(s, cx, cy):
    """V24_RAW (from J1) -> F1 (1A T) -> D1 (SS26 reverse-polarity) -> V24_FUSED;
    TVS1 (SMAJ33CA) clamp to GND. The input-bulk/buck-input cap is C1 in the
    buck block (same V24_FUSED net). Translated onto (cx,cy) = block centre."""
    ox, oy = cx - snap(78.1), cy - snap(100.97)      # translate the validated layout
    yr, yg = snap(88.9 + oy), snap(113.03 + oy)
    xin, xf1, xd1, xnod, xout = [snap(v + ox) for v in (46.99, 63.5, 78.74, 93.98, 111.76)]
    leftp  = lambda pp: min(pp.values(), key=lambda xy: xy[0])
    rightp = lambda pp: max(pp.values(), key=lambda xy: xy[0])
    topp   = lambda pp: min(pp.values(), key=lambda xy: xy[1])
    botp   = lambda pp: max(pp.values(), key=lambda xy: xy[1])
    # F1 = 5x20 cartridge (0215001.MXP) in Keystone 3517 clips — the clip
    # footprint IS the PCB land (BOM row F1).
    f1 = s.place("Fuse", "F1", "1A T",
                 "Fuse:Fuseholder_Clip-5x20mm_Keystone_3517_Inline_P23.11x6.76mm_D1.70mm_Horizontal",
                 (xf1, yr), angle=90, tanchor="ud")
    # D1 = SERIES reverse-polarity protector: anode toward the source (V24_RAW),
    # cathode toward the load. The `D` symbol is cathode(pin1)-left, so rotate 180°.
    d1 = s.place("D", "D1", "SS26", "D_SMA", (xd1, yr), angle=180, tanchor="ud")
    tv = s.place("D_TVS", "TVS1", "SMAJ33CA", "D_SMA", (xnod, snap(yr+12.7)), angle=90, tanchor="r")
    s.label("V24_RAW", (xin, yr), justify_h="right")     # input from J1
    s.wire((xin, yr), f1["1"]); s.wire(f1["2"], leftp(d1))       # F1 → D1 anode
    s.wire(rightp(d1), (xnod, yr))                                # D1 cathode = V24_FUSED node
    s.wire((xnod, yr), (xout, yr)); s.label("V24_FUSED", (xout, yr), justify_h="left")  # output
    s.wire((xnod, yr), topp(tv)); s.wire(botp(tv), (xnod, yg))    # TVS1 clamp to GND
    s.label("GND", (snap(xnod-10.16), yg), justify_h="right")
    s.wire((snap(xnod-10.16), yg), (xnod, yg))


def blk_always_on_power(s, cx, cy):
    """Always-on 3V3 rail: U1 LM5166Y (24V->3V3 sync buck, PFM, ultra-low Iq).
    Design verified against LM5166 datasheet (Design 3, 24V/3.3V PFM):
      EN->VIN direct tie (rec-op 65V >= 53.3V clamp; 'connect EN directly to
      VIN', p.21); RT->GND selects PFM (lowest light-load Iq); R_ILIM 56.2k =>
      750mA peak / 300mA IOUT (Table 3); SS/HYS/PGOOD open; L1 4.7uH Isat>=2.2A;
      C1 22uF/100V (Vin, behind clamp); C2 47uF/25V (Eq 31 margin). Net in:
      V24_FUSED; net out: V3V3_BUCK (-> USB mux U6 VIN2); GND. (cx,cy)=U1."""
    y_gnd = snap(cy + 13.97)
    u1 = s.place("LM5166Y", "U1", "LM5166YDRCR", "Package_SON:Texas_S-PVSON-N10_ThermalVias",
                 (cx, cy), angle=0, tanchor="u")
    VIN, EN, PGOOD, HYS = u1["2"], u1["7"], u1["6"], u1["9"]
    RT, SW, VOUT, SS, ILIM, GND = u1["5"], u1["1"], u1["8"], u1["4"], u1["3"], u1["10"]
    y_in = VIN[1]

    # ---- input: V24_FUSED rail -> VIN, with C1 tap to GND ----
    xlbl_in = snap(cx - 38.1)
    xc1 = snap(cx - 25.4)
    c1 = s.place("C", "C1", "22µF 100V", "C_1210_3225Metric",
                 (xc1, snap(y_in + 3.81)), angle=0, tanchor="l")   # top pin on the rail
    s.label("V24_FUSED", (xlbl_in, y_in), justify_h="right")
    s.wire((xlbl_in, y_in), c1["1"])                   # label -> C1 top (rail split at pin)
    s.wire(c1["1"], VIN)                               # C1 top -> VIN pin
    s.wire(c1["2"], (xc1, y_gnd))                      # C1 bottom -> GND rail

    # ---- EN tied directly to VIN (self-start whenever pack present) ----
    s.wire(EN, VIN)

    # ---- output: SW -> L1 -> VOUT node -> V3V3, C2 tap, VOUT sense ----
    xL = snap(cx + 12.7)
    l1 = s.place("L", "L1", "4.7µH", "L_1210_3225Metric",
                 (xL, y_in), angle=90, tanchor="ud", bw=7.62)
    lL = min(l1.values(), key=lambda p: p[0]); lR = max(l1.values(), key=lambda p: p[0])
    s.wire(SW, lL)
    xsense = snap(cx + 17.78)                          # VOUT-sense tap node on rail
    xc2 = snap(cx + 24.13)
    xlbl_out = snap(cx + 33.02)
    s.wire(lR, (xsense, y_in))                         # L1 -> sense node
    s.wire((xsense, y_in), (xc2, y_in))                # -> C2 tap
    s.wire((xc2, y_in), (xlbl_out, y_in))              # -> V3V3_BUCK (into the USB mux U6 VIN2)
    s.label("V3V3_BUCK", (xlbl_out, y_in), justify_h="left")
    c2 = s.place("C", "C2", "47µF 25V", "C_1210_3225Metric",
                 (xc2, snap(y_in + 3.81)), angle=0, tanchor="r")
    s.wire(c2["2"], (xc2, y_gnd))                      # C2 bottom -> GND rail
    # fixed-3.3V feedback: VOUT pin senses the output node
    s.wire(VOUT, (xsense, VOUT[1])); s.wire((xsense, VOUT[1]), (xsense, y_in))

    # ---- RT -> GND (PFM), ILIM -> R_ILIM -> GND (offset right, clear of U1) ----
    s.wire(RT, (RT[0], y_gnd))
    xr = snap(ILIM[0] + 6.35)
    rilim = s.place("R", "R_ILIM", "56.2k", "R_0805_2012Metric",
                    (xr, snap(ILIM[1] + 3.81)), angle=0, tanchor="r")
    s.wire(ILIM, rilim["1"]); s.wire(rilim["2"], (xr, y_gnd))   # ILIM->R->GND

    # ---- GND rail across the bottom + label ----
    xg_l = snap(cx - 29.21)
    s.wire((xg_l, y_gnd), (xc2, y_gnd))
    s.wire(GND, (GND[0], y_gnd))                       # U1 GND drop
    s.wire(u1["11"], (u1["11"][0], y_gnd))             # thermal pad (pin 11) drop
    s.label("GND", (xg_l, y_gnd), justify_h="right")

    # ---- intentionally-open pins ----
    for p in (PGOOD, HYS, SS):
        s.no_connect(p)


def blk_rs485(s, cx, cy):
    """RS-485 half-duplex transceiver to the display side (U3 THVD1400, D34).
    Control (RO/nRE/DE/DI) -> MCU; differential A/B -> Cat5e, with the 120 Ohm
    terminator R10 and differential TVS2 across A-B; C10 decoupling. No idle
    bias (THVD1400 full fail-safe RX; DR-4b/F12). VCC = V3V3. (cx,cy)=U3 centre."""
    u3 = s.place("THVD1400D", "U3", "THVD1400DR", "Package_SO:SOIC-8_3.9x4.9mm_P1.27mm",
                 (cx, cy), angle=0, tanchor="u", tgap=5.08)
    RO, nRE, DE, DI = u3["1"], u3["2"], u3["3"], u3["4"]
    GND, A, B, VCC = u3["5"], u3["6"], u3["7"], u3["8"]

    # ---- control signals -> MCU (left) ----
    xlbl = snap(cx - 25.4)
    for pin, net in ((RO, "RS485_RO"), (nRE, "RS485_nRE"), (DE, "RS485_DE"), (DI, "RS485_DI")):
        s.label(net, (xlbl, pin[1]), justify_h="right")
        s.wire((xlbl, pin[1]), pin)

    # ---- VCC (top) -> V3V3 rail; C10 decoupling hangs off it, clear of the body ----
    yv = snap(VCC[1] - 3.81)                          # VCC rail just above the pin
    xc10 = snap(cx - 20.32)                           # left of the body (clear)
    xv3 = snap(cx - 27.94)
    s.wire(VCC, (VCC[0], yv))
    s.wire((VCC[0], yv), (xc10, yv)); s.wire((xc10, yv), (xv3, yv))
    s.label("V3V3", (xv3, yv), justify_h="right")
    c10 = s.place("C", "C10", "100nF", "C_0603_1608Metric",
                  (xc10, snap(yv + 3.81)), angle=0, tanchor="l")   # top pin on VCC rail
    ygc = snap(c10["2"][1] + 2.54)
    s.wire(c10["2"], (xc10, ygc)); s.label("GND", (xc10, ygc), justify_h="right")

    # ---- GND (bottom) -> local GND ----
    ygp = snap(GND[1] + 2.54)
    s.wire(GND, (GND[0], ygp)); s.label("GND", (GND[0], ygp), justify_h="left")

    # ---- A/B bus (right): term (R10 in series with J4 term-lift jumper) + TVS2
    #      bridge A-B, then to Cat5e. J4 open = 120R termination lifted. ----
    yA, yB = A[1], snap(A[1] + 15.24)                 # wide bridge for R10 + J4 in series
    xstep = snap(cx + 12.7)
    xbr1, xbr2, xlblB = snap(cx + 17.78), snap(cx + 33.02), snap(cx + 45.72)
    s.wire(A, (xbr1, yA))                             # A rail
    s.wire(B, (xstep, B[1]))                          # B out, then step down to yB
    s.wire((xstep, B[1]), (xstep, yB)); s.wire((xstep, yB), (xbr1, yB))
    nT = snap(yA + 7.62)                              # R10 <-> J4 term node
    r10 = s.place("R", "R10", "120", "R_0805_2012Metric",
                  (xbr1, snap(yA + 3.81)), angle=0, tanchor="r", bw=2.0)   # top=yA rail, bot=nT
    j4 = s.place("Conn_01x02", "J4", "TERM",
                 "Connector_PinHeader_2.54mm:PinHeader_1x02_P2.54mm_Vertical",
                 (snap(xbr1 + 5.08), snap(yA + 10.16)), angle=0, tanchor="r")
    j4t = min(j4.values(), key=lambda p: p[1]); j4b = max(j4.values(), key=lambda p: p[1])
    s.wire((xbr1, nT), j4t); s.wire(j4b, (xbr1, yB))             # R10 bot -> J4 -> B rail
    tvs = s.place("D_TVS", "TVS2", "SMAJ12CA", "D_SMA", (xbr2, snap((yA + yB) / 2)), angle=90, tanchor="r")
    tvT = min(tvs.values(), key=lambda p: p[1]); tvB = max(tvs.values(), key=lambda p: p[1])
    s.wire((xbr1, yA), (xbr2, yA)); s.wire((xbr2, yA), (xlblB, yA))   # A -> label
    s.wire((xbr1, yB), (xbr2, yB)); s.wire((xbr2, yB), (xlblB, yB))   # B -> label
    s.wire((xbr2, yA), tvT); s.wire((xbr2, yB), tvB)                  # TVS2 across A-B
    s.label("RS485_A", (xlblB, yA), justify_h="left")
    s.label("RS485_B", (xlblB, yB), justify_h="left")


def blk_can(s, cx, cy):
    """Xanbus CAN read (DR-31, provisioned). U7 TCAN332 3.3 V CAN transceiver
    (±12 V CM, 12 kV IEC ESD, bus high-Z when unpowered — TCAN33x DS SLLSEQ7F);
    TWAI on the ESP32-S3 (CAN_TXD/CAN_RXD = IO40/41). Q5 P-FET power gate
    (CAN_PWR = IO42, active-LOW, 100k default-OFF pull-up) -> zero draw parked
    AND high-Z bus pins, so the sleeping reader never loads the live Xanbus.
    Termination: R15 120R in series with J7 jumper (fitted = terminated) — the
    reader is only a chain END when it's at an end. D2 = DNP TVS footprint
    (F03: no clamp can bracket TCAN332's ±14 V abs-max — see D2 comment).
    J6 RJ45: Xanbus CAN_L = pin 4, CAN_H = pin 5, no ground pin — the network
    and reader already share the 24 V bank negative (LYNK II manual 805-0052
    §4.2.1, same battery-side-gateway topology). NET-power pins NC — Xanbus
    carries its own supply, never touch it. (cx,cy) = U7 centre."""
    u7 = s.place("TCAN332", "U7", "TCAN332DR", "Package_SO:SOIC-8_3.9x4.9mm_P1.27mm",
                 (cx, cy), angle=0, tanchor="u", tgap=8.89)   # text above the gated rail
    TXD, GND2, VCC3, RXD = u7["1"], u7["2"], u7["3"], u7["4"]
    CANL, CANH = u7["6"], u7["7"]
    s.no_connect(u7["5"]); s.no_connect(u7["8"])

    # ---- MCU signals (left) ----
    xlbl = snap(cx - 25.4)
    for pin, net in ((TXD, "CAN_TXD"), (RXD, "CAN_RXD")):
        s.label(net, (xlbl, pin[1]), justify_h="right")
        s.wire((xlbl, pin[1]), pin)

    # ---- power gate (top right): V3V3 -> Q5 S..D -> VCC drop.
    # PROBE-VERIFIED pin sides (angle 90): S=pin2 RIGHT, D=pin3 LEFT, G=pin1
    # BOTTOM. (The first cut hand-derived the 270-degree sides, got S/D
    # swapped, and both rail wires spanned across both pins — the pin-interior
    # junction rule then fused source to drain and U7 VCC sat permanently on
    # V3V3. User-caught: 'is that how its wired?'. The [part-short] netlist
    # rule now fails the build on any FET with two pins sharing a net.) ----
    yv = snap(cy - 17.78)                              # gated-rail row
    xq = snap(cx + 17.78)
    q5 = s.place("Q_PMOS_GSD", "Q5", "NTR4171P", "Package_TO_SOT_SMD:SOT-23",
                 (xq, snap(yv + 2.54)), angle=90, tanchor="l", bw=9.0)
    qS, qD, qG = q5["2"], q5["3"], q5["1"]             # 90: S right, D left, G bottom
    xv3 = snap(xq + 17.78)
    s.wire(qS, (xv3, yv)); s.label("V3V3", (xv3, yv), justify_h="left")
    s.wire(qD, (cx, yv)); s.wire((cx, yv), VCC3)       # gated rail -> VCC pin
    # PWR_FLAG: the gated rail is fed through Q5 (passive per ERC) — declare it
    xpf = snap(cx + 7.62)
    pf = s.place("PWR_FLAG", "#FLG_CAN", "PWR_FLAG", "", (xpf, snap(yv - 7.62)),
                 angle=0, tanchor="u")
    s.wire(pf["1"], (xpf, yv))
    # gate line BELOW (G exits bottom): G --- R14 bottom --- CAN_PWR label.
    # R14 100k hangs from the V3V3 rail down to the gate line (default-OFF).
    ygl = qG[1]
    xr14 = snap(xq + 12.7)
    r14 = s.place("R", "R14", "100k", "R_0805_2012Metric",
                  (xr14, snap((yv + ygl) / 2)), angle=0, tanchor="l", bw=2.0)
    s.wire(r14["1"], (xr14, yv))                       # top -> V3V3 rail (junction)
    s.wire(r14["2"], (xr14, ygl))                      # bottom -> gate line
    xpw = snap(xv3 + 5.08)
    s.wire(qG, (xr14, ygl)); s.wire((xr14, ygl), (xpw, ygl))
    s.label("CAN_PWR", (xpw, ygl), justify_h="left")
    # C12 decoupling on the GATED rail: own drop column left of the body
    xcc = snap(cx - 12.7)
    s.wire((cx, yv), (xcc, yv))
    c12 = s.place("C", "C12", "100nF", "C_0603_1608Metric",
                  (xcc, snap(yv + 3.81)), angle=0, tanchor="l")
    xgc = snap(cx - 20.32)
    s.wire(c12["2"], (xgc, c12["2"][1]))
    s.label("GND", (xgc, c12["2"][1]), justify_h="right")

    # ---- GND (bottom) ----
    ygp = snap(GND2[1] + 2.54)
    s.wire(GND2, (GND2[0], ygp)); s.label("GND", (GND2[0], ygp), justify_h="left")

    # ---- bus (right): H/L rails, R15+J7 term-lift bridge, D2 TVS, J6 RJ45 ----
    yH = CANH[1]; yL = CANL[1]; yLo = snap(yH + 15.24)  # widened L rail (term bridge)
    xstep = snap(cx + 17.78)
    xbr = snap(cx + 25.4)
    s.wire(CANH, (xbr, yH))                            # H rail
    s.wire(CANL, (xstep, yL)); s.wire((xstep, yL), (xstep, yLo))
    s.wire((xstep, yLo), (xbr, yLo))                   # L rail (stepped down)
    nT = snap(yH + 7.62)                               # R15 <-> J7 node
    r15 = s.place("R", "R15", "120", "R_0805_2012Metric",
                  (xbr, snap(yH + 3.81)), angle=0, tanchor="l", bw=2.0)
    j7 = s.place("Conn_01x02", "J7", "TERM",
                 "Connector_PinHeader_2.54mm:PinHeader_1x02_P2.54mm_Vertical",
                 (snap(xbr + 5.08), snap(yH + 10.16)), angle=0, tanchor="r")
    j7t = min(j7.values(), key=lambda p: p[1]); j7b = max(j7.values(), key=lambda p: p[1])
    s.wire((xbr, nT), j7t); s.wire(j7b, (xbr, yLo))    # R15 -> J7 -> L rail
    # D2 TVS footprint — DNP (CP2 F03): NUP2105L is a 24 V-system CAN
    # protector (VBR 26.2-32 V, clamp to 40-44 V) and cannot bracket the
    # TCAN332's +/-14 V bus abs-max; no TVS both stands off the +/-12 V CM
    # and clamps <14 V. Protection = TCAN332 on-chip 12 kV IEC contact ESD
    # (same no-coordination-claimed call as the RS-485 ports, F44).
    xtv = snap(xbr + 17.78)
    dv = s.place("NUP2105L", "D2", "DNP (F03)", "Package_TO_SOT_SMD:SOT-23",
                 (xtv, snap((yH + yLo) / 2)), angle=90, tanchor="ud", tgap=1.27,
                 dnp=True)
    kU = min((dv["1"], dv["2"]), key=lambda p: p[1]); kD = max((dv["1"], dv["2"]), key=lambda p: p[1])
    s.wire((xbr, yH), (kU[0], yH)); s.wire((kU[0], yH), kU)        # H -> upper K
    s.wire((xbr, yLo), (kD[0], yLo)); s.wire((kD[0], yLo), kD)     # L -> lower K
    xa = snap(dv["3"][0] + 2.54)
    s.wire(dv["3"], (xa, dv["3"][1]))
    s.label("GND", (xa, dv["3"][1]), justify_h="left") # A -> GND, level (no rail crossing)
    # J6 RJ45 mirrored (angle 180 -> pins face the incoming rails).
    # CAN_H -> pin 5, CAN_L -> pin 4 (Xanbus). The pins interleave with the
    # rail order (top rail H -> LOWER pin 5, bottom rail L -> UPPER pin 4), so
    # orthogonal routing has exactly one conventional X-crossing (no junction
    # = no connection).
    xj = snap(cx + 71.12)
    j6 = s.place("RJ45_Shielded", "J6", "Amphenol_RJHSE-5380",
                 "Connector_RJ:RJ45_Amphenol_RJHSE5380", (xj, cy),
                 angle=180, tanchor="d", bh=30.48)
    jp5, jp4 = j6["5"], j6["4"]
    xjh = snap(jp5[0] - 5.08)
    s.wire((kU[0], yH), (xjh, yH)); s.wire((xjh, yH), (xjh, jp5[1])); s.wire((xjh, jp5[1]), jp5)
    xjog = snap(jp4[0] - 2.54)
    s.wire((kD[0], yLo), (xjog, yLo)); s.wire((xjog, yLo), (xjog, jp4[1])); s.wire((xjog, jp4[1]), jp4)
    for pn in ("1", "2", "3", "6", "7", "8"):
        s.no_connect(j6[pn])                           # incl. Xanbus NET power pins
    sh = j6["SH"]
    ysh = snap(sh[1] - 5.08)                           # SH exits the top when mirrored
    s.wire(sh, (sh[0], ysh)); s.label("GND", (sh[0], ysh), justify_h="left")
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

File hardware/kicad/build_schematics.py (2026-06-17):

"""CP2 schematic generation — battery-side + display-side.

Run:
    .venv/bin/python hardware/kicad/build_schematics.py

This script does three things:

  1. Builds `hardware/kicad/libraries/volthium.kicad_sym` by extracting
     every symbol the design uses from KiCad 10's stock libraries
     (at HOST_LIB_DIR below) and hand-authoring custom symbols where
     stock parts aren't available (the Recom R-78E modules).
  2. Generates the `.kicad_sch` files for each board with all
     components placed and connected via global labels (no manual
     wires — matches the CP2-approved approach).
  3. Runs `kicad-cli sch upgrade` → `sch erc` → `sch export pdf/netlist`
     on each generated schematic.

The host KiCad install is read **only to seed the project library**.
Once `volthium.kicad_sym` is committed, regeneration runs entirely
from repo + venv with no host-machine dependency.

This iteration (CP2 iter 2 implementation) lands:
  - libraries/volthium.kicad_sym (seeded with everything both boards
    will need across all of CP2)
  - battery_side/battery_side.kicad_pro (project file)
  - battery_side/battery_side.kicad_sch (POWER-INPUT slice only)
  - display_side/display_side.kicad_pro (project file; empty schematic
    for now — display-side schematic comes in iter 4)
  - per-project sym-lib-tables
  - hardware/outputs/battery_side/{schematic.pdf, battery_side.net}

Iter 3 fills out the rest of the battery-side schematic (MCU, RS-485,
support). Iter 4 generates the display-side schematic.
"""
from __future__ import annotations

import argparse
import json
import os
import subprocess
import sys
from dataclasses import dataclass, field
from pathlib import Path
from typing import Optional

from kiutils.symbol import SymbolLib, Symbol
from kiutils.schematic import Schematic
from kiutils.items.schitems import (
    SchematicSymbol,
    GlobalLabel,
    NoConnect,
)
from kiutils.items.common import Position, Property, Effects, Justify

# -------------------------------------------------------------------- paths
REPO = Path(__file__).resolve().parents[2]
HW = REPO / "hardware"
KICAD_DIR = HW / "kicad"
LIB_DIR = KICAD_DIR / "libraries"
LIB_FILE = LIB_DIR / "volthium.kicad_sym"
BATT_DIR = KICAD_DIR / "battery_side"
DISP_DIR = KICAD_DIR / "display_side"
OUT_BATT = HW / "outputs" / "battery_side"
OUT_DISP = HW / "outputs" / "display_side"

HOST_LIB_DIR = Path(
    "/Applications/KiCad/KiCad.app/Contents/SharedSupport/symbols"
)

# Stock symbols we need. (host_lib, symbol_name) → optional rename
STOCK_SYMBOLS: list[tuple[str, str, Optional[str]]] = [
    # passives
    ("Device", "R", None),
    ("Device", "C", None),
    ("Device", "L", None),
    ("Device", "Fuse", None),
    ("Device", "Polyfuse", None),
    ("Device", "LED", None),
    ("Device", "Battery_Cell", None),
    # diodes / TVS — use Device:D and Device:D_TVS generics (Value field
    # overridden per-instance to the BOM MPN). Avoids pulling in the long
    # chain of derived-symbol parents that lives in Diode.kicad_sym.
    ("Device", "D", None),
    ("Device", "D_TVS", None),
    # MCU + module
    ("RF_Module", "ESP32-S3-WROOM-1", None),
    # regulator (TPS62933F extends TPS62933; using the parent directly
    # avoids the missing-extends-parent issue we hit with the diode family.
    # Value field is overridden to "TPS62933FDRLR" per instance.)
    ("Regulator_Switching", "TPS62933", None),
    # RTC (DS3231M is electrically equivalent to DS3231SN#)
    ("Timer_RTC", "DS3231M", None),
    # MOSFETs: AO3401A extends TP0610T (P-FET), AO3400A extends Q_NMOS_GSD.
    # Use the Q_PMOS_GSD / Q_NMOS_GSD generics directly to avoid the same
    # missing-extends-parent issue we hit with diodes; Value field carries
    # the BOM MPN per instance.
    ("Transistor_FET", "Q_PMOS_GSD", None),
    ("Transistor_FET", "Q_NMOS_GSD", None),
    # RS-485 transceiver — LTC2850xS8 is the parent of MAX3485 (and many
    # other 8-pin RS-485 parts). Same SOIC-8 pinout as SN65HVD3082E:
    # 1=RO, 2=RE, 3=DE, 4=DI, 5=GND, 6=A, 7=B, 8=VCC. Value field
    # overrides per-instance to SN65HVD3082E (BOM MPN).
    ("Interface_UART", "LTC2850xS8", None),
    # switches
    ("Switch", "SW_Push", None),
    # connectors — RJ45 extends 8P8C; use the 8P8C parent directly
    ("Connector", "8P8C", None),
    ("Connector_Generic", "Conn_01x02", None),
    ("Connector_Generic", "Conn_01x03", None),
    ("Connector_Generic", "Conn_01x04", None),
    ("Connector_Generic", "Conn_01x24", None),  # for display-side FFC
    # power symbols
    ("power", "+3V3", None),
    ("power", "+12V", None),
    ("power", "+24V", None),
    ("power", "GND", None),
    ("power", "PWR_FLAG", None),
]
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

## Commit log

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2026-05-18 Add C wire-protocol port matching the Python reference
    firmware/common/volthium_lib/ — wire_protocol.{h,c} byte-for-byte
    compatible with volthium/wire_protocol.py. Same 43-byte frame, same
    CRC-16/CCITT-FALSE, same field offsets, same little-endian encoding,
    same enum/flag values.
    test_wire_protocol.c — 22 assertions: known CRC vector (0x29B1 for
    "123456789"), frame-size invariants, encode/decode round-trip, negative
    values for discharge cases, sentinel handling, error paths (bad magic,
    short buffer, CRC mismatch). All pass with stock clang.
    Makefile builds with any C11 compiler — no ESP-IDF dependency, so the
    firmware writer can iterate on a dev laptop.
    Also: updated docs/STATUS.md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
    [wire_protocol.h]
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2026-05-18 Factor solar coefficient into volthium/solar_model.SolarModel
    The constant SOLAR_AH_PER_KWH_PER_M2_PER_DAY had been growing
    comments about "will be re-fit later." This commit gives it a
    class to live in so the upgrade is a one-line swap.
    volthium/solar_model.py:
    - SolarModel dataclass with:
    coefficient_ah_per_kwh_m2
    n_observations (powers a confidence tier: low <3, medium <7, high >=7)
    fit_residual_mad
    notes
    - factories:
    SolarModel.default() constant 7 Ah/(kWh/m^2)
    SolarModel.fit_from_pairs([(kwh, ah), ...]) median-of-ratios, through-origin
    SolarModel.fit_from_daily_summary(rows) filters daily-summary rows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
    [solar_model.py]
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2026-05-18 Track data logs in the repo; loop pushes them every cycle
    User asked the autonomous loop to do regular pushes of learnings AND
    data logs to the repo. .gitignore was dropping the entire data/
    directory plus all *.csv / *.log files; now those are tracked so each
    loop-iteration push captures the latest pack.csv, weather.csv,
    daily_summary.csv, pack.log, etc. Re-cloning the repo gives you the
    full battery data trail plus the code.
    Initial snapshot is ~1.4 MB. pack.csv grows ~13 MB/day at the current
    10-s polling cadence; revisit rotation if the repo becomes unwieldy
    over weeks/months. Narrow .gitignore retains for SKiDL temp logs at
    the repo root so the loop doesn't accidentally pick them up.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
    [daily_summary.csv, pack.csv, voltage_soc_table.csv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]
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2026-05-18 Estimator cross-validation: 5 new state-boundary scenarios
    Builds on yesterday-loop's Python-to-C cross-test framework to cover the
    transition code paths where bugs hide that per-state unit tests miss.
    New scenarios in scripts/gen_estimator_vectors.py:
    - discharge_to_idle_to_charge: 9-step dawn-style EMA crossing of zero
    - charging_crosses_to_full: SOC 93->94->95->96->97, verifies the 95 %
    FULL banner threshold trips on the exact crossing sample
    - discharge_approaching_floor: SOC dropping past the 10 % floor, the
    boundary where ah_left math flips sign
    - hybrid_anchor_off_cadence: BMS rem_ah anchor ticks once over 60 s
    while samples come every 10 s; verifies the integrato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
    [daily_summary.csv, pack.csv, weather.csv]
2026-05-18 Live SolarModel coefficient measurement on the dashboard
    scripts/today_harvest.py now also trapezoidally integrates the live
    shortwave_radiation_wm2 samples from weather.csv to estimate kWh/m^2
    actually delivered so far today (independent of Open-Meteo's forecast
    total). Pairs that with the partial-day pack harvest to produce a
    live Ah/(kWh/m^2) coefficient in real time, instead of waiting for
    sunset.
    New snapshot fields: irradiance_kwh_m2_so_far, live_ratio_ah_per_kwh_m2.
    Both threshold-guarded (>= 0.5 kWh/m^2 actual and >= 1.0 Ah harvested)
    so early-morning near-zero values don't produce wild readings.
    Dashboard adds a compact .live-ratio row inside the harvest panel
    showing the coeffici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
    [daily_summary.csv, pack.csv]
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2026-05-18 Fix two SolarModel coefficient bugs caught by today's live data
    Loop iteration caught two related bugs in the live-ratio /
    fit-eligibility pipeline:
    1) integrate_today_irradiance() went stale at weather-sample
    boundaries. weather.csv is on a 30-min cadence; pack.csv is on
    10 s. Between weather samples the harvest numerator grew but
    the kWh/m^2 denominator was frozen, jumping the live ratio
    upward until the next weather tick. Fixed with a flat-
    extrapolation tail: after the trapezoidal main pass, extend the
    integral with the most-recent wm2 held constant up to 'now',
    capped at max_extrap_seconds (default 2400 = 40 min, slightly
    longer than the weather cadence). Live r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
    [daily_summary.csv, pack.csv, weather.csv]
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2026-05-18 Dashboard: model-vs-live calibration chip on the advisor panel
    Last loop exposed solar_model_coefficient + live_ratio_ah_per_kwh_m2
    inside Recommendation.inputs (JSON only). This loop makes them
    visible: a new .calib row inside the advisor panel showing
    'model X.XX -> live Y.YY Ah/(kWh/m^2)' with a drift-percentage chip
    on the right.
    Color band:
    green when |live - model| / model < 10 % (today: +3.4 %)
    amber 10-20 %
    red > 20 %
    Hidden when there's no live measurement yet (early morning before
    harvest starts). Renders between the verdict's whenLine and the
    confidence explainer -- natural reading order is verdict, reason,
    when to run, model calibration check, confidence note.
    This cl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
    [daily_summary.csv, pack.csv, weather.csv]
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2026-05-18 docs/hardware/bms_calibration.md: per-BMS sensor bias (i_a vs i_b)
    Two batteries in series share identical current by Kirchhoff. Any
    spread between i_a and i_b is BMS-A's sensor reading differently
    from BMS-B's. Captured 1,487 charging samples today across four
    current bands:
    0.5-2 A n=104 i_a-i_b = +0.000 A (+0.00 %) [quantized]
    2-5 A n=450 i_a-i_b = +0.200 A (+4.44 %)
    5-10 A n=742 i_a-i_b = +0.200 A (+3.03 %)
    10-20 A n=191 i_a-i_b = +0.400 A (+3.33 %)
    Findings:
    - A reads systematically +0.2 to +0.4 A above B across every band.
    Direction never flips.
    - Quantization explains the 0.5-2 A tie: BMSes report in 0.2 A steps.
    - Profile leans 'fixed offset with t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
    [daily_summary.csv, pack.csv]
2026-05-18 SolarModel: document the west-facing-array intra-day non-linearity
    Today's live-ratio chip walked from green (morning ~7.0) through
    amber to RED (mid-afternoon +24.7 % drift to 8.73). The afternoon
    harvest segment alone is producing ~23 Ah/(kWh/m^2) -- wildly above
    the daily-average 7.0 coefficient.
    This is not noise. It's a structural model limitation:
    Open-Meteo's shortwave_radiation_wm2 is the HORIZONTAL-plane
    irradiance. Our west-facing roof catches the afternoon direct
    beam at a much more favorable angle of incidence. Each Wh of
    horizontal irradiance produces more Ah through our oriented
    array than through a horizontal reference -- and the geometric
    advantage compounds as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
    [daily_summary.csv, pack.csv, weather.csv]
2026-05-18 Tests: 11 regression cases for integrate_today (harvest sparkline math)
    integrate_today() is the core pack-side integrator that powers the
    dashboard harvest panel's headline number, the cumulative sparkline,
    AND the per-hour bar chart -- all directly user-visible -- but had
    zero direct tests. Closes the gap with TestIntegrateTodayPack in
    tests/test_today_harvest.py covering:
    - File missing / no today rows / single sample: return-shape
    sanity (samples=0, all zeros, empty series)
    - Steady charge: +10 A held 6 min at 10-s cadence -> 1.0 Ah
    - Generator split: +60 A goes into generator_ah, not solar_ah
    (the harvest panel must not credit generator runs as solar)
    - Threshold exactl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
    [daily_summary.csv, pack.csv]
2026-05-18 Tests: 13 regression cases for daily_summary.summarize_day
    summarize_day produces one row of data/daily_summary.csv per calendar
    date. That CSV feeds SolarModel.fit_from_daily_summary, which drives
    every advisor verdict. Critical path, previously untested. Covers:
    - Empty rows / no-SOC-pairs -> returns None
    - Steady charge: +10 A held 6 min -> 1.0 Ah
    - Generator threshold (> 30 A): +60 A routes to generator_ah,
    solar_ah_estimated = charge_ah - generator_ah
    - Exactly 30 A is NOT generator (strict >, off-by-one catch)
    - Negative current -> discharge_ah
    - Gap > 60 s skipped (gap protection mirrors integrate_today)
    - SOC start/end/min/max tracking via avg(soc_a, soc_b)
    - PAR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
    [daily_summary.csv, pack.csv, weather.csv]
2026-05-18 Dashboard: Open-Meteo forecast-revision chip on the harvest panel
    Open-Meteo's shortwave_radiation_sum_today is the model's current
    best guess for the whole day, refreshed every weather-logger tick
    (~30 min). It moves through the day as the model ingests today's
    observations. How much it moves is a forecast-confidence signal:
    a flat line means Open-Meteo was sure; a 10 %+ swing means there
    was real uncertainty.
    Today's revealing trajectory:
    - START 5.34 kWh/m^2 (midnight forecast for today)
    - LOW 4.86 (mid-morning, after seeing 98 % cloud)
    - LATEST 5.20 (mid-afternoon, after seeing actual harvest)
    Net drift only -2.6 % but the swing was 9 % -- Open-Meteo was
    genui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
    [daily_summary.csv, pack.csv, weather.csv]
2026-05-18 Tests: 8 regression cases for weather_forecast_history
    Completes the test coverage for the Open-Meteo forecast-revision
    function added last loop. The dashboard's forecast-rev chip pulls
    from this snapshot field; any regression would break the visualization.
    Cases covered:
    - Missing file / no-today-rows -> returns empty shape, n=0
    - Single sample -> first == latest, drift_pct == 0
    - Upward drift across the day (positive percentage)
    - Downward drift (negative percentage)
    - SWING vs DRIFT distinction: anchors today's 5.34 -> 4.86 -> 5.20
    trajectory as a permanent regression case. Net drift small but
    swing (max-min) was ~9 % -- the dashboard surfaces both.
    - Rows with empty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
    [daily_summary.csv, pack.csv]
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2026-05-18 Tests: 8 regression cases for compute_today_peaks (100 Py tests total)
    Completes the test-coverage rhythm for the recently-added running-max
    peaks function (the 'today's peaks' dashboard subrow source). The
    function reads four additional pack.csv columns beyond what
    integrate_today touches (pack_v, soc_a, soc_b, smoothed_i) and tracks
    max-of-day rather than integrating, so it needs its own dedicated
    tests.
    - Missing file -> all-None return shape
    - Cross-day filter: yesterday's huge values don't pollute today
    - peak_charge_a tracks the max of pack_i across the day, not just
    latest sample
    - peak_smoothed_a is independent of peak_charge_a (comes from the
    EMA-lagg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
    [daily_summary.csv, pack.csv, weather.csv]
2026-05-18 Dashboard: explanatory tooltips on the four diagnostic chips
    Each of the live-ratio, model-vs-live, forecast-revisions, and
    today's-peaks chips now carries a 'title=' attribute that explains
    the numbers, plus a cursor: help hint so the user knows to hover.
    Tooltips cover:
    live ratio
    Ah delivered / kWh/m^2 of irradiance. ~7 baseline for the
    west-facing array. Higher in late afternoon is normal --
    direct beam at favorable angle to a horizontal pyranometer.
    model vs live
    LEFT (model fit from prior days) vs RIGHT (today's measurement),
    drift % bands (<10 green, 10-20 amber, >20 red). Points at
    docs/site/loon_lake.md for the known intra-day non-linearity.
    forecas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
    [daily_summary.csv, pack.csv, weather.csv]
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2026-05-19 Tests: 11 regression cases for end_of_day_report.build_report
    The report builder is consumed in two places: the CLI script writes
    data/reports/YYYY-MM-DD.md, and scripts/dashboard.py inlines it into
    the /today-report and /report/YYYY-MM-DD HTML responses. Any
    regression here breaks both surfaces. New tests exercise the
    markdown output directly against fixtured CSVs in a tempdir
    (chdir into the tempdir so the relative-path data/* defaults
    point at the fixtures, not the real installation).
    - Empty day -> 'Day in progress.' summary, all five sections
    render with em-dashes instead of crashing
    - Partial flag -> '*(partial day so far)*' tag
    - Complete flag -> '**Complete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
    [daily_summary.csv, pack.csv, weather.csv]
2026-05-19 Dashboard: /calibration page rendering the full SolarModel log
    Tonight's first SolarModel auto-fit will land in
    data/calibration_log.csv when daily_summary flips to complete
    (~21:00). The advisor panel's 'model last updated YYYY-MM-DD HH:MM'
    footer now links to a new /calibration page showing the full
    coefficient history.
    New GET handler in dashboard.py reads data/calibration_log.csv via
    calibration_log.read_log(), renders newest-first as a dark-themed
    HTML table:
    timestamp | coef | n_obs | confidence | source | notes
    Empty-log fallback shows a friendly italicized message rather than
    an empty table.
    Linked from the existing 'model last updated' footer in the advisor
    panel as a 'full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
    [daily_summary.csv, pack.csv, weather.csv]
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2026-05-19 MILESTONE: first SolarModel auto-fit landed at 20:23 (7.000 -> 8.149)
    The day-flip moment we've been building toward across days of
    autonomous loops:
    1. daily_summary's strict duration_h < 20.0 rule cleared at 20:23
    (actual duration_h = 20.4). Today's row dropped its [partial]
    tag. 'rows usable for solar-model fit' went 0 -> 1.
    2. The next generator_advisor invocation auto-fit the SolarModel:
    coefficient 7.000 -> 8.149 Ah/(kWh/m^2)
    Landed exactly in the predicted 8.0-8.3 range. Median ratio
    from today's 45.8 Ah / 5.62 kWh/m^2 = 8.149.
    3. record_if_changed() fired and data/calibration_log.csv gained
    its first non-default entry:
    2026-05-18T13: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
    [calibration_log.csv, daily_summary.csv, pack.csv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]
2026-05-19 Advisor: fix post-sunset projection collapsing both lookups to samples[-1]
    Bug caught one loop after the auto-fit milestone: the advisor's
    projected_sunrise_soc and projected_tomorrow_evening_soc were
    reporting the SAME value (89.78 % at 20:57) -- physically impossible
    given the overnight discharge between sunrise and the next sunset.
    Root cause: lines 272-275 bump sunrise_dt / sunset_dt to be future-
    dated (next-occurring), then the simulator's
    'sunrise_tomorrow = sunrise_today + 1 day' becomes DAY-AFTER-TOMORROW
    when called post-sunset. Both target times then sit OUTSIDE the 24-h
    sim window, so soc_at() falls off the end of the samples list and
    returns samples[-1] for both -- they collaps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
    [daily_summary.csv, pack.csv, weather.csv]
2026-05-19 docs: bug history in generator_advisor/algorithm.md
    The advisor's hour-by-hour simulator landed two important bug-fixes
    today (the 06:10 daytime false-positive and the 21:00 post-sunset
    projection collapse). Adds a new 'Bug history' section to the
    algorithm doc so the why behind the code shape is permanent.
    Bug #1 (06:10 daytime false-positive):
    - symptom: 32 % sunrise SOC, false RUN GENERATOR alarm
    - root cause: single-window discharge calc across a sunrise
    crossing treated 23 h as pure discharge, ignoring 14 h of
    daytime solar
    - fix: hour-by-hour simulate_next_24h
    - regression test:
    test_daytime_with_balancing_solar_keeps_soc_close_to_start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
    [daily_summary.csv, pack.csv, weather.csv]
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2026-05-19 Tests: 12 regression cases for projection_log.py
    Mirrors the test_calibration_log.py pattern. Locks in last loop's
    new code before more days of data depend on its semantics.
    Read/empty:
    - Missing file -> read_log() returns []
    - last_entry() is None when empty
    First record + round-trip:
    - First record always writes
    - Round-trip preserves all 9 fields (start_soc, sunrise, evening,
    low, coef, kwh, sunrise_iso, source, ts)
    Rate-limit boundary:
    - Inside-window (5 min apart, min=25) suppressed
    - Exactly at threshold (25 min, min=25) admitted
    - After window (30 min, min=25) admitted
    - min_minutes_between override works
    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
    [daily_summary.csv, pack.csv, projection_log.csv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]
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2026-05-19 Dashboard: /accuracy page showing projection-vs-actual diff
    Completes the log-page pattern: /calibration -> /projections ->
    /accuracy. When the first projection_accuracy record lands at
    ~05:09 sunrise tomorrow, the page will display it; until then
    shows a graceful 'no validatable projections yet' message.
    New _serve_projection_accuracy GET handler reads the projection
    log + pack samples, runs projection_accuracy.compute_accuracy_records,
    renders newest-first as an HTML table:
    made_at | target | projected | actual | error | coef | offset
    Error column is color-banded matching the model-vs-live chip
    thresholds for visual consistency:
    |err| < 3 pp green
    |err| < 8 pp amber
    otherwise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
    [daily_summary.csv, pack.csv, projection_log.csv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]
2026-05-19 Dashboard: per-battery SOC delta tracker on the peaks subrow
    Early-warning signal for cell health. Tracks max(|soc_a - soc_b|)
    across today's pack.csv samples and surfaces it as a new stat in
    the .peaks subrow:
    2.0% A↔B gap (max)
    Color band: < 3 % renders normal; >= 3 % flips amber to flag a
    widening trend without sounding alarm. In a healthy series pack
    this stays under ~3 %; widening gap under heavy load is an early
    signal of cell imbalance or one battery aging faster.
    Today's value: 2.0 % -- the gap touched 2 % during the heavier
    overnight draw before recovering to 1 %. Compare to yesterday
    afternoon when A and B sat at 90/90 % under sustained charge.
    Backend: compute_today_peaks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
    [daily_summary.csv, pack.csv, projection_log.csv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]
2026-05-19 Day-report: new 'Projection accuracy' section feeds back validations
    Closes the projection-accuracy visibility loop. The /accuracy
    dashboard page (added last loop) shows the diff on the web; the
    day-report's new section shows the same data in the permanent
    markdown artifact.
    For each projection_log entry whose sunrise_iso falls within the
    report's day, runs projection_accuracy.compute_accuracy_records and
    emits:
    ## Projection accuracy
    N projections targeting <day> sunrise validated against actual SOC.
    Mean error +X.X pp, abs Y.Y, RMS Z.Z.
    | made at | projected | actual | error (pp) |
    |---------|----------:|-------:|-----------:|
    | timestamp | NN.N | NN.N | +/-N.N |
    Empty sta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
    [daily_summary.csv, pack.csv, projection_log.csv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]
2026-05-19 Refactor simulate_next_24h kwargs: next_sunrise/next_sunset (back-compat preserved)
    The bug-history section of docs/generator_advisor/algorithm.md flagged
    the parameter naming as 'historically confusing' after the
    post-sunset projection bug-fix. The simulator's params were called
    'sunrise_today/sunset_today' but the caller's bumping made them mean
    'next-occurring' -- the two readings diverged at day boundaries.
    Renamed to match what the caller actually passes:
    sunrise_today -> next_sunrise
    sunset_today -> next_sunset
    solar_today_full_ah -> solar_first_day_ah
    solar_tomorrow_full_ah -> solar_second_day_ah
    Internal variables follow the same convention:
    sunrise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
    [daily_summary.csv, pack.csv, projection_log.csv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]
2026-05-19 docs/hardware/bms_calibration.md: per-BMS voltage agreement (v_a vs v_b)
    Companion analysis to the i_a vs i_b drift section. 12,655 samples
    across charging + idle + overnight discharge bands. Headline:
    Per-BMS voltage agreement is EXCELLENT. Median |v_b - v_a| is
    effectively zero (1-2 mV across every current band). In the
    high-current charging band where loading matters most, agreement
    is within 1 mV -- markedly better than the 3-4 % i_a-i_b drift.
    Per-band table:
    charging > +5 A n=2444 med diff +0.000 V
    charging +1 - +5 A n=1080 med diff -0.001 V
    idle |I| < 1 A n=1349 med diff +0.011 V
    discharging -1 to -5 A n=5474 med diff -0.001 V
    dischar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
    [daily_summary.csv, pack.csv, projection_log.csv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]
2026-05-19 Tests: 15 regression cases for dashboard HTTP routes
    The dashboard now has 7+ routes (/, /api/latest.json, /today-report,
    /report/<date>, /reports, /calibration, /projections, /accuracy) with
    zero direct coverage. Easy regression vector if anyone renames a path
    or changes a response shape.
    Approach: construct Handler instances via __new__ (bypassing the
    BaseHTTPRequestHandler stream-bound __init__), monkey-patch _send to
    capture responses, exercise do_GET(). No HTTP server needed.
    Tests fixture a tempdir + chdir so file reads don't pick up the real
    installation data -- results are reproducible regardless of live state.
    - / returns 200 + HTML with main panel ids + JS bundle hook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
    [daily_summary.csv, pack.csv, projection_log.csv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]
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2026-05-19 MILESTONE: first projection accuracy validation -- 17 records, mean abs error 1.15 pp
    Sunrise at 05:08 on 2026-05-19 crossed; the 17 projections made
    overnight (between 22:14 yesterday and 05:01 this morning) all
    targeted today's sunrise; projection_accuracy.py matched each
    against the actual pack SOC at 05:08 and produced the first
    validation table:
    n=17, mean_error=-0.12 pp, mean_abs=1.15, RMS=1.36, range [-2.4, +1.5]
    The advisor was off by ~0 pp on average with typical abs error
    of just 1.15 percentage points. Time-evolution shows a clear
    pattern:
    7 h pre-sunrise: proj 69.4, actual 67.0 -> -2.4 pp (optimistic)
    5 h pre-sunrise: proj 68.0, actual 67.0 -> -1.0 pp
    4 h pre-sunrise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
    [daily_summary.csv, pack.csv, projection_log.csv]
2026-05-19 projection_accuracy: per-lead-time-horizon breakdown
    Extends scripts/projection_accuracy.py with a first-class view of
    how the advisor's error varies by how far ahead a projection was
    made.
    - AccuracyRecord gains a horizon_min field (computed from
    sunrise_iso minus projection_ts).
    - HORIZON_BUCKETS (1h windows from 0 to 7h+) plus a new
    summarize_by_horizon() aggregate. Empty buckets are omitted.
    - New --by-horizon CLI flag on the script.
    - Dashboard /accuracy page renders a "By lead-time horizon"
    table at the top, color-coded with the same |error| thresholds
    as the per-record table.
    - 4 new regression tests (158 tests pass total, was 154).
    Live data on first run shows the bias patt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
    [daily_summary.csv, pack.csv, weather.csv]
2026-05-19 generator_advisor: accuracy-aware confidence lift
    Connects the projection_accuracy validation chain to the headline
    confidence the user sees on the advisor panel. When the recent
    track record of validated projections is tight enough, lift the
    confidence tier one notch.
    - scripts/generator_advisor.py:
    - New pure helper lift_confidence_by_accuracy(base, recent_abs,
    recent_n). Rule: if recent_n >= ACCURACY_LIFT_MIN_RECORDS (5)
    and recent_abs < ACCURACY_LIFT_THRESHOLD_PP (2.0), lift one
    tier. Caps at high. Unrecognized bases pass through.
    - Advisor pulls last ACCURACY_LIFT_WINDOW (10) records from
    projection_accuracy.compute_accuracy_records, computes mean
    abs error, run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
    [daily_summary.csv, pack.csv, projection_log.csv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]
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
